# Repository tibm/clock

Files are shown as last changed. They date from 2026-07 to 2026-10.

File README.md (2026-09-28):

# Wooden Smart Clock — Hardware Specification

> Living spec for a high-quality, low-power desk alarm clock: a **walnut cube (~120 mm)** with an **aluminum front plate**, a centered **Ø~90 mm MCU-driven analog dial behind glass** (aluminum hands on walnut, 12 black hour dots, no numerals), a row of **5 RGBW status LEDs** under the dial, and one **aluminum knob (rotate + press)** centered on the top face.

> 🔩 **Manufacturing constraint — HAND-SOLDERABLE PARTS ONLY.** The bare PCB is fab'd externally; **every part is hand-soldered with an iron.** No **QFN / DFN / WSON / BGA / WLP / LGA** silicon sits bare on the board — every active IC is a **leaded/gullwing** package (SOIC / SOP / SSOP / TSSOP / **HTSSOP** / **MSOP** / SOT-23) or a **castellated/edge module**. The two power parts (amp `TAS5760M`, charger `LT3652`) are HTSSOP/MSOP **PowerPAD** — leads iron-solderable, belly pad on a thermal-via array (back-side hot-air optional). Functions that *only* exist leadless → **pre-made breakout modules** (env/MEMS sensors — **BME688, TSL2591, BNO085** as I²C Qwiic/STEMMA boards; or a custom SMT daughterboard — **built: [`kicad-sensor/`](kicad-sensor/), `SENSE v0.2`**, §8) or **dropped** (fuel gauge → ESP32 ADC). **Passives ≥ 0603** (0402 min); connectors hand-solderable (through-hole / wide-pad SMD: USB-C, FPC/ZIF, JST, SD cage). **This grows the PCB — accepted.**

**Status:** v0.19 draft · **Owner:** you (FW/HW) · **Last updated:** 2026-07-19 · **What is left to build: [`TODO.md`](TODO.md)** · clock ⇄ app protocol: [`app/PROTOCOL.md`](app/PROTOCOL.md)

**Changelog**
- v0.19 — **Product redesign: walnut cube + aluminum face — display dropped, NeoPixel status/face LEDs + top-knob UX added (2026-07-19).** New form (§3): perfect **walnut cube ~120 mm** (size flexible, larger eases manufacturing), all faces wood except an **aluminum front plate** (cube − 10 mm in W/H, flush-centered → **5 mm wood reveal**) with a **centered Ø~90 mm dial opening** behind glass — **aluminum hands over a walnut dial**, no numerals, **12 black hour dots**; below the opening, **5 status-LED holes + icons** (Lucide-style `bell`, `alarm-clock`, `clock`, `volume-1`, `battery`); an **aluminum knob (rotary + push)** perfectly centered on the top face; wake light, speaker openings and USB port on the **back**. Consequences: **(1) Sharp LS032B7DD02 + FH34 FPC connector dropped** (§4; their datasheets stay in [`/datasheet`](datasheet/) for possible future reuse) — SPI2 is now **microSD-only**, software-VCOM notes moot, `LCD_DISP`/`LCD_CS` freed. **(2) Panel-LED string dropped** (Cree CLM3C ×≤12 + its AO3400A + one LEDC channel recovered) → **7× SK6812 RGBW NeoPixels on the PCB** ([Adafruit 2758](https://www.digikey.com/en/products/detail/adafruit-industries-llc/2758/6134706), 10-pack $5.95): **5 status + 2 dial-illumination**, chained on the **5 V rail** (works on battery) behind **one data GPIO (IO7 → RMT)** through an **SN74AHCT1G125 3.3→5 V buffer** ([DigiKey 376028](https://www.digikey.com/en/products/detail/texas-instruments/SN74AHCT1G125DBVR/376028), $0.14). **(3) UI = single knob**: Bourns **EM14A0D-C24-L064S** **optical** encoder (**no detent, 64 CPR**, integral push switch, **5 V** opto-ASIC, [DigiKey 954403](https://www.digikey.com/en/products/detail/bourns-inc/EM14A0D-C24-L064S/954403), $34.00) under a Kilo **OEJNI-90-1-5** machined aluminum knob (Ø23.5 mm, 1/4″ bore + set screw = the encoder's 1/4″ flatted shaft, [DigiKey 5970396](https://www.digikey.com/en/products/detail/kilo-international/OEJNI-90-1-5/5970396), $13.43), off-board on J10 (JST **ZH** 1×06 B6B-ZR incl. **+5 V** — same family + pre-crimped A06ZR cable as the sensor board) → **A/B are 5 V outputs → 100k/200k dividers → IO47/48 (PCNT)**, **ENC_SW moved MCP23017 → host IO17** (freed by the display) for a tight-debounce interrupt; **rear tactiles BTN1–3 dropped**, one **radio-disable toggle** remains on the expander (GPA3) via **J11** (JST ZH 1×02). **(4) USB-C receptacle → vertical GCT USB4160-03-0230-C** (24-pin USB 3.2 Gen2 vertical, of which only the **USB 2.0 subset** — VBUS/GND/**CC/D±** — is wired, SS pads unconnected → native USB-JTAG + 15 V PD intact; [DigiKey](https://www.digikey.com/en/products/result?keywords=USB4160-03-0230-C), **$1.22, 5,753 in stock**, active) standing on the PCB, port exits the back wall directly — **USB4105 + Adafruit 6069 panel extension dropped**; footprint adapted into `kicad/clock.pretty` from the user-supplied vendor CAD file. *(Vetting trail: **USB4140** rejected = 6-pin power-only, no D±; **UJ20-C-V-C-1** rejected = legs/layout specified for a 0.8 mm PCB; **UJ20-C-V-C-2** (TH, $0.95) was briefly primary but is backorder-only; **USB4145-03-0170-C** ($1.05) remains a same-land-family 16-pin alt.)* **(5) Orientation-awareness (R14) retired** (the cube is fixed upright; LIS3DH stays for tap-to-snooze). Unchanged: wake COB (12 V, plugged-only), audio chain, charger + battery safety, sensors, homing, steppers. Schematic (`kicad/`) regenerated; docs synced.
- v0.18 — **Protector re-picked (AP9101C went NRND/obsolete) → HYCON HY2111-GB** (SOT-23-6, OV 4.28 V / OD 2.90 V, pin-arrangement-identical → same nets; support values per its datasheet: R VDD 330 Ω→**100 Ω**, R CS 2.7 k→**2 kΩ**; AOSD32334C dual-FET unchanged). Quality single-qty alternatives (ABLIC S-8261ABMMD, Nisshinbo R5478N) are reel-only/no-stock at DigiKey → HY2111-GB sourced **LCSC C82747** (off-DigiKey like the CH224K). **X40.879 mounts directly on the PCB**: custom KiCad footprint + symbol drawn from the factory STEP + pinout figure (8 solder pins, Ø10 shaft clearance hole, both shafts pass through the board); **J4 stepper connector dropped**. **USB-C port moved to the enclosure wall** via the Adafruit **6069** panel-mount **extension** ([DigiKey 25897275](https://www.digikey.com/en/products/detail/adafruit-industries-llc/6069/25897275), ~$4.50) — the on-board **USB4105** receptacle + CH224K stay unchanged (a passive C-plug→panel-C-jack passthrough keeps CC/PD intact; the resistor-equipped Adafruit 6153 pigtail was rejected — its built-in 5.1 kΩ CC pull-downs would break the 15 V PD contract). Datasheets: `battery_protector_ap9101c.pdf` → `battery_protector_hy2111.pdf`. Schematic (`kicad/`) regenerated; docs synced.
- v0.17 — **Homing sensor re-picked: Everlight ITR8307 (went unavailable) → onsemi QRE1113.** Same reflective **phototransistor with analog output → 1 ADC pin**, so it drops into the **same 150 Ω ballast / 10 kΩ load network** unchanged (§5, [`power_values.md`](power_values.md)); no firmware or pin-map change. Trade-off: the QRE1113 is **larger (≈3.6×2.9×1.7 mm** vs the ITR8307's 3.4×1.5×1.1 mm) → a marginally bigger dial hole — still far smaller than the dropped **TCND5000** (6×4.3×3.75 mm). Through-hole gull-wing `QRE1113` (SMD `QRE1113GR` alt), trivially hand-solderable, **DigiKey 2175990 (~$0.76)**. Synced §5/§8/§16b + block diagram + [`datasheet/README.md`](datasheet/README.md) (`sensor_homing_optical_itr8307.pdf` → `sensor_homing_QRE1113-D.PDF`).
- v0.16 — **LED 12 V source resolved · MCP23017 IO expander added · pin-level map (`esp32.md`) + schematic values (`power_values.md`) · backup mode / TCO / VCOM decided.** LED: **no barrel jack** — the wake COB runs off the shared **TPS55340 12 V boost, plugged-only**; on battery the amp PVDD auto-drops to the **5 V rail via an LTC4412 mux** (quieter alarm) and the 5 V panel LEDs stay on (§9/§10, [`led.md`](led.md)). **Added the Microchip MCP23017** I²C IO expander (SOIC/SSOP-28) on the shared bus to offload slow/static lines (SPK_SD, 12 V-boost EN, stepper STBY, buttons, encoder-switch, PD PG, charger CHRG/FAULT) → **net −7 host GPIO** (§6/§16b; datasheet §19). Full **pin map now in [`esp32.md`](esp32.md)** (native USB-JTAG on IO19/20, **software VCOM** with EXTMODE=L, shared display+SD on SPI2 → **32/33 module pads**), and **per-converter passive/FB/comp values in [`power_values.md`](power_values.md)**. Decisions (2026-07-12): **backup mode = adaptive** (Wi-Fi modem-sleep → deep-sleep at low SoC); **one-shot ~77 °C TCO added** to the cell path (§10); **software VCOM** locked. Corrected the 32.768 kHz load-cap value (**~18 pF**, was mis-stated). Synced [`datasheet/README.md`](datasheet/README.md), [`power.md`](power.md), [`CLAUDE.md`](CLAUDE.md).
- v0.15 — **Sensor set consolidated to 3 parts + hand-assembly path chosen (§8).** Dropped the redundant **TMP117** (any temp sensor already gives the reading); folded **SHT45 + SGP41 → one Bosch BME688** (T + RH + pressure + VOC/gas via BSEC — one chip, one board on the bus); accel **BMA400 → LIS3DH** (no leaded accel exists; low-res tap+gravity is all we need). **Locked set = BME688 + TSL2591 + LIS3DH on both build paths → firmware identical either way.** **Build = option 2a: a STEMMA QT / Qwiic daisy-chain** of three ready Adafruit boards on one 4-wire I²C chain — **BME688 (Adafruit 5046, ~$19) + TSL2591 (1980, $6.95) + LIS3DH (2809, $4.95)** — no leadless silicon touched by the iron. **Future option 2b:** the **same** three bare chips on one small custom daughterboard, JLCPCB SMT-assembled, hand-solder only its header → smallest footprint, same part numbers → same firmware. Filed `sensor_env_bme688.pdf` + `sensor_accel_lis3dh.pdf`; removed the now-unused TMP117/SHT4x/BMA400 datasheets. Synced §8/§16a/§16b + [`datasheet/README.md`](datasheet/README.md).
- v0.14 — **Homing reworked: 2× DRV5032 Hall + hand magnets → 1× reflective optical (Everlight ITR8307).** One sensor behind a **punched dial hole**, sequential per-shaft homing, **no hand magnets** (§5). Evaluated the longer-range **Vishay TCND5000** for a >3 mm hand stand-off and **dropped it** — at **6×4.3×3.75 mm** it's ~5× the ITR8307 footprint (**3.4×1.5×1.1 mm**) → a bigger dial hole; **ITR8307 locked for the smallest hole**, hands kept **<3 mm** off the dial. Synced §3/§5/§8/§16b/§17 + [`datasheet/README.md`](datasheet/README.md) (dropped the stale Hall rows; only `sensor_homing_optical_itr8307.pdf` filed).
- v0.13 — **RTC IC dropped → ESP32-S3 RTC + 32.768 kHz crystal (no battery).** A battery-less RTC chip loses time on total power loss exactly like the S3, so it adds parts without fixing anything; the S3's internal RC oscillator alone drifts %-level over temperature (bad for a clock). Fix = a ~30¢ **32.768 kHz watch crystal** on XTAL32K (GPIO15/16) → ±~20 ppm ≈ 1.7 s/day, disciplined by **SNTP**. On loss of USB **and** the 18650, time is lost → re-sync on boot with a clock animation (accepted). Removed the RV-3028-C7/DS3231SN row + datasheet; §8, §16, §17, §6c synced.
- v0.12 — **Sensors, display connector & RTC finalized to precise parts + datasheets** ([`/datasheet`](datasheet/) rows 11–16): display FPC → **Hirose FH34SRJ-10S-0.5SH** (10-pin 0.5 mm ZIF, the panel spec's own recommended mate, on-board); T/RH → **SHT45** (±0.1 °C / ±1 %RH, replaces SHT40) + optional dedicated **TMP117** (±0.1 °C); light → **TSL2591** (188 µlx–88 klx, weak-light, replaces VEML7700); accel+orient → **BMA400** (now datasheeted); RTC **kept = RV-3028-C7** (ULP 45 nA) / **DS3231SN** (SOIC-16, on-board) — the S3's internal RTC dies on full power loss, so a backed-up RTC gives instant-correct hands at cold boot + holdover. Production BOM (§16b), §8 sensor table, and [`datasheet/README.md`](datasheet/README.md) synced; leadless sensors ride on I²C breakouts, the FPC connector is on-board.
- v0.11 — **Hand-solderable parts only (hard mfg constraint):** every bare-PCB IC is now a leaded package — no QFN/DFN/BGA/LGA. Swaps: amp **TAS5825M (VQFN) → TAS5760M** (HTSSOP-32, I²S+I²C; HPF/limiter DSP moves to firmware); driver **2× DRV8835 (WSON) → 2× TB6612FNG** (SSOP-24); PD **STUSB4500 (QFN) → CH224K** (ESSOP-10, resistor-set, off-DigiKey); charger **BQ25628E (WQFN) → LT3652** (MSOP-12E buck, BAT-node power-path, resistor-set 4.05 V + NTC + timer — no I²C, single-window temp); **fuel gauge MAX17048 (µDFN) dropped → ESP32 ADC**; protector **LC05111 (DFN) → S-8261 (SOT-23-6) + AO4800 dual-FET (SO-8)**. Leadless-only env sensors → **I²C breakout modules**. New top-of-file mfg note; datasheets swapped in [`/datasheet`](datasheet/); board grows — accepted.
- v0.10 — **Power/safety simplified (Option A)**: buck-boost **BQ25792 → BQ25628E** (1-cell buck charger, integrated FETs — buck is enough since input always > 1S cell); independent **cell protector = onsemi LC05111** (integrated FET) + **reverse-polarity P-FET** + NTC/JEITA + TVS = **double-redundant, industry-standard for 1S**. Dropped BQ29700+FETs, **secondary OVP, one-shot TCO, PPTC** (over-engineering for a single cell). Datasheets added (STUSB4500, BQ25628E, MAX17048, LC05111); `power.md` now has a **How-to-use / bring-up** section. Power subtotal ~$23 → ~$15.
- v0.9 — **Power tree locked** ([`power.md`](power.md)): **USB-PD sink (STUSB4500, 15 V)** → **BQ25792** buck-boost charger/path (+ MAX17048), 1S. Rails 3.3 / 5 / 12 V-audio-boost / 15 V-VBUS-LED. Battery = **user-supplied 18650 in a holder, Li-ion ONLY (labeled)**; **48 h backup**; health-cap ~80 %. **Mandatory board safety for any 18650**: reverse-polarity (LM74700-Q1), primary PCM (BQ29700+FETs), redundant secondary OVP, PPTC + thermal cutoff, NTC/JEITA, TVS, FR barrier — triple-redundant overcharge, layered over-discharge. Charger BQ25185 → **BQ25792**; §10/§16/§17 updated.
- v0.8 — **Amp locked = TI TAS5825M** (I²S + I²C closed-loop Class-D w/ DSP), PBTL mono into the 4 Ω DMA58-4: PVDD 5 V for ~3 W, optional ~12 V boost for ~8–12 W; DSP loads a ~150–180 Hz high-pass + limiter to protect the 2 mm-Xmax driver. MAX98357A demoted to simple/no-DSP alt. **Driver confirmed = 2× TI DRV8835** (dual H-bridge each; VM 5 V for full torque, VCC 3.3 V; PHASE/ENABLE with PWM microstep → 8 GPIO). Full datasheets added to [`/datasheet`](datasheet/); [`datasheet/README.md`](datasheet/README.md) now carries a **System IO & power domains** table (rails + per-part GPIO/voltage).
- v0.7 — **Speaker PC68-4 → Dayton DMA58-4** (2″ dual-magnet full-range — the driver we actually have a datasheet for) → smaller driver relaxes body depth to **≥45–60 mm / ~100–250 cc** chamber (optional **DMA58-PR** passive radiator for bass). **Movement locked = Juken X40.879**: its datasheet is a short **pinout addendum** that defers to the **X27 base spec** for torque/current/dimensions — both now in [`/datasheet`](datasheet/). Added the **full Sharp LS032B7DD02 device spec** (replaced the marketing brief); corrected display **active area → 42.67 × 68.07 mm** and **power → 30 µW hold / 250 µW update @ 5 V (VDD 4.8–5.5 V)**; **X40.879 price → ~$14** (was ~$25, DigiKey). Datasheets summarized in [`datasheet/README.md`](datasheet/README.md).
- v0.6 — **Split-face locked as THE design**: circular MCU-driven analog clock (~75 mm) + reflective monochrome info panel (**Sharp LS032B7DD02**). **Single MCU** (ESP32-S3). New **orientation awareness** (R14): flat (clock left / display right) ↔ standing (clock top / display bottom), accel-sensed; MCU rotates the display and re-references the analog "12". Movement re-picked for 75 mm → **Juken X40.879** (DigiKey) + external Hall homing. Motor driver **DRV8833 → DRV8835** (DRV8833 is NRND). Backlight subsystem removed (reflective display). Shopping list moved **Mouser → DigiKey**. Sections renumbered consecutively; wide color bar-TFT demoted to *superseded*.
- v0.5 — locked **Dayton PC68-4** speaker; added **Juken X10.506** + more movements; new requirement **R12** (MCU sets/adjusts analog time → sweep-quartz demoted).
- v0.4 — added **speaker comparison** and the **analog-movement comparison** for the split-face option.
- v0.3 — added **ESP32-S3** single-chip path + firmware libraries, **audio sizing**, internal packaging notes, and a distributor-linked shopping list.
- v0.2 — display moved E-Paper → fast **bar TFT** (NHD-3.9); MCU → STM32U5 + ST67W611M1, with ESP32-S3 as single-chip alt.
- v0.1 — initial spec (EPD + nRF5340).

---

## 1. Requirements (source of truth)

| # | Requirement | Primary approach (see §) |
|---|---|---|
| R1 | Accurate time (TZ, seconds, day, date), periodic server sync | ESP32-S3 RTC off a 32.768 kHz crystal + SNTP over Wi-Fi (no RTC IC/battery) (§6, §8) |
| R2 | ALS-driven lighting, **true 0 emission at night** | Wake light + status/dial NeoPixels, hard-off + ALS gating (§8, §9) |
| R3 | Alarm, tap-to-snooze, loud multi-asset audio, sunrise glow | Accel tap-detect + Class-D audio + tunable-white sunrise wake light (§7, §9) |
| R4 | Air quality (VOC/AQI), temperature, humidity | **BME688** (T/RH/press/VOC in one chip); optional CO₂/PM (§8) |
| R5 | USB-C powered, battery backup + charge, run untethered | USB-C PD sink + charger + Li-ion + ADC gauge (§10) |
| R6 | Glanceable state without a screen: alarm armed, set modes, volume, low battery — **0 light when idle** | **5 RGBW status LEDs** behind icon holes in the aluminum face; hands double as the readout in set modes (§3, §9, §12) |
| R7 | Wi-Fi + BLE, **single MCU** driving everything | ESP32-S3 single chip: motors + audio + sensors + LEDs (§6) |
| R8 | Single-knob on-device UX, minimal other controls | Top-center knob: **press = cycle modes, rotate = adjust** (§12); rear radio-off toggle; config via app |
| R9 | Companion iOS/web app: BLE pair → Wi-Fi provision, alarms, tone upload, widgets | BLE provisioning + SD asset store (§13) |
| R10 | Extensible: more sensors, multiple sizes | I²C sensor bus + JST connectors + modular FW (§14) |
| R11 | High-quality speaker + high-quality assets | Full-range driver + DSP amp + WAV/FLAC on SD (§7) |
| R12 | MCU fully sets/adjusts the analog time (TZ/DST jumps, NTP-synced, drift-corrected, both directions) | Bidirectional, absolutely-addressable dual-shaft stepper + homing (§5) |
| R13 | **Cube form:** walnut cube, aluminum face, centered Ø~90 mm analog dial (hour + minute) behind glass | Dual-shaft movement behind the face plate (§3, §5) |
| ~~R14~~ | ~~Orientation-aware (flat/standing)~~ — **retired v0.19**: the cube sits fixed upright. *Its narrow half came back 2026-08-18:* the dial re-references its **12** to gravity in 30° steps, so the time reads right whichever face the cube is on (`FIRMWARE.md` §6.1d) | Accel = tap-to-snooze **+ a gravity vector polled at 0.5–2 Hz** (§8) |

---

## 2. Key design decisions & open tensions

The v0.19 redesign collapses the earlier two-part split-face into **one face**: a walnut cube whose only readout is the **analog dial** plus **5 status LEDs**. No screen at all.

- **Circular analog dial (the product):** hour + minute hands, **fully MCU-driven** (dual-shaft stepper + homing). Real hands, silent, dark at night. In set modes the **hands themselves are the display** (they show the alarm time / follow the knob).
- **Status row:** 5 **RGBW NeoPixels** behind small holes + icons in the aluminum face (`bell`, `alarm-clock`, `clock`, `volume-1`, `battery`) — glanceable state with **zero emission when idle**.

**Baked-in:**
- **Single MCU** (ESP32-S3) drives hands + audio + sensors + LED lighting — no coprocessor.
- **Numeral-free dial** (12 black dots) + absolute stepper addressing → the MCU can jump the hands anywhere (time set, alarm preview, TZ/DST).
- Light emitters: the **wake light** (tunable-white sunrise, 12 V), the **2 dial-illumination NeoPixels**, and the **5 status NeoPixels** — all hard-off = 0 emission at night.
- Split power domains (always-on low-power + bursty Wi-Fi).

**Superseded:** the split-face reflective **Sharp memory-LCD** info panel (v0.6–v0.18) and, before it, the wide color **bar-TFT** (rationale kept in the Decision log & §17).

---

## 3. Form factor — walnut cube, aluminum face (R13)

**A perfect cube, ~120 mm per side** (dimension flexible; slightly larger eases manufacturing). All six faces **walnut** except the front:

- **Front = aluminum plate**, square, **cube − 10 mm in width and height** (~110 mm), flush with the front plane and centered → a **5 mm walnut reveal** around it.
- **Centered circular opening Ø~90 mm** (flexible) with a **glass disc** between the aluminum face and the hands.
- Behind the glass: **walnut dial background** (same wood as the walls), **aluminum hour + minute hands**, **no numerals — 12 black hour markers**. A small punched hole at the index radius serves the QRE1113 homing sensor (§5).
  - ⚠️ **Doc ↔ CAD discrepancy (2026-08-10):** this line and `CLAUDE.md` both said "12 **dots**", but [`cad/clock_plate.svg`](cad/clock_plate.svg) draws 12 **rectangular batons**, 1.70 × 5.71 mm, spanning **r 35.14 → 40.85 mm**. The CAD is what will be cut, so it wins; `ux/` renders batons. Two further gaps to close in the CAD: the **Ø90 mm opening and the five status-LED holes are not in the SVG** (it has the plate outline, the corner screws, the hub and the homing window only), and the **40 mm minute hand reaches into the baton band** — intended, or should the batons move out?
- **Below the opening:** a horizontal row of **5 evenly spaced LED holes with icons** (Lucide-style `bell`, `alarm-clock`, `clock`, `volume-1`, `battery`; engraved icons vs. text still open) — the **status LEDs** (§9, §12). The 5 SK6812 sit on the main PCB, light pipes / drillings through the plate.
- **Top face:** one **aluminum knob** (premium HiFi feel), **perfectly centered**, on a smooth no-detent encoder with a **press function** (§12).
- **Back face:** wake-light aperture, speaker openings, **USB-C port** (vertical receptacle on the PCB, exits straight out the back), and the **radio-disable toggle**.

Reference sketch: `~/Downloads/Clock_V4.png`. The dial is behind the front plate, the movement solders to the main PCB (shafts through-board, §5); a ~100–250 cc sealed speaker chamber and the cell compartment fill the body (§7a, §10).

---

## 4. Display — *removed in v0.19*

The reflective **Sharp LS032B7DD02** info panel (and its FH34SRJ FPC connector) was **dropped with the cube redesign** — the product now has no screen; state is shown by the hands + 5 status LEDs (§3, §12). The panel/connector datasheets remain in [`/datasheet`](datasheet/) in case a screen returns in a future variant, and the old selection rationale lives in the Decision log. Freed by the removal: the shared-SPI display device (SPI2 is now **microSD-only**), host pin **IO17** (`LCD_CS` → `ENC_SW`), expander line GPB3 (`LCD_DISP`), and the 5 V panel load.

---

## 5. Analog clock module — circular, MCU-driven (R12, R13)

**Design:** a circular **Ø~90 mm** dial (v0.19; was 75 mm) with **hour + minute** hands on a **dual-shaft concentric** stepper, so the MCU sets any absolute time. Silent, real hands, dark at night. **No seconds hand** (and no info panel since v0.19) — seconds aren't displayed. The hands double as the UI readout in the knob's set modes (§12).

**R12 recap:** the MCU must **set/adjust the displayed time on demand** — jump for TZ/DST, correct NTP drift, both directions — which needs a **bidirectional, absolutely-addressable** movement with a **home reference** (rules out forward-only sweep-quartz).

**Motor comparison** — must do **360° on *both* hands**, be **extremely quiet**, use **light hands**, and let the **MCU set any absolute time** (R12):

| Motor | Type · 360° both? | MCU sets abs. time (bidir + homing) | Torque → hand size | Noise | Size | Power | ~Cost | Where |
|---|---|---|---|---|---|---|---|---|
| **Juken X40.879** ⭐ **(75 mm pick)** | Dual coaxial shaft (hour+minute) · ✅ | ✅ bidirectional; **add external optical home** (no built-in zero-detect) | higher → OK for ~35 mm hands / 75 mm dial | very quiet (Swiss, microstep) | vertical, compact | ~15–20 mA | ~$14 | **DigiKey** (Juken) |
| Juken X10.506 (small ≤50 mm) | Dual-shaft concentric **clock** motor · ✅ | ✅✅ **zero-detection variant = built-in homing** | low, indicator-class (~1–2 mN·m) → light short hands | very quiet | ~Ø28 mm | ~15–20 mA | ~$11 | Minitools / DigiKey (Juken) |
| VID28-05 / BKA30D-R5 (budget) | Dual-shaft concentric · ✅ (**buy 360° variant**) | ✅ bidirectional; **add external optical home** | ~4 mN·m → ≤~10 g hands | microstep ~20–30 dBA | 29×59 mm | ~15–20 mA/coil | ~$4–6 | AliExpress/Amazon/eBay (**not DigiKey**) |
| Sonceboz 6407 | Dual-shaft, automotive-grade · ✅ | ✅ (+ homing) | higher, smooth | very quiet | ~30 mm | low | $$ | mfr direct (MOQ) |
| Juken/Switec X27.168 / X25.168 | **Single**-shaft gauge · ⚠️ 315° (remove stop) | ✅ bidirectional, but single shaft → **need 2 + coax mechanics** | ~0.6–1 mN·m (weakest) | microstep quiet | Ø26 mm | ~20 mA | ~$4–8 | **DigiKey** (X27.168) |
| Continuous-sweep quartz | Geared clock · ✅ | ❌ **forward-only + coupled → can't jump for TZ/DST** | strong (real hands) | **silent <20 dBA** | 56×56×15 mm | µA–mA | $3–10 | clock-parts shops |
| 28BYJ-48 geared stepper | Single-shaft geared · ✅ | ✅ electrically | strong (~34 mN·m) | **buzzy 45–55 dBA ✗** | 28 mm+box | 100–200 mA | ~$2 | everywhere |

**Picks (with R12 + the ~90 mm dial):**
- **Primary: Juken X40.879** ⭐ — dual coaxial hour+minute, **DigiKey-stocked (~$14)**, holding torque 3.5–4 mN·m — sized for ~35 mm hands on the old 75 mm dial, and still fine for the **~42 mm minute hand of the Ø90 mm dial *if the aluminum hands are kept thin/light and counterbalanced*** (aluminum is ~⅓ the density of brass; verify hand mass ≲1 g on the bench). Home with **one reflective optical sensor** (no magnets — see homing note below) since the X40 has no built-in zero-detect; Swiss-quiet with microstepping. Its datasheet is a short **pinout addendum** (two *independent* dual-shaft bipolar coils, 8 pins, X27-compatible mechanics) that **defers to the X27 base spec** for torque/current/dimensions — so both `stepper_motor_x40-879.pdf` **and** `stepper_motor_x27_base-spec.pdf` are kept in [`/datasheet`](datasheet/).
- **Small alt: Juken X10.506** — if you drop to ~50 mm; its **zero-detection variant gives built-in homing** (cleanest R12), but too little torque for 75–90 mm hands.
- **Budget alt: VID28-05 / BKA30D-R5** — same concept for ~$5, but off-DigiKey; add optical homing.
- **Rejected:** sweep-quartz **fails R12** (forward-only, coupled); 28BYJ-48 (noise).

**Design notes:**
- **Homing (optical, single sensor, no magnets):** one **reflective optical sensor** (onsemi **QRE1113**, ≈3.6×2.9×1.7 mm) sits behind a small **hole punched in the dial** at a chosen index radius that *both* hands sweep over. Because the MCU drives the two shafts independently, home them **sequentially** so the minute-over-hour overlap never matters:
  1. park the **minute** hand ~180° off-index; slowly sweep the **hour** hand until the sensor edge triggers → hour homed;
  2. park the **hour** hand off-index; sweep the **minute** hand until it triggers → minute homed;
  3. drive both to the true time. Add a tiny high-contrast index mark (white dot / reflective foil / notch) on each hand's underside at the sensing radius for a crisp, finish-independent edge. After homing, position is held by **step counting**; the firmware homes **on boot, unasked** (`FIRMWARE.md` §6.1a), and again after each NTP sync and after long runs.
  - *The index is not north, and the difference is per unit.* The sensor answers "the mark is over the window"; how far that is from twelve o'clock depends on how the mark was printed, how the hand was pressed on and how square the sensor sits — so each hand carries a **calibration trim** (`motion zero <h|m> <±µsteps>`, 48 = 1°), set by eye once per clock and kept in NVS. Homing adopts it; `FIRMWARE.md` §6.1b.
  - *And the hands keep themselves honest.* They cross that same index every hour in normal running, and each crossing measures what homing measures — so a hand that arrives early or late is trimmed on the spot (**auto-home**, `FIRMWARE.md` §6.1c). Only clockwise, only slowly enough to be a real measurement, only when the other hand is well clear of the window, and only within ±1.5°; three crossings further out than that mean the movement has slipped, and it re-homes.
  - *One sensor is enough* — sequential homing removes any "which hand is which" ambiguity. (If you ever want *simultaneous* homing, drive the two hands at **distinct step rates** so the sensor's pulse timing identifies each — but sequential is simpler and foolproof.)
  - *Why not ToF (VL53L1x):* wide FoV (~15–27°), coarse angular resolution, and limited sample rate make it poor for a crisp home index; a reflective edge is far more repeatable.
  - *Sensor locked = onsemi QRE1113GR* (SMD gull-wing, **DigiKey 965451**, ~$0.36; lead form locked 2026-07-17): the earlier **Everlight ITR8307 went unavailable**, so homing moved to this widely second-sourced reflective part — **same phototransistor analog-out interface → same ADC network** (§16b, `power_values.md`), a true electrical drop-in. Its short range is fine because the hands sweep **<3 mm** off the dial (QRE1113 peaks ≈1 mm; index mark on the underside). At **≈3.6×2.9×1.7 mm** it's a bit larger than the ITR8307 → a marginally bigger dial hole, but still far smaller than the **Vishay TCND5000** (6×4.3×3.75 mm, peak 6 mm, range 2–25 mm), which was considered for a >3 mm stand-off and **dropped**; keep the hands close instead.
- **Re-time / set modes:** TZ/DST changes and the knob's *set clock* / *set alarm* / alarm-preview moves = step to the new absolute position (fast, both directions), no re-home needed. *(Orientation re-referencing retired with R14 — the cube is fixed upright.)*
- Buy/reuse the **360°/no-stop** movement; **microstep @ >20 kHz PWM** for silence; **light, counterbalanced hands** — the aluminum hands (§3) must stay thin (mass ≲1 g each) on the ~90 mm dial.
- **Driver:** **2× TB6612FNG** (SSOP-24, hand-solderable, no exposed pad) — one per shaft; VM 5 V, VCC 3.3 V; **PWM the IN pins with PWMA/PWMB tied high → sign-magnitude microstep in 8 GPIO** (parity with the old DRV8835). *DRV8835/DRV8833 are WSON/HTSSOP — replaced for hand-assembly.* **Homing:** **1× reflective optical sensor** (onsemi QRE1113) behind a hole in the dial — single-sensor sequential homing, **no hand magnets** (replaces the earlier 2× DRV5032 Hall + magnets; see homing note above). **Libs:** SwitecX25 / GewoonGijs-VID28 / AccelStepper.

---

## 6. MCU + wireless (R7)

A **single MCU** must drive two stepper shafts, I²S audio, the NeoPixel chain + wake-LED PWM, the I²C sensor bus, microSD, and Wi-Fi + BLE — the **ESP32-S3 single-chip** wins on simplicity + library support (SPI3+DMA for the SK6812s, MCPWM for the steppers, PCNT for the knob).

The N8R8 module exposes ~33 usable GPIO (octal PSRAM claims 3), and the pin budget is tight, so a **Microchip MCP23017** I²C IO expander (SOIC/SSOP-28, on the shared bus + one INT line) offloads the slow/static lines — amp mute, 12 V-boost enable, stepper STBY, the radio-disable toggle, and PD/charger status. The **knob lives on the host** (A/B → PCNT on IO47/48, press → IO17 with a hard interrupt + tight debounce — *not* the expander). The full pin-level allocation (host + expander) lives in [`esp32.md`](esp32.md) (native USB-JTAG on IO19/20); see also [`datasheet/README.md`](datasheet/README.md) §19.

| Option | Wi-Fi + BLE | Runs motors + audio + LEDs | Low power | Notes | Verdict |
|---|---|---|---|---|---|
| **ESP32-S3** ⭐ single-chip | Wi-Fi 4 (2.4G) + BLE 5 | ✅ MCPWM steppers + I²S + DMA NeoPixels (SPI3) | good deep-sleep, higher idle | cheapest, fastest bring-up, huge lib support (§6c) | **Primary** |
| STM32U5 + ST67W611M1 | Wi-Fi 6 + BLE 5.4 (SPI) | ✅ | **excellent** | ST ULP | ULP alt |
| nRF5340 + nRF7002 | Wi-Fi 6 + BLE 5.x | ✅ | **best radio power** | Nordic tooling | Nordic ULP alt |
| NXP RW612 single-chip | Wi-Fi 6 dual-band + BLE 5.4 + Thread | ✅ | good | viable single-chip | single-chip alt |
| ESP32-P4 + C6 | Wi-Fi 6 + BLE (C6) | ✅ overkill | med | 2 chips; only if a display returns | future |

### 6c. ESP32-S3 quick-start libraries
> ⚠ **Selection-era notes — superseded by [`FIRMWARE.md`](FIRMWARE.md) where they disagree.** That
> document is the software source of truth and the code lives in [`firmware/`](firmware/). The
> choice below was settled on 2026-07-26: **ESP-IDF v5.5.5 pinned, C++23, no Arduino, no ESPHome.**

Base: **ESP-IDF v5.5.5** (pinned in `firmware/toolchain.lock`; C++23, no exceptions/RTTI).

| Requirement | Library / component |
|---|---|
| Analog steppers (§5) | **TB6612FNG** via GPIO/PWM; **AccelStepper** / **SwitecX25** / VID28 lib; microstep for silence |
| Status + dial NeoPixels (§9) | Espressif **`led_strip`** component, **SPI3 backend** (`FIRMWARE.md` D4 — RMT also works but needs its DMA flag and is jitter-prone next to Wi-Fi) — one data GPIO for all 7; gamma + soft ramps in firmware |
| Knob (§12) | **PCNT** hardware quadrature (A/B, glitch filter) + GPIO ISR on ENC_SW with ~5 ms debounce |
| Tap-to-snooze (R3) | **BNO085** through CEVA's reference **`sh2`** driver — SHTP packets, *not* a register map; enable **only** `SH2_TAP_DETECTOR`. `SENSOR_INT` means "a packet is waiting", not "a tap happened". See `FIRMWARE.md` §6.5.1 + **R-BOARD-3** (no host reset line → degrade gracefully) *(supersedes the LIS3DH, 2026-07-29)* |
| Wi-Fi | `esp_wifi` |
| BLE-pair → Wi-Fi provision (R9) | `wifi_provisioning` (BLE transport) + Espressif **"ESP BLE Provisioning"** phone app |
| BLE stack | **NimBLE** |
| NTP + TZ/DST (R1) | `esp_netif_sntp` + POSIX `TZ` string (`setenv`/`tzset`); run the S3 RTC off the **32.768 kHz XTAL32K** (GPIO15/16) so it holds ±~20 ppm between syncs — **no RTC chip, no battery** |
| Env sensors (R4) | Bosch **BSEC 2.x / BME68x** (chosen — T/RH/press/VOC/IAQ); Sensirion `embedded-i2c-scd4x / sps30` (CO₂/PM opt) |
| Light | **TSL2591** (Adafruit_TSL2591 / esp-idf-lib) or VEML7700 |
| Hand homing (§5) | **1× reflective optical** (QRE1113) → ADC/comparator edge; single-sensor sequential homing in firmware, no magnets |
| Audio out (I²S) | `esp_driver_i2s`; **no decoder — WAV only** (16-bit PCM 44.1/48 kHz, `FIRMWARE.md` D8; FLAC/ESP-ADF deferred behind the `AudioSource` concept); **~150 Hz high-pass + limiter/EQ biquads run here** (TAS5760M has no on-chip DSP) |
| Wake LEDs | `ledc` (PWM dimming, 2 ch tunable-white); 12 V COB via AO3400A — see [`led.md`](led.md) |
| SD + assets | `esp_vfs_fat` + `sdmmc`; `LittleFS` for internal flash |

**Fastest bring-up (considered, not taken):** **ESPHome** would get sensors / SNTP / NeoPixels / PWM LED / I²S audio running in an afternoon, but the steppers, the knob HSM and the amp-protection DSP all need custom code anyway — so the project went straight to ESP-IDF. Bring-up is instead served by the **CLI + host simulator** (`FIRMWARE.md` §9, §11.2).
**Caveat:** the **LT3652** charger is autonomous (no driver needed) — read charge state via **CHRG/FAULT GPIO + cell-voltage ADC** (no I²C charger/gauge); the health-cap 4.05 V is fixed in hardware by the float divider. See [`power.md`](power.md).

**RTOS/lang:** **C++23 + FreeRTOS (ESP-IDF v5.5.5)**, with a hand-rolled ~500-LOC active-object layer — 9 AOs, one queue each, no shared mutable state (`FIRMWARE.md` D1/D2/D3).

---

## 7. Audio subsystem (R3, R11)

- **Amp: TAS5760M** ⭐ (I²S in + I²C control, closed-loop Class-D, **HTSSOP-32 → hand-solderable**; digital clipper + DC-detect/OC/OT protection; up to 55 W stereo / 114 W mono PBTL). Run **PBTL mono** into the 4 Ω DMA58-4; **PVDD ~12 V boost → ~8–12 W** (or 5 V → ~3 W). Needs an **LC output filter**. **No on-chip biquad DSP** (unlike the superseded QFN TAS5825M) → the **~150 Hz high-pass + limiter/EQ that protects the 2 mm-Xmax driver runs in ESP32-S3 firmware**. *Analog alt (all hand-solderable):* **PCM5102A** DAC (TSSOP-20) → **TPA3116D2** Class-D (HTSSOP-32).
- **Chain:** ESP32-S3 → **I²S** (4 pins: **MCLK**, BCLK, LRCLK, DOUT — the TAS5760M *requires* an MCLK, `esp32.md`) → amp → speaker.
- ⚠ **Supplies — three pins, two rails, and rev0.3 gets one wrong.** `PVDD` (21, 28) and **`AVDD` (1)** are both **4.5–26.4 V** and tie together; only `DVDD` (10) is 3.3 V. The datasheet's own §10 says "the device requires two power supplies" and never names `AVDD`, which is exactly the trap: rev0.3 wires `AVDD` to **+3V3**, 1.2 V under its minimum, and the amp's analog domain never comes up — I²C answers perfectly and reg 0x08 sits at `CLKE` (found 2026-09-14, `FIRMWARE.md` §12.0.16). **Fix = v0.4 `V13`** in [`kicad/REVIEW.md`](kicad/REVIEW.md); bodgeable on build #1 with one trace cut.
- **Source:** WAV (trivial) / FLAC (decoder + CPU) on microSD; system sounds in flash.
- **Tap-to-snooze:** accel hardware tap IRQ (§8) so the MCU sleeps until tapped.

### 7a. Sizing (what "close to a BT speaker" costs in space)
The cube helps audio — a ~120 mm cube has ample internal volume for the sealed chamber behind the dial/movement. Quality comes from **a sealed air chamber**, and the speaker fires through openings in the back face.

| Item | Spec | Footprint / volume |
|---|---|---|
| Driver | **2″ (Dayton DMA58-4), 4 Ω, 15 W, 86.2 dB** | 56 × 56 mm × ~32 mm deep |
| Bass helper | **DMA58-PR** passive radiator (optional, big low-end gain) | ~2″, ~20 mm deep |
| **Sealed chamber** | **~100–250 cc** sealed, or less w/ DMA58-PR passive radiator | dominant space cost → sets min body depth ~45 mm |
| Amp | **TAS5760M** HTSSOP-32 ~11×11 mm + LC filter | on main PCB |

**Loudness:** TAS5760M + DMA58-4 ≈ 90+ dB @ 0.5 m (12 V PVDD headroom) — plenty for an alarm, pleasant at desk distance. **Rule:** plan a body **≥45–60 mm deep** with a dedicated ~100–250 cc sealed chamber. Vent nothing from the chamber toward the AQ sensors.

### 7b. Speaker options — comparison

| Option | Type | Size (mm) | Power / Ω | Application | ~Cost | Pros | Cons |
|---|---|---|---|---|---|---|---|
| **Adafruit 3351** v1 | Mono, enclosed | 30×70×17 | 3 W / 4 Ω | alarm, voice, casual music | $4 | plug-and-play, tiny, JST, sealed | thin, ~no bass, modest SPL |
| Adafruit 1669 | Stereo enclosed set | 2× ~30×70 | 3 W / 4 Ω | casual stereo, chimes | $8 | stereo, enclosed | small, limited bass |
| **Dayton DMA58-4** ⭐ **chosen** | 2″ dual-magnet alu-cone full-range | 56 × 56 × 32 | 15 W / 4 Ω, 86.2 dB | quality desk audio | $19 | rigid alu cone, low distortion, matching DMA58-PR radiator | 2″ → limited bass w/o PR; needs small sealed box |
| Dayton PC68-4 (bigger-box alt) | 2.5″ full-range driver | Ø66 × ~30 | ~15 W / 4 Ω, 83 dB, Fs 117 Hz | more low-end, cheaper | $9 | more bass, great value | 2.5″ → deeper body (~250 cc) |
| Tang Band W2-series | 2″ full-range (premium) | Ø~57 | ~15 W / 4–8 Ω | premium music | $25–40 | best small-driver fidelity | pricey, needs box |
| Driver + passive radiator | 2.5″ FR + PR | Ø66 + PR | — | best "BT-speaker" feel | $15–25 | real bass in a small box | 2 parts + box tuning |
| 3″ full-range (Visaton FRS8) | 3″ driver | Ø80 | 20–30 W | if depth allows | $12–20 | fullest, loudest | biggest footprint |

**Chosen: Dayton DMA58-4** in a sealed **~100–250 cc** chamber (Fs 165.5 Hz → sealed roll-off ~200–260 Hz; add the matching **DMA58-PR** passive radiator for more low-end), driven by **TAS5760M** (I²S; ~150 Hz HPF + limiter in firmware). Body depth ≥45–60 mm follows from this. **Dayton PC68-4** (2.5″, lower Fs, more bass) is the bigger-box alt; **Adafruit 3351** the compact/budget fallback. *(Speaker is from Parts Express, not DigiKey.)*

---

## 8. Sensors (R3, R4)

| Function | Part | Notes | ~Cost |
|---|---|---|---|
| Temp + humidity + VOC ⭐ | **Bosch BME688** | **one chip = T + RH + pressure + VOC/gas index** (BSEC lib) → the whole climate + air-quality job in a single sensor; ±0.5 °C / ±3 %RH (fine for a room readout) | $5 bare / ~$19 board |
| CO₂ *(opt)* | **Sensirion SCD41** | true NDIR CO₂ | $18–30 |
| PM2.5 *(opt)* | **Sensirion SPS30** | has fan; power/size | $30–45 |
| Ambient light ⭐ | **ams-OSRAM TSL2591** (`TSL25911FN`) | **188 µlx–88 klx**, 600M:1 range → resolves near-dark; VEML7700 = lux-direct simpler alt | $3 bare / ~$7 board |
| **Motion / tap** ⭐ | **CEVA BNO085** *(replaced the LIS3DH 2026-07-29)* | 9-axis with the **SH-2 sensor-hub firmware on-chip** — we use exactly two features: `SH2_TAP_DETECTOR` for tap-to-snooze (R3) and `SH2_GRAVITY` for the dial's 12 (§12, `FIRMWARE.md` §6.1d). Not a register map: SHTP packets over I²C, clock-stretches, boots asynchronously, and **cannot be reset by firmware** (`FIRMWARE.md` R-BOARD-3). mA-class, not µA — it sits on the always-on +3V3 rail. *(Orientation as a product feature stays retired with R14 — nothing rotates a layout or changes a mode; gravity re-references the dial's 12 in 30° steps and does nothing else.)* | $13.57 bare / ~$25 board |
| Hand homing ⭐ | **onsemi QRE1113GR** (reflective optical, SMD) | 1 sensor, sequential homing, **no hand magnets** (§5); analog out → 1 ADC; ≈3.6×2.9×1.7 mm (replaces the unavailable ITR8307) | ~$0.36 |
| Timekeeping | **ESP32-S3 RTC + 32.768 kHz crystal** (no RTC IC) | **No coin cell.** Crystal (~±20 ppm ≈ 1.7 s/day) holds between **SNTP** syncs; total power loss (USB **and** 18650 gone) → re-sync on boot, clock animation meanwhile. A battery-less RTC IC would add parts without fixing the loss case → dropped | ~$0.3 |

**Every env/MEMS sensor is leadless (LGA/DFN) — no hand-solderable silicon exists**, so none sit bare on the board. Two build paths:
- **2b — BUILT (2026-07-29 → `SENSE v0.2`, 2026-08-07): one custom sensor daughterboard.** The three bare chips (**BME688 + TSL2591 + BNO085**) on a 30 × 16 mm 4-layer PCB, SMT-assembled — [`kicad-sensor/`](kicad-sensor/). Front face carries the two sensors that must see the room (TSL2591 window, BME688 vent); the IMU and the connector are on the back. Plugs into main-board **J7** on a 6-way JST ZH harness: `GND · +3V3 · SDA · SCL · SENSOR_INT · ALS_INT`.
  ⚠ **The harness is not keyed and mirrors J7 1:1, so a backwards cable plugs in perfectly** and destroys U1; main-board **J10** (knob, +5 V on pin 2) is the same 1×06 header 13.5 mm away. See [`kicad-sensor/README.md`](kicad-sensor/README.md).
- **2a — bring-up alternative: STEMMA QT / Qwiic daisy-chain.** Three ready Adafruit boards on one 4-wire I²C chain — **BME688 (5046, ~$19) · TSL2591 (1980, $6.95) · BNO085 (4754, ~$25)** ≈ **$51**. Same part numbers → **same I²C addresses (0x77 · 0x29 · 0x4A) → the same firmware runs on either**, which is the point. Bare-chip datasheets in [`/datasheet`](datasheet/) (see its §15).

The IMU covers **tap-to-snooze** and **the dial's 12** (a gravity vector polled at 0.5–2 Hz — §12; full orientation-awareness stays retired with R14). All I²C on a shared bus (§14) — no address clashes: BNO085 0x4A · TSL2591 0x29 · BME688 0x77 · MCP23017 0x20 · TAS5760M 0x6C. The TSL2591's `ALS_INT` reaches the MCU through **expander GPB3**, not `SENSOR_INT`. **Vent the BME688 to outside air, away from amp/LEDs/battery** — their heat skews T/RH/VOC.

---

## 9. Lighting (R2, R3, R6)

Two subsystems on **two rails** (v0.19): the analog **wake light** (2 PWM channels, AO3400A low-side) and a **digital SK6812 RGBW NeoPixel chain** (1 data GPIO). Full spec in [`led.md`](led.md).

- **Wake light (2 LEDC ch):** **12 V** tunable-white COB (**3000K + 4000K**, Inspired LED) in a 100–120 mm sunrise diffuser behind the back/bottom aperture; warm→neutral ramp over ~30 min before audio; also serves as the night-light. **Plugged-only** (12 V boost is plugged-only; firmware gates the wake PWM off on battery). Warm = IO45, cool = IO46, each via an AO3400A.
- **NeoPixel chain (1 data pin, IO7 → SPI3 + DMA):** **7× SK6812 RGBW** (Adafruit 2758) on the **5 V rail (works on battery)**, one daisy-chained data line through an **SN74AHCT1G125** 3.3→5 V buffer. **Chain order (2026-07-21, when the status row moved off-board): pixels 1–2 = dial illumination** (D40/D41, *on* the main PCB, flanking the movement — warm-white W channel lights the walnut dial through the glass; ALS-gated, hard-off by default → 0 emission at night), **pixels 3–7 = the status LEDs** behind the face holes (`bell` `alarm-clock` `clock` `volume-1` `battery` — red/white semantics per §12), **off-board via J12** so they can be hand-placed to match the face-plate hole pitch. One wire is ample for 7 pixels (a full 7×32-bit refresh @ 800 kHz ≈ 0.3 ms) — brightness + soft ramps are trivial in firmware; no CC driver, no per-LED resistors, just 100 nF per pixel + a bulk cap and a ~330 Ω series R into the first DIN.
- *(Dropped in v0.19: the 5 V discrete panel-LED string + its AO3400A/LEDC channel — the display it front-lit is gone; dial lighting moved to NeoPixels 6–7.)*

---

## 10. Power (R5)

> Full power tree, budget, and battery-safety detail in [`power.md`](power.md). Summary below (kept in sync).

- **Input:** USB-C with **USB-PD sink** (**CH224K**, ESSOP-10, resistor-set request 15 V; graceful fallback 5 V).
- **Charge / path:** **LT3652** (MSOP-12E 1-cell **buck** charger, VIN ≤32 V, resistor-set **4.05 V** float + charge current, **NTC** temp-qualified charging, safety timer). The **BAT node is the always-on system supply** → runs plugged with **no cell** (LT3652 sources up to 2 A). *No I²C — autonomous; state via CHRG/FAULT + ADC.*
- **Fuel gauge:** **ESP32-S3 ADC** on a cell divider (no hand-solderable gauge IC exists) → voltage-based SoC, low-batt shutdown ~3.2 V.
- **Battery:** **user-supplied 18650 in a holder, Li-ion ONLY** (labeled "Li-ion 18650 only · 2.5–4.2 V"). Recommend a protected 3000–3500 mAh cell. **48 h backup** target.
- **Health:** charge-cap **~80 % (4.05 V)** — fixed in hardware by the LT3652 float divider; optional GPIO-switched divider for a 4.2 V "full" mode.
- **Rails:** **3.3 V** (MCU, from 5 V) · **5 V** (stepper VM + **7× SK6812 NeoPixels** + amp-PVDD mux aux) · **12 V boost** (audio PVDD **+ wake LEDs**, **plugged-only**) · **15 V VBUS** (LT3652 charger VIN, plugged). Audio PVDD auto-muxes 12 V (plugged) / 5 V (battery) via an **LTC4412** → quieter alarm on battery. All rail converters in **leaded** packages (see §16 / `power.md`).
- **Safety (mandatory, wood/bedroom, any 18650) — simple + double-redundant:** independent **cell protector** (**HY2111-HB** SOT-23-6 + **AO4838** dual-N SO-8 FET, v0.4 **V9+V10**: OV/OD/OC/SC) redundant to the charger, **reverse-polarity P-FET**, **NTC** temp-qualified charge, **one-shot ~77 °C TCO** (thermal fuse in the cell − path), TVS, insert-qualify, FR barrier + venting. Double-redundant overcharge (charger 4.05 V + protector **4.28 V**), layered over-discharge. *(⚠ vs the superseded BQ25628E: no I²C telemetry + single-window NTC, not multi-zone JEITA — still meets "no charge <0/>45 °C". Secondary OVP/PPTC still dropped.)* Full wiring/config in [`power.md`](power.md).

---

## 11. Storage (R9, R11)

- **microSD** (SPI mode, 4-wire — saves GPIO vs SDMMC; sole device on SPI2 since v0.19) — user alarm tones / audio assets.
- **Flash** (module 8 MB + optional external OSPI NOR) — system sounds, OTA, config.

---

## 12. Inputs — single knob UX (R8)

**One aluminum knob, top-center** (HiFi feel): Kilo **OEJNI-90-1-5** machined aluminum knob (Ø23.5 × 15.9 mm, clear gloss, 1/4″ bore + 6-32 set screw) on a Bourns **EM14A0D-C24-L064S** **optical** encoder — **no detent** (perfectly smooth, no mechanical contacts to wear or bounce), **64 CPR** quadrature ×4 on PCNT = **256 counts/rev** (plenty sensitive; two channels are fully sufficient, incl. direction — sensitivity is just a firmware counts-per-step mapping), integral momentary **push switch**, 1/4″ flatted shaft matching the knob bore. The encoder's opto-ASIC runs on **5 V** (~30 mA), so its A/B outputs are 5 V logic → **100k/200k dividers (~3.2 V) → IO47/48 (PCNT, glitch-filtered)**; the push switch is a dry contact to GND → **IO17** (host GPIO interrupt, 10 k pull-up + 100 nF + ~5 ms firmware debounce — deliberately *not* on the I²C expander). Off-board on **J10** (JST **ZH** 1×06 B6B-ZR: GND · +5V · A · B · SW · GND — same family and pre-crimped A06ZR cable as the sensor board J7; the rear toggle J11 is a ZH 1×02).

**Mode cycle — press steps through the 5 status LEDs (§9), rotate edits the lit mode.** Each mode is *named after its icon*, because the icon is the only label the user ever sees. The LED's **pattern** carries as much as which LED is lit; the full definition (and the animation engine behind it) is `FIRMWARE.md` §6.6.

| # | LED / icon | Rotate → | LED says | Hands show |
|---|---|---|---|---|
| 1 | `bell` — **alarm on/off** | **clockwise = ON, anticlockwise = OFF** (direction, not distance) | ON → **slow red breath** · OFF → **slow white breath** | ON → the **alarm time** · OFF → **both hands on the 6** (a reading no clock can show) |
| 2 | `alarm-clock` — **set the alarm** | move the alarm time — **one detent, one minute**, and a spin is worth the minutes you spun it, paid out at the speed the hands can draw | *the same as `bell`*: it answers the same question | the alarm time being set, live |
| 3 | `clock` — **set the time** | move the wall clock, same feel | **steady white** | the time being set, live — opening on the clock's own time, or 12:00 if it has never been set |
| 4 | `volume-1` — **volume** | up/down, a gentle chime repeating at that level (440 Hz, 140 ms — a real note since 2026-09-13) | **steady white** | **a gauge:** 12:00 = 0 %, 10:00 = 100 % (300° of dial, both hands together, **swept** — the 10-to-12 sector is off the scale and the hands never enter it) |
| 5 | `battery` — **status only, not selectable** (skipped in the cycle) | — | **slow amber breath** below 20 % on battery | — |

- Press after *volume* (a 5th press) → all LEDs **fade** out, settings committed, hands return to the time.
- **Timeout:** 5 s without input → exit to normal, keeping whatever was set. **One timeout, every mode, pairing included** — a control with no labels can afford exactly one rule about how long it waits for you.
- **Long press** (~0.8 s) → commit and leave from any mode. Three ways out, all of them keeping what you set: the press round the cycle, the hold, and the 5 s timeout above.
- **Hold 10 s → BLE pairing:** all five LEDs breathe **blue in sync**. It commits at the ten-second mark, while the knob is still down, so the gesture shows itself rather than hiding until you let go. A press leaves; a finger on the knob counts as input, so it stays for as long as it is held and then obeys the same 5 s as everything else.
- ⚠ **Bring-up only:** the gauge still spans 0–100 %, but the amp is capped at **25 %** until the AO4838 and a 15 V brick are fitted — with PVDD on the 5 V rail, full scale sits on the cell protector's trip (`FIRMWARE.md` §6.2's ceiling, R-AUDIO-1). Above 25 % the hands keep climbing and the chime stops getting louder.
- **Mode 3 is refused when the network owns the time** — radios on *and* Wi-Fi provisioned *and* SNTP synced at least once. **Three quick red flashes**, then straight on to *volume*: the next sync would overwrite anything the knob did. The rear radio toggle gives the time back to the knob.
- **Radio-disable toggle** (rear, on **J11**, expander GPA3): hardware switch to shut down Wi-Fi/BLE (bedroom EMI preference); firmware obeys it as a hard override. Part locked 2026-08-06 = **E-Switch `100SP1T2B1M1QEH`** (miniature SPDT On-On bat toggle, 1/4-40 bushing, solder lugs) — wired as an SPST to GND; see §16b/§16d for the wiring, the panel counterbore it needs, and the dry-circuit caveat.
- **Turning is a direction, and the hands obey it.** Winding a time forward moves both hands forward, however far you wind: past the half hour the minute hand's next place is more than half a turn away, and "go the shorter way" would take it backwards under a steady clockwise turn (`FIRMWARE.md` §6.6e).
- **And the dial can always keep up.** The movement draws about twenty minutes of dial a second, so that is as fast as a knob may move the *setting* — and what the hands cannot draw is **dropped**, not queued, so they stop when your finger does. A number that outruns its own readout is not a setting, it is a guess; and a dial that carries on winding for a second after you let go is a time nobody chose. The price is honest and deliberate: a spin faster than that is worth less than you spun it, because a clock can only be set as fast as it can be read (`FIRMWARE.md` §6.6d, §16c, §16d).
- **Tap-to-snooze** via accel (top-tap) — no other buttons anywhere. **A tap lights the dial**: the two illumination pixels wash up over a second, hold for five and take four to leave, with the `bell` icon breathing twice alongside them. The colour is the answer to the only question worth asking a clock in the dark — **red if the alarm is armed, white if it is not** — which is the same rule mode 1 uses, so the two read as one instrument (`FIRMWARE.md` §6.6b).
- **The 12 is wherever up is.** The BNO085's gravity vector is polled (**500 ms plugged, 2 s on battery**) and the hands step round in **30° ticks** so that whichever of the twelve dots is at the top becomes the 12 — stand the cube on a different face and the time still reads upright. It snaps to a dot and never between them, needs two agreeing polls to move, and when the dial faces the ceiling (no *up* to find) the printed 12 is the 12. Nothing else about the clock changes: no rotated layout, no second mode, and homing and the per-unit trim are untouched (`FIRMWARE.md` §6.1d).
- **0 light when idle** stays a hard requirement (R2/R6): the only emitter allowed while the clock is doing nothing is the low-cell warning, and it breathes rather than stares.

---

## 13. Companion app (R9)

BLE pair → GATT provisioning → push Wi-Fi creds → join AP. Configure alarms, sunrise, LED brightness/color, TZ. Upload tones (→ SD) over BLE or Wi-Fi. iOS app and/or web (Web Bluetooth). ESP path: reuse Espressif's provisioning app for v1. QR code for quick setup? *(Note the rear radio toggle, §12 — with radios off, on-device knob config still works.)*

---

## 14. Extensibility (R10)

Shared **I²C** (Qwiic/STEMMA-QT) for drop-in sensors; the NeoPixel chain extends by just soldering more pixels (same one data line); speaker, LED strips, knob and toggle on JST connectors; reusable compute+radio+power core block. *(A display could return in a future variant — SPI2 has a free CS and the Sharp-panel datasheets are retained.)*

---

## 15. PCB considerations

4-layer min (6 if dense); solid ground plane, RF keep-out (or use a module w/ onboard antenna to inherit certs). **Two stepper shafts** via 2× TB6612FNG — keep coil traces + PWM away from RF/audio; mount **one reflective optical home sensor (QRE1113)** behind the dial, aligned to a punched index hole (shared by both hands via sequential homing). **NeoPixel placement is mechanical:** the 5 status SK6812s sit in a row whose pitch must match the face-plate holes exactly (fix plate + PCB geometry together), the 2 dial-illumination pixels flank the movement; 100 nF at each pixel, bulk 100 µF at the chain head, ~330 Ω into DIN, level shifter close to the first pixel. **Vertical USB-C (USB4160)** stands at the board's back edge, mating axis out the back wall — the 4 shell stakes solder into plated slots for retention; keep the pegs clear of the pour. Class-D + speaker return away from RF/analog. Copper for charger/amp heat. JST for battery/speaker/LED strips/knob/toggle, SD cage, USB-C w/ ESD+CC. **Hand-solder rules:** leaded ICs only (no QFN/DFN/BGA/LGA); **≥0603 passives**; the PowerPAD amp + charger get a **thermal-via array** under the belly pad; leadless-only sensors ride on I²C **breakout modules**; use generous footprints/spacing — board area is traded for hand-assembly.

---

## 16. Shopping list (DigiKey)

> DigiKey MPN / part links — click to verify live stock/price. Prices approximate, single-unit. Wood/enclosure excluded. Parts marked ✅ verified active on DigiKey; others use a DigiKey keyword search — confirm the exact orderable variant. Core-part datasheets + a summary table live in [`/datasheet`](datasheet/).

### 16a. Prototyping kit (fast start — dev boards + breakouts)

| Item | MPN | ~Price | Source |
|---|-----|---|---|
| SoC dev board (8 MB / 8 MB PSRAM) | ESP32-S3-DevKitC-1-N8R8 | ~$15 | [DigiKey search](https://www.digikey.com/en/products/result?keywords=ESP32-S3-DevKitC-1-N8R8) |
| Analog movement (dual shaft, **no stop**) | Juken **X40.879.NS** (= X40.879B) — ⚠ *not* the plain X40.879 (DigiKey 28528329), which has the X27's 315° internal stop (2026-09-27) | ~€25 | [MiniTools](https://store.minitools.com/en/sei-x40-879-ns-juken-x40-879-ns-stepper-motor.html) · not on DigiKey |
| NeoPixels RGBW (status ×5 + dial ×2) | Adafruit 2758 (SK6812 RGBW 5050, 10-pack) | $5.95 | [DigiKey 6134706 ✅](https://www.digikey.com/en/products/detail/adafruit-industries-llc/2758/6134706) |
| Knob encoder (smooth optical, push) | Bourns EM14A0D-C24-L064S (no detent, 64 CPR, 5 V) | $34.00 | [DigiKey 954403 ✅](https://www.digikey.com/en/products/detail/bourns-inc/EM14A0D-C24-L064S/954403) |
| Aluminum knob (1/4″ bore) | Kilo OEJNI-90-1-5 (Ø23.5 mm, set screw) | $13.43 | [DigiKey 5970396 ✅](https://www.digikey.com/en/products/detail/kilo-international/OEJNI-90-1-5/5970396) |
| Motor driver carrier (×2) | SparkFun TB6612FNG (ROB-14451) | ~$5 | [DigiKey search](https://www.digikey.com/en/products/result?keywords=TB6612FNG%20carrier) |
| Hand homing (×1, optical) | onsemi QRE1113GR (reflective, analog out, SMD) | ~$0.36 | [DigiKey 965451 ✅](https://www.digikey.com/en/products/detail/onsemi/QRE1113GR/965451) |
| I²S amp (bring-up) | Adafruit 3006 (MAX98357A) → TAS5760M EVM | ~$6 / — | [DigiKey search](https://www.digikey.com/en/products/result?keywords=Adafruit%203006) |
| Speaker (2″ full-range) | Dayton DMA58-4 | ~$19 | *(Parts Express 295-582 — not DigiKey)* |
| Env breakout (T/RH/press/VOC) ⭐ | Adafruit 5046 (BME688) | ~$19 | [DigiKey 14313482](https://www.digikey.com/en/products/detail/adafruit-industries-llc/5046/14313482) |
| Light breakout (weak-light) ⭐ | Adafruit 1980 (TSL2591) | $6.95 | [DigiKey 4990786](https://www.digikey.com/en/products/detail/adafruit-industries-llc/1980/4990786) |
| IMU breakout (tap) ⭐ | Adafruit 4754 (**BNO085**) | ~$25 | [DigiKey ⚠ verify](https://www.digikey.com/en/products/result?keywords=adafruit%204754) |
| Wake COB (12 V, 2 ch) | Inspired LED 12V-COB-3000K-12M + 12V-COB-4000K-12M | ~$15 (cut segs) | [16714316](https://www.digikey.com/en/products/detail/inspired-led-llc/12V-COB-3000K-12M/16714316) · [16714317](https://www.digikey.com/en/products/detail/inspired-led-llc/12V-COB-4000K-12M/16714317) |

### 16b. Production BOM (ICs, custom PCB)

> **Status key:** ⭐ **selected** — datasheet on file in [`/datasheet`](datasheet/) · ⚠️ **needed, not yet locked** — exact part/verification/datasheet still to do · ➕ **improvement** — optional upgrade, not required for core function. *(Every ⭐ row has a matching datasheet. The §16c switcher discretes + inductors were filed 2026-07-24 (`fet_2n7002`, `diode_schottky_bat46w`, `diode_clamp_bat42w`, `inductor_coilcraft_xal40xx`, `esd_usb_usblc6`, `diode_schottky_b340a` — rows 35–40). The v0.19 additions were filed 2026-07-20 as `datasheet/` rows 30–34 (USB4160, SK6812 RGBW, SN74AHCT1G125, EM14, JST ZH); the **OEJNI knob is mechanical-only** (no datasheet, dims in its row). The dropped display/FPC/USB4105 datasheets **remain on file** for future reuse, marked "not in current build".)*

| Status | Block | MPN | Size / pkg | ~Unit | DigiKey ref |
|:--:|---|-----|---|---|---|
| ⭐ | SoC module | ESP32-S3-WROOM-1-N8R8 | 18×25.5 mm | ~$6.3 | [DigiKey ✅](https://www.digikey.com/en/products/detail/espressif-systems/ESP32-S3-WROOM-1-N8R8/15295891) |
| ⭐ | IO expander (I²C, 16-bit) | **Microchip MCP23017** (SPI twin MCP23S17) — offloads SPK_SD / 12 V-EN / stepper STBY / radio-toggle / PD-PG / CHRG / FAULT / FULLCHG_EN / VBAT_DIV_EN / SPK_FAULT; INT→1 GPIO (net −9) | **SSOP-28** — order code **MCP23017-E/SS** *(the board's land is SSOP-28; the SOIC-28W `-E/SO` part does **not** fit — corrected 2026-07-27)* | ~$1.7 | [DigiKey ✅](https://www.digikey.com/en/products/detail/microchip-technology/MCP23017-E-SS/894273) |
| ⭐ | Status + dial NeoPixels ×7 (5 status + 2 dial) | **SK6812 RGBW 5050** — Adafruit **2758** 10-pack; on-PCB, 5 V, one data line | PLCC-4 5.0×5.0 mm | $5.95 /10 | [DigiKey ✅](https://www.digikey.com/en/products/detail/adafruit-industries-llc/2758/6134706) |
| ⭐ | NeoPixel data level shifter | **TI SN74AHCT1G125DBVR** (3.3 V → 5 V buffer, single gate) | **SOT-23-5** | ~$0.14 | [DigiKey ✅](https://www.digikey.com/en/products/detail/texas-instruments/SN74AHCT1G125DBVR/376028) |
| ⭐ | Knob encoder (top face, off-board) | **Bourns EM14A0D-C24-L064S** — **optical**, **no detent**, 64 CPR (×4 → 256/rev), integral push switch, 1/4″ flatted shaft, **5 V ~30 mA**; A/B 5 V out → 100k/200k dividers | vertical TH, PC pins | $34.00 | [DigiKey ✅](https://www.digikey.com/en/products/detail/bourns-inc/EM14A0D-C24-L064S/954403) |
| ⭐ | Aluminum knob | **Kilo International OEJNI-90-1-5** — machined, Ø23.5 × 15.9 mm, clear gloss, **1/4″ bore + 6-32 set screw** (mates the EM14 shaft) | solid aluminum | $13.43 | [DigiKey ✅](https://www.digikey.com/en/products/detail/kilo-international/OEJNI-90-1-5/5970396) |
| ⭐ | Sensor-board connector (J7, off-board I²C + power: GND/3V3/SDA/SCL/INT + **ALS_INT**) | **JST B6B-ZR(LF)(SN)** header ×2 (one per board, TH vertical, shrouded/keyed, 1 A) + **A06ZR06ZR28H152B** pre-crimped cable ×1 (ZH, 6-pos, socket↔socket, 28 AWG, **152 mm** — was 102 mm until 2026-08-06; the enclosure needs ≥120 mm). 🔴 **The `…B` suffix is the wiring, not a variant code:** `…152A` is the *Reversed* build of the same cable and it destroys the BNO085 (§16d) — ring pin 1 to pin 1 before plugging it in — same ZH family as the knob J10, whose harness is a **pigtail** (§16d). ⚠ **2.7 mm tail on a 1.6 mm board:** JST specs `B6B-ZR-3.4` for 1.6 mm, but that variant is made-to-order only (MOQ 2,000, 16 wk) — deviation accepted 2026-08-07, see `kicad/PCB_NOTES.md`. ⚠ **J7 and J10 are the same connector 13.5 mm apart** and J10 carries **+5 V on pin 2**: swapping the two harnesses destroys all three sensors. A 1×07 J7 (which would make that physically impossible) was considered and **rejected 2026-08-08** — `kicad-sensor/REVIEW.md` — so **the labels are the keying: label both harnesses** | **TH, 6-pos, 1.5 mm** | ~$0.24 ×2 + ~$1.54 | [DigiKey ✅](https://www.digikey.com/en/products/detail/jst-sales-america-inc/B6B-ZR(LF)(SN)/455-1661-ND/926568) [DigiKey ✅](https://www.digikey.com/en/products/detail/jst-sales-america-inc/A06ZR06ZR28H152B/6009439) |
| ⭐ | Analog movement | Juken **X40.879.NS** (= X40.879B; dual shaft, **no internal stop** — the plain X40.879 stops at 315°, `kicad/REVIEW.md` V18) — **solders directly to the PCB** (custom footprint `clock.pretty`, shafts through a board hole; no connector) | vertical, compact | ~$20 | [MiniTools ✅](https://store.minitools.com/en/sei-x40-879-ns-juken-x40-879-ns-stepper-motor.html) |
| ⭐ | Motor driver ×2 | TB6612FNG,C,8,EL | **SSOP-24** | ~$2.1 x 2 | [DigiKey ✅](https://www.digikey.com/en/products/detail/toshiba-semiconductor-and-storage/TB6612FNG-C-8-EL/1730070) |
| ⭐ | Hand homing ×1 (optical, reflective — **no magnets**) | onsemi QRE1113GR (single sensor, sequential homing; analog out → 1 ADC; replaces the unavailable ITR8307) | **≈3.6×2.9×1.7 mm**, 4-lead | ~$1.2 | [DigiKey ✅](https://www.digikey.com/en/products/detail/onsemi/QRE1113GR/965451) |
| ⭐ | Audio amp | TAS5760MDAPR — ⚠ **`AVDD` (pin 1) → PVDD, not +3V3** (4.5–26.4 V pin; v0.4 **V13**) | **HTSSOP-32** | ~$6.6 | [DigiKey ✅](https://www.digikey.com/en/products/result?keywords=TAS5760MDAPR) |
| ⭐ | Env: T/RH/press/VOC *(I²C module)* | Bosch BME688 (one chip = climate + air-quality); 2a board = Adafruit 5046 | LGA-8 → module | ~$5 / $19 | [PENDING](https://www.digikey.com/en/products/detail/adafruit-industries-llc/5046/14313482) |
| ⭐ | Light *(I²C module)* | ams-OSRAM TSL2591 / TSL25911FN (188 µlx–88 klx); 2a board = Adafruit 1980 | WFDFN-6 → module | ~$5 / $7 | [PENDING](https://www.digikey.com/en/products/detail/ams-osram-usa-inc/TSL25911FN/4162547) |
| ⭐ | IMU / tap *(sensor board)* | **CEVA BNO085**; 2a alt = Adafruit 4754 | **LGA-28 5.2×3.8 → sensor board (PCBA)** | **$13.57** | [DigiKey ✅ 1888-1006-1-ND](https://www.digikey.com/en/products/detail/ceva-technologies-inc/BNO085/9445940) |
| ⭐ | Timekeeping xtal (no RTC IC/battery) | **Abracon ABS07-32.768KHZ-T** (32.768 kHz, **CL 12.5 pF**, ±20 ppm) → S3 XTAL32K (GPIO15/16); match load caps to CL | 3.2×1.5 mm 2-SMD | ~$0.6 | [DigiKey ✅](https://www.digikey.com/en/products/detail/abracon-llc/ABS07-32-768KHZ-T/1236858) |
| ⭐ | PD sink | CH224K | **ESSOP-10** | ~$0.5 | [LCSC ✅](https://www.lcsc.com/product-detail/C970725.html) |
| ⭐ | Charger (1-cell buck, BAT-node path) | LT3652EMSE#PBF | **MSOP-12E** | ~$9.9 | [DigiKey ✅](https://www.digikey.com/en/products/detail/analog-devices-inc/LT3652EMSE-PBF/2225686) |
| ⭐ | Cell protector (independent) | **HYCON HY2111-HB** (OV 4.28 V / OD 2.90 V, **discharge-OC V_DIP 200 mV**) + **AO4838** dual-N FET *(v0.4 **V9+V10**; AOSD32334C as built — its 52–66 mΩ tripped both the discharge-OC and charge-OC thresholds, `power.md`)* — **-HB not -GB**: the -GB's 150 mV trips at ~1.9 A worst case, which a loud plugged alarm exceeds (§16, `kicad/REVIEW.md` #6). Every other threshold is identical; check the marking on arrival | **SOT-23-6 + SO-8** | ~$0.1 + ~$0.8 | [LCSC ✅](https://www.lcsc.com/product-detail/Battery-Management-ICs_HYCON-Tech-HY2111-GB_C82747.html) [DigiKey ✅](https://www.digikey.com/en/products/detail/alpha-omega-semiconductor-inc/AOSD32334C/11567511) |
| ⭐ | Reverse-polarity | **AO3401A** P-FET (−30 V, −4 A, R<sub>DS</sub>~50 mΩ) on BAT+ | **SOT-23-3** | ~$0.24 | [DigiKey ✅](https://www.digikey.com/en/products/detail/alpha-omega-semiconductor-inc/AO3401A/1855773) |
| ⭐ | Cell temp sense | **Murata NCP18XH103F03RB** 10 k NTC (B25/50 = 3380 K, ±1 %) → LT3652 NTC pin | **0603** | ~$0.20 | [DigiKey ✅](https://www.digikey.com/en/products/detail/murata-electronics/NCP18XH103F03RB/1644665) |
| ⭐ | Transient | **Littelfuse SMAJ22CA** (VBUS) + **SMAJ5.0CA** (BAT) — 400 W **bidirectional** *(switched from the uni A-suffix 2026-07-21: the schematic's D_TVS symbol is bidirectional, so the CA parts remove the assembly-orientation risk; $0.48 ea, in stock)* | **DO-214AC (SMA)** | ~$0.5 x 2 | [DigiKey ✅](https://www.digikey.com/en/products/detail/littelfuse-inc/SMAJ22CA/762287) [DigiKey ✅](https://www.digikey.com/en/products/detail/littelfuse-inc/SMAJ5-0CA/762251) |
| ⭐ | USB D± ESD array *(added 2026-07-21)* | **ST USBLC6-2SC6** flow-through on D+/D− at J1 (VBUS pin **NC** — 15 V PD contract exceeds its 5.25 V rating; internal zener still clamps) | **SOT-23-6** | ~$0.36 | [DigiKey ✅](https://www.digikey.com/en/products/detail/stmicroelectronics/USBLC6-2SC6/1121688) |
| ⭐ | VBAT_SENSE clamp *(added 2026-07-21)* | **Vishay BAT42W-E3-08** Schottky, cathode on the ADC divider node — bounds a reversed-cell negative excursion to ~−0.2 V at the ESP32 pad | **SOD-123** | ~$0.47 | [DigiKey ✅](https://www.digikey.com/en/products/detail/vishay-general-semiconductor-diodes-division/BAT42W-E3-08/3104176) |
| ⭐ | Cell one-shot TCO (77 °C) | **Cantherm SDF-DF077S** non-resettable organic-element thermal cut-off in the cell − path (T<sub>f</sub> 77 °C / hold 55 °C, 10 A/250 VAC); solder ≥3 mm from body + heatsink lead | axial radial-lead (Ø4.0, AWG18) | ~$0.9 | [DigiKey ✅](https://www.digikey.com/en/products/detail/cantherm/SDF-DF077S/1014754) |
| ⭐ | Audio + wake-LED boost BAT→12 V (plugged-only) | **TI TPS55340PWPR** (5 A/40 V boost) | **HTSSOP-14 (PWP, PowerPAD)** | ~$3.1 | [DigiKey ✅](https://www.digikey.com/en/products/detail/texas-instruments/TPS55340PWPR/3727185) |
| ⭐ | 5 V rail (boost) | **TI TPS61023DRLR** (3.7 A, 0.5–5.5 V in) — DigiKey-stocked vs off-DK MT3608 | **SOT-563** | ~$1.3 | [DigiKey ✅](https://www.digikey.com/en/products/detail/texas-instruments/TPS61023DRLR/11310667) |
| ⭐ | 3.3 V rail (from 5 V) | **TI TLV62569DBVR** buck (2 A, 2.5–5.5 V in) | **SOT-23-5** *(DBV = SOT23-5 per datasheet §5; DDC is the 6-pin — corrected 2026-07-27)* | ~$0.3 | [DigiKey ✅](https://www.digikey.com/en/products/detail/texas-instruments/TLV62569DBVR/7688370) |
| ⭐ | LED low-side switches ×2 | **AO3400A** N-FET (+ 100 Ω gate, 10 kΩ pulldown) — 2× wake COB *(3rd/panel FET recovered in v0.19)* | **SOT-23** | ~$0.5 x 2 | [DigiKey ✅](https://www.digikey.com/en/products/detail/alpha-omega-semiconductor-inc/AO3400A/1855772) |
| ⭐ | 18650 holder | **Keystone 1043** (TH PC-pin, UL94V-0, leaf springs; **$2.99, 21.9 k in stock** — chosen over the pricier SMT 1042, whose stale footprint the schematic carried until 2026-07-20; custom 1043 footprint now in `kicad/clock.pretty`) — ventilated placement per `power.md` | TH leaf-spring | $2.99 | [DigiKey ✅](https://www.digikey.com/en/products/detail/keystone-electronics/1043/2745669) |
| ⭐ | Wake LEDs (12 V COB, plugged-only) | Inspired LED **12V-COB-3000K-12M** (warm) + **12V-COB-4000K-12M** (neutral) — self-ballasted, $0.64/0.98″ seg | strip | ~$2.6 x 2 | [DigiKey ✅](https://www.digikey.com/en/products/detail/inspired-led-llc/12V-COB-3000K-12M/16714316) · [DigiKey ✅](https://www.digikey.com/en/products/detail/inspired-led-llc/12V-COB-4000K-12M/16714317) |
| ⭐ | Amp PVDD rail-mux (12 V↔5 V) | **LTC4412** low-loss PowerPath + P-FET — 12 V (plugged) / 5 V (battery) | **SOT-23-6** | ~$5.2 | [DigiKey ✅](https://www.digikey.com/en/products/detail/analog-devices-inc/LTC4412ES6-TRPBF/960173) |
| ⭐ | microSD socket | **Hirose DM3AT-SF-PEJM5** (push-push, 8-pos) | push-push, SMT R/A | ~$2.9 | [DigiKey ✅](https://www.digikey.com/en/products/detail/hirose-electric-co-ltd/DM3AT-SF-PEJM5/2533565) |
| ⭐ | USB-C recept (**vertical**, power+CC+D±) | **GCT USB4160-03-0230-C** (USB 3.2 Gen2 Type-C, 24-pin, **vertical SMT + 4 soldered stakes**, H 7.46 mm — stands on the PCB → port exits the back wall; only the USB 2.0 subset wired, SS pads unconnected). *Replaces the horizontal USB4105 + Adafruit 6069 extension; rejected along the way: USB4140 (no D±), UJ20-C-V-C-1 (0.8 mm-PCB legs), UJ20-C-V-C-2 (backorder); USB4145-03-0170-C = 16-pin same-land alt.* | SMT vertical, 0.5 mm pitch + stake slots | ~$1.22 (5.7 k stock) | [DigiKey ✅](https://www.digikey.com/en/products/result?keywords=USB4160-03-0230-C) |
| ⭐ | Knob connector (J10) | **JST B6B-ZR(LF)(SN)** (ZH 1×06: GND·+5V·A·B·SW·GND — the EM14 needs 5 V) + a **ZHR-6 + 6× ASZHSZH28K152** pigtail (152 mm; §16d) — the EM14 end solders, so J10 is not a ZH↔ZH cable like J7 | ZH 1.5 mm, TH vertical | ~$0.24 | [DigiKey ✅](https://www.digikey.com/en/products/detail/jst-sales-america-inc/B6B-ZR-LF-SN/926568) |
| ⭐ | Radio-disable toggle switch (rear panel, off-board on J11) | **E-Switch `100SP1T2B1M1QEH`** — 100-series miniature bat toggle. Decodes as **SP1** SPDT *On-None-On* · **T2** short 5.08 mm bat · **B1** 1/4-40UNS threaded bushing, **8.89 mm long** · **M1** solder lug · **Q** silver contacts · **E** epoxy-sealed · **H** mounting hardware included. Wired **SPST**: lug 2 (common) → J11.1 `RADIO_OFF`, lug 1 *or* 3 → J11.2 GND, third lug open. ⚠️ **8.89 mm bushing vs a ~10–12 mm walnut wall → counterbore the inside of the rear panel to ≤6 mm** at the hole (§16d) | Ø6.35 mm panel hole; body 12.70 × 6.86 × 8.89 mm | $4.27 (883 stk) | [DigiKey ✅](https://www.digikey.com/en/products/detail/e-switch/100SP1T2B1M1QEH/378828) |
| ⭐ | Radio-toggle connector (J11) | **JST B2B-ZR(LF)(SN)** (ZH 1×02: SIG·GND) → the toggle above; **ZHR-2 + 2× ASZHSZH28K152** pigtail (152 mm; §16d) | ZH 1.5 mm, TH vertical | ~$0.2 | [DigiKey ✅](https://www.digikey.com/en/products/result?keywords=B2B-ZR%28LF%29%28SN%29) |
| ⭐ | Speaker driver | Dayton DMA58-4 (2″ FR) — **4 Ω, not the 8 Ω DMA58-8** (the −4.1 dBFS limiter ceiling, `A_GAIN` 19.2 dBV and the L5/L6 10 µH/Isat-3.0 A sizing all assume 4 Ω; 8 Ω also wants 22 µH at L5/L6). **Buys +3 dB on battery only** — plugged, both impedances land on ~8 W because L5/L6 saturation, not the rail, is the ceiling (§16 note). **Ships with bare solder tabs — no wire, no connector**; J3 harness in §16d | 56×56×32 mm | ~$19 | [PartsExpress ✅](https://www.parts-express.com/Dayton-Audio-DMA58-4-2-Dual-Magnet-Aluminum-Cone-Full-Range-Driver-4-Ohm-295-582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) |
| ➕ | CO₂ *(improvement)* | Sensirion SCD41-D-R2 | — | ~$24 | [search](https://www.digikey.com/en/products/result?keywords=SCD41-D-R2) |
| ➕ | PM2.5 *(improvement)* | Sensirion SPS30 | — | ~$38 | [search](https://www.digikey.com/en/products/result?keywords=SPS30) |
| ➕ | Passive radiator *(improvement)* | Dayton DMA58-PR (2″) | — | ~$8 | *(Parts Express)* |

### 16c. Discrete semiconductors + magnetics (switchers, protection, filter)

> Values in [`power_values.md`](power_values.md); enumerated here so the production BOM is complete (these were on the schematic/PCB but not previously listed). Inductor MPNs verified 2026-07-24 against the [Coilcraft XAL40xx datasheet](datasheet/inductor_coilcraft_xal40xx.pdf) (Isat = 30 % L-drop). ⚠️ = action needed before fab.

| Status | Block (refs) | MPN | Size / pkg | ~Unit | Source |
|:--:|---|-----|---|---|---|
| ⭐ | LT3652 buck inductor (L1) | **Coilcraft XAL4040-103MEC** — 10 µH, Isat 3.0 A, Irms 2.2 A, DCR 84 mΩ (I_CHG 1 A, big margin) | 4.0×4.0×4.0 mm | ~$1.0 | [DigiKey](https://www.digikey.com/en/products/result?keywords=XAL4040-103MEC) |
| ⭐ | 5 V-boost inductor (L2) | **Coilcraft XAL4020-102MEC** — 1 µH, Isat 8.7 A, Irms 6.7 A | 4.0×4.0×2.1 mm | ~$0.9 | [DigiKey](https://www.digikey.com/en/products/result?keywords=XAL4020-102MEC) |
| ⭐ | 3.3 V-buck inductor (L3) | **Coilcraft XAL4020-222MEC** — 2.2 µH, Isat 5.6 A, Irms 4.0 A | 4.0×4.0×2.1 mm | ~$0.9 | [DigiKey](https://www.digikey.com/en/products/result?keywords=XAL4020-222MEC) |
| ⭐ | 12 V-boost inductor (L4) | **Coilcraft XGL5050-472MEC** — 4.7 µH, **Isat 9.7 A**, DCR 16 mΩ, in stock; datasheet [`inductor_coilcraft_xgl5050.pdf`](datasheet/inductor_coilcraft_xgl5050.pdf). **Implemented 2026-07-24** on the 5×5 mm `L_Coilcraft_XAL5050-XXX` land (replaces the 4×4 mm `XAL4030-472`, whose 4.6 A Isat was below the ~6 A the 1S→12 V boost peaks at). **Land verified 2026-07-27:** the KiCad `XAL5050-XXX` pads (1.18 × 4.7 mm on a 3.31 mm pitch) are *identical* to the XGL5050 recommended land pattern (doc 1577-1), and the XGL body max 5.48 × 5.68 mm equals the XAL50xx envelope the footprint is drawn for → true drop-in, no edit needed | 5.3×5.5×5.0 mm | ~$1.3 | [DigiKey](https://www.digikey.com/en/products/result?keywords=XGL5050-472MEC) |
| ⭐ | Speaker LC-filter inductor ×2 (L5, L6) | **Coilcraft XAL4040-103MEC** — 10 µH, **Isat 3.0 A**, Irms 2.2 A (20 °C rise) / 3.1 A (40 °C rise), DCR 84 mΩ. They carry the full speaker current and the amp's OCP (7 A/BTL → **~14 A in PBTL**) is 4–5× past their Isat, so **firmware is the only guard**: the DSP limiter is capped at **8 W into 4 Ω** (peak 2.0 A + 0.38 A ripple = 79 % of Isat) — see [`FIRMWARE.md`](FIRMWARE.md) §6.2. ⚠️ still bench-confirm with a current probe on L5 at max volume | 4.0×4.0×4.0 mm | ~$1.0 ×2 | [DigiKey](https://www.digikey.com/en/products/result?keywords=XAL4040-103MEC) |
| ⭐ | Level-shift / rail-disconnect N-FET ×3 (Q1 `FULLCHG_EN`, Q3 `VBAT_DIV_EN`, Q8 `CELL_TEST`) | **2N7002** (60 V, 0.3 A N-MOSFET) — datasheet [`fet_2n7002.pdf`](datasheet/fet_2n7002.pdf) | SOT-23 | ~$0.10 | [DigiKey](https://www.digikey.com/en/products/result?keywords=2N7002) |
| ⭐ | LT3652 BOOST refresh diode (D10) | **BAT46W-E3-08** (Schottky, 100 V) — schematic value `BAT46`; the SOD-123 part is **BAT46W**. Datasheet [`diode_schottky_bat46w.pdf`](datasheet/diode_schottky_bat46w.pdf) | SOD-123 | ~$0.30 | [DigiKey](https://www.digikey.com/en/products/result?keywords=BAT46W-E3-08) |
| ⭐ | Charger catch + 12 V-boost rectifier (D11, D20) | **B340A-13-F** (Schottky, 40 V / 3 A) — datasheet [`diode_schottky_b340a.pdf`](datasheet/diode_schottky_b340a.pdf) | SMA / DO-214AC | ~$0.30 | [DigiKey](https://www.digikey.com/en/products/result?keywords=B340A-13-F) |
| ⭐ | Amp-mux 12 V blocking diode (D30) | **B340A-13-F** (SMA). **Implemented 2026-07-24** — was `SS34` (an SMC part) on an SMA land; now B340A to match the land + consolidate with D11/D20 (one Schottky P/N + [datasheet](datasheet/diode_schottky_b340a.pdf)). The mux leg only needs ≥1.5 A / 40 V, so 3 A is ample. | SMA / DO-214AC | ~$0.30 | [DigiKey](https://www.digikey.com/en/products/result?keywords=B340A-13-F) |

*(XAL4020/4030/4040 share one 4×4 mm land, so the KiCad `L_Coilcraft_XAL4030-XXX` / `XAL4020-XXX` footprints already fit L1/L2/L3/L5/L6 — only L4 moves to the 5×5 mm `L_Coilcraft_XAL5050-XXX` land. TVS D1/D12 → [`tvs_smaj.pdf`](datasheet/tvs_smaj.pdf); VBAT-sense clamp D13 BAT42W → [`diode_clamp_bat42w.pdf`](datasheet/diode_clamp_bat42w.pdf); USB ESD U16 → [`esd_usb_usblc6.pdf`](datasheet/esd_usb_usblc6.pdf).)*

**Core electronics subtotal (excl. speaker/cell/PCB): ~$140–165** — the v0.19 redesign removes ~$47 of display lines (LS032B7DD02 ~$38 + FPC + panel extension + Cree string) and adds ~$55 of UI parts (EM14 optical encoder **$34** + Kilo knob **$13.43** + NeoPixel 10-pack $5.95 + buffer + SH connectors) → roughly a wash vs v0.18; power electronics ≈ +$20–22 (LT3652 is the priciest line); the sensor set is the **2b daughterboard that was actually built** (`kicad-sensor/`) — BME688 + TSL2591 + **BNO085** ≈ **$22** of silicon + a small PCBA; the 2a breakout chain would be ≈ **$51**. *(The BNO085 is ~$8.6 dearer than the LIS3DH it replaced, so the range above moves up by about that.)* With speaker + user-supplied 18650 + holder + 4-layer PCB + passives ≈ **~$210–250**. +CO₂/PM ≈ +$62. *(Cell is user-supplied; safety HW is non-negotiable — see [`power.md`](power.md).)*

**Cost/space levers:** budget movement (VID28-05, −$10, off-DigiKey) + optical homing; a mechanical encoder (PEC11R-4015F, −$31) if the optical EM14 feels extravagant; skip CO₂/PM; the EM14 + movement are now the big electronics line items — the enclosure (walnut + machined aluminum plate + knob + glass) dominates overall cost instead. *(Amp DSP is free — it runs in firmware.)*

### 16d. Off-board harnesses — JST cables + housings (verified 2026-08-06)

> The PCB-side headers are listed in §16b; **this table is the mating half** — what actually
> gets ordered to wire the off-board parts. All runs are **152.4 mm (6″)** — the shortest
> stocked length above the ~120 mm the enclosure needs.
>
> JST **pre-crimped leads are socket-to-socket**: one 152 mm wire with a crimp contact on
> *both* ends. Insert one contact into the housing, snip + strip the far end and solder it to
> the off-board part → you keep the full 152 mm. Only **J7** is a true board-to-board run, so
> it is the only ready-made double-ended cable.

| Ref | PCB header (§16b) | Mating half to order | DigiKey PN | Qty | ~Unit |
|---|---|---|---|--:|--:|
| **J7** sensor board | B6B-ZR(LF)(SN) ×2 | **A06ZR06ZR28H152B** — ZH 6-pos cable, socket↔socket, 28 AWG, 152 mm *(supersedes the 102 mm `…H102B` quoted in §16b)*. 🔴 **The trailing letter is the wiring and it is destructive to get wrong** — see below | [455-3039-ND](https://www.digikey.com/en/products/detail/jst-sales-america-inc/A06ZR06ZR28H152B/6009439) | 1 | $1.89 |
| **J10** knob (EM14) | B6B-ZR(LF)(SN) | **ZHR-6** housing + 6× **ASZHSZH28K152** lead | [527361](https://www.digikey.com/en/products/detail/jst-sales-america-inc/ZHR-6/527361) · [455-3079-ND](https://www.digikey.com/en/products/detail/jst-sales-america-inc/ASZHSZH28K152/6009453) | 1 + 6 | $0.11 · $0.42 |
| **J11** radio toggle | B2B-ZR(LF)(SN) | **ZHR-2** housing + 2× **ASZHSZH28K152** lead | [566476](https://www.digikey.com/en/products/detail/jst-sales-america-inc/ZHR-2/566476) · 455-3079-ND | 1 + 2 | $0.10 · $0.42 |
| **J9** wake COB strips | B3B-PH-K-S(LF)(SN) | **PHR-3** housing + 3× **ASPHSPH24K152** lead | [527357](https://www.digikey.com/en/products/detail/jst-sales-america-inc/PHR-3/527357) · [455-3082-ND](https://www.digikey.com/en/products/detail/jst-sales-america-inc/ASPHSPH24K152/6009458) | 1 + 3 | $0.10 · $0.38 |
| **J12** status NeoPixels | B3B-PH-K-S(LF)(SN) | **PHR-3** housing + 3× **ASPHSPH24K152** lead | 527357 · 455-3082-ND | 1 + 3 | $0.10 · $0.38 |
| **J3** speaker | B2B-PH-K-S(LF)(SN) | **PHR-2** housing + 2× **ASPHSPH24K152** lead — **the DMA58-4 ships with bare solder tabs, no wire and no connector** | [608607](https://www.digikey.com/en/products/detail/jst-sales-america-inc/PHR-2/608607) · 455-3082-ND | 1 + 2 | $0.10 · $0.38 |

**Consolidated cart (with 2 spare leads per family) ≈ $10.40:**
`A06ZR06ZR28H152B` ×1 · `ZHR-6` ×1 · `ZHR-2` ×1 · `ASZHSZH28K152` ×10 · `PHR-3` ×2 · `PHR-2` ×1 · `ASPHSPH24K152` ×10.

> 🔴 **The J7 cable's trailing letter is its wiring, and the wrong one destroys the BNO085.**
> JST ships this cable in both orientations under numbers that differ by one character:
>
> | Order this | Not this |
> |---|---|
> | **`A06ZR06ZR28H152B`** — [455-3039-ND](https://www.digikey.com/en/products/detail/jst-sales-america-inc/A06ZR06ZR28H152B/6009439), DigiKey calls it *"Socket to Socket"* | ~~`A06ZR06ZR28H152A`~~ — [455-3027-ND](https://www.digikey.com/en/products/detail/jst-sales-america-inc/A06ZR06ZR28H152A/6009403), DigiKey calls it *"Socket to Socket, **Reversed**"* |
> | pin 1 ↔ pin 1 (straight through) — what both boards need | pin 1 ↔ pin 6 — plugs in perfectly and puts **+3V3 onto the BNO085's `H_INTN`** while its VDDIO is ~0 V |
>
> The `…A` is ~3 V over the BNO08X abs-max of `VDDIO + 0.3 V` (Figure 6-1) into the ESD clamp,
> limited only by `R97`'s 10 k. Assume the part is dead — it is the most expensive one on either
> board. Full trace in [`kicad-sensor/REVIEW.md`](kicad-sensor/REVIEW.md) §4.
>
> **Both suffixes look identical in the bag, so do not trust the label — ring it out.** DMM on
> continuity, cable out of both boards: **pin 1 of one end must beep to pin 1 of the other**. If
> it beeps to pin 6, it is an `…A` and it must be re-pinned or replaced. *(This is not
> hypothetical: the cable that arrived for build #1 on 2026-09-08 was reversed, and the DMM check
> is the only reason the BNO085 survived.)*

**Why these mate / carry the current:**
- **ZH (1.5 mm):** `ZHR-n` housings mate the `B*B-ZR` headers; `ASZHSZH…` carries **SZH** contacts at **28 AWG** — inside the SZH 28–26 AWG window.
- **PH (2.0 mm):** `PHR-n` housings mate the `B*B-PH-K-S` headers; `ASPHSPH…` carries **SPH** contacts at **24 AWG** — top of the SPH 28–24 AWG window; PH is rated 2 A/contact.
- Current per harness: **J9 ≈ 0.6 A** (2× ~1 ft of 3.6 W/ft COB @ 12 V), **J12 ≈ 0.4 A** (5 px all-white), **J3 ≈ 1.4 A rms / 2.0 A pk** at the 8 W firmware cap ([`FIRMWARE.md`](FIRMWARE.md) §6.2) — 24 AWG over 152 mm adds ~25 mΩ round-trip (0.6 % of a 4 Ω load). J7/J10/J11 are signal-level.
- Side benefit for the **J7/J10 mis-mate hazard** (both ZH 1×06, 13.5 mm apart — [`kicad/REVIEW.md`](kicad/REVIEW.md) §10): J7's harness has *two* connectors, J10's has *one*, so they are physically unmistakable on the bench.

**J11 rear toggle — `100SP1T2B1M1QEH` build notes (part bought 2026-08-06).** Datasheet:
[E-Switch 100 series](https://configured-product-images.s3.amazonaws.com/Datasheets/100.pdf).

- **Wiring — it is an SPDT used as an SPST.** `SP1` = *On-None-On*, so there is **no off position**;
  per the function table, POS.1 closes **2-3** and POS.3 closes **2-1**, i.e. **lug 2 is the common**.
  Land **lug 2 → J11.1 (`RADIO_OFF`, expander GPA3)** and **lug 1 *or* 3 → J11.2 (GND)**, leaving the
  opposite lug unconnected. One bat position then shorts GPA3 to GND, the other floats it up to the
  MCP23017's internal pull-up. **Polarity to lock in firmware: closed/low = radios OFF** — a broken
  harness therefore reads high = radios enabled, which stays diagnosable over Wi-Fi/BLE instead of
  silently killing NTP and OTA. Nothing else is needed on the harness (no RC — `IOC` + the AO's
  entry-action re-check in [`FIRMWARE.md`](FIRMWARE.md) §6.7 already handle a slow, static input).
- ⚠️ **Mechanical — the bushing is shorter than the wall.** `B1` is **8.89 mm** of 1/4-40UNS, and the
  supplied nut + lockwasher consume ~2.4 mm of it, so the **maximum panel thickness is ~6 mm**. A
  ~120 mm walnut cube wall is typically 10–12 mm → **counterbore the inside face of the rear panel to
  leave ≤6 mm of wood at the Ø6.35 mm switch hole**, or the nut will never bite. Fix this with the
  enclosure drawing, not at assembly. With a 5 mm residual wall the bat tip lands ~9 mm proud of the
  wood — flippable, but the `T2` actuator is the **short 5.08 mm** bat by design (`T1` is 10.41 mm if
  the built prototype turns out to be fiddly).
- ⚠️ **Contact material is `Q` = silver, and J11 is a dry circuit.** E-Switch rates silver at
  5 A @ 120 VAC/28 VDC but publishes a **low-level rating only for the `R` gold option** (0.4 VA max
  @ 20 V). J11 switches nothing but the MCP23017's ~100 kΩ internal pull-up: **~33 µA at 3.3 V**, far
  under any wetting current, and a preference toggle gets flipped rarely so the contacts never wipe.
  The `E` epoxy seal plus a benign indoor environment is the mitigation actually in play — and the
  gold `100SP1T2B1M1REH` is **non-stocked at DigiKey (12-week lead)**, so the silver part stands.
  **If the read ever proves intermittent:** stuff an external 4.7–10 kΩ pull-up on the harness
  (0.3–0.7 mA, ~10–20× the wetting current, still nowhere near any rating) before replacing the switch.

**Speaker impedance — buy the 4 Ω `DMA58-4` (Parts Express 295-582), not the 8 Ω DMA58-8.**
The whole audio chain is dimensioned for 4 Ω: TAS5760M PBTL off the 12 V boost, the firmware
limiter ceiling (−4.1 dBFS = 8 W into 4 Ω), the `A_GAIN` 19.2 dBV setting, and the L5/L6
XAL4040 Isat-3.0 A sizing all derive from it. 8 Ω additionally wants **22 µH** at L5/L6 per TI's
filter table, so it is two more BOM lines, not just a driver swap.

*(Corrected 2026-08-08 — this note used to claim "8 Ω would halve output to ~4 W". **It would
not, when plugged.** At 4 Ω the plugged ceiling is not the rail, it is **L5/L6 saturation**: the
rail would allow 16.5 W but the limiter caps it at 8 W to keep peak inductor current at 79 % of
Isat. At 8 Ω you are rail-limited at 11.5 V → 8.26 W, at only 61 % of Isat. **Plugged, the two
impedances give the same ~8 W and the same SPL.** The difference is real only on **battery**,
where PVDD muxes to ~5 V and the rail clips: **4 Ω = 3.1 W, 8 Ω = 1.6 W — a genuine +3 dB for
the 4 Ω.** So the case for 4 Ω is battery loudness and matching the constants already chosen,
not plugged output.)*

---

## 17. Alternatives quick-reference

- **MCU:** ESP32-S3 ⭐ single-chip / STM32U5 + ST67W611M1 (ULP) / nRF5340 + nRF7002 (Nordic ULP) / RW612 (single-chip) / ESP32-P4 + C6 (future MIPI).
- **Info display:** **none (v0.19)** ⭐ — hands + 5 status NeoPixels. *Superseded: Sharp LS032B7DD02 reflective MIP (v0.6–v0.18, datasheets retained) / mono OLED / IPS TFT / EPD / wide color bar-TFT (NHD-3.9).*
- **Status/dial LEDs:** **SK6812 RGBW 5050 ×7** ⭐ (one SPI3 data line, 5 V) / discrete LEDs + PWM (more pins, no color semantics — the v0.18 panel-string approach, dropped).
- **Knob encoder:** Bourns **EM14A0D-C24-L064S** ⭐ (optical, no detent, 64 CPR, push, 5 V — chosen for the smoothest contactless feel) / Bourns PEC11R-4015F (mechanical no-detent, 24 PPR, $2.68 budget alt) / Alps EC11 (detented) / magnetic (AS5600, overkill). Knob: Kilo **OEJNI-90-1-5** ⭐ (Ø23.5 mm alu, 1/4″ bore).
- **Analog movement:** Juken **X40.879** (DigiKey, now Ø~90 mm dial) ⭐ / Juken X10.506 (small, built-in homing) / VID28-05·BKA30D-R5 (budget, off-DigiKey) / X27.168 ×2 (single-shaft).
- **Motor driver:** **2× TB6612FNG** ⭐ (SSOP-24, hand-solderable). *(DRV8835/DRV8833 = WSON/HTSSOP, replaced.)*
- **Amp:** **TAS5760M** ⭐ (I²S+I²C, HTSSOP, PBTL mono; firmware DSP) / PCM5102A + TPA3116 (analog).
- **Power:** **CH224K** (PD sink) + **LT3652** (1-cell buck charger, BAT-node path) + **ESP32 ADC** gauge + **HY2111-HB + AOSD32334C** protector + reverse P-FET; 1S Li-ion 18650 holder. *(All leaded/hand-solderable; CH224K + HY2111 off-DigiKey.)*
- **Timekeeping (no RTC IC / no battery):** ESP32-S3 internal RTC off a **32.768 kHz crystal** (~±20 ppm, GPIO15/16) + periodic **SNTP** — drift ≈ 1–2 s/day between syncs, corrected each sync. On total power loss (USB **and** 18650 gone) time is lost → re-sync on next boot, clock animation meanwhile. *A battery-less RTC IC adds parts without fixing the loss case, so it's dropped; the crystal is the real accuracy fix.*
- **Sensors:** env **BME688** ⭐ (T/RH/press/VOC in one chip) / light **TSL2591** ⭐ (weak-light) or VEML7700 (lux-direct) / tap **CEVA BNO085** ⭐ *(replaced the LIS3DH 2026-07-29)*. All leadless → **same 3-part set, same I²C addresses, on either path** (firmware identical): **2b = the custom daughterboard, built** (`kicad-sensor/`, `SENSE v0.2`); **2a** = Adafruit STEMMA QT chain (5046 + 1980 + 4754, ≈$51) for bring-up. *(Dropped TMP117/SHT45/SGP41/BMA400/LIS3DH.)*
- **Hand homing:** **1× reflective optical** (onsemi **QRE1113** ⭐, **≈3.6×2.9×1.7 mm**, analog out → 1 ADC) behind a punched dial hole — single-sensor sequential, **no magnets**; replaces the unavailable **ITR8307** (same interface + support network); Vishay **TCND5000** (6×4.3×3.75 mm) evaluated for a long stand-off and dropped; ToF (VL53L1x) rejected (coarse angle). *(Replaces 2× DRV5032 Hall.)*
- **Display connector:** *(dropped with the display, v0.19; FH34SRJ datasheet retained.)*
- **USB-C receptacle:** **GCT USB4160-03-0230-C** ⭐ (vertical 24-pin USB 3.2, USB 2.0 subset wired, $1.22, in stock) / GCT USB4145-03-0170-C (16-pin same-land alt) / Same Sky UJ20-C-V-C-2 (TH pins, backorder) / USB4140 & UJ20-C-V-C-1 (rejected: power-only resp. 0.8 mm-PCB legs) / USB4105-GF-A + Adafruit 6069 extension (the superseded horizontal + panel-remote combo).
- **Speaker:** Dayton DMA58-4 ⭐ (2″) / Dayton PC68-4 (2.5″, more bass) / Adafruit 3351 (budget).

---
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

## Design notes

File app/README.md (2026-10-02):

# Clock — iOS / macOS debug app

A SwiftUI app that talks to the wooden clock over Bluetooth LE. For now it is a **bring-up and
debug tool**: connect, pair, watch the live status snapshot, and drive the clock's CLI from a
command table or a shell with autocomplete. It is the phone side of the contract in
[`PROTOCOL.md`](PROTOCOL.md) + [`protocol.json`](protocol.json).

| | |
|---|---|
| Platforms | iOS 27, macOS 27 (same target; a Mac build is handy at the bench) |
| Language | Swift, SwiftUI, CoreBluetooth, Observation, async/await (no Combine) |
| Tests | Swift Testing (`clockTests`), hosted in the app |
| Protocol | v1 / snapshot schema 1 — read from the bundled `protocol.json` at runtime |

## Build & run

1. Open `clock.xcodeproj` in Xcode 27.
2. Pick **a real iPhone or My Mac**. The Simulator has no Bluetooth: the app runs there, but the
   Clock tab shows "Bluetooth LE not available". The UI previews use a fake link.
3. Run. Allow Bluetooth when asked.
4. **Pair (first time only):** hold the knob on the clock for 10 s until the five LEDs breathe
   blue. The clock then shows **ready to pair** in the Clock tab. Tap it, then accept the iOS
   pairing prompt.
5. Tests: ⌘U (or `xcodebuild test -scheme clock -destination 'platform=macOS'`).

## Screens

| Tab | What it does |
|---|---|
| **Clock** | Scans for clocks, with a "ready to pair" badge from the advertising data. Connects and disconnects, and reconnects to the last clock. Explains pairing failures (window shut → hold the knob; clock forgot the phone → *Forget This Device*). Shows `info` (fw, sha, board, proto) with a protocol-version check, and has the "send phone time on connect" toggle. |
| **Status** | The live `status` snapshot: sequence number, samples missed, age, clock time vs phone time, every flag as a chip, the 7 LEDs as colour swatches, and grouped values (power, room, light, IMU, hands, UI, radio). Invalid values show "—". Fields the layout doesn't list appear under **Other fields**. There is also a raw hex view and a notify-period menu. |
| **Sounds** | The clock's microSD `/sd/tones` (`storage tones`): size, length, playability state, which one is the alarm; swipe to delete, context menu to play / stop / use it for the alarm. Below it, the WAVs **bundled with the app** (`clock/Tones/`), each checked against `sound_files.format`, with an upload button and a progress bar (`storage put` + `blob` writes, busy retry, resume after a dropped link). Hidden when the clock has no card or no `blob` characteristic. |
| **Commands** | Every known command, grouped, with its help, arg ranges and badges (`unsafe`, `planned`, `device` = only the firmware's `help` knows it). Tap one to fill its arguments (pickers for `on\|off` choices, range warnings) and send it. Quick actions: sync time, `sys ver`, tone, stop, `unsafe on`, close pairing. |
| **Clock → Wi-Fi** | The clock's own scan of networks in range, join (SSID + password sent `hex:`-encoded over the bonded link, never echoed to the shell), forget; state, last failure reason and signal from the snapshot. |
| **History** | The clock's history log, **mirrored on the phone** (`Application Support/History/<clock id>/<yyyymmdd>.bin`, byte for byte; never deleted because the clock deleted it). Syncs on every connect and from *Sync now*: `log days` → diff → `log fetch <day> <from>` → `bulk` packets → CRC-32 → atomic append. Other commands wait while it runs (the toolbar says "syncing history…"). Charts (Swift Charts) per quantity: temperature, humidity, pressure, gas (log), light (mean + peak), battery, charge, Wi-Fi; 24 h · 7 d · 30 d · 1 y · All, bucketed to ≤ ~1000 points with a min…max band, lines broken at gaps > 2 periods, events as rules plus a list. Settings sheet: `log status`, period / keep / cap / record. Export: the raw day files, or a CSV. |
| **Logs** | The clock's debug journal (every log line, one file per boot on its card), **mirrored on the phone** (`Application Support/Journal/<clock id>/<name>`, never deleted because the clock deleted it). Syncs on opening the tab, on *Refresh*, and every 5 s with **Follow** on (one small tail fetch of the current file): `sys journal files` → diff by name → `sys journal fetch <name> <from>` → `bulk` → CRC-32 → atomic append; shares the one download slot with History. Header from `sys journal` (boot, card, lines lost). Boot list, newest first, parts grouped: reset reason (red for panic / watchdog / brown-out), "ended: …" from the next boot, *current* and *rescued lines* badges, size. Viewer: parts concatenated, colour by level, level chips, tag menu, search, `+h:mm:ss.mmm` since boot, the rescued "before the reset" section tinted with **Jump to before the reset**, last 5000 lines with *Load all*; menu for `sys debug <tag> debug` / `sys debug all info`; Share the raw files. |
| **Shell** | A terminal over BLE, the same commands as the USB console. Completion chips for the next word or argument. Tab / ↑ / ↓ on a hardware keyboard, or the chevrons. History is persisted. Output is coloured by record kind (`>` sent, `$` status, `=` pairs, `#` app notes), with an optional raw-frame view. |

On connect the app automatically:
1. subscribes to `rsp` (this is what triggers iOS pairing), then to `status`, and reads `info`
2. sends the zone as a POSIX rule (`chrono tz <posix> <iana>`) and then `chrono time epoch <now_ms> <utc_offset_min>` (PROTOCOL.md "Keeping time"), and sends both again whenever the phone's timezone changes
3. runs `help`, then `help <group>` for each group, and merges the result into the command list
4. syncs the history log (only what is new: normally today's tail)

On iOS it disconnects when backgrounded and reconnects when it comes back (PROTOCOL.md §7).

## Alarm schedule (Clock tab → Alarm)

The clock now keeps a **weekly schedule** (a time per weekday, each on/off — set from the app with
`chrono alarm week`) and at most **one one-off** of the next alarm, set with the clock's knob (or
`chrono alarm next`). The one-off replaces that one day's alarm and never changes the schedule;
the snapshot shows it live (`alarm_next = override`), even while the app is connected. The Alarm
screen: master switch, next alarm + a *Cancel* banner for a one-off, seven day rows (any edit sends
the whole week, debounced), "Just once". A 132-byte snapshot (older firmware) shows the single
daily alarm instead. Status tab: "Alarm" group.
Behaviour: PROTOCOL.md "Alarm schedule".

## Alarm sounds

Drop `.wav` files into **`app/clock/Tones/`** and rebuild — the folder is part of the synchronized
`clock` group, so every file in it is copied into the app bundle, no project edit needed. They
appear under **Sounds → In the app** and can be uploaded to the clock. The clock plays only
**WAV PCM, 48 kHz, mono, 16-bit**, max 16 MB; other files are listed with the reason and can't be
uploaded. Convert with `ffmpeg -i in -ac 1 -ar 48000 -c:a pcm_s16le -bitexact out.wav`. The file
name is the name on the card (ending `.wav`, 5–63 bytes, no leading `.`, none of `/ \ : * ? " < > |`).

An upload runs at roughly 5–10 KB/s. Keep the app in the foreground (iOS disconnects in the
background); after a dropped link, tap upload again and it resumes where the clock left off.

## Designed to follow the protocol

All protocol numbers come from `protocol.json`, which is bundled **by reference**: the file in
this folder, not a copy. Editing the contract and rebuilding is enough.

| From `protocol.json` | Used for |
|---|---|
| `gatt.*` UUIDs | service / characteristic discovery |
| `advertising.manufacturer_data` | the "ready to pair" bit |
| `command_channel` | id range, max request bytes, timeout, statuses |
| `commands[]` | the command table + autocomplete (with `args` ranges / hints) |
| `snapshot.fields` | the decoder: offset, type, scale, unit, `valid_if`, `enum`, `sentinel` |
| `snapshot.flags` / `enums` | flag chips, enum labels (`unknown(n)` for newer values) |
| `snapshot.golden` | the decoder's unit test |
| `sound_files` | the WAV format check, upload size limit, `blob` ATT error names |
| `history` | the day-file decoder: header checks, record fields (offset, type, scale, `valid_if`, `sentinel`), kinds, `encodings` (parsed `10^(v / k) − c`), flag and event names, golden vectors |
| `journal` | log file names + part order (`name_regex`), line split (`line_regex`), boot header and reset reasons, the rescued marker |

Compatible protocol changes (PROTOCOL.md "Change process") need **no Swift change**:
- **New command:** appears in the table and in autocomplete.
- **New snapshot field at the end:** shows up in *Other fields*.
- **New flag bit:** gets a chip.
- **New history sample field:** gets a chart under *Other*, and a CSV column.
- **New enum value:** shows as its label.
- **Longer snapshot:** the extra bytes are ignored until the JSON describes them.

The Swift code holds only the *rules* of `PROTOCOL.md`: framing, one request at a time, busy
retry, pairing hints, and the local-time formula.

Commands the firmware lists in `help` but the JSON doesn't document are parsed on a
best-effort basis. That output is human text, so rows that don't parse are dropped, and the
JSON entries always stay.

## Layout

```
app/
├── PROTOCOL.md, protocol.json   the contract (shared with firmware/)
├── clock.xcodeproj
├── clock/                       app target (synchronized folder)
│   ├── clockApp.swift           loads the spec, creates the link
│   ├── ContentView.swift        tabs, background disconnect
│   ├── Protocol/                pure, UI-free, unit-tested
│   │   ├── ProtocolSpec.swift     Decodable model of protocol.json
│   │   ├── SnapshotDecoder.swift  data-driven little-endian decoder
│   │   ├── Snapshot.swift         decoded record, validity, local time, pixels
│   │   ├── ResponseFramer.swift   rsp frames `| + = $`, per-id reassembly
│   │   ├── DeviceInfo.swift       `info` key=value + proto check
│   │   ├── CommandCatalog.swift   JSON + `help` commands, completion
│   │   ├── SoundFiles.swift       `storage tones` list, WAV header check, CRC-32, blob values
│   │   ├── HistoryRecord.swift    day-file decoder: header, CRC-8, samples, events
│   │   ├── HistorySync.swift      `log days` → fetch plan, `FileSync` diff, `bulk` packets + reassembly
│   │   ├── HistorySeries.swift    chart points: buckets (min/mean/max), gap segments
│   │   ├── JournalSync.swift      `sys journal files` → fetch plan, file names, boots
│   │   ├── JournalLine.swift      journal lines: level / ms / tag, header, rescued section, filter
│   │   └── JSONValue.swift
│   ├── BLE/
│   │   ├── ClockLink.swift        CoreBluetooth central, request queue, blob writes, bulk fetches, state
│   │   ├── ToneStore.swift        sound files: list / delete / upload driver, bundled WAVs
│   │   ├── HistoryStore.swift     history: sync driver, settings, chart loading, export
│   │   ├── HistoryArchive.swift   the phone's copy of the day files, CSV
│   │   ├── JournalStore.swift     logs: sync driver, Follow, boot list, parsing cache
│   │   ├── JournalArchive.swift   the phone's copy of the journal files
│   │   └── LinkTypes.swift        phases, problems/hints, results, transcript lines
│   ├── Tones/                   drop alarm WAVs here (bundled as resources)
│   └── Views/                   Connect, Status, History, Logs, Sounds, Commands, Shell, Common
└── clockTests/                  Swift Testing: golden vector, framing, catalog, history, journal, sound files
```

## Troubleshooting

| Symptom | Fix |
|---|---|
| "Pairing refused" right after the iOS prompt | The pairing window was shut. Hold the knob 10 s, then connect again. |
| "Clock forgot this device" / pairing fails at once | Settings → Bluetooth → clock → **Forget This Device**, then pair again with the window open. |
| No clock in the scan | Check the rear radio toggle. Another phone may be connected (one link at a time). |
| `denied` on `motion home` / `sys reboot` | Send `unsafe on` first. The command sheet offers to do it for you. |
| `busy` | The USB console is streaming. The app retries once after 1 s. |
| History / Logs: "no `bulk` characteristic", Sounds tab hidden, while `info` shows a current `sha` | The phone cached the clock's old GATT table (paired before a firmware update). Firmware since 2026-10-01 announces GATT changes (*Service Changed*) so this heals on the next connect; for older firmware, or if it persists: **Forget This Device** (macOS: System Settings → Bluetooth → ⓘ → Forget), `net ble unbond` on the clock, hold the knob 10 s, pair again. If `sha` is old, reflash. |

Reference client to compare against: `firmware/tools/clockctl.py` (`shell`, `status --watch`).

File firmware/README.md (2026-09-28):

# firmware/

ESP32-S3 firmware for the wooden smart clock. **Design doc: [`../FIRMWARE.md`](../FIRMWARE.md)** —
it is the source of truth; this file is only how to build.

Status: **early**. Logging, the CLI registry, both build systems, the fake HAL and the first
three active objects (`motion`, `chrono`, `ui`) are real and tested. The ESP-side HAL is real
apart from `hal::wake`, and that includes the amp since 2026-09-13 — I²S, the TAS5760M's
registers and an `audio tone` (`FIRMWARE.md` §12.0.15), though nothing has been through a
speaker yet. The `audio`, `storage`, `board`, `net` and `supervisor` **active objects** are
still directories with READMEs.

## First time

```sh
tools/idf-setup.sh          # clones + installs the ESP-IDF pinned in toolchain.lock
```

Installs into `~/esp/esp-idf-<tag>` (one directory per tag, so versions coexist and a
rollback is a `toolchain.lock` edit, not a re-download). On macOS it also installs
`python@3.13`, because IDF 5.5's `detect_python.sh` takes the first `python3` on PATH and is
not tested above 3.13.

## Formatting

`clang-format`, Google style with four deviations (4-space indent, 100 cols, left-bound
pointers, include blocks preserved) — all of it in [`.clang-format`](.clang-format).

```sh
tools/format.sh                 # rewrite every C++ file under firmware/
tools/format.sh --check         # exit 1 + list what is unformatted
tools/format.sh a.cpp b.hpp     # just these
```

Needs `brew install llvm` (keg-only, so the script looks it up rather than trusting PATH;
`$CLANG_FORMAT` overrides). The major is pinned in `toolchain.lock` because clang-format's
output drifts between releases — a mismatch warns, it does not fail.

Two things run it for you:

- **VS Code** — format-on-save for `.c/.cpp/.h/.hpp` via `.vscode/settings.json`. Needs the
  `ms-vscode.cpptools` extension (it is in `.vscode/extensions.json`, so VS Code offers it).
- **pre-commit hook** — formats and re-stages the staged C++. It ships in `.githooks/`, which
  git does not read on its own; **once per clone**:

  ```sh
  git config core.hooksPath .githooks
  ```

  A *partially* staged file is reported and left alone — reformatting the working tree and
  re-adding it would drag the unstaged hunks into the commit. `--no-verify` skips the hook.

## Target build

```sh
tools/build.sh                             # dev / devkit / build
tools/build.sh dev devkit flash monitor
tools/build.sh release rev0_3 build
tools/build.sh dev devkit-uart flash monitor   # UART console, for chasing a boot crash
```

`PROFILE` ∈ `dev|release`, `BOARD` ∈ `devkit|devkit-uart|rev0_3`. They compose
`sdkconfig.defaults` + fragments; `sdkconfig` itself is git-ignored so a hand-edited
menuconfig can never be committed. Build dirs are `build/<profile>-<board>/`.

### Name the port on macOS — auto-detect picks the wrong one

Every Mac has a built-in `/dev/cu.debug-console`, and `idf.py`'s port scan takes it in
preference to the board. It then fails the way a dead board would:

```
Serial port /dev/cu.debug-console
Failed to get PID of a device on /dev/cu.debug-console, using standard reset sequence.
/dev/cu.debug-console failed to connect: ... No serial data received.
```

Nothing is wrong with the board. Pass the port — anything after `PROFILE BOARD` goes
straight through to `idf.py`, and `-p` covers `flash` and `monitor` in one invocation:

```sh
tools/build.sh dev rev0_3 -p /dev/cu.usbmodem101 flash monitor
```

`export ESPPORT=/dev/cu.usbmodem101` does the same for a whole session. Don't put it in a
shell profile — the number changes with the USB port and with re-enumeration. Find the
current one with `ls /dev/cu.usbmodem*`.

**The board needs its own power while you do this.** USB VBUS reaches the LT3652 and nothing
else, and the charger idles below 11.2 V, so a Mac's 5 V port powers no rail: `J1` is data
only. Put a cell in the holder and leave it in — the `J12` 5 V injection this used to recommend
is retired (`../FIRMWARE.md` §12.2, and §12.0.13 for what to do if re-inserting the cell trips
the protector: momentarily short `U4` pin 1 to pin 3, which is now the documented procedure —
`../FIRMWARE.md` §12.0.17).

## Talking to the clock over BLE — `tools/clockctl.py`

The reference client for the app link (FIRMWARE.md §8), and the bench tool until an app exists.
`pip install bleak`, then hold the knob 10 s (or `net ble pair` on the console) and:

```sh
tools/clockctl.py scan                         # clocks in range; PAIRING = window open
tools/clockctl.py shell                        # the CLI over the air -- `help` works
tools/clockctl.py run "sys snap"               # one command; exit status = its Status
tools/clockctl.py status --watch --csv log.csv # every status notification, one CSV row each
```

After the first build with BLE, **`rm build/*/sdkconfig` once** — an sdkconfig generated before
`CONFIG_BT_*` was in `sdkconfig.defaults` keeps BT off.

## Host build — tests and `clocksim`

Needs only cmake + ninja. No IDF, no hardware.

```sh
cmake --preset host-dev
cmake --build --preset host-dev
ctest  --preset host-dev
./build/host-dev/apps/clocksim/clocksim            # console + the ux/ bridge on 4747
./build/host-dev/apps/clocksim/clocksim --no-ui    # console only
```

`host-asan` is the same with ASan + UBSan, `host-tsan` with ThreadSanitizer — worth running
whenever you touch `core/ao`, `core/port` or the fake HAL's locking, since the active objects
are the only real concurrency in the host build.

## Seeing it

```sh
python3 ../ux/uxapp.py        # opens http://127.0.0.1:8787 and attaches to clocksim
```

The plate, both hands, the seven pixels, the wake light and the speaker, plus controls for
the knob, the rear radio toggle, tap and power. It is a display and an input device — it
holds no clock logic, and everything it sends is a line of CLI text you could have typed.
See [`../ux/README.md`](../ux/README.md) and
[`apps/clocksim/README.md`](apps/clocksim/README.md) for the protocol.

## What works right now

```
$ ./build/host-dev/apps/clocksim/clocksim
clock-sim 0.1.0  (hal=fake, board=host, profile=dev)  type `help`
> sys debug drv.* debug          # per-module log levels, globs, prefixes
10 modules -> debug
> unsafe on
> ui led bell red                # chain pos 3 = index 2; dial is 0-1
pixel 2  r=255 g=0 b=0 w=0
> sim hand h 137                 # reach in and move the hands: the firmware is not told
> sim hand m 41
> motion home                    # the real homing FSM, against the real fake mechanism
motion: home: sweeping the minute hand for the index
motion: home: minute zero confirmed, coarse was off by -12 usteps
motion: home: minute parked, sweeping the hour hand
motion: home: hour zero confirmed, coarse was off by -8 usteps
motion: homed in 8694 ms of sim time
> chrono time set 07:38          # and now the hands follow the clock
> sensor homing stream 100 5 --csv > opto.csv
> sim unplug
> ui wake 40 10
denied: wake light is plugged-only (12 V boost gated on PD_PG)
```

The same commands run over USB-CDC on the target — `dispatch()` and the `CmdSpec` table are
shared, only the console front-end and the HAL implementation differ. `sim` is host-only.

**On target the HAL is stubbed**: `clk_hal/esp` returns `NotPresent` for every peripheral, which
is also the correct answer on a devkit until you wire something up. Filling it in is the day-one
bring-up task; `FIRMWARE.md` §12.0.2 lists the order.

## Layout

See [`../FIRMWARE.md` §2](../FIRMWARE.md). Short version: `components/{core,command,board_cfg,
clk_hal,cli}` are implemented; `components/{domain,drivers,services,transport}` are placeholders
with a README each explaining what lands there and what it may depend on.

`clk_hal`, not `hal` — ESP-IDF ships its own `hal` component and IDF component names are a
single flat namespace, so a directory called `hal/` here silently shadows `hal/gpio_types.h`
and every SDK header that includes it.

Dependency violations fail the build — the IDF `REQUIRES` graph is the enforcement mechanism,
not a convention.

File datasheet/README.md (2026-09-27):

# Datasheet Summary

Quick-reference for the datasheets in this folder. Prices are single-unit USD and approximate — click through to verify live stock/price. All parts are **currently active/orderable** (verified 2026-07-04; homing sensor 2026-07-05; sensor set 2026-07-05; **power-path & interconnect set 2026-07-05**; **IO expander 2026-07-07**; **LED / backup-mode / TCO / VCOM 2026-07-12**; **homing sensor re-picked → onsemi QRE1113 2026-07-12**; **amp-PVDD mux LTC4412 2026-07-12**; **cell protector re-picked → AP9101C 2026-07-12, re-picked again → HYCON HY2111-HB 2026-08-08, was -GB from 2026-07-17 (AP9101C family went NRND/obsolete)**; **v0.19 cube-redesign parts 2026-07-19/20**; **IMU re-picked → CEVA BNO085 2026-07-29 (supersedes the LIS3DH, row 14)**) and **match the root [`README.md`](../README.md)** (v0.19).

> ⚠ **Sensor board built as its own PCB (2026-07-29).** The "option 2b" custom sensor daughterboard of §15 now exists as a real KiCad project — [`../kicad-sensor/`](../kicad-sensor/) (schematic + **PCB `SENSE v0.2`, fully routed 2026-08-07**: 30 × 16 mm, **4 layers**, 1.6 mm — sensors that must see the room on the front face, IMU + connector on the back; see [`../kicad-sensor/PCB_NOTES.md`](../kicad-sensor/PCB_NOTES.md)). It carries **BME688 + TSL2591 + BNO085** and plugs into main-board **J7** on the same 6-way JST ZH harness. The **accelerometer changed from the LIS3DH to the BNO085** (9-axis with on-chip SH-2 fusion) — the LIS3DH row/section below is **kept, marked superseded**, per the never-delete-a-datasheet rule.

> ⚠ **v0.19 cube redesign (2026-07-19/20).** The product lost its info display and gained NeoPixel status/dial LEDs, a top-face knob and a vertical USB-C (root README changelog). **No datasheet was removed**: the display set (rows 1, 11) and the horizontal USB-C (row 25) are **retained for a possible future variant** and marked *"not in current build"*. New v0.19 parts are rows **30–34**; the Kilo OEJNI-90-1-5 aluminum knob is purely mechanical (no datasheet filed — dimensions in the root README §16b row).

> 🔩 **HAND-SOLDERABLE PARTS ONLY (hard requirement).** The bare PCB is fab'd externally; **every part is soldered by hand** with an iron. So **no QFN / DFN / WSON / BGA / WLP / LGA** parts sit bare on the board — every active IC here is a **leaded/gullwing** package (SOIC / SOP / SSOP / TSSOP / **HTSSOP** / **MSOP** / SOT-23) or a **castellated/edge module**. Two power parts (amp, charger) are HTSSOP/MSOP **PowerPAD**: the leads are iron-solderable and the belly pad is grounded through a thermal-via array (back-side hot-air optional). This trades **board area** for hand-assembly — accepted. Parts that *only* exist leadless (env/MEMS sensors — **BME688, TSL2591, BNO085** (was LIS3DH); fuel gauge) are pushed onto **pre-made breakout modules** (2a) or a **custom SMT-assembled daughterboard** (2b), or **dropped**; see §15 + the root README manufacturing section. **The rule scopes the main PCB only** — the 2b sensor board ([`../kicad-sensor/`](../kicad-sensor/)) is ordered fab-assembled by definition.

> 🔩 **The stepper ships as two files.** `stepper_motor_x40-879.pdf` is a 2-page **pinout addendum** for the dual-shaft **X40.879** (the motor we're buying); it explicitly defers to the **X27 base spec** (`stepper_motor_x27_base-spec.pdf`) for torque, current, and dimensions. Keep both.

| # | File | Part | Mfr | Package (hand-solder) | Active | ~Price | Interface |
|---|---|---|-----|---|---|---|---|
| 1 | `display_ls032b7dd02.pdf` | LS032B7DD02 (full device spec) — ⚠ **not in current build** (display dropped v0.19; kept for a future variant) | Sharp | module + FPC | ✅ | ~$38 | 3-wire SPI |
| 2 | `mcu_esp32-s3-wroom-1-n8r8.pdf` | ESP32-S3-WROOM-1-N8R8 | Espressif | **module (castellated)** | ✅ | ~$6.3 | Wi-Fi/BLE + UART/SPI/I²C/I²S |
| 3 | `speaker_dma58-4.pdf` | DMA58-4 | Dayton Audio | wired (passive) | ✅ | ~$19 | Analog |
| 4 | `stepper_motor_x40-879.pdf` | **X40.879** (dual-shaft) — buy the **.NS** (no stop) | Juken / Switec | wired | ✅ | ~$14 | 2-phase bipolar × 2 |
| 4b | `stepper_motor_x27_base-spec.pdf` | X27 base spec *(companion to #4)* | Juken / Switec | wired | ✅ | — | — |
| 5 | `amp_tas5760m.pdf` | **TAS5760M** (`TAS5760MDAPR`) — ⚠ **`AVDD` (pin 1) is a 4.5–26.4 V pin and must tie to PVDD**; rev0.3 wires it to +3V3 (v0.4 **V13**) | Texas Instruments | **HTSSOP-32 (DAP, PowerPAD)** | ✅ | ~$4–6 | I²S in + I²C control |
| 6 | `motor_driver_tb6612fng.pdf` | **TB6612FNG** (× 2) | Toshiba | **SSOP-24 (no exposed pad)** | ✅ | ~$2.4 | GPIO/PWM (IN/IN) |
| 7 | `pd_sink_ch224k.pdf` | **CH224K** | WCH (Qinheng) | **ESSOP-10** | ✅ | ~$0.4 | USB-PD (resistor-set) |
| 8 | `charger_lt3652.pdf` | **LT3652** (`LT3652EMSE#PBF`) | Analog Devices | **MSOP-12E (PowerPAD)** | ✅ | ~$9.9 | autonomous (resistor-set) |
| 9 | `battery_protector_hy2111.pdf` | **HY2111-HB** (OV 4.28 V / OD 2.90 V, OC 200 mV) | HYCON | **SOT-23-6** | ✅ *(LCSC)* | ~$0.09 | none (autonomous) |
| 10 | `protection_mosfet_aosd32334c.pdf` | **AOSD32334C** (dual N-FET, protector) | Alpha & Omega | **SO-8** | ✅ | ~$0.28 | none (protector FET) |
| 11 | `connector_display_fpc_fh34.pdf` | **FH34SRJ-10S-0.5SH** — ⚠ **not in current build** (went with the display, v0.19; kept) | Hirose | **FPC/ZIF 0.5 mm (SMT)** | ✅ | ~$0.7 | 10-pin display FPC tail |
| 12 | `sensor_env_bme688.pdf` | **BME688** | Bosch Sensortec | LGA-8 → **module** | ✅ | ~$5 | I²C/SPI — **chosen env part:** T+RH+press+**VOC/gas** (one chip = climate + air-quality) |
| 13 | `sensor_light_tsl2591.pdf` | **TSL2591** (`TSL25911FN`) | ams-OSRAM | WFDFN-6 → **module** | ✅ | ~$3 | I²C (188 µlx–88 klx) |
| 14 | `sensor_accel_lis3dh.pdf` | **LIS3DH** — ⚠ **superseded 2026-07-29** by the BNO085 (row 42); kept for a low-cost/low-power variant | STMicroelectronics | LGA-16 → **module** | ✅ | ~$2 | I²C/SPI (tap + orient) |
| 15 | `sensor_homing_QRE1113-D.PDF` | **QRE1113** | onsemi | **4-lead reflective (TH gull-wing, ≈3.6×2.9×1.7 mm) — on-board** (SMD `QRE1113GR` alt) | ✅ | ~$0.76 | reflective opto (analog → ADC/comparator) |
| 16 | `xtal_32k_abs07.pdf` | **ABS07-32.768KHZ-T** (32.768 kHz, CL 12.5 pF, ±20 ppm) | Abracon | **3.2×1.5 mm 2-SMD** | ✅ | ~$0.3 | RTC clock (S3 XTAL32K) |
| 17 | `reverse_pfet_ao3401a.pdf` | **AO3401A** (−30 V, −4 A P-ch) | Alpha & Omega | **SOT-23-3** | ✅ | ~$0.24 | reverse-polarity FET |
| 18 | `ntc_10k_ncp18xh103.pdf` | **NCP18XH103F03RB** 10 k NTC (B25/50 = 3380 K, ±1 %) | Murata | **0603** | ✅ | ~$0.10 | analog → LT3652 NTC |
| 19 | `tvs_smaj.pdf` | **SMAJ22CA** (VBUS) + **SMAJ5.0CA** (BAT), 400 W **bidir** (CA suffix since 2026-07-21; same series datasheet) | Littelfuse | **DO-214AC (SMA)** | ✅ | ~$0.5 ea | TVS clamp |
| 20 | `boost_12v_audio_tps55340.pdf` | **TPS55340PWPR** (5 A/40 V boost) | Texas Instruments | **HTSSOP-14 (PWP, PowerPAD)** | ✅ | ~$2.5 | amp 12 V rail (gated) |
| 21 | `boost_5v_tps61023.pdf` | **TPS61023DRLR** (3.7 A boost, 0.5–5.5 V in) | Texas Instruments | **SOT-563** | ✅ | ~$1.2 | 5 V rail |
| 22 | `buck_3v3_tlv62569.pdf` | **TLV62569DBVR** (2 A buck, 2.5–5.5 V in) | Texas Instruments | **SOT-23-6** | ✅ | ~$0.25 | 3.3 V rail |
| 23 | `holder_18650_keystone_1043.pdf` | **1043** 18650 holder (UL94V-0) | Keystone | **TH PC-pin** | ✅ | ~$2.9 | cell holder |
| 24 | `connector_microsd_dm3at.pdf` | **DM3AT-SF-PEJM5** microSD (push-push) | Hirose | **push-push SMT R/A** | ✅ | ~$2.85 | SD (SPI) |
| 25 | `connector_usb_c_usb4105.pdf` | **USB4105-GF-A** USB-C (USB 2.0, 5 A) — ⚠ **not in current build** (horizontal; superseded v0.19 by the vertical USB4160, row 30; kept) | GCT | **SMT + TH tabs** | ✅ | ~$0.8 | USB-C power+CC |
| 26 | `expander_mcp23017.pdf` | **MCP23017** (I²C; SPI twin `MCP23S17`) | Microchip | **SOIC-28 W / SSOP-28** | ✅ | ~$1.3 | I²C 16-bit GPIO expander (+INT) |
| 27 | `pvdd_mux_ltc4412.pdf` | **LTC4412** (`LTC4412ES6#TRPBF`) | Analog Devices | **TSOT-23-6** | ✅ | ~$5.2 | amp-PVDD PowerPath mux (12 V↔5 V), autonomous |
| 28 | `led_fet_ao3400a.pdf` | **AO3400A** (30 V, 5.7 A, N-ch) | Alpha & Omega | **SOT-23** | ✅ | ~$0.15 | LED low-side PWM switch ×3 (panel + 2× wake); logic-level, R<sub>DS(on)</sub> <48 mΩ @ V<sub>GS</sub> 2.5 V → driven direct from 3.3 V LEDC (100 Ω gate + 10 k pulldown). Complement of the AO3401A P-FET (row 17) |
| 29 | `tco_sdf_df077s.pdf` | **SDF-DF077S** (77 °C one-shot TCO) | Cantherm | **axial radial-lead** (Ø4.0 body, AWG18) | ✅ | ~$0.9 | non-resettable organic-element thermal cut-off in the cell **−** path; T<sub>f</sub> 77 °C / hold 55 °C, 10 A / 250 VAC. **Solder ≥3 mm from body, heatsink the lead** (keep body < T<sub>f</sub>−24 °C); belt-and-suspenders to the LT3652 NTC |
| 30 | `connector_usb_c_usb4160.pdf` | **USB4160-03-0230-C** USB-C (USB 3.2 Gen2, **vertical**, 24-pin, 2.30 mm stakes) — *only the USB 2.0 subset is wired; SS pads unconnected* | GCT | **SMT + 4 soldered stake slots** | ✅ [DK 5,753 pcs](https://www.digikey.com/en/products/result?keywords=USB4160-03-0230-C) | ~$1.22 | USB-C power + CC + D± (port out the back wall) |
| 31 | `led_neopixel_sk6812rgbw.pdf` | **SK6812 RGBW 5050** ×7 (Adafruit **2758** 10-pack) — 5 status + 2 dial pixels | OPSCO / Adafruit | **PLCC-4 5.0×5.0 mm** (stock KiCad footprint) | ✅ [DK 6134706](https://www.digikey.com/en/products/detail/adafruit-industries-llc/2758/6134706) | $5.95/10 | 1-wire 800 kHz daisy-chain (IO7 → RMT) |
| 32 | `buffer_sn74ahct1g125.pdf` | **SN74AHCT1G125DBVR** — NeoPixel data buffer 3V3→5 V (TTL V_IH 2 V @ VCC 5 V) | Texas Instruments | **SOT-23-5** | ✅ [DK 376028](https://www.digikey.com/en/products/detail/texas-instruments/SN74AHCT1G125DBVR/376028) | ~$0.14 | single 3-state buffer (OE̅ tied low) |
| 33 | `encoder_em14.pdf` | **EM14A0D-C24-L064S** — knob encoder: **optical**, no detent, 64 CPR, push switch, 1/4″ flatted shaft, **5 V ~30 mA**; A/B 5 V out → 100k/200k dividers | Bourns | **vertical TH, PC pins** | ✅ [DK 954403](https://www.digikey.com/en/products/detail/bourns-inc/EM14A0D-C24-L064S/954403) | $34.00 | 2-ch quadrature (PCNT) + switch (IO17 IRQ) |
| 34 | `connector_jst_zh.pdf` | **JST ZH series** (1.5 mm, 1 A): **B6B-ZR** ×2 (J7 sensor, J10 knob) + **B2B-ZR** (J11 toggle), TH top-entry; mates the pre-crimped **A06ZR06ZR28H152B** ZH↔ZH cable. 🔴 **Suffix = wiring:** `…152B` is straight through (pin 1↔pin 1, correct); `…152A` is *Reversed* (pin 1↔pin 6) and destroys the BNO085 — ring it out before use (root `README.md` §16d) | JST | **TH vertical, 1.5 mm** | ✅ [DK search](https://www.digikey.com/en/products/result?keywords=B6B-ZR) | ~$0.2–0.3 ea | off-board harnesses (sensor/knob/toggle) |
| 35 | `inductor_coilcraft_xal40xx.pdf` | **Coilcraft XAL40xx** molded power inductors — L1 `XAL4040-103` (10 µH), L2 `XAL4020-102` (1 µH), L3 `XAL4020-222` (2.2 µH), L5/L6 `XAL4040-103` (10 µH); **L4 → `XAL5030-472` (5×5 mm, Isat 6.7 A)** per root README §16c *(filed 2026-07-24)* | Coilcraft | **4×4 mm SMT** | ✅ | ~$0.9–1.2 | switcher SW-node + speaker LC magnetics |
| 36 | `fet_2n7002.pdf` | **2N7002** (60 V, 0.3 A N-ch) ×3 — Q1 `FULLCHG_EN` / Q3 `VBAT_DIV_EN` / Q8 `CELL_TEST` *(filed 2026-07-24)* | Nexperia | **SOT-23** | ✅ | ~$0.10 | logic-level switch / level-shift |
| 37 | `diode_schottky_bat46w.pdf` | **BAT46W-E3-08** (100 V Schottky, D10) — LT3652 BOOST refresh (schematic value `BAT46`; SOD-123 part is BAT46W) *(filed 2026-07-24)* | Vishay | **SOD-123** | ✅ | ~$0.30 | charger boost-diode |
| 38 | `diode_clamp_bat42w.pdf` | **BAT42W-E3-08** (30 V Schottky, D13) — VBAT-sense reversed-cell clamp *(filed 2026-07-24)* | Vishay | **SOD-123** | ✅ | ~$0.30 | ADC-node clamp |
| 39 | `esd_usb_usblc6.pdf` | **USBLC6-2SC6** (U16) — very-low-C USB D± ESD array (VBUS pin NC); DS4260 *(filed 2026-07-24)* | STMicroelectronics | **SOT-23-6L** | ✅ | ~$0.36 | USB 2.0 D± ESD |
| 40 | `protection_mosfet_ao4838.pdf` | **AO4838** (30 V dual N-FET, **replaces AOSD32334C at `U4`** — v0.4 **V9**) — **R_DS(on) ≤13 mΩ @ VGS 4.5 V** (vs 26 mΩ), 11 A, and a **pin-identical SOIC-8** (1 S2 · 2 G2 · 3 S1 · 4 G1 · 5,6 D1 · 7,8 D2), so it is a literal drop-in on the existing footprint. Halving R_DS is what keeps `I_CHG` under the HY2111's `V_CIP` and the boost's startup surge under `V_DIP` — see `power.md` and `FIRMWARE.md` §12.0.13 *(filed 2026-09-13)* | Alpha & Omega | **SO-8** | ✅ [DK 3152401](https://www.digikey.com/en/products/detail/alpha-omega-semiconductor-inc/AO4838/3152401) | ~$1.15 | protector FET pair |
| 40 | `diode_schottky_b340a.pdf` | **B340A-13-F** (40 V / 3 A Schottky, D11/D20/D30) — charger catch + 12 V-boost rectifier + amp-mux 12 V leg; DS30891 *(filed 2026-07-24)* | Diodes Inc | **SMA / DO-214AC** | ✅ | ~$0.30 | power-path Schottky ×3 |
| 41 | `inductor_coilcraft_xgl5050.pdf` | **XGL5050-472MEC** (L4, 4.7 µH, Isat 9.7 A, DCR 16 mΩ) — 12 V-boost inductor; replaced the 4×4 mm XAL4030 (Isat too low for 1S→12 V); Doc 1577-1 *(filed 2026-07-24)* | Coilcraft | **5×5 mm SMT** | ✅ | ~$1.3 | 12 V-boost SW node |
| 42 | `sensor_imu_bno085.pdf` | **BNO085** (`BNO08X` datasheet 1000-3927 v1.17) — 9-axis IMU with the **SH-2 sensor-hub firmware on-chip** (rotation vector, gravity, linear accel, tap/step/shake); **replaces the LIS3DH** (row 14) on the sensor board *(filed 2026-07-29)* | CEVA (Hillcrest Labs) | **LGA-28 5.2×3.8×1.1 mm → sensor board (PCBA)** | ✅ [DK 1888-1006-1-ND](https://www.digikey.com/en/products/detail/ceva-technologies-inc/BNO085/9445940) (329 pcs, 16 wk lead) | ~$13.6 | I²C 0x4A/0x4B (SPI/UART alt) + H_INTN |
| 43 | `switch_toggle_eswitch_100.pdf` | **`100SP1T2B1M1QEH`** — rear radio-disable toggle on **J11** (**bought 2026-08-06**). Decode: `SP1` SPDT *On-None-On* (**lug 2 = common**; no centre-off) · `T2` 5.08 mm bat · `B1` 1/4-40UNS bushing **8.89 mm** · `M1` solder lug · **`Q` silver** · `E` epoxy-sealed · `H` hardware. Used as an **SPST** to GND. ⚠️ two carried flags — **(a)** 8.89 mm bushing ⇒ **≈6 mm max panel** vs a 10–12 mm walnut wall → **counterbore the rear panel**; **(b)** silver contacts on a **~33 µA dry circuit** (MCP internal PU only) — E-Switch publishes a low-level rating (0.4 VA @ 20 V) **only for the `R` gold option**, which is non-stocked/12-wk. Root README §16d | E-Switch | **panel mount, Ø6.35 mm hole; 12.70 × 6.86 × 8.89 mm** | ✅ [DK EG2359-ND](https://www.digikey.com/en/products/detail/e-switch/100SP1T2B1M1QEH/378828) (883 pcs) | $4.27 | expander GPA3 `RADIO_OFF` (int. PU + IOC) |
| 44 | `sensor_env_bme68x_hsmi.pdf` | **BME68x Handling, Soldering and Mounting Instructions** (`BST-BME680-HS000-06` rev 1.6) — the document `sensor_env_bme688.pdf` §7.7 defers to for *every* assembly rule. **Bosch publishes no BME688-specific HSMI** (verified 2026-08-07), so the BME680 one is filed as nearest-applicable: identical LGA-8 3×3 package, Ø0.35 mm lid vent, MOX hotplate. MSL 1 · 260 °C peak, 20–40 s · ≤3 reflows · **≥50 µm solder height** · vent covered for any wash · **no siloxanes** *(filed 2026-08-07)* | Bosch Sensortec | — (document) | ✅ | — | goes in the **fab package** with the sensor board |
| 45 | `sensor_env_bme68x_packaging.pdf` | **BME68x Shipment & Packaging Details** (`BST-BME68x-SP000`) — tape/reel, dry-pack and moisture-barrier handling for the BME68x family (explicitly covers the BME688) *(filed 2026-08-07)* | Bosch Sensortec | — (document) | ✅ | — | incoming-goods + storage |

**Every env/MEMS sensor is leadless (LGA/DFN) — no hand-solderable silicon exists**, so none sit bare on the **main** board. Both build paths carry the same set — **BME688 + TSL2591 + BNO085** *(the BNO085 replaced the LIS3DH 2026-07-29)* — so the firmware is the same either way (see §15):
- **2a — bring-up: STEMMA QT / Qwiic daisy-chain** of ready Adafruit boards on one 4-wire I²C chain — **BME688 (Adafruit 5046, ~$19) · TSL2591 (1980, $6.95) · BNO085 (4754, ~$25)**. Zero leadless soldering, fastest bring-up.
- **2b — drawn 2026-07-29: one custom sensor daughterboard** carrying the three bare chips — schematic in [`../kicad-sensor/`](../kicad-sensor/), fab-assembled (PCBA), plugging into main-board **J7** on the 6-way JST ZH harness. Same part numbers → same I²C addresses → 2a firmware runs unchanged. **This board is exempt from the hand-solder rule** (that rule scopes the main PCB, which is iron-assembled); it is ordered assembled.

The **display connector (row 11) is the exception** among leadless-class parts: a 0.5 mm FPC/ZIF is explicitly hand-solderable, so it sits **on the main PCB**. **No RTC IC** — timekeeping is the **ESP32-S3 internal RTC off a 32.768 kHz crystal** (XTAL32K, GPIO15/16) + SNTP; no coin cell (see root README §6/§8/§10).

**Fuel gauge dropped** (no hand-solderable equivalent — every 1-cell gauge is TDFN/WLP): SoC is now **voltage-based via the ESP32-S3 ADC** on a divider off the cell. See root README §10 / `../power.md`.

**Removed datasheets (leadless, replaced above):** `amp_tas5825m.pdf` (VQFN-32), `motor_driver_drv8835.pdf` (WSON-12), `pd_sink_stusb4500.pdf` (QFN-24), `charger_bq25628e.pdf` (WQFN-18), `fuel_gauge_max17048.pdf` (µDFN/WLP), `battery_protector_lc05111cmt.pdf` (WDFN-6). **v0.15 sensor consolidation:** `sensor_temp_tmp117.pdf` (TMP117 — dropped, redundant), `sensor_humidity_temp_sht4x.pdf` (SHT45 — folded into BME688), `sensor_accel_bma400.pdf` (BMA400 — replaced by LIS3DH). **2026-07-12 protector re-pick (availability, not leadless):** `battery_protector_s-8261.pdf` (S-8261 → reel-only, 3000 MOQ) + `protection_mosfet_ao4800.pdf` (AO4800 → reel-only) → replaced by AP9101C + AOSD32334C (both DigiKey cut-tape/singles). **2026-07-17 protector re-pick #2 (lifecycle):** `battery_protector_ap9101c.pdf` (AP9101C/AP9101CA family → NRND/obsolete at Diodes) → replaced by `battery_protector_hy2111.pdf` (HY2111-GB, LCSC).

**2026-07-24 additions (rows 35–40):** switcher/protection discretes + inductors that were on the board but undocumented — filed with the 12 V-boost inductor now specced as **XGL5050-472MEC** (`XAL5030-472` was out of stock; see root README §16c). All ⭐ parts now have a datasheet on file.

---

## System IO & power domains

The pin/rail picture is getting busy, so track it here. The **ESP32-S3 (3.3 V logic)** is the host; everything else hangs off it. Rails (see [`../power.md`](../power.md) for the full tree + battery safety): **3.3 V** (logic, from the 5 V rail) · **5 V** (stepper VM + **7× SK6812 NeoPixels** + **EM14 knob encoder** + amp-PVDD mux aux) · **12 V boost** (amp PVDD **+ wake LED strips**, **plugged-only**) · **15 V VBUS** (LT3652 charger VIN, plugged). Source: **USB-PD 15 V** (CH224K) → LT3652 buck charger, 1S Li-ion 18650; the charger **BAT node is the always-on system supply**.

| Part | Power rail(s) (abs-max) | Logic level | ESP32-S3 signals (GPIO count) |
|---|---|---|---|
| **ESP32-S3-WROOM-1** (host) | 3.0–3.6 V (max 3.6) | 3.3 V | — drives everything below; **~33 usable GPIO** on **N8R8** (octal PSRAM claims GPIO35/36/37) |
| ~~**LS032B7DD02** display~~ *(not in current build — dropped v0.19)* | Panel VDD/VDDA **5 V** (4.8–5.5; abs 5.8) | **3 V** inputs | *(was: SPI ×3 + DISP on expander; SPI2 is now microSD-only, IO17 freed → `ENC_SW`)* |
| **SK6812 RGBW ×7** status + dial NeoPixels (row 31) | **5 V** (3.7–5.5) | data V_IH 0.7·VDD = 3.5 V → **SN74AHCT1G125** buffer (row 32) | **1** data GPIO (IO7 → RMT), whole chain |
| **EM14A0D-C24-L064S** knob encoder (row 33) | **5 V** ~30 mA | 5 V outputs → **100k/200k dividers** | A/B → **2** (IO47/48 PCNT) + SW → **1** (IO17 IRQ) |
| **TAS5760M** amp | **THREE supply pins, two rails.** PVDD (21, 28) **12 V plugged / 5 V on battery** via the LTC4412 mux · **AVDD (1) ties to PVDD — range 4.5–26.4 V, NOT a 3.3 V pin** · DVDD (10) **3.3 V** (2.8–3.63) | 3.3 V (DVDD-ref) | I²S MCLK · BCLK · LRCLK · SDIN + SPK_SD (mute/PDN) + SPK_FAULT + I²C(shared) → **5 host GPIO + 2 expander + shared I²C** |
| **DMA58-4** speaker | — (passive, from amp OUT) | — | none (analog off TAS5760M PBTL output) |
| **TB6612FNG × 2** driver | VM **5 V** (0–13.5, abs 15) + VCC **3.3 V** (2.7–5.5) | 3.3 V | AIN1·AIN2·BIN1·BIN2 (PWM'd) + STBY → **4 / chip = 8** + shared STBY |
| **X40.879** stepper | coils fed from TB6612FNG VM **5 V** | — | none direct (via TB6612FNG); 2 shafts × 2 coils |
| **CH224K** PD sink | VBUS **4–22 V**; VDD off VBUS | 3.3 V (PG open-drain) | CFG (resistors, no GPIO) + PG **(OD → MCP23017, not host)** → **0 MCU** |
| **LT3652** charger | VIN (VBUS) **≤32 V**; BAT (system node) | 3.3 V (open-drain status) | CHRG + FAULT status **(OD → MCP23017, not host)** → **0 MCU**; NTC/timer/float = passives |
| **Cell voltage sense** | off cell via divider | ADC | 1 ADC pin → **1** |
| **HY2111 + AOSD32334C** protector | across cell (≤10 V) | — | none (autonomous OV/OD/OC/SC) |
| **QRE1113** hand homing | IR LED + phototransistor off **3.3 V** (R-limited) | 3.3 V (ADC) | reflective opto behind a punched dial hole → **1 ADC/comparator**; no magnets |
| **MCP23017** IO expander | 1.8–5.5 V (**3.3 V**) | 3.3 V (I²C + INT) | on the **shared I²C** (no new bus pins) + **INT → 1 GPIO**; fans out 16 slow I/O → offloads SPK_SD, 12 V EN, stepper STBY, **radio-off toggle**, **PD PG, charger CHRG/FAULT**, FULLCHG_EN, VBAT_DIV_EN, SPK_FAULT (**net −9 MCU GPIO**) |

**Shared bus:** the **I²C bus** (SDA/SCL, 2 GPIO) is shared by the amp + all sensors (**BME688** T/RH/press/VOC, **TSL2591** light, **BNO085** IMU/tap (row 42; supersedes the LIS3DH, rows 12–15b)) **and the MCP23017 IO expander (row 26)** — **kept small** otherwise (no charger, no fuel gauge, **no RTC** on I²C). Timekeeping = S3 RTC + a **32.768 kHz crystal** on XTAL32K (GPIO15/16, dedicated — not on I²C). Homing uses **1× QRE1113** reflective optical (§16; 4-lead, 3.3 V, analog out → **1 ADC GPIO**, no magnets).

**GPIO tally (v0.19, post-expander):** I²S 4 (incl. MCLK) + shared-I²C 2 + SD SPI 4 + steppers 8 + optical home 1 + Vbat ADC 1 + NeoPixel data 1 + wake PWM 2 + knob A/B 2 + knob SW 1 + sensor INT 1 + expander INT 1 + USB D± 2 = **30 signals** + the 2 dedicated XTAL32K pins = **32/33 pads** (IO0/boot is the only spare — see [`../esp32.md`](../esp32.md)). **PD PG and charger CHRG/FAULT ride the MCP23017** (interrupt-on-change → the single expander INT), not the host — they are slow open-drain status only, and the *hardware* OV/OC/SC safety is autonomous (LT3652 + HY2111), so nothing time-critical depends on those pins.

> ⚠️ **N8R8 budget is tighter than the old "≤36".** The **octal PSRAM claims GPIO35/36/37** (verified in the S3-WROOM-1 datasheet pin table — "not available for other use"), so the module frees only **~33 usable pads**. The v0.19 design sits at **32/33**; the remaining levers are pushing `ENC_SW` onto the expander (costs press latency) or a **quad-PSRAM module (…R2)**, which keeps GPIO35–37 free (trade 8 MB→2 MB PSRAM).

**Peripheral/PWM count is fine (verified vs. the S3 datasheet):** the 8 stepper AIN/BIN go on **MCPWM** (2 units × 3 operators = **12 PWM outputs**; 8 used) — *not* LEDC — leaving **8 LEDC** channels for LED dimming (**2 used** — wake warm/cool). The SK6812 chain rides **RMT** (1 of 4 TX). Knob A/B → **PCNT** (4 units, hardware quadrature, zero CPU). Audio → **I²S0** (of 2). microSD → **SPI2** (sole device since v0.19). Both analog inputs (Vbat, homing) **must land on ADC1 = GPIO1–10** — **ADC2 is unusable while Wi-Fi is active**. **The steppers stay 8 pins** — TB6612FNG driven PWM-on-the-inputs (PWMA/PWMB tied high); the conventional PWM-pin scheme would cost 12.

---

## 1. Sharp LS032B7DD02 — Reflective Memory LCD *(⚠ not in current build — display dropped v0.19, spec retained)*

- **Product:** 3.16″ transflective monochrome Memory-in-Pixel (MIP) LCD module, 336 × 536.
- **Refs:** Part # `LS032B7DD02` · Mfr **Sharp** · DigiKey # 23349498 · spec `LD-2023X13` (full device spec, dated **01-Nov-2023**).
- **Price / link:** ~**$38.14** — [DigiKey 23349498](https://www.digikey.com/en/products/detail/sharp-microelectronics/LS032B7DD02/23349498) (active, in stock).
- **Dimensions (W × L × D):** **47.02 × 76.00 × 0.705 mm** (outline). Active area 42.672 × 68.072 mm; top polarizer 46.02 × 73.2 mm; dot pitch 0.127 mm; mass 5.5 g max.
- **Power / IO:**
  - **Voltage:** VDD/VDDA recommended **4.8 / 5.0 / 5.5 V** (min/typ/max); absolute max −0.3…+5.8 V. Logic inputs (SCLK/SI/SCS/DISP/EXTCOMIN) high = **2.7 / 3.0 / VDD V** → **3.3 V-MCU compatible**.
  - **Power consumption:** HOLD (no update) **30 µW typ** (330 µW max); data update @ 1 Hz **250 µW typ** (750 µW max) — i.e. ≈6 µA hold / ≈50 µA update at 5 V. (Peak COM current is higher; size the rail with margin.)
  - **IO:** 3-wire SPI (SCLK, SI, SCS) + DISP (on/off) + EXTCOMIN (VCOM toggle) + EXTMODE (VCOM-source select). **Our design uses software VCOM: EXTMODE tied LOW, VCOM inverted via the SPI frame-inversion bit → EXTCOMIN unused** (tie EXTMODE=VDD only for hardware EXTCOMIN). Host GPIO = SCLK/SI/SCS (3), DISP on the MCP23017. See `../esp32.md`.
- **Hand-assembly:** module with an **FPC tail** → mate with a **hand-solderable fine-pitch FPC/ZIF connector** (or an FPC-to-header breakout). No bare leadless silicon.
- **Interface:** **3-wire SPI** + DISP/EXTCOMIN/EXTMODE control.
- **Released:** device spec © 2023 (rev `LD-2023X13`, 01-Nov-2023).

## 2. Espressif ESP32-S3-WROOM-1-N8R8 — Wi-Fi + BLE MCU module *(host)*

- **Product:** ESP32-S3 SoC module, dual-core Xtensa LX7 @ up to 240 MHz, **8 MB flash / 8 MB PSRAM** (`N8R8`), on-board PCB antenna.
- **Refs:** Part # `ESP32-S3-WROOM-1-N8R8` · Mfr **Espressif** · DigiKey # 15295891.
- **Price / link:** ~**$6.32** — [DigiKey 15295891](https://www.digikey.com/en/products/detail/espressif-systems/ESP32-S3-WROOM-1-N8R8/15295891) (active, 1,709 in stock 2026-08-06).
- **Variant note:** the WROOM-1 pad map (Table 3-1) is **identical across every N*/R* SKU** — same 41 pads, same 18.0×25.5×3.1 mm body, same `RF_Module:ESP32-S3-WROOM-1` land. `R8` = 8 MB **Octal** PSRAM, so IO35/36/37 stay reserved exactly as on the ex-N16R8 (datasheet note *b*: "connected to the Octal SPI PSRAM and are not available for other use"), and the R8 ambient range is **−40 ~ 65 °C** (85 °C with PSRAM ECC on, −1/16 usable PSRAM). Only the flash die changes: **16 MB → 8 MB (Quad SPI)**.
- **Dimensions (W × L × D):** **18.0 × 25.5 × 3.1 mm** (±0.2 / ±0.2 / ±0.15).
- **Power / IO:**
  - **Voltage:** 3.0–3.6 V (typ 3.3 V). Absolute max 3.6 V, min −0.3 V. External supply ≥ 0.5 A.
  - **Current:** Wi-Fi TX peak up to **355 mA**; BLE TX peak up to **344 mA**; RX ~95 mA. Modem-sleep ~13–108 mA. Light-sleep **240 µA**; deep-sleep 7–170 µA; power-off **1 µA**.
  - **IO:** up to **36 GPIO**, muxable to UART/SPI/I²C/I²S/SDIO/PWM/ADC. GPIO source 40 mA / sink 28 mA.
- **Hand-assembly:** **module with castellated edge pads** → drag-solder with an iron. The bottom center GND/thermal pad benefits from a via array (heat from the back / hot-air optional) but the castellations carry all signal + power. This is a *module*, not a bare QFN — acceptable.
- **Interface:** **Wireless** Wi-Fi + BLE 5; **wired** UART/SPI/I²C/I²S/SDIO via GPIO mux.
- **Released:** module ~2021 (SoC launched Dec 2020); datasheet v1.8.

## 3. Dayton Audio DMA58-4 — 2″ Full-Range Driver *(chosen speaker)*

- **Product:** 2″ dual-neodymium-magnet, aluminum-cone full-range driver, 4 Ω, open 8-spoke frame.
- **Refs:** Part # `DMA58-4` · Mfr **Dayton Audio** · Parts Express # 295-582 · Amazon ASIN B07L9JKSGV. **Not on DigiKey.**
- **Price / link:** ~**$18.99** — [Parts Express 295-582](https://www.parts-express.com/Dayton-Audio-DMA58-4-2-Dual-Magnet-Aluminum-Cone-Full-Range-Driver-4-Ohm-295-582) · also [Amazon](https://www.amazon.com/dp/B07L9JKSGV).
- **Dimensions (W × L × D):** **55.9 × 55.9 × 31.75 mm** (2.20″ square × 1.25″ deep). Cutout Ø 49.8 mm (1.96″); bolt circle Ø 64.3 mm (2.53″).
- **Power / IO:** Passive driver — **no supply, no logic.** 4 Ω nominal (Re 3.6 Ω), **15 W RMS** → ≈7.7 V RMS / ≈1.94 A RMS at full power. Fs 165.5 Hz, SPL 86.2 dB @ 2.83 V/1 m, Xmax 2.0 mm, VC Ø 25 mm, Vas 0.149 L, range 160–20,000 Hz. **Connects to the TAS5760M PBTL output** via **wire + JST**, not the MCU.
- **Description:** High-performance 2″ full-range driver for a small sealed box; matching **DMA58-PR** passive radiator available. Needs baffle + ~100–250 cc sealed enclosure.
- **Interface:** None (analog audio).
- **Released:** ~2019 (reviewed *Voice Coil*, Dec 2019).

## 4. Juken / Switec X40.879 — Dual-Shaft Clock Stepper *(chosen movement)*

> Two datasheets: `stepper_motor_x40-879.pdf` (**X40 pinout note**, `SP-X40-e-A-Pinout`) covers *only* pinout + drive sequence; torque, current, coil resistance, dimensions, temperature all come from `stepper_motor_x27_base-spec.pdf` (**X27 series spec**, `SP-X27-e-C`) — the X40's two shafts use **X27-compatible mechanics**.

- **Product:** X40.879 — a **dual coaxial-shaft** stepper (independent hour + minute shafts) built from two X27-class movements; drives directly from an MCU (here, via 2× TB6612FNG).
- **Refs:** **Buy `X40.879.NS`** (a.k.a. `X40.879B`, **no internal stop**) — ⚠ `X40.879` itself (DigiKey # 28528329) has the X27's **315° stop**; build #1 was fitted with it and stalls at the stop (2026-09-27, `kicad/REVIEW.md` V18). Mfr **Juken Swiss Technology / Switec**. Base spec = `X27` series (e.g. X27.168, DigiKey # 26832207).
- **Price / link:** `.NS` ~€25 — [MiniTools](https://store.minitools.com/en/sei-x40-879-ns-juken-x40-879-ns-stepper-motor.html), [inovauto](https://inovauto.com/mot-320.html); **not on DigiKey**, no `.NS` datasheet on file (same X40 package per sellers — verify pinout/pitch against the footprint). Plain X40.879 ~$14 — [DigiKey 28528329](https://www.digikey.com/en/products/detail/juken-swiss-technology/X40-879/28528329) (has the stop — **do not buy for this clock**).
- **Dimensions:** per-movement **Ø 30 × 9 mm** (X27 base). X40 overall isn't in the pinout note — it stacks two coaxial shafts → taller vertical profile.
- **Power / IO** (from X27 base spec):
  - **Voltage:** operating **5–9 V DC**; absolute-max driving voltage 10 V. Driven at **5 V** via TB6612FNG VM for full torque.
  - **Current:** coil R 230/260/290 Ω → **≈19 mA/coil at 5 V**; **two coils per shaft**, bipolar. **8 coil terminals** total (external-shaft 1–4, internal-shaft 5–8) → four H-bridges = two TB6612FNG.
  - Holding torque 3.5–4.0 mN·m; dynamic 1.0–1.45 mN·m @ 200°/s; noise ~40 dB(A); temp −40…+105 °C.
- **Description:** 1/3° per partial step (60°/step rotor), up to 600°/s, 1/180 gear → 2° per electrical period → **11 520 µsteps/rev** at ×64/period (firmware `kUstepsPerRev`). Base X27 has a 315° internal stop — for a clock, buy/reuse the **360°/no-stop** variant + external **optical** homing (QRE1113, §16).
- **Interface:** Not a data bus — **two 2-phase bipolar coil sets** driven from the ESP32 via **2× TB6612FNG** (below), PWM microstep. Connects via **wire + JST**.
- **Released:** X40 pinout rev A (`FO-220-01-B`); X27 base is a long-standing automotive gauge motor.

## 5. Texas Instruments TAS5760M — I²S Digital-Input Class-D Amp *(chosen amp)*

- **Product:** Digital-input **closed-loop Class-D** amp with I²S input and I²C control. Stereo, or **PBTL mono** for the single 4 Ω DMA58-4. Integrated **digital clipper**, selectable gain, DC-detect / over-current / over-temperature (thermal foldback) protection. **ACTIVE — recommended for new designs.**
- **Refs:** Part # `TAS5760M` (orderable **`TAS5760MDAPR`**, HTSSOP-32) · Mfr **Texas Instruments** · datasheet `SLOS736`. [TI product page](https://www.ti.com/product/TAS5760M).
- **Price / link:** ~**$4–6** — DigiKey keyword `TAS5760MDAPR` (verify active/stock).
- **Package:** **HTSSOP-32 (DAP, PowerPAD)** — 32 gullwing leads (iron-solderable) + a thermal belly pad → copper pour + thermal-via array. *(A 48-pin HTSSOP `DCA` also exists; the 32-pin DAP is the compact hand-solderable choice.)*
- **Power / IO:**
  - **Voltage:** **PVDD 4.5–26.4 V** power stage (run at **~12 V** boost for ~8–12 W to the alarm, or 5 V for ~3 W) + **DVDD 3.3 V** logic/IO.
  - **Current:** low quiescent; scales with output.
  - **IO (DVDD/3.3 V-referenced):** **I²S** = SDIN, SCLK(BCLK), LRCLK (no MCLK needed); **I²C** = SDA, SCL (+ address strap) — shared bus; **SPK_SD** (mute / shutdown). → **~4 dedicated GPIO + shared I²C**.
- **Output power / quality:** up to **55 W stereo / 114 W mono PBTL** (rail-dependent) — for our 12 V PVBTL into 4 Ω that's ~8–12 W with plenty of headroom. Needs an **LC output filter** to the speaker (recommended for EMC).
- **Why it's chosen (vs the QFN TAS5825M it replaces):** it keeps the **I²S digital path + I²C control + output protection** in a **leaded, hand-solderable HTSSOP**. It does **not** carry the TAS5825M's full biquad DSP (EQ/DRC), so the **~150 Hz high-pass + limiter/EQ that protects the 2 mm-Xmax driver runs in ESP32-S3 firmware** (a few biquads at 44.1/48 kHz before I²S) — cheap on the S3.
- **Interface:** **I²S** (audio in) + **I²C** (control).
- **Alt (fully analog, hand-solderable):** **PCM5102A** I²S DAC (TSSOP-20) → **TPA3116D2** analog Class-D (HTSSOP-32); all DSP in firmware.

## 6. Toshiba TB6612FNG — Dual H-Bridge Motor Driver *(× 2, chosen stepper driver)*

- **Product:** Dual H-bridge with **low-Rds MOSFET outputs**. **One TB6612FNG per shaft** (2 H-bridges = the shaft's 2 coils); **two chips** for the X40.879.
- **Refs:** Part # `TB6612FNG` (orderable **`TB6612FNG,C,8,EL`**) · Mfr **Toshiba** · datasheet (rev 20141001). DigiKey # 1730070.
- **Price / link:** ~**$2.40/1** — [DigiKey 1730070](https://www.digikey.com/en/products/detail/toshiba-semiconductor-and-storage/TB6612FNG-C-8-EL/1730070) (active, ships today).
- **Package:** **SSOP-24 (5.3 × 8.2 mm, 0.65 mm pitch, NO exposed pad)** — pure gullwing, the **easiest** part on the board to hand-solder (iron only, no belly pad). This is *why* it wins over the WSON DRV8835 and HTSSOP DRV8833.
- **Power / IO:**
  - **Voltage:** **VM 0–13.5 V** motor supply (run at **5 V** for full stepper torque) + **VCC 2.7–5.5 V** logic (**3.3 V** from the MCU). Internal thermal shutdown + flyback diodes.
  - **Current:** **1.2 A/ch continuous (3.2 A peak)** — vs the ~19 mA the coils need → huge margin, runs cold.
  - **IO (per chip, 3.3 V logic):** channel A = `AIN1`,`AIN2`,`PWMA`; channel B = `BIN1`,`BIN2`,`PWMB`; plus `STBY`. **Pin-efficient microstep scheme:** tie `PWMA`/`PWMB` **high** and **PWM the four IN pins** for sign-magnitude microstep → **4 GPIO/chip = 8 total** + one shared `STBY` (parity with the DRV8835 it replaces). *(The textbook scheme — PWM on `PWMx`, direction on the IN pins — is 6/chip = 12 GPIO; avoid it here to protect the pin budget.)* Outputs AO1/AO2, BO1/BO2 to the coils. Decouple VM & VCC (0.1 µF min + bulk).
- **Description:** Integrated flyback (protects the MCU), low-drop MOSFET outputs → full 5 V coil drive, thermal shutdown. No internal current chopper → microstepping is PWM/voltage-based (ideal for these high-impedance gauge coils). **Do not** use A4988/DRV8825/DRV8434/TMC-class choppers — they can't regulate ~19 mA into 260 Ω.
- **Interface:** GPIO + PWM (IN/IN sign-magnitude). Homing via **1× QRE1113 reflective optical** (§16, separate — no hand magnets).
- **Released:** long-standing, active (Toshiba Bi-CD).

## 7. WCH CH224K — USB-PD Sink Controller *(resistor-configured)*

- **Product:** autonomous USB Type-C / PD **sink** controller — negotiates a PD contract **with no MCU**; the requested voltage is set by a **single resistor** (CFG), no NVM programming.
- **Refs:** `CH224K` · **WCH / Nanjing Qinheng** · **ESSOP-10** (SOP-10, leaded, exposed-pad-free enough to iron). LCSC # C970725. *(Not on DigiKey — sourced from LCSC/Mouser; the exception to the DigiKey-first rule, since every DigiKey PD sink is QFN.)*
- **Price:** ~$0.40 (active; drop-in successor `CH224A` if EOL).
- **Power / IO:** **VBUS 4–22 V**; VDD off VBUS. Standalone: a resistor on **CFG1** selects the requested PDO (**5 / 9 / 12 / 15 / 20 V**); built-in **OVP + OTP**; **PG** (power-good, open-drain) → 1 GPIO. Supports PD3.0/2.0 + BC1.2.
- **Use:** set **CFG for 15 V** (headroom for LT3652 VIN + the audio/rail boosts); auto-requests 15 V, **falls back to 5 V** if the source can't supply it (system still runs on the cell). VBUS → LT3652 VIN only (LEDs run off the 12 V boost, not VBUS). Read PG to know a high-voltage contract is live.
- **Interface:** USB-PD (CC) + resistor config + PG.

## 8. Analog Devices LT3652 — 1-Cell Buck Battery Charger *(chosen charger)*

- **Product:** monolithic **step-down (buck) battery charger**, 4.95–32 V input, **up to 2 A** charge, constant-current/constant-voltage. Fully **autonomous** (resistor/capacitor-programmed — no I²C).
- **Refs:** `LT3652` (orderable **`LT3652EMSE#PBF`**) · **Analog Devices** · **MSOP-12E** (12-lead MSOP, PowerPAD) *(3×3 DFN-12 also exists — use the MSOP)*. DigiKey # 2225686. Datasheet `3652fe`.
- **Price:** ~$9.9 (active).
- **Power / IO:**
  - **VIN:** **4.95–32 V** operating (abs-max 40 V) → the **15 V VBUS** from CH224K is well inside range.
  - **Float voltage:** set by an **external divider to the 3.3 V feedback reference** → programmed to **4.05 V** (health cap). Optional **4.2 V "full" mode** by switching a parallel FB resistor with a small FET/GPIO.
  - **Charge current:** set by a sense resistor (V_SENSE(chg) 100 mV / R_SENSE), here ~1–1.75 A.
  - **Temperature:** **NTC pin** — connects the holder's 10 k NTC; **charging pauses hot/cold** (temperature-qualified, meets "no charge <0/>45 °C"). *(Single hot/cold window, not multi-zone JEITA — documented downgrade from the BQ25628E it replaces.)*
  - **Safety timer:** programmable via the **CTIMER** cap; C/10 termination; auto-recharge; **CHRG + FAULT** open-drain status → 2 GPIO.
- **System role (power-path):** the **BAT node is the always-on system supply** for the rail converters. When plugged, the LT3652 regulates BAT to 4.05 V and sources load **up to 2 A → runs with no cell**; when unplugged, the cell supplies the rails through the protector FETs. No separate NVDC power-path IC needed.
- **Health cap & telemetry:** the 4.05 V cap is enforced **in hardware by the float divider** (no firmware needed — simpler and safer); SoC/faults read via **ADC + CHRG/FAULT** instead of I²C.
- **Interface:** none (autonomous); status pins + NTC.

## 9. HYCON HY2111-HB + 10. Alpha & Omega AOSD32334C — 1-Cell Protector *(independent safety)*

- **Product:** discrete 1-cell Li-ion **protection IC (HY2111)** + **external dual N-channel MOSFET (AOSD32334C)** — the independent OV/OD/OCD/OCC/SCP cutoff, redundant to the LT3652. Two **leaded, hand-solderable** parts (the ubiquitous "protector-IC + 8205-style dual-FET" topology). Replaces the **AP9101CK6-BX** (whole AP9101/AP9101CA family went **NRND/obsolete** at Diodes — re-picked 2026-07-17); before that the S-8261 + AO4800 (reel-only).
- **Refs:**
  - Protector: **`HY2111-HB`** (**-HB suffix → overcharge 4.28 V, release 4.08 V / over-discharge 2.90 V, release 3.00 V / discharge-OC **200 mV**, factory-fixed; 0 V-charge allowed; power-down function**) · **HYCON Technology** (Taiwan) · **SOT-23-6** · [LCSC C82747](https://www.lcsc.com/product-detail/Battery-Management-ICs_HYCON-Tech-HY2111-GB_C82747.html) (~4 k stock, MOQ 5) — **off-DigiKey like the CH224K**: the exact-threshold quality twins (**ABLIC S-8261ABMMD** = 4.280/2.800 V, **Nisshinbo R5478N**) are **reel-only/3000-MOQ, zero DigiKey stock**, and the DigiKey-Marketplace **EVVO DW01** clone was rejected for the safety layer. **Pin arrangement identical to the AP9101C** (1 OD · 2 CS · 3 OC · 4 NC · 5 VDD · 6 VSS) → schematic nets unchanged.
  - FET **(v0.4 V9 → `AO4838`)**: **`AO4838`** — dual N-channel, **30 V, ±20 V VGS, 11 A, SO-8, R_DS(on) ≤13 mΩ @ VGS 4.5 V**, pin-identical to the part below so the footprint and netlist are unchanged · [DigiKey 3152401](https://www.digikey.com/en/products/detail/alpha-omega-semiconductor-inc/AO4838/3152401) ~$1.15. **Halving R_DS is what keeps `I_CHG` under `V_CIP` and the boost's 3.7 A startup under `V_DIP`** — the AOSD32334C failed both on the bench 2026-09-13 (`power.md`, `FIRMWARE.md` §12.0.13). ⚠ **Requires the `-HB` suffix above; with a `-GB` the startup margin is 3 mV.**
  - FET *(as built, superseded)*: **`AOSD32334C`** — **dual N-channel, 30 V, ±20 V VGS, 7 A, SO-8**, Rds(on) <20 mΩ@10 V / <26 mΩ@4.5 V · **Alpha & Omega Semiconductor** · [DigiKey 11567511](https://www.digikey.com/en/products/detail/alpha-omega-semiconductor-inc/AOSD32334C/11567511) (cut-tape from 1 pc). Pin-function-identical to the AO4800 it replaces.
- **Price:** ~$0.09 (HY2111-HB, LCSC qty 5 — LCSC C82747 is the **-GB**; order the -HB suffix explicitly and check the marking) + ~$0.28 (AOSD32334C).
- **⚠ Suffix matters (2026-08-08).** Datasheet p.190–201 lists the family by suffix: **-GB and -HB are identical on every threshold** (OV 4.28 / release 4.08 / OD 2.90 / release 3.00) **except discharge-OC `V_DIP`: 150 ±25 mV (-GB) vs 200 ±25 mV (-HB)**. Across the AOSD32334C pair (50–66 mΩ) that is a worst-case trip of **1.89 A** vs **2.65 A** — and a loud alarm while plugged pulls ~2.3 A out of the cell, because the LT3652 can only contribute ~1 A (`R18`). **-GB trips, -HB does not.** See `kicad/REVIEW.md` #6.
- **Power / IO:** the protector monitors cell voltage/current and drives the two series FETs (charge + discharge) via its **OC/OD** pins in the cell **−** path. **HY2111 (-HB):** overcharge **4.28 V**, over-discharge **2.90 V**, discharge-overcurrent **200 mV** + load-short (0.85 V) + charge-overcurrent (−100 mV) detection, all delays internal — **autonomous, no config**. VDD abs-max 10 V, CS/OC to VDD−20 V (cell node never sees VBUS — fine). **AOSD32334C:** VDS 30 V, VGS ±20 V, low Rds(on), continuous current (7 A) far above our <2 A.
- **Use:** wire the AOSD32334C dual FET in the cell **−** path between the 18650 and PACK−, gates from the HY2111 **OC/OD**; support network per datasheet §10 = **R1 100 Ω** (cell+→VDD) + **C1 0.1 µF** (VDD–VSS) + **R2 2 kΩ** (CS→PACK−). Belt-and-suspenders cutoff if the LT3652 fails. Overcharge is thus **double-redundant** (LT3652 CV 4.05 V + HY2111 4.28 V).
- **Interface:** none (autonomous).

---

## 11. Hirose FH34SRJ-10S-0.5SH — Display FPC/ZIF Connector *(mates the LS032B7DD02 tail; ⚠ not in current build — v0.19)*

- **Product:** 10-position, **0.5 mm-pitch** FPC/FFC **ZIF** connector, **dual (upper + lower) contact**, SMT right-angle, back-flip actuator, 1.0 mm profile, accepts 0.3 mm FPC, 0.5 A/contact.
- **Refs:** `FH34SRJ-10S-0.5SH(50)` · **Hirose** · **DigiKey # 3880272**. The LS032B7DD02 device spec **Table 8-2-1 lists it as a recommended mating connector** (alternatives it names: HRS **FH28-10S-0.5SH** bottom-contact, **Molex 503480-1000**, **Panasonic AYF531035**).
- **Why this one:** the panel tail is a **10-pin, 0.5 mm-pitch FPC** — pinout (datasheet Table 4-1 / 8-1-1): `1 SCLK · 2 SI · 3 SCS · 4 EXTCOMIN · 5 DISP · 6 VDDA · 7 VDD · 8 EXTMODE · 9 VSS · 10 VSSA`. Dual-contact + reinforced actuator = best retention for a moving/rotating body.
- **Hand-assembly:** a **0.5 mm ZIF FPC connector is explicitly allowed** by the mfg rule (fine-pitch FPC/ZIF) → mounts **on the main PCB** (not a breakout). Slide the FPC in, flip the latch.
- **Power / IO:** passive; carries the display's 3-wire SPI + DISP/EXTCOMIN/EXTMODE. Panel VDD/VDDA **5 V**, logic **3 V** (§1).
- **Price:** ~$0.7.

## 12. Bosch BME688 — Environmental Combo *(chosen env part — one chip = T + RH + pressure + VOC/gas)*

- **Product:** 4-in-1 environmental sensor — **temperature + humidity + barometric pressure + VOC/gas resistance** with the **BSEC** library computing an IAQ/air-quality index. One chip does the whole climate + air-quality job → **one sensor on the bus, one board on the chain**.
- **Refs:** `BME688` · **Bosch Sensortec** · **LGA-8 (3×3 mm)** · datasheet `BST-BME688-DS000` (`sensor_env_bme688.pdf`) · handling `BST-BME680-HS000-06` (`sensor_env_bme68x_hsmi.pdf`) · packaging `BST-BME68x-SP000` (`sensor_env_bme68x_packaging.pdf`) — rows 44/45.
- **⚠ Handling is a fab-package item, not a layout one.** §7.7 of the datasheet defers *all* soldering/mounting rules to a separate **HSMI** document, and Bosch publishes **no BME688-specific HSMI** (checked 2026-08-07: the BME680 and BME690 HSMIs are on the public path, `bst-bme688-hs000.pdf` 404s, and the BME688 product page lists flyer/datasheet/app-note/packaging only). The **BME680 HSMI is filed as the nearest applicable document** — same LGA-8 3×3 package, same metal lid with a Ø0.35 mm vent, same MOX hotplate. What it mandates, and what the assembly house must be told: **MSL 1** (no bake), **peak reflow 260 °C for 20–40 s**, **≤ 3 reflow cycles**, **≥ 50 µm of solder height after reflow** (a stencil decision — it is what mechanically decouples the die from the board), **cover the vent with a silicone-free protective layer for any cleaning / board wash**, **no siloxane-emitting coatings, adhesives or gloves anywhere near it**, no ultrasonic welding, nothing sharp in the vent, no underfill or rear-side handling. A hotplate that has been washed, fluxed over or exposed to silicone does not fail — it reads a wrong VOC baseline for ever.
- **Power / IO:** 1.71–3.6 V; I²C (addr 0x76/0x77) **or** SPI; ~3.7 µA @ 1 Hz T/RH/P, gas heater is the power draw (duty-cycle it).
- **Accuracy:** T **±0.5 °C**, RH **±3 %RH**, P ±0.6 hPa — plenty for a room-comfort readout; the win is folding T/RH/VOC/AQI onto **one** part.
- **Hand-assembly:** LGA leadless → **module. 2a board = Adafruit 5046 (BME688, STEMMA QT), ~$19** ([DK # 14313482](https://www.digikey.com/en/products/detail/adafruit-industries-llc/5046/14313482)); on **2b** the bare BME688 is machine-placed on the daughterboard (same chip → firmware unchanged).
- **Firmware:** Bosch **BSEC 2.x** (BME68x) for IAQ; raw T/RH/P/gas without it. Root README §6c/§8.
- **Interface:** I²C (shared) + optional INT.
- **Price:** ~$5 bare / ~$19 board.

## 13. ams-OSRAM TSL2591 — High-Dynamic-Range Ambient Light Sensor *(weak-light sensitive)*

- **Product:** I²C ALS with **full-spectrum + IR photodiodes**, **600,000,000:1 dynamic range → 188 µlux to 88,000 lux** (gain 1×–9876×, integration 100–600 ms). Far more sensitive in near-dark than the VEML7700 (~0.0036 lux floor) → resolves a **very dim bedroom**.
- **Refs:** `TSL25911FN` · **ams-OSRAM** · **WFDFN-6 (2×2 mm)** · **DigiKey # 4162547** · datasheet `TSL2591 (Apr-2013)` (`sensor_light_tsl2591.pdf`).
- **Power / IO:** 2.7–3.6 V, ~90 µA active / ~3 µA sleep; I²C + INT (open-drain, programmable thresholds).
- **Hand-assembly:** WFDFN leadless → **module. 2a board = Adafruit 1980 (TSL2591, STEMMA QT), $6.95** ([DK # 4990786](https://www.digikey.com/en/products/detail/adafruit-industries-llc/1980/4990786)); on **2b** the bare TSL2591 is machine-placed on the daughterboard.
- **Use:** ALS auto-dim (panel-light + wake-light brightness) + the "true 0 emission at night" logic — the sub-millilux floor detects a fully dark room. Lux from CH0(full)/CH1(IR).
- **Alt:** **Vishay VEML7700** — outputs lux directly, simpler/cheaper, floor ~0.0036 lux (adequate but less sensitive); Adafruit 4162, ~$5.
- **Price:** ~$3 bare / **$6.95 board**.

## 14b. CEVA BNO085 — 9-Axis Fusion IMU *(supersedes §14 for tap-to-snooze + orientation, 2026-07-29)*

- **Product:** accel + gyro + magnetometer **plus a Cortex-M0+ running CEVA's SH-2 firmware** in one 28-pin LGA. The fusion runs **on-chip**: rotation vector, game rotation vector, gravity, linear acceleration, and the classifier outputs (**tap / double-tap, shake, stability, step**) arrive as ready-made reports — the ESP32 does no sensor maths.
- **Refs:** `BNO085` · **CEVA Technologies (Hillcrest Labs)** · **LGA-28, 5.2 × 3.8 × 1.1 mm, 0.5 mm pitch** · **DigiKey 1888-1006-1-ND** ([$13.57, 329 pcs, Active, 16 wk lead](https://www.digikey.com/en/products/detail/ceva-technologies-inc/BNO085/9445940)) · datasheet `BNO08X 1000-3927 v1.17` (`sensor_imu_bno085.pdf`).
- **Power / IO:** **VDD 2.4–3.6 V** (sensors) + **VDDIO 1.65–3.6 V** (core/IO) — both on 3V3; §6.3 requires VDD up **before or with** VDDIO, which one shared rail satisfies by construction. I²C ≤400 kHz at **0x4A** (SA0 low) or **0x4B**; `H_INTN` push-pull, active low.
- **Design rules taken from the datasheet** (Fig. 1-11 + notes 1-8, all implemented in `../kicad-sensor/`): PS1 = PS0 = 0 selects I²C · BOOTN 10 k pull-up (low at reset = DFU) · 100 nF on **CAP** (pin 9) · 32.768 kHz crystal on 26/27 with 22 pF loads (the performance table Fig. 6-14 is **only specified with an external clock or crystal**) · CLKSEL0 low = crystal · the **secondary "ENV" I²C master bus (pins 15/16) must be pulled up even when unused**, because SH-2 probes it at every reset.
- **⚠ Clock stretching:** poll a BNO085 with no data ready and it **stretches SCL until it has some** (§1.2.2.1) — on a shared bus that stalls every other device. Read it **only when `H_INTN` is asserted**; that is why J7 pin 5 is wired to this part's interrupt and nothing else.
- **Hand-assembly:** LGA leadless → **2a board = Adafruit 4754 (BNO085, STEMMA QT), $24.95** ([DK 13426653](https://www.digikey.com/en/products/detail/adafruit-industries-llc/4754/13426653)); on **2b** the bare BNO085 is machine-placed on the sensor board. **Land pattern:** KiCad's stock `Package_LGA:LGA-28_5.2x3.8mm_P0.5mm` is a *generic IPC* pattern (right numbering, ~0.10–0.13 mm extra toe per side), so the board uses a **vendor land verified against Fig. 7-2** instead — `../kicad-sensor/sensor.pretty/CEVA_BNO085_LGA-28_5.2x3.8mm_P0.5mm`, measured 5.2000 × 3.8000 mm exactly (2026-07-29).
- **Why over the LIS3DH:** same jobs (tap-to-snooze R3, flat-vs-standing R14) with no fusion code on the host, plus a real heading/orientation vector for free. Costs ~7× the LIS3DH and much more power — revert to §14 if the power budget bites.
- **Price:** ~$13.6 bare / $24.95 board.

## 14. ST LIS3DH — Triple-Axis Accelerometer *(⚠ superseded by §14b 2026-07-29; kept for a low-cost/low-power variant)*

- **Product:** 3-axis ±2/4/8/16 g accelerometer, 10-bit, on-chip **tap / double-tap** and low-power modes with two programmable interrupts. I²C/SPI. Low-res is fine here — flat-vs-standing is a static gravity read and tap is an IRQ.
- **Refs:** `LIS3DH` · **STMicroelectronics** · **LGA-16 (3×3 mm)** · datasheet `LIS3DH` (`sensor_accel_lis3dh.pdf`).
- **Power / IO:** 1.71–3.6 V; ~2 µA low-power to ~11 µA normal; two INT pins. **Gravity-vector read → static flat-vs-standing (R14)**; **hardware tap IRQ** wakes the MCU for **tap-to-snooze (R3)** so it can sleep between events.
- **Hand-assembly:** LGA leadless → **module. 2a board = Adafruit 2809 (LIS3DH, STEMMA QT), $4.95** ([DK # 5774319](https://www.digikey.com/en/products/detail/adafruit-industries-llc/2809/5774319)); on **2b** the bare LIS3DH is machine-placed on the daughterboard. Mount rigidly to the body so gravity reads true.
- **Firmware:** Adafruit_LIS3DH / esp-idf-lib. Well-supported; same driver whether 2a board or 2b bare.
- **Interface:** I²C (shared) + INT.
- **Price:** ~$2 bare / ~$5 board.

## 15. Sensor build — option 2a (bring-up) vs 2b (drawn 2026-07-29) — *identical sensor set*

**Both paths carry the same three sensors — BME688 + TSL2591 + BNO085 — so the firmware is identical either way.** Every one is leadless, so the cluster is never bare on the **main** PCB:

- **2a — bring-up: STEMMA QT / Qwiic daisy-chain.** Three ready Adafruit boards, one 4-wire I²C chain, zero leadless soldering:

  | Sensor | Board | ~Price | Ref |
  |--------|-------|--------|-----|
  | Env (T/RH/press/VOC) | **Adafruit 5046** (BME688) | ~$19 | [DK 14313482](https://www.digikey.com/en/products/detail/adafruit-industries-llc/5046/14313482) |
  | Light (weak-light) | **Adafruit 1980** (TSL2591) | $6.95 | [DK 4990786](https://www.digikey.com/en/products/detail/adafruit-industries-llc/1980/4990786) |
  | IMU (tap+orient) | **Adafruit 4754** (BNO085) | $24.95 | [DK 13426653](https://www.digikey.com/en/products/detail/adafruit-industries-llc/4754/13426653) |
  | *(was)* Accel | ~~Adafruit 2809 (LIS3DH), $4.95~~ — superseded 2026-07-29 | — | [DK 5774319](https://www.digikey.com/en/products/detail/adafruit-industries-llc/2809/5774319) |

  Chain to the main board over one JST-SH STEMMA QT cable → SDA/SCL/3V3/GND. ≈ **$51** for the three.

- **2b — schematic drawn 2026-07-29: one custom sensor daughterboard.** The **same three bare chips** (BME688 + TSL2591 + BNO085 — §12/13/14b) on a small PCB, **fab-assembled (PCBA)**; the only through-hole part is its **JST ZH B6B-ZR**, and it plugs into main-board **J7** on the same 6-way harness as the knob (J10). Never an iron on a leadless pad → the main board's hand-solder rule stays intact; smallest footprint; one physical board to install. **Same part numbers → same I²C addresses → the 2a firmware runs unchanged.**
  KiCad project: [`../kicad-sensor/`](../kicad-sensor/) — single A3 sheet, ERC clean, **PCB placed (30 × 16 mm, 2 layers, unrouted)**.

## 16. onsemi QRE1113GR — Reflective Optical Sensor *(hand homing, root README §5)*

- **Product:** miniature reflective object sensor — **940 nm IR-LED + phototransistor** mounted **side-by-side** in a small rectangular case; senses a high-contrast index mark on each hand's underside as it sweeps a **hole punched in the dial**. Phototransistor (analog) output; short-range (optimum ≈1 mm).
- **Refs:** Part # `QRE1113GR` · Mfr **onsemi** (Fairchild heritage) · **DigiKey # 965451** · datasheet `QRE1113/D` rev 9 (Dec 2024). Pins: **1 Anode · 2 Cathode · 3 Collector · 4 Emitter**.
- **Price / link:** ~**$0.36** — [DigiKey 965451](https://www.digikey.com/en/products/detail/onsemi/QRE1113GR/965451) (active, verified 2026-07-17). **Replaces the earlier Everlight ITR8307, which went unavailable** — the QRE1113 family is a widely second-sourced jellybean reflective sensor with the **same analog-out interface**, so it drops into the same ADC support network unchanged.
- **Dimensions (L × W × H):** **≈3.6 × 2.9 × 1.7 mm** (4-lead). Two lead forms: through-hole gull-wing `QRE1113` (Case 100AQ, [DigiKey 2175990](https://www.digikey.com/en/products/detail/onsemi/QRE1113/2175990), ~$0.76) or **SMD gull-wing `QRE1113GR`** (Case 100CY, tape & reel) — **SMD form locked 2026-07-17** (cheaper, no dial-side lead holes); custom land pattern per datasheet p.8 in `../kicad/clock.pretty/OnSemi_QRE1113GR.kicad_mod`. Hand-solderable; mounts **on the main PCB** (not a breakout).
- **Power / IO:** IR-LED **V_F 1.2 V typ (1.6 V max) @ 20 mA**, λ 940 nm → ~14 mA at 3V3 through a **150 Ω** ballast (**unchanged from the ITR8307 network**); phototransistor collector to **3.3 V** through a ≈**10 kΩ** load → an **analog level read by 1 ESP32 ADC pin (or a comparator)**. I_C(ON) 0.1–0.9 mA @ I_F 20 mA, V_CE 5 V, d = 1 mm; V_CEO 30 V; I_C ≤ 20 mA. No magnets, no I²C. See `../power_values.md` §6.
- **Use (§5):** one sensor behind the dial; **sequential per-shaft homing** removes hand-ID ambiguity (park one hand off-index, sweep the other to the edge; repeat). Re-home on boot / after NTP / after long runs; step-count between.
- **Range / why it fits:** collector current **peaks near d ≈ 1 mm** and falls off past a few mm (datasheet Fig. 2), which suits hands swept **<3 mm** off the dial (index mark on the underside). It is **larger than the ITR8307** (3.4×1.5×1.1 mm) → a marginally bigger dial hole, but still far smaller than the **Vishay TCND5000** (6×4.3×3.75 mm, peak 6 mm) that was evaluated for a long stand-off and **dropped**. *(Homing replaces the earlier 2× DRV5032 Hall + hand magnets.)*
- **Interface:** analog reflective (ADC/comparator edge).

## 17. Timekeeping — no RTC IC *(ESP32-S3 RTC + 32.768 kHz crystal)*

**Decision: no dedicated RTC chip, no coin cell.** A battery-less RTC IC would lose time on total power loss exactly as the S3 does, so it adds parts without buying anything. The S3's *own* RTC is fine **as long as it runs off a good reference** — its internal RC oscillator drifts %-level over temperature (amp/LED heat nearby), so:

- **Add a 32.768 kHz crystal** on the S3's **XTAL32K** pins (GPIO15/16) → the RTC slow clock runs at **~±20 ppm ≈ 1.7 s/day**, disciplined by **SNTP** whenever online (even a daily sync keeps error to a couple seconds). Part now **locked = Abracon ABS07-32.768KHZ-T** (3.2×1.5 mm 2-SMD, **CL 12.5 pF** → two load caps ≈ **18 pF each** = 2·(C_L − C_stray) ≈ 2·(12.5 − 3); see `../power_values.md` §6), ~$0.3, hand-solderable — **datasheet filed (row 16, `xtal_32k_abs07.pdf`)**.
- **The S3 is essentially always powered** (USB or the 18650 on the always-on BAT node), so the RTC domain rarely dies. If **both** USB and the 18650 are gone, time is lost → **re-sync via SNTP on next boot**, running a clock animation meanwhile (accepted, keeps HW simple).
- *If you ever wanted true powered-off holdover* it would take an RTC IC **plus** a coin cell/supercap (e.g. RV-3028-C7 45 nA, or DS3231SN SOIC-16 TCXO) — explicitly **out of scope** here (no second battery).

See root README §1/§6c/§8/§10.

---

## 18. Power-path & interconnect parts *(rows 16–25 — locked 2026-07-05)*

Production-BOM rows, now locked to hand-solderable parts + filed datasheets. All DigiKey-active/orderable unless noted.

- **16 — Abracon `ABS07-32.768KHZ-T`** (32.768 kHz xtal) · DK [1236858](https://www.digikey.com/en/products/detail/abracon-llc/ABS07-32-768KHZ-T/1236858) · 3.2×1.5 mm 2-SMD · **CL 12.5 pF**, ±20 ppm, ESR ≤70 kΩ · S3 XTAL32K (GPIO15/16); load caps ≈ 2·(CL − Cstray). ~$0.3.
- **17 — Alpha & Omega `AO3401A`** (reverse-polarity P-FET) · DK [1855773](https://www.digikey.com/en/products/detail/alpha-omega-semiconductor-inc/AO3401A/1855773) · **SOT-23-3** · −30 V, −4 A, R<sub>DS(on)</sub> ≤50 mΩ @ −10 V. Series P-FET on BAT+ (bare cell can't be keyed). ~$0.24.
- **18 — Murata `NCP18XH103F03RB`** (10 k NTC) · DK [1644665](https://www.digikey.com/en/products/detail/murata-electronics/NCP18XH103F03RB/1644665) · **0603** (⚠️ BOM §16b said "0402" — corrected; NCP18 = 0603, meets the ≥0603 rule) · 10 kΩ ±1 %, **B25/50 = 3380 K**. Wires to the LT3652 NTC pin for hot/cold charge-qualify. ~$0.10.
- **19 — Littelfuse `SMAJ22A` + `SMAJ5.0A`** (TVS) · DK [762286](https://www.digikey.com/en/products/detail/littelfuse-inc/SMAJ22A/762286) / [762250](https://www.digikey.com/en/products/detail/littelfuse-inc/SMAJ5-0A/762250) · **DO-214AC (SMA)** · 400 W uni; SMAJ22A (Vwm 22 V) on VBUS (15 V PD + headroom), SMAJ5.0A (Vwm 5 V) on the BAT node. ~$0.4 ea. *(Filed datasheet is the Bourns-published SMAJ series — identical JEDEC part numbers/specs; Littelfuse's own PDF is Akamai/bot-blocked from direct download.)*
- **20 — TI `TPS55340PWPR`** (12 V audio boost, gated) · DK [3727185](https://www.digikey.com/en/products/detail/texas-instruments/TPS55340PWPR/3727185) · **HTSSOP-14 (PWP, PowerPAD)** · 2.9–32 V in → 3–38 V out, **5 A/40 V** integrated FET, 1.2 MHz. **Replaces the BOM's LM2587S-ADJ** — that part is obsolete-leaded and its active `/NOPB` is **$12.59 & 0 stock**; TPS55340 is leaded/hand-solderable, in-stock, ~5× cheaper, ample for the TAS5760M PVDD. ~$2.5.
- **21 — TI `TPS61023DRLR`** (5 V rail boost) · DK [11310667](https://www.digikey.com/en/products/detail/texas-instruments/TPS61023DRLR/11310667) · **SOT-563** (small but gullwing → hand-solderable) · 0.5–5.5 V in, **3.7 A** valley limit, 94 % @ 3.6→5 V. Chosen over MT3608 (off-DigiKey). ~$1.2.
- **22 — TI `TLV62569DBVR`** (3.3 V rail buck) · DK [7688370](https://www.digikey.com/en/products/detail/texas-instruments/TLV62569DBVR/7688370) · **SOT-23-6** · 2.5–5.5 V in, **2 A** sync buck, 1.5 MHz. Bucks the 5 V rail → 3.3 V logic (over the AMS1117 LDO alt — far better efficiency). ~$0.25.
- **23 — Keystone `1043`** (18650 holder) · DK [2745669](https://www.digikey.com/en/products/detail/keystone-electronics/1043/2745669) · TH leaf-spring PC-pin, UL94V-0 nylon · single-cell, user-replaceable. Mount in the ventilated FR/metal-barriered compartment per `../power.md`. ~$2.9.
- **24 — Hirose `DM3AT-SF-PEJM5`** (microSD) · DK [2533565](https://www.digikey.com/en/products/detail/hirose-electric-co-ltd/DM3AT-SF-PEJM5/2533565) · **push-push SMT R/A**, 8-pos, gold, 10 k cycles · SD over the S3 SPI bus (4 pins). ~$2.85.
- **25 — GCT `USB4105-GF-A`** (USB-C receptacle) · DK [11198441](https://www.digikey.com/en/products/detail/gct/USB4105-GF-A/11198441) · USB 2.0 Type-C, **5 A**, SMT body + **TH hold-down tabs** (rugged), 20 k cycles · VBUS/CC to the CH224K PD sink. ~$0.8. *(⚠ not in current build — superseded 2026-07-19 by the **vertical USB4160-03-0230-C**, row 30; datasheet kept.)*
- **27 — Analog Devices `LTC4412ES6#TRPBF`** (amp-PVDD rail-mux) · DK [960173](https://www.digikey.com/en/products/detail/analog-devices-inc/LTC4412ES6-TRPBF/960173) · **TSOT-23-6** · low-loss **PowerPath OR-controller** driving an external P-FET; auto-selects **12 V (plugged)** vs **5 V (battery)** for the TAS5760M PVDD → quieter alarm on the cell (V range 3–28 V, well above the 12 V rail). Autonomous, no MCU. ~$5.2. *(Bench: finalize the external mux P-FET network — `../power_values.md` §8.)*

**LED subsystem — reworked v0.19 (2026-07-19; 12 V source locked 2026-07-12):** **2 wake PWM channels + 1 NeoPixel data line**, two rails. **Wake-up** = **12 V** self-ballasted COB, **warm 3000K** (`12V-COB-3000K-12M`, DK 16714316) + **neutral 4000K** (`12V-COB-4000K-12M`, DK 16714317), Inspired LED; low-side **AO3400A** ×2 (100 Ω gate + 10 kΩ pulldown, ~1 kHz), PWM ← IO45 (warm) / IO46 (cool). **Status + dial** = **7× SK6812 RGBW** on-PCB (row 31; 5 status behind the aluminum face + 2 dial wash), **5 V rail**, one RMT data line (IO7) through the **SN74AHCT1G125** buffer (row 32). *(The v0.12–v0.18 **panel string** — Cree `CLM3C-MKW-CWAXB233` ×≤12 + 3rd AO3400A + LEDC ch — was **dropped 2026-07-19** with the display; its DK link stays here for reference.)* **12 V source RESOLVED: no barrel jack** — the wake strips run off the shared **TPS55340 boost, plugged-only**; on battery the amp PVDD auto-drops to the 5 V rail via an **LTC4412 mux** (quieter alarm) and the NeoPixels (5 V) stay on. See [`../led.md`](../led.md) + [`../power.md`](../power.md) §LED + [`../power_values.md`](../power_values.md) §8. **Bench:** finalize the mux FET network; confirm wake-COB wattage keeps LED + audio ≤ ~12 W.

---

## 19. Microchip MCP23017 — I²C 16-Bit IO Expander *(offloads slow control lines)*

- **Refs:** `MCP23017` (I²C; pin-compatible SPI twin `MCP23S17`) · **Microchip** · **SOIC-28 wide / SSOP-28** (both hand-solderable gullwing; **avoid the 28-QFN**). Datasheet **DS20001952** (`expander_mcp23017.pdf`).
- **Price:** ~$1.3 (active, widely stocked).
- **Power / IO:** 1.8–5.5 V (run at **3.3 V** off the logic rail); **16 bidirectional I/O** in two 8-bit ports; **3 hardware address pins** → up to 8 devices per bus; **INTA/INTB interrupt-on-change** (configurable active-hi/lo/open-drain, mirrorable). I²C to **1.7 MHz** (MCP23S17 SPI to 10 MHz).
- **Use:** hangs on the **existing shared I²C bus** (sensors + amp) → **zero new bus GPIO**; costs **1 MCU pin for INT**. Offloads *slow / static* lines off the pin-starved S3: **SPK_SD** (amp mute), **12 V-boost EN**, stepper **STBY**, the **rear radio-disable toggle** (GPA3, J11), **PD PG**, **charger CHRG/FAULT**, FULLCHG_EN, VBAT_DIV_EN, SPK_FAULT (open-drain status — the expander's weak pull-ups + interrupt-on-change catch every transition). **Net −9 GPIO** on the host. *(v0.19: BTN1–3 gone; **ENC_SW moved to host IO17** for a low-latency press interrupt.)*
- **Do NOT offload (hard limits):** the 8 stepper **AIN/BIN are PWM** (>20 kHz carrier for silent microstep) — an expander can't bit-bang them, and a **PCA9685 PWM expander tops out ~1.5 kHz**, ~15× too slow; keep them on **MCPWM**. **Knob A/B quadrature** stays on native GPIO via the S3 **PCNT** counter (an I²C-polled expander drops steps on a fast spin), and the **press switch needs a crisp host IRQ** (I²C polling adds latency). I²S, SPI, the wake PWM (LEDC), the NeoPixel RMT line and the ADC inputs likewise stay on the MCU.
- **Interface:** I²C (2 shared) + 1 INT GPIO. Prefer I²C over the SD-SPI bus — I²C adds **no** MCU pin, SPI would cost a CS.

---

## Reconciliation with root README (v0.19)

All parts match the root [`README.md`](../README.md):

| Item | Status |
|---|---|
| **Hand-solderable-only** | ✅ every bare-PCB IC is leaded (SOIC/SOP/SSOP/TSSOP/HTSSOP/MSOP/SOT-23) or a castellated module; no QFN/DFN/BGA/LGA on the board. v0.19 additions comply: SK6812 = PLCC-4 (big corner pads), SN74AHCT1G125 = SOT-23-5, EM14 + ZH connectors = TH, USB4160 = 0.5 mm SMT + soldered stakes (fine-pitch drag-solder like the previously accepted FH34). |
| **Display** | ⚠ **not in current build** — dropped v0.19 (cube redesign, no screen). Rows 1 + 11 (LS032B7DD02 + FH34) **retained** for a future variant; `../esp32.md` carries the current pin map. |
| **Status/dial LEDs (v0.19)** | ✅ **7× SK6812 RGBW** (row 31, Adafruit 2758) + **SN74AHCT1G125** buffer (row 32) on 5 V, one RMT data GPIO (IO7). Replaces the panel string (Cree CLM3C, dropped). |
| **Knob (v0.19)** | ✅ **Bourns EM14A0D-C24-L064S** (row 33): optical, no detent, 64 CPR, push, 5 V; A/B → 100k/200k dividers → PCNT IO47/48, SW → IO17 IRQ. Kilo OEJNI-90-1-5 aluminum knob (mechanical, no datasheet). J10 = ZH 1×06 (row 34). |
| **Speaker** | ✅ DMA58-4 chosen; PC68-4 kept as documented "bigger-box alt". |
| **Stepper** | ✅ X40.879**.NS** (no stop; + X40/X27 datasheets); root §5 explains the dependency. Dial now Ø~90 mm → keep the aluminum hands light (≲1 g). |
| **Audio amp** | ✅ **TAS5760M** (HTSSOP) locked, replacing the QFN TAS5825M; firmware does the HPF/limiter DSP. PCM5102A+TPA3116 = analog alt. |
| **Motor driver** | ✅ **2× TB6612FNG** (SSOP-24) locked, replacing the WSON DRV8835. |
| **Power / safety** | ✅ **CH224K** (PD) + **LT3652** (1S buck charger, BAT-node power-path) + **HY2111 + AOSD32334C** protector + reverse P-FET + NTC + TVS. Fuel gauge → **ESP32 ADC**. See [`../power.md`](../power.md). Unchanged by v0.19. |
| **Charger telemetry** | ⚠️ **downgrade:** LT3652 has **no I²C** and a **single-window NTC** (not multi-zone JEITA). Health-cap 4.05 V is enforced in hardware; SoC/faults via ADC + status pins. Double-redundant overcharge preserved. |
| **Sensors (v0.15 consolidated)** | ✅ env **BME688** (T/RH/press/**VOC**) · light **TSL2591** (weak-light) · accel **LIS3DH** (**tap-to-snooze only since v0.19** — orientation/R14 retired). All leadless → **I²C modules**, same set on both paths: **2a** = Adafruit STEMMA QT chain (5046 + 1980 + 2809); **2b** = future custom daughterboard. J7 = ZH 1×06 (row 34). |
| **Hand homing** | ✅ **1× onsemi QRE1113GR** reflective optical (§16, on-board, custom land pattern in `../kicad/clock.pretty`) — single sensor + punched dial hole, sequential, **no hand magnets**. |
| **Timekeeping** | ✅ **No RTC IC / no battery** — S3 internal RTC off a **32.768 kHz crystal** (XTAL32K) + SNTP (~±20 ppm ≈ 1.7 s/day). Total power loss → re-sync on boot (clock animation). Xtal locked = **ABS07-32.768KHZ-T** (row 16). |
| **IO expander** | ✅ **MCP23017** (SOIC/SSOP-28) on the shared I²C + INT — offloads SPK_SD / 12 V EN / stepper STBY / **radio-off toggle** / **PD PG** / **charger CHRG/FAULT** / FULLCHG_EN / VBAT_DIV_EN / SPK_FAULT (**net −9 GPIO**). Steppers stay on **MCPWM**, knob A/B on **PCNT**, knob press on **IO17** — *not* the expander. See §19. |
| **Power-path & interconnect** | ✅ rows 16–24 locked + datasheeted (2026-07-05); **USB-C = vertical USB4160-03-0230-C (row 30)** since 2026-07-20 — the horizontal USB4105 (row 25) + Adafruit 6069 extension are **not in the current build** (kept). Off-board harness connectors = **JST ZH** (row 34) for sensor/knob/toggle (pre-crimped AxxZR cables), **JST PH** for speaker/wake-strips (power); mating halves + 152 mm cable PNs in root README **§16d**. Rear radio toggle itself = **E-Switch `100SP1T2B1M1QEH`** (row 43). |

**No open discrepancies vs the root README (v0.19).** Historical corrections retained from earlier passes: NTC size 0402 → 0603; audio boost LM2587S-ADJ → TPS55340PWPR; 32.768 kHz load caps → ~18 pF. Intentional non-"matches": **PC68-4** (speaker *alternative*), **CH224K + HY2111 off-DigiKey** (LCSC), the filed **TVS datasheet is the Bourns-published SMAJ** series (identical JEDEC part), and the three **"not in current build"** rows (1, 11, 25) kept per the v0.19 retention policy. **Bench-only opens:** LTC4412 mux FET network confirmation · LT3652 NTC bias · TPS55340 comp network · QRE1113 threshold · EM14 divider levels · wake-COB wattage vs the ~12 W ceiling. **Schematic-side opens:** USB4160 footprint cross-check vs the GCT drawing before fab; Keystone 1043 footprint pin-span cross-check (±35.8 drawn, MR !2043 says ±36.11 — slack drill covers both) — *the 1042↔1043 mismatch itself was resolved 2026-07-20 in favor of the in-stock 1043*; knob (OEJNI) mechanical drawing not filed; status-LED row pitch waits on the enclosure CAD; **rear panel must be counterbored to ≤6 mm at the Ø6.35 mm J11 toggle hole** (row 43 — the `100SP1T2B1M1QEH` bushing is only 8.89 mm).

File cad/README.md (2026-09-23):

# CAD

## X40.879 shafts — hand bores

Measured from the factory STEP (`kicad/3d/X40_879.step`), matches Juken's X40 drawing. Tolerance +0 / −0.02 mm. Heights from the motor body top face.

| Hand | Shaft | Seat Ø | Seat length | Height | Hand length from center |
|---|---|---|---|---|---|
| **Minute** (front) | inner pin | **1.00 mm** | 4.0 mm exposed above tube (0.2 mm tip chamfer) | 6.9 → 10.9 mm | 25 mm |
| **Hour** (behind) | outer tube | **2.90 mm** | 4.0 mm (0.2 mm top chamfer) | 2.9 → 6.9 mm | 40 mm |
| — | tube shoulder (through PCB) | 3.00 mm | 2.9 mm | 0 → 2.9 mm | - |

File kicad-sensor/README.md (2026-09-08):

# Wooden Smart Clock — sensor board (KiCad)

Small SMT daughterboard carrying the three off-board sensors, plugged into
**main-board J7** on a 6-way JST ZH harness. Open `sensor.kicad_pro`.

**The schematic is generated** by the Python in `gen/` (see *Regenerating*) —
edit the block files, not the `.kicad_sch`. **The PCB is not**: it has been
hand-placed and hand-routed since 2026-08-02, so `gen/pcb_build.py` refuses to
run and board changes are made in pcbnew + *Update PCB from Schematic* (F8).

**PCB: 30 × 16 mm, 4 layers, 1.6 mm — fully routed, `SENSE v0.2`
(2026-08-07).** Front face = the two sensors that must see the outside world
(TSL2591 window + BME688 vent); back face = the harness connector and the IMU.
Full rationale, floor plan, verification and the list of accepted deviations
in [`PCB_NOTES.md`](PCB_NOTES.md); the design review that drove v0.2 is in
[`REVIEW.md`](REVIEW.md).

This is "option **2b**" of [`../datasheet/README.md`](../datasheet/README.md) §15:
the same sensor set as the STEMMA-QT bring-up chain, on one board, at the same
I²C addresses, so firmware written against the breakouts runs unchanged.

| Ref | Part | Package | I²C | Datasheet |
|---|---|---|---|---|
| U1 | **BNO085** (CEVA/Hillcrest 9-axis fusion IMU, SH-2 on-chip) | LGA-28 5.2×3.8 *(land in `sensor.pretty`)* | **0x4A** (R3) / 0x4B (R4) | `../datasheet/sensor_imu_bno085.pdf` |
| U2 | **BME688** (gas/VOC + RH + pressure + temp) | LGA-8 3×3 | **0x77** (R10) / 0x76 (R11) | `../datasheet/sensor_env_bme688.pdf` + `…_bme68x_hsmi.pdf` |
| U3 | **TSL2591** (`TSL25911FN`, 188 µlx–88 klx ALS) | DFN-6 2×2 *(land in `sensor.pretty`)* | **0x29** (fixed) | `../datasheet/sensor_light_tsl2591.pdf` |
| Y1 | ABS07-32.768KHZ-T (BNO085 clock) | 3.2×1.5 SMD | — | `../datasheet/xtal_32k_abs07.pdf` |
| J1 | JST ZH **B6B-ZR** 1×06 | TH vertical | — | `../datasheet/connector_jst_zh.pdf` |

**Address straps are 10 kΩ, not 0 Ω** (v0.2). Exactly one of each pair is
fitted; the alternate carries a real `DNP` flag. Fitting both halves is the
assembly slip this layout invites, and through 0 Ω it would short the **main
board's** +3V3 rail to GND — on a daughterboard with no LED and no silk hint,
which is hours of debugging. Through 10 k the same slip costs 330 µA, the
clock still boots, and the part answers at a wrong-but-visible address.

No clash with the main board's own I²C devices (MCP23017 **0x20**, TAS5760M
**0x6C** — `SLEEP/ADR` strapped to GND, `kicad/gen/b_audio.py`; 0x6D is the
ADR-high alternate).

## J1 pinout — mirrors main-board J7 **1:1**

| Pin | Net | Main board (J7) | Sensor board |
|---|---|---|---|
| 1 | `GND` | GND | GND |
| 2 | `+3V3` | +3V3 | rails in — no regulator on this board |
| 3 | `I2C_SDA` | shared bus (4.7 k PU = R95) | U1.20 · U2.3 · U3.6 (+ R1 10 k) |
| 4 | `I2C_SCL` | shared bus (4.7 k PU = R96) | U1.19 · U2.4 · U3.1 (+ R2 10 k) |
| 5 | `SENSOR_INT` | MCU **IO42** IRQ, 10 k PU = R97 | **U1.14 `H_INTN` only** (push-pull, active low) |
| 6 | `ALS_INT` | **MCP23017 GPB3** (U13.4) | **U3.2 `INT`** (open drain, R12 10 k PU here — the only one on the net) |

Pin 6 was a spare wire when this board was designed; `kicad/REVIEW.md` #11
landed it on expander **GPB3**, so the ALS interrupt is live. Because the
pull-up lives only here, firmware must also set **`GPPU.3 = 1`** so GPB3 does
not float when this board is unplugged — `FIRMWARE.md` **R-BOARD-4**.

### ⚠ Harness polarity is a destructive fault

Both ends are ZHR-6 on the same pre-crimped cable and J1 mirrors J7 1:1, so a
cable loaded **backwards plugs in perfectly** — and J1.5 then receives J7.2
**+3V3 while this board's VDDIO is 0 V**. BNO08X abs max (Fig. 6-1) is
*"VDDIO + 0.3 V at any logic pin"*, series-limited only by the main board's
R97 10 k: **assume U1 ($13.57, the most expensive part on either board) is
destroyed.**

**This is not a hypothetical, and it is not only a mis-crimp: JST sells the
backwards cable as a catalogue part.** `A06ZR06ZR28H152`**`A`** is the
*Reversed* build (pin 1 ↔ pin 6, DigiKey 455-3027-ND) and
`A06ZR06ZR28H152`**`B`** is straight through (pin 1 ↔ pin 1, DigiKey
455-3039-ND) — one character apart, indistinguishable in the bag. The BOM has
always said `…B`; the cable that arrived for build #1 on **2026-09-08** was an
`…A`, and a continuity check is the only reason U1 survived it.

> **Standing procedure, before this harness ever goes into a powered board:**
> DMM on continuity, cable out of both boards, **pin 1 of one end to pin 1 of
> the other**. A beep on pin 1 ↔ pin 6 instead means re-pin it or bin it.

Worse, the main board's **J10** (knob) is the *same* ZH 1×06 header **13.5 mm
from J7**, with **+5 V on pin 2** — that mis-mate puts 5 V on `+3V3` and takes
out all three sensors at once (abs max: BNO085 VDDIO 3.63 V, TSL2591 3.8 V,
BME688 4.25 V).

Neither is keyed out, and **the connector is not going to change** — a 1×07
was proposed and rejected on 2026-08-08 ([`REVIEW.md`](REVIEW.md)). The guard
is marking, and it has to be followed: the main board carries **`SENSOR` and
`KNOB` on B.Silk** beside J7 and J10, so **label both harnesses to match, and
check the cable before first power-up.** The reversed-cable warning is also
printed on the schematic sheet next to J1 and on J10's BOM line, so it is in
front of whoever assembles the clock rather than only in this file.

## Design notes (all traceable to a datasheet line)

**BNO085 (`gen/b_imu.py`)** — follows the CEVA I²C reference design
(Fig. 1-11 and its notes 1-8):
- `PS1 = PS0 = 0` → I²C; `BOOTN` 10 k pull-up (R7) with test pad TP2 — pull it
  low at reset for the DFU bootloader.
- `CAP` (pin 9) → 100 nF to GND; VDD and VDDIO each get their own 100 nF
  (C3/C4) plus a 1 µF local bulk (C5) the reference omits — this board hangs
  off a long harness.
- **VDD and VDDIO share the 3V3 rail.** §6.3 demands VDD reach level *before
  or with* VDDIO; one rail satisfies that by construction.
- **32.768 kHz crystal** (Y1 + C7/C8 22 pF) with `CLKSEL0` **tied straight to
  GND — a bare wire, no strap resistor** (Fig. 1-8: *"0 or unconnected"*
  selects the crystal). The performance table (Fig. 6-14) is specified *only*
  for an external clock or crystal, so the internal RC is not used. Same ABS07
  part as the main board's RTC crystal (12.5 pF CL, ±20 ppm; CEVA asks
  50 ppm/12.5 pF).
- **`ENV_SCL`/`ENV_SDA` (pins 15/16) are pulled up although unused** — note 8:
  the SH-2 firmware probes that secondary bus at every reset. They are *not*
  tied to the host bus; on that bus the BNO085 is the master.
- **`NRST`**: J7 has no spare host line, so R6/C9 form a 10 k/100 nF power-on
  reset (TP1 to drive it by hand). It also guarantees the reset-sampled straps
  (BOOTN, PS1, PS0, CLKSEL0) are settled before release.
- **Deviation:** pin 18 `H_CSN` is unused in I²C mode and Fig. 1-11 leaves it
  open; R5 pulls it to VDDIO instead, so no CMOS input floats on a battery
  product. Harmless in every mode — `H_CSN` is not sampled at reset.

**BME688 (`gen/b_env.py`)** — §7.2 connection diagram (a):
- **`CSB` hard-tied to VDDIO.** §6.1: pull CSB low even once and the part
  latches into SPI until the next power-on reset and never answers I²C again.
- `SDO` must not float (§6.2). R10 (**10 k**) fitted → 0x77, matching the
  Adafruit 5046 breakout used for bring-up — which also uses 10 k; R11 (DNP)
  → 0x76, Bosch's own default. `SDO` is address-select only in I²C mode
  (Table 26) and is never driven, so a resistive strap is unambiguous.
- 100 nF on each supply (C10/C11).
- **Handling is the risk on this part, not wiring** — see *Assembly* below.

**TSL2591 (`gen/b_als.py`)** — "Application Information":
- **1 µF low-ESR at VDD** (C12), placed as close as possible to the pin.
- `INT` is open-drain → R12 10 k. Pin 4 is "NC — do not connect".

**Board level (`gen/b_host.py`)** — C1 10 µF + C2 100 nF at the connector
absorb the BME688 heater bursts (~18 mA peak) and the BNO085 turn-on so they
do not ride back up the single power wire. R1/R2 10 k parallel the main
board's 4.7 k to ≈3.2 k, inside the 2–4 kΩ window CEVA asks for (note 7) and
fast enough for 400 kHz over the harness; depopulate both to run on the 4.7 k
alone at 100 kHz. Two PWR_FLAGs declare the rails to ERC — nothing on this
board drives them.

## ⚠ Firmware constraint — do not poll the BNO085

Poll a BNO085 that has no data ready and it **stretches SCL until it does**
(§1.2.2.1). On this shared bus that stalls the BME688, the TSL2591 *and* the
main board's MCP23017 (knob, charger status, amp shutdown). Read it **only
after `SENSOR_INT` asserts**. `SENSOR_INT` carries nothing else, which is why
the TSL2591's interrupt went to the spare pin 6 instead.

Second, related, main-board item: CEVA says `H_INTN` "should be tied to a GPIO
**with wake capability**". `SENSOR_INT` lands on **IO42** (`../esp32.md`), which
is *not* an ESP32-S3 RTC GPIO (only IO0–IO21 are), so it can wake light sleep
but **not** `ext0`/`ext1` deep sleep. Fine if the clock never deep-sleeps with
tap-to-wake armed; otherwise move `SENSOR_INT` to an RTC-capable pin on the
next main-board revision. Not changed here — this board only presents the
signal on J1.5.
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

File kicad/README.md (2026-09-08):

# Wooden Smart Clock — KiCad schematic + PCB

KiCad 10 schematic on **one A1 page**, organised like `../block_diagram.drawio`
(⚠ the drawio still shows the pre-v0.19 display-era design):
power flows along the left, MCU in the centre, peripherals on the right.
Open **`clock.kicad_pro`**. The sheet is **generated** by the Python code in
`gen/` (see *Regenerating* below) — edit the block files, not the `.kicad_sch`.
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

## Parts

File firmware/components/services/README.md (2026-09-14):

# services/  — the nine active objects (§3.2)

motion(20) audio(18) storage(14) chrono(12) board(11) ui(10) net(6) supervisor(5) cli(3)

All pinned to core 1 except `net`. One owner per peripheral; no AO handler blocks > 2 ms.

| | |
|---|---|
| `motion` ✅ | Trapezoidal profile on a 10 ms control tick, backlash (every move finishes clockwise), absolute targets only — resolved into the hands' own unwrapped frame, the short way for a clock and the way the knob turned for a knob (§6.6e) — and the §6.1 homing FSM: clear → coarse-minute → fine-minute → park-minute → coarse-hour → fine-hour, with a budget that faults rather than sweeping forever. `clear` exists because a hand parked on the index holds the sensor lit and there is then no edge to find at all |
| `chrono` ✅ | Wall clock as an offset from the monotonic base — so `sim warp` warps the clock with it — turned into a `HandTarget` whenever the minute changes. Alarm table, TZ/DST and the SNTP re-home policy still to come |
| `ui` ✅ | README §12's press cycle (bell → alarm → clock → volume → commit), the one 5 s timeout, counts-per-minute, the direction a turn hands to `motion`, the pace that stops a setting outrunning the hands drawing it (§6.6d), and all pixel output. Zero emission when idle is enforced here |
| `audio` `storage` `board` `net` `supervisor` | still to come |

⚠ `audio` the **AO** is still to come; `hal::audio` is not. Since 2026-09-13 the port, the
TAS5760M's register set, the datasheet's start-up order and a generated sine are real
(`FIRMWARE.md` §6.2/§12.0.15), and the `audio` CLI group reads the HAL directly the way `board`
does. Two consequences for whoever writes the AO: `ui`'s volume-mode preview chime calls
`hal::audio::tone()` and is marked MOVE-IT, and the HAL owns a **writer task** of its own at
priority 18 — the AO takes the pipeline over from it, not the port.

`motion` is the one that carries the interesting bugs, so it is the one with the deepest
tests. Note what is *not* here: commutation. `hal::motor` is a velocity-controlled microstep
axis with a stop target, so the profile and the FSM are identical on the bench and in
`clocksim`.

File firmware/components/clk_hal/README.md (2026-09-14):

# hal/  — thin RAII wrappers over peripherals

`api/` **declares**; `esp/`, `host/` and `shared/` **define**. CMake picks the backend; a driver
cannot discover which it got, and there is no `#ifdef` in driver code. That is what keeps
`clocksim` honest.

`api/`    the surface — `hal.hpp` plus one header per I2C part
`esp/`    the IDF implementations — one of only two places `esp_*.h` may be included
`host/`   fakes, scriptable from the `sim` command group (§9.5)
`shared/` compiled into BOTH backends: the code that is the same either side of the line, so
          there is one copy to get right and the host tests exercise what the board runs (§11.2)

`shared/` today: the four I2C device drivers (`mcp23017`, `tsl2591`, `bme688`, `bno085`) — on
target they drive silicon, on the host the register models in `host/src/model_*.cpp` behind the
fake `hal::i2c` — and `power.cpp`, which is not a device driver at all. It is there because
`hal::power` turned out to be nothing but arithmetic over `hal::adc` and `hal::expander`: the
SoC endpoints, three open-drain inversions, and R-BOARD-3's decision about which node
`VBAT_SENSE` was looking at. Two copies of that is two chances for the host and the target to
disagree about whether the clock is charging.

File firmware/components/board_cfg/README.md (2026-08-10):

# board_cfg/  — pin map + device presence, zero IDF

One header per board (`board_rev0_3.hpp`, `board_devkit.hpp`, `board_host.hpp`), selected by
`CONFIG_CLOCK_BOARD_*`. D15: **the pin map is identical across boards** — only the set of
devices actually fitted differs, expressed as a presence bitmask. An absent device yields
`Status::NotPresent` (D16), never a faked success.

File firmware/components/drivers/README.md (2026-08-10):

# drivers/  — device logic, pure I/O + math

X40Movement Tb6612 Qre1113 Sk6812Chain Tas5760 Mcp23017 Bme688 Tsl2591 Bno085 Lt3652Status

Rule 5: drivers never post events, never log at INFO, never block on a queue.
Depends on: `hal/api`, `core`, `board_cfg`.

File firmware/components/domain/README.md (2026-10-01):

# domain/  — pure product logic, zero IDF

Everything here is a pure function of its inputs, which is why §11.1 targets it for ≥90 %
host coverage.

| | |
|---|---|
| `hand.hpp` ✅ | Microstep ↔ degrees ↔ time, positive modulo, shortest signed path, the **directed** and **chased** paths a knob needs instead (§6.6e), and the backlash `approach()` that makes every move finish clockwise (§6.1, §7.2) |
| `anim.hpp` ✅ | Every pattern a light can make — ramp, breathe, blink, flash burst — plus the one `AnimCfg` that times all of them and the one place gamma is applied (§6.6a). `render(anim, cfg, now)` is a pure function, so a 30-minute sunrise ramp is asserted in a microsecond |
| `alarm.hpp` ✅ | The alarm week (a minute per weekday, each on/off) and the knob's one-off override that replaces the next day's alarm only: `next`, `due`, `override_at`, `expire`, all in local minutes (§6.6f) |
| still to come | the sunrise *colour* curve, DSP biquad + limiter |

Header-only for now — it is all `constexpr`, so there is nothing to link. It still gets a
component so the §2 dependency rule is enforced by CMake rather than by good intentions.

Depends on: `core`, and `hal/api` for `kUstepsPerRev` alone.

**Convention, and it is load-bearing:** 0 microsteps = 12 o'clock, increasing **clockwise**;
the homing index sits at 0. Positions are unwrapped `int32` so "go the long way round" is
expressible — `normalise()` is the one place that knows about the modulo.

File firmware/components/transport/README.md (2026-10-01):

# transport/  — the app link's bytes

`frame`     CLI line in (`"<id> <line>"`), CLI output out (`"<id>|text"` … `"<id>$ok"`)
`snapshot`  the 150-byte status record: encode / decode, schema + size, append-only

Rule: no IDF, no services, no radio. The radio is `hal::ble`; the policy (pairing window,
who may run a command, when to notify) is the `net` AO. The CLI line goes to
`cli::dispatch_line_wait` — the app has exactly the console's command set (§5, §8).

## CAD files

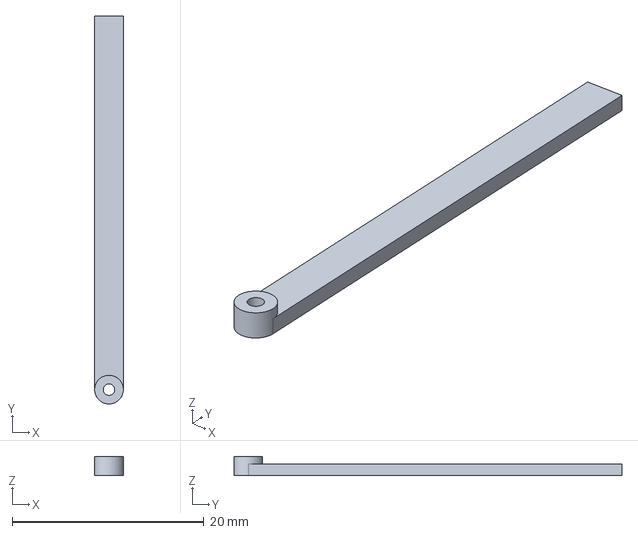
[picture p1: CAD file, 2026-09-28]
cad/minutes.FCStd
3.00 x 40.5 x 2.00 mm

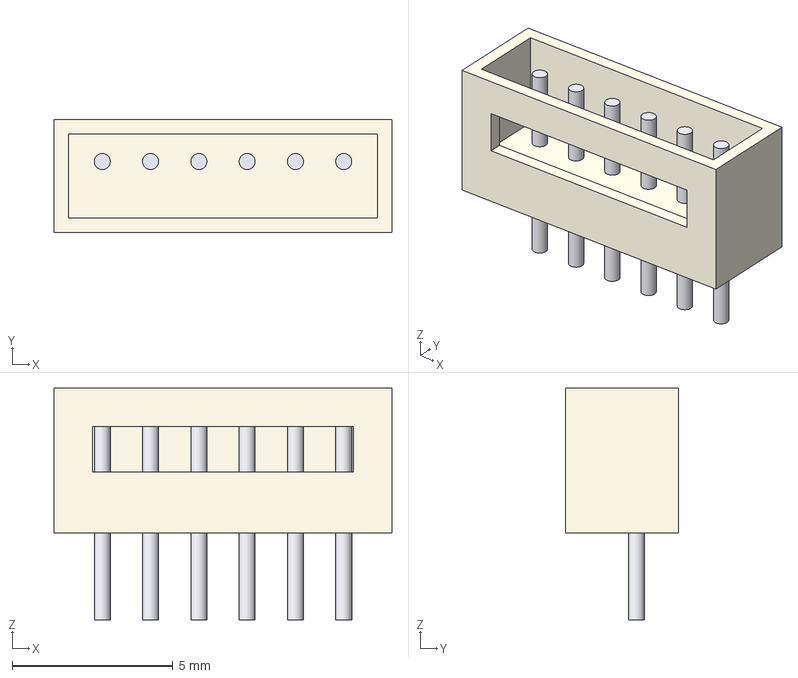
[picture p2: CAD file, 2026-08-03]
kicad-sensor/3d/JST_ZH_B6B-ZR_1x06_P1.50mm_Vertical.step
10.5 x 3.50 x 7.20 mm

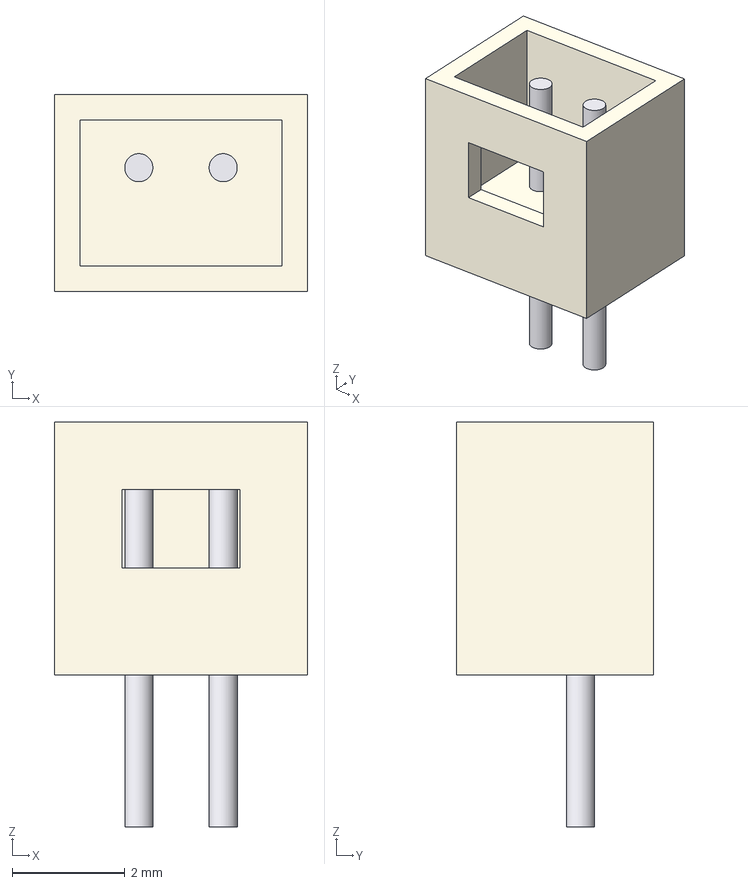
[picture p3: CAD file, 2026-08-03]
kicad/3d/JST_ZH_B2B-ZR_1x02_P1.50mm_Vertical.step
4.50 x 3.50 x 7.20 mm

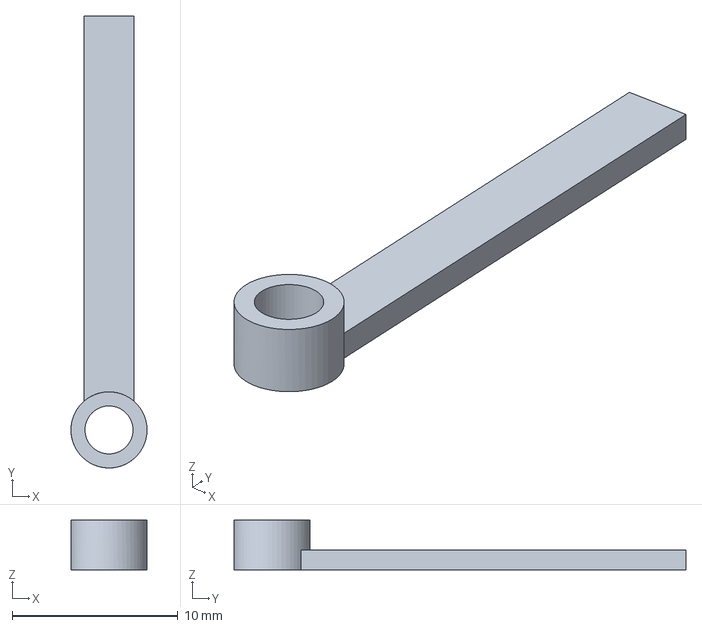
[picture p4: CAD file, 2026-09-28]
cad/hour.FCStd
4.60 x 27.3 x 3.00 mm

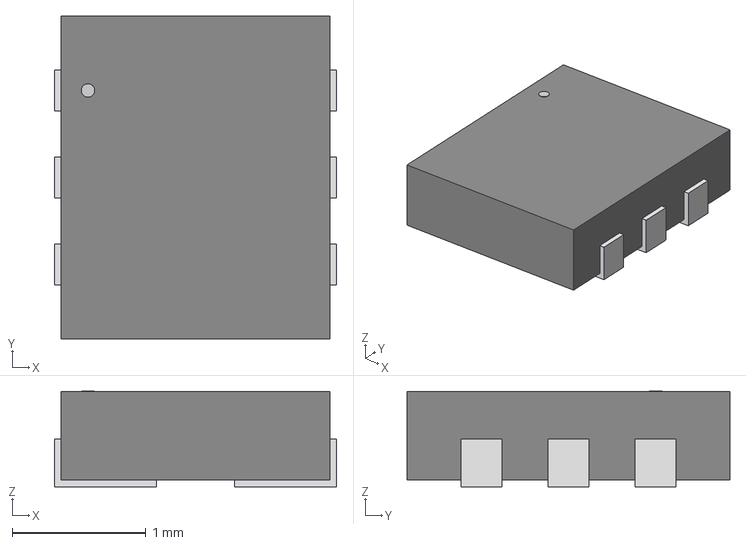
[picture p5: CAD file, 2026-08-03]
kicad-sensor/3d/AMS_TSL25911FN.step
2.11 x 2.41 x 0.714 mm

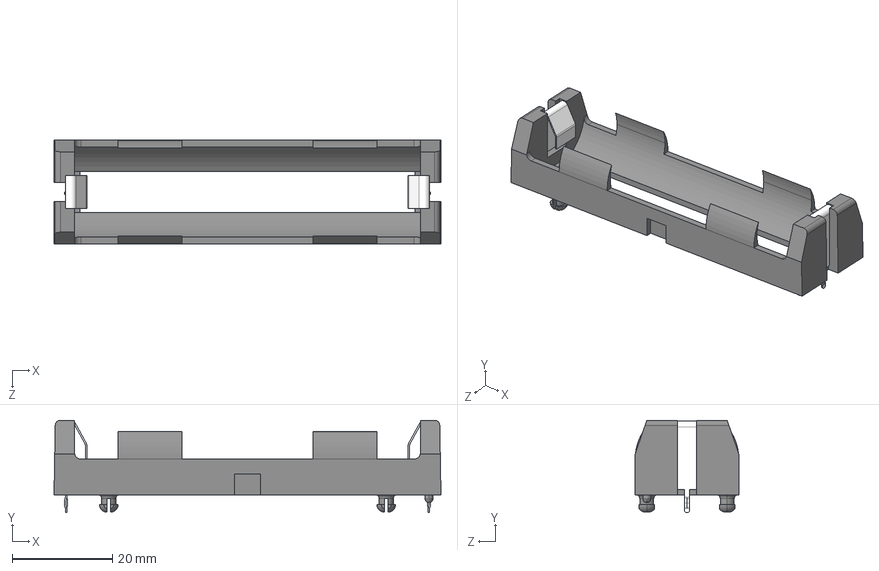
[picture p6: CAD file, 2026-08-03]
kicad/3d/Keystone_1043.step
77.1 x 18.4 x 20.7 mm

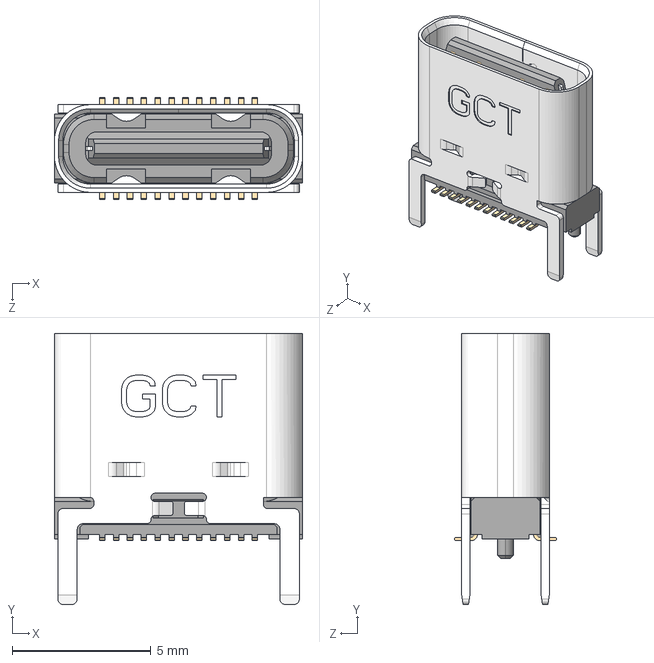
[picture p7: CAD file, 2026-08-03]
kicad/3d/GCT_USB4160-03-0230-C.step
8.95 x 9.76 x 3.69 mm
housing_24P

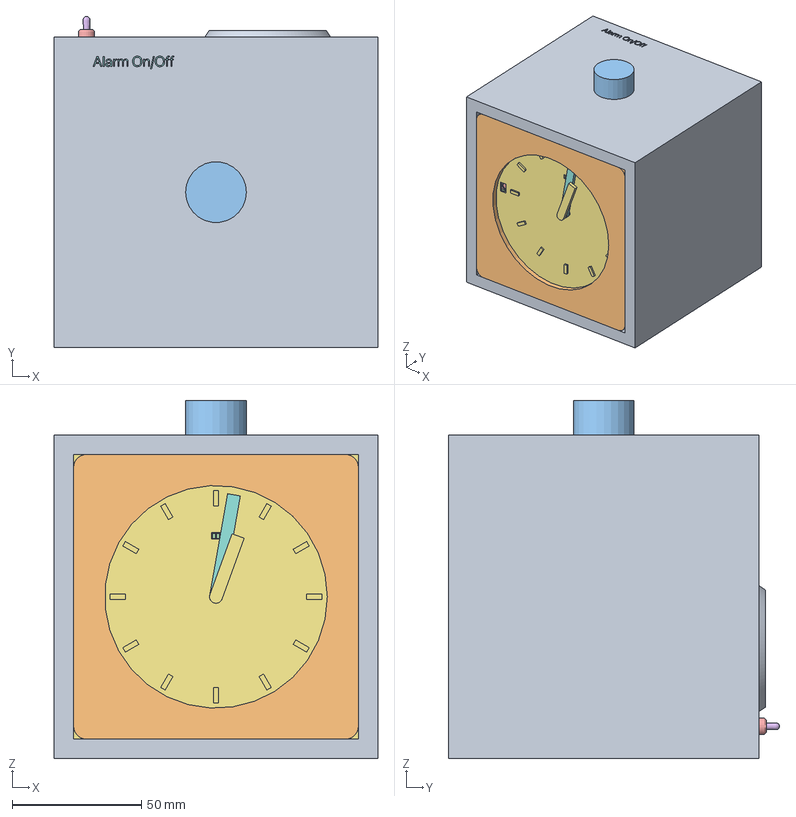
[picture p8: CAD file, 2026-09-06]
cad/clock.FCStd
125.0 x 127.9 x 138.4 mm
Alu
Dial
Encoder
P:\E-Switch Secure\3D_MODELS_STP_FORMAT\100SPxT2B1M1xE.stp
P:\E-Switch Secure\3D_MODELS_STP_FORMAT\100SPxT2B1M1xE.stp001
HourHand
MinuteHand
C_0603_1608Metric
LED_SK6812_PLCC4_50x50mm_P32mm
C_0603_1608Metric002
QRE1113GR
LED_SK6812_PLCC4_50x50mm_P32mm001
JST_B2B_PH_K
L_Coilcraft_XAL4030-XXX
C_0603_1608Metric004
R_0603_1608Metric
R_0603_1608Metric002
C_0805_2012Metric
SOT-23-6
C_0603_1608Metric006
C_0603_1608Metric008
R_0603_1608Metric004
L_Coilcraft_XAL5050-XXX
D_SOD-123
C_0603_1608Metric010
C_0603_1608Metric012
R_0603_1608Metric006
D_SMA
R_0603_1608Metric008
R_0603_1608Metric010
SW_SPST_CK_RS282G05A3
R_0603_1608Metric012
ESP32-S3-WROOM-1
ESP32-S3-WROOM-001
ESP32-S3-WROOM-002
ESP32-S3-WROOM-003
ESP32-S3-WROOM-004
ESP32-S3-WROOM-005
ESP32-S3-WROOM-006
ESP32-S3-WROOM-007
ESP32-S3-WROOM-008
ESP32-S3-WROOM-009
ESP32-S3-WROOM-010
ESP32-S3-WROOM-011
ESP32-S3-WROOM-012
ESP32-S3-WROOM-013
ESP32-S3-WROOM-014
ESP32-S3-WROOM-015
ESP32-S3-WROOM-016
ESP32-S3-WROOM-017
ESP32-S3-WROOM-018
ESP32-S3-WROOM-019
ESP32-S3-WROOM-020
ESP32-S3-WROOM-021
ESP32-S3-WROOM-022
ESP32-S3-WROOM-023
ESP32-S3-WROOM-024
ESP32-S3-WROOM-025
ESP32-S3-WROOM-026
ESP32-S3-WROOM-027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

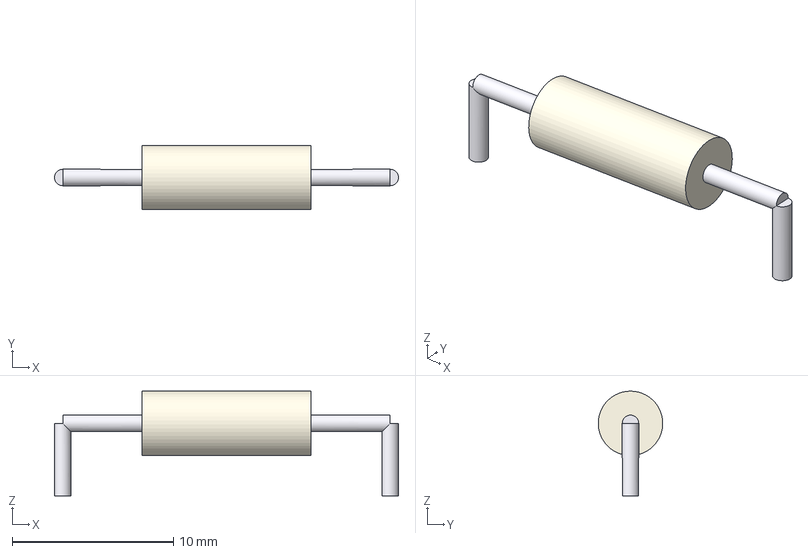
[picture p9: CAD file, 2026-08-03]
kicad/3d/Cantherm_SDF_TCO.step
21.3 x 4.00 x 6.50 mm

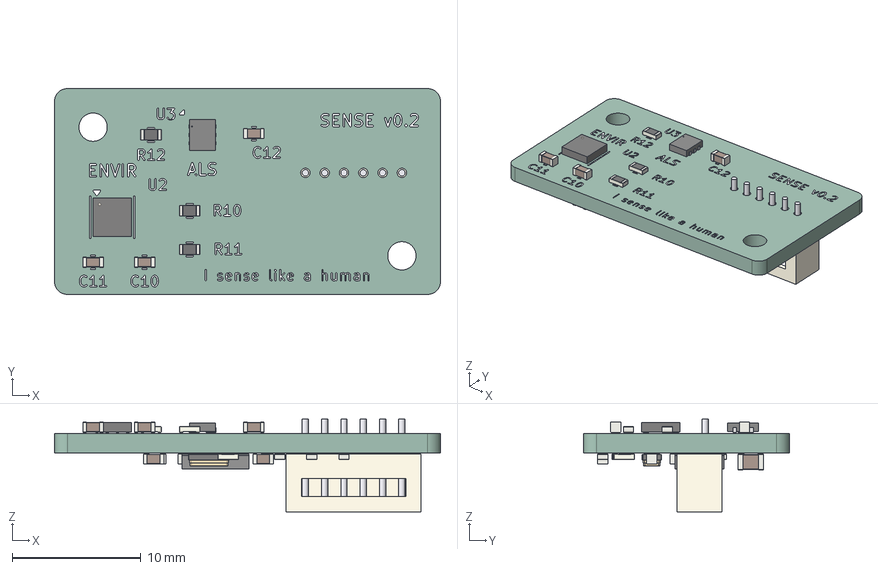
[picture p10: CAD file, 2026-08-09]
cad/pcb_sensor.step
30.0 x 16.0 x 7.20 mm
C_0603_1608Metric x 11
R_0603_1608Metric x 12
Bosch_LGA_8_3x3mm_P08mm_ClockwisePinNumbering
C_0805_2012Metric
BNO085
Crystal_SMD_3215-2Pin_3.2x1.5mm
sensor-unsaved-export-ax41gq_silkscreen x 2
sensor-unsaved-export-ax41gq_PCB

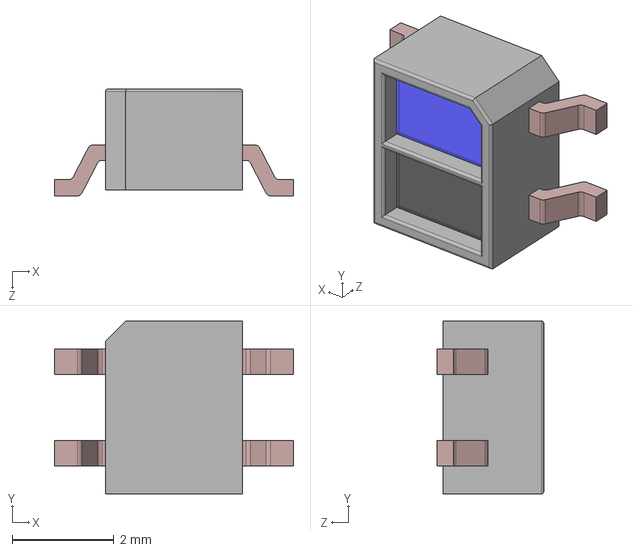
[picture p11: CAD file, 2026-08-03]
kicad/3d/QRE1113GR.step
4.70 x 3.40 x 2.10 mm

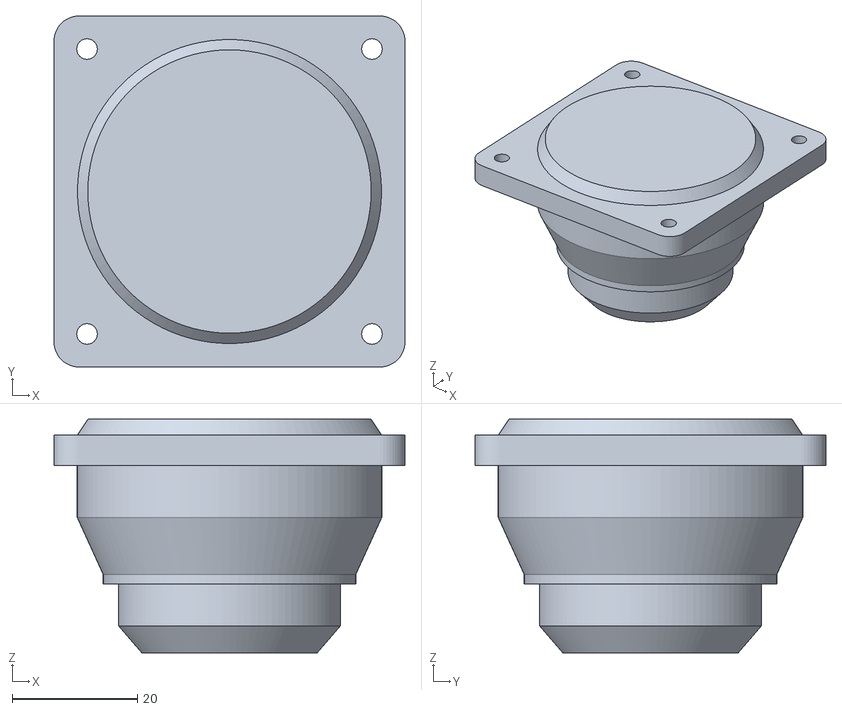
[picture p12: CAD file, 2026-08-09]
cad/speaker_dma58-4.stl
56.0 x 56.0 x 37.3

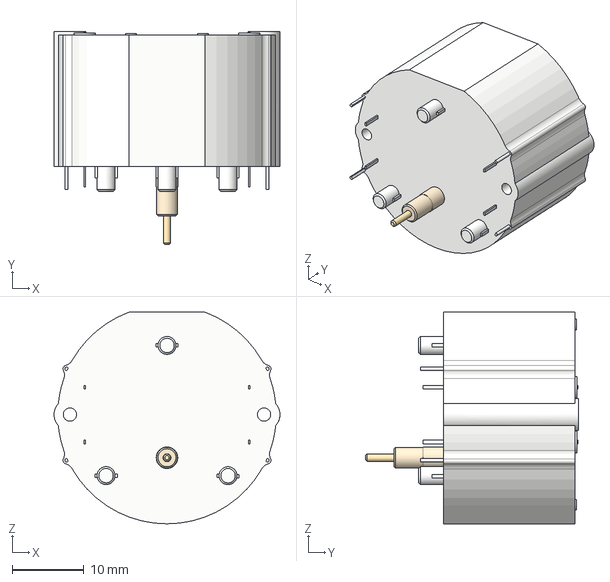
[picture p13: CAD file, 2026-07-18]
kicad/3d/X40_879.step
31.4 x 29.7 x 29.4 mm

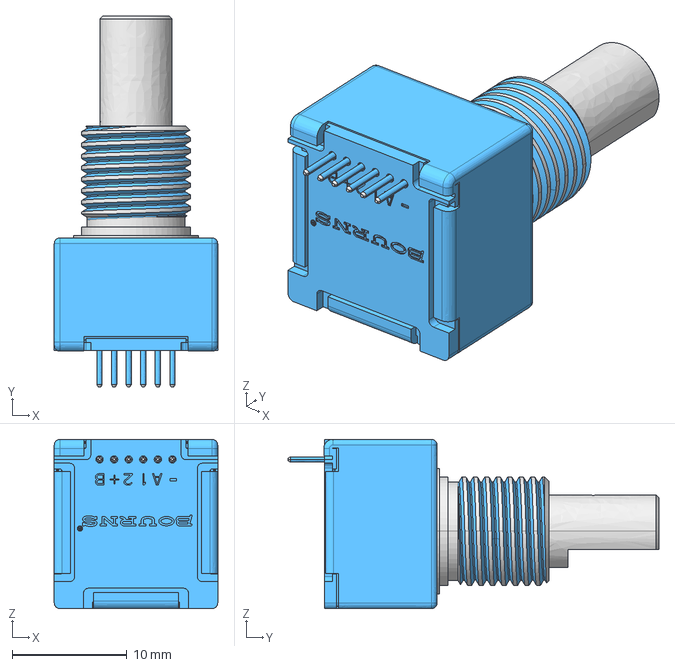
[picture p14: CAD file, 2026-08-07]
cad/encoder.stp
14.2 x 32.3 x 14.8 mm

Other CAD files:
cad/minutes-Body.3mf
kicad/3d/JST_ZH_B6B-ZR_1x06_P1.50mm_Vertical.step
cad/hour-Body.3mf
cad/switch.stp
kicad/3d/FH34SRJ-10S-0.5SH.stp

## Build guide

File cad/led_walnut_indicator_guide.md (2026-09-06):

# Walnut LED Indicator Manufacturing Blueprint

Step-by-step process for casting 6 diffused LED indicators into walnut hardwood.
Shopping list is **Home Depot in-store**; alternatives listed for anything that may not be on the shelf.

**Stock assumption: 6 mm walnut.** See §"Working at 6 mm" before drilling — the thin stock
changes the drill order and gives you a build choice.

---

## 🛒 Shopping List (Home Depot)

| # | Item | Home Depot pick | Aisle | Alternatives |
|---|---|---|---|---|
| 1 | Clear casting epoxy | [TotalBoat Table Top, 1 qt kit](https://www.homedepot.com/p/TOTALBOAT-Table-Top-1-qt-Kit-Clear-High-gloss-Epoxy-Interior-Exterior-Resin-For-Bar-Counter-and-Table-Top-Application-409334/332248285) — 1:1, ~20 min working time, cures hard and sands like acrylic | Paint / epoxy | [SuperClear Table Top](https://www.homedepot.com/p/SuperClear-2-Gal-Table-Top-Epoxy-Resin-and-Activator-141014/321860696) or [WiseBond Deep Pour](https://www.homedepot.com/p/WiseBond-1-5-gal-Clear-Deep-Pour-2-in-Thick-Single-Pour-2-1-Ratio-River-Table-Epoxy-Kit-DW025109/318986737). **Cheap route:** a J-B Weld ClearWeld / Loctite clear 2-part syringe (~$8) — you only need ~0.3 mL total. Trade-off below. |
| 2 | Grain sealer | [Zinsser SealCoat](https://www.homedepot.com/p/Zinsser-1-qt-SealCoat-Universal-Sanding-Sealer-Case-of-6-854/205140204) (dewaxed shellac), 1 qt can | Wood finishes | **Thin CA glue** (Loctite/Gorilla super glue, adhesives aisle) wicked into the bore — arguably better, hardens the end grain too. Or seal with a first wash of *un-tinted* epoxy (§Step 2). |
| 3 | White diffusion pigment | Not reliably stocked — check the epoxy endcap for a white pigment/dry-color pack | Paint / epoxy | **A drop of white latex from a paint sample pot** (~$6, paint desk), or a pinch of **cornstarch / baking soda** from the pantry (free, works fine). |
| 4 | Mold-face tape | **Tuck tape / red sheathing tape** — flat, rigid, epoxy peels off it cleanly | Building materials | Clear packing tape (stretches slightly → a marginally domed face). |
| 5 | Drill bits | [Milescraft 7-pc metric brad point set](https://www.homedepot.com/p/Milescraft-Metric-Brad-Point-Bit-Set-7-Piece-2318/206520373) — has both the 5 mm and the 10 mm | Power tool accessories | A 10 mm **Forstner** for the counterbore if you'd rather not pre-drill (flatter pocket floor). |
| 6 | Sandpaper | 150 / 220 / 400 grit sheets + a **flat rubber sanding block** | Paint | — |

**Do NOT buy a water-repellent deck sealer** (Olympic Waterguard and similar). They are wax/silicone
penetrating repellents that never fully harden — epoxy fisheyes and delaminates on them. Dewaxed
shellac or CA only.

### Epoxy trade-off (item 1)
* **Table-top epoxy** — thin, self-levelling, long open time so bubbles rise out, cures glass-hard,
  sands and polishes cleanly. Being thin, it *will* find any gap in your tape. Best result.
* **5-minute syringe epoxy** — slightly amber, traps bubbles you can't outwait, and sands gummy.
  Acceptable for 6 dots you're going to frost anyway; not if you want optical clarity.

---

## 📏 Working at 6 mm

6 mm is thin, but it's workable — and for an RGBW emitter it's arguably the *right* thickness.
Pick a route before you drill:

### Option A — counterbored, 2 mm plug (bright, fragile)
10 mm relief pocket from the back, 4.0 mm deep, leaving a **2.0 mm** front web. LED nests in the
pocket right behind the plug.
* ✅ Brightest, least epoxy, fastest cure.
* ⚠️ A 2 mm web over a 10 mm pocket is a drum skin. Don't clamp it hard, don't lean on it while
  sanding, and don't run an orbital sander over it.
* ⚠️ **RGBW warning:** with only 2 mm of diffuser you will see the individual red/green/blue/white
  dies as separate coloured spots, especially at low brightness. Mitigate by leaving a **2–3 mm air
  gap** between the emitter and the back of the plug instead of pressing it flush — the gap does more
  for colour mixing than pigment does.

### Option B — straight 6 mm plug, no counterbore (dimmer, robust) ← recommended at 6 mm
Drill 5 mm straight through, fill the full 6 mm, mount the LED behind the board.
* ✅ Board keeps its full strength; nothing to blow through.
* ✅ The 6 mm plug acts as a light pipe — much better colour mixing, no die separation.
* ✅ One drilling operation, no depth stop, no relief pocket.
* ⚠️ ~30–40 % dimmer, and a deeper pour so watch for bubbles. Use less pigment than you think.

> **Note on the emitters:** the clock's status LEDs are SK6812 RGBW **5050 SMD** parts (flat 5×5 mm
> packages), not 5 mm through-hole LEDs. A 5050 has no dome and butts flat against the back of the
> plug — which is why the air gap in Option A matters. Also note a 5 mm THT LED's flange is ~5.4–5.9 mm
> and will *not* push into a 5 mm hole; it has to sit in the pocket (Option A) or behind the board (Option B).

---

## 🛠️ Step-by-Step

### Step 1: Drill
1. Mark the 6 centres. Test the whole sequence on an offcut of the same 6 mm stock first.
2. Clamp a **sacrificial backer board** tight behind the walnut — non-negotiable on thin stock or the
   back face blows out.
3. Drill the **5 mm hole through, from the front face**, with the brad-point bit. ~1500–2000 rpm,
   steady feed. Drilling front-to-back means the crisp visible rim is *cut*, not torn.
4. **Option A only:** flip the board and counterbore 10 mm from the back. The brad point self-centres
   in the 5 mm hole you just made — that's why you drill the small hole first; a 10 mm brad point spur
   driven into solid 6 mm stock will punch straight out the front face. Depth stop at **4.0 mm**.
   Verify on the offcut.

### Step 2: Seal the grain (crucial)
Walnut is open-pored. Unsealed, liquid epoxy wicks sideways into the grain and leaves a permanent
dark "wet" halo around every indicator.
1. Blow out all dust.
2. Wick **dewaxed shellac** or **thin CA** into the bore walls until they're visibly wet. A pipe
   cleaner or a toothpick works better than a spray for a 5 mm hole.
3. Let it dry fully (shellac: ~15 min; CA: a few min, or seconds with accelerator).
4. *Zero-purchase alternative:* pour un-tinted epoxy in, let it soak in and gel (~1 hr), then pour the
   tinted batch on top. The first pass becomes the sealer.

### Step 3: Tape the face
1. Burnish **Tuck tape** hard across the front face over all 6 holes — press the adhesive down around
   every hole rim with a fingernail or a plastic scraper.
2. This tape is the mould wall and it forms the finished front face of every indicator. Any gap here
   leaks thin epoxy under the tape and stains the face.

### Step 4: Mix and tint
1. Mix the epoxy strictly by its ratio — off-ratio epoxy stays tacky forever. You need ~0.3 mL total,
   but most kits won't mix accurately below ~10 mL, so mix 10 mL and waste the rest.
2. Dip a toothpick tip in white pigment (or a pinch of cornstarch) and stir it in **incrementally**.
3. Stop while it's still milky and semi-translucent — cloudy, not opaque. Over-pigmenting kills far
   more light than people expect. Test on the offcut with an actual LED behind it before committing.

### Step 5: Pour and cure
1. Board taped-face-down, flat on the bench.
2. Syringe the tinted epoxy into each hole **from the back**. Overfill slightly — epoxy shrinks a
   little as it cures, and the excess sits on the back where nobody sees it.
3. Pop rising bubbles by **exhaling across the surface** (CO₂ collapses them) or a fast flick of a
   lighter flame. **Not a heat gun** — it will lift your tape and cause a leak.
4. Cure 24 h at room temperature. Don't move the board.

### Step 6: Finish the face
1. Peel the tape. The front face is already flat and glossy — the tape moulded it. There are **no
   raised bumps to sand flush** on this face; the overfill is all on the back.
2. If there's a slight lip or tape texture: **flat sanding block only**, 400 grit, light pressure.
   No orbital sander — cured epoxy is softer than walnut and an orbital will dish the plug concave.
3. Scuff each plug face with **220 grit** on purpose. The frosted finish it leaves measurably improves
   diffusion — this is a feature, not a defect.
4. Back side: knock the overfill down flush-ish with 150 grit so the LED can seat. Cosmetics don't
   matter here.

### Step 7: Install the LEDs
1. **Option A:** seat the emitter in the 10 mm pocket, held **2–3 mm off** the back of the plug (a
   punched foam or card spacer ring does this and doubles as a light dam between neighbouring dots).
2. **Option B:** mount the emitter flat against the back face, centred on the hole.
3. Secure with hot glue or small clips. Light-dam between adjacent indicators if they're close — walnut
   is dark but 2 mm of it is not opaque.

---

## Sources
- [TotalBoat Table Top epoxy, 1 qt — Home Depot](https://www.homedepot.com/p/TOTALBOAT-Table-Top-1-qt-Kit-Clear-High-gloss-Epoxy-Interior-Exterior-Resin-For-Bar-Counter-and-Table-Top-Application-409334/332248285)
- [Zinsser SealCoat dewaxed shellac — Home Depot](https://www.homedepot.com/p/Zinsser-1-qt-SealCoat-Universal-Sanding-Sealer-Case-of-6-854/205140204)
- [Milescraft metric brad point set (5 mm + 10 mm) — Home Depot](https://www.homedepot.com/p/Milescraft-Metric-Brad-Point-Bit-Set-7-Piece-2318/206520373)
- [Home Depot 2-part epoxy resin category](https://www.homedepot.com/b/Paint-Paint-Supplies-Epoxy-Epoxy-Resin/2-Part/N-5yc1vZ2fkpf2zZ1z1cs9t)
- [Home Depot forstner bits](https://www.homedepot.com/b/Tools-Power-Tool-Accessories-Drill-Bits-Forstner-Bits/N-5yc1vZc90r)

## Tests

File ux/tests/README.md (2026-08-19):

# `ux/tests/` — the page, driven for real

Eighty-seven cases that click the actual page in an actual browser, against an actual
`clocksim`, and assert on what the dial shows afterwards. They exist to test the *firmware*
through the surface a person uses, so the rule they are built on is:

> **Nothing here may make the page say something the firmware did not say.**

Concretely:

- **Every gesture is a real DOM event.** Buttons are clicked, the knob is scrolled, hands are
  dragged, sliders are moved, keys are pressed. There is no `evaluate()` that reaches into
  `app.js`, no synthetic call to a handler, no shortcut.
- **Every assertion reads rendered DOM** — pill text, an SVG `rotate()`, a swatch's
  background colour. All of it is written by `onState()`, which runs off a `state` frame.
- **No test opens a socket.** `harness.js` spawns the two processes and never speaks to
  either; the only channel is the browser.

So a red test means the *product* is wrong somewhere between the click and the pixel, and the
job is to work out where — the page, the bridge, or the firmware. Five of the bugs found this
way were in the firmware and one was in the fake HAL; see `FIRMWARE.md` §11.3.

## Run it

```sh
cd ux/tests
npm install                 # once -- @playwright/test only
npx playwright test         # all of it, ~5 min
npx playwright test 03      # one case file
npx playwright test --headed --workers=1     # watch it happen
npx playwright test --ui                     # or step through it
```

It needs `clocksim` built (`cmake --preset host-dev && cmake --build --preset host-dev`) and
uses the **Chrome that is already installed** rather than downloading a private Chromium —
this is a dev tool for one laptop, and `npx playwright install` is a 150 MB answer to a
question nobody asked.

Every test gets its **own** `clocksim` + `uxapp.py` on ports the harness picks, and kills them
afterwards. No test depends on another having run, and none of them touch the pair you have
open in a browser.

Two things the rig passes clocksim, both of them about isolation rather than convenience:

- **`--no-home`.** The product homes on boot (`FIRMWARE.md` §6.1a) and nine seconds of sweeping
  before each of forty cases proves nothing the one case *about* boot homing does not. That
  case asks for the real thing with `test.use({ simArgs: [] })`.
- **`--nvs <a file of its own>`.** Calibration survives a reboot on purpose, so one shared file
  would carry one case's trim into the next. The file is deleted with the rig.

These tests measure a mechanism in **real time**, so they need the machine they run on. On a
laptop busy with something else the whole suite slows down and the timing-sensitive cases start
failing for reasons that have nothing to do with the firmware — if a run goes red in a block,
check what else was running before you go looking in `motion`.

## The cases

| file | what it pins |
|---|---|
| `01-attach` | the page attaches, the pixel names come from `hello`, a fresh boot is dark and unhomed |
| `02-knob-press` | press cycles idle → bell → alarm → clock → volume, each lighting its own status pixel and only that one; long press; the 5 s timeout; a turn in idle is ignored |
| `03-homing` | `home` from a scrambled dial, from a hand parked on the index, from both hands on it; twice over; the fault when a sweep outruns the sensor; `stop` mid-run |
| `04-set-time` | every preset button, `now`, and a typed time put the hands where that time is — 12:30 included |
| `05-follow-release` | released, the clock runs on and the hands do not; the buttons report the firmware and not the last click |
| `06-knob-edit` | one detent is one minute, the hands preview what you are setting, a long press commits, the sensitivity slider changes the ratio, the arrow keys are a detent too |
| `07-power-wake` | the plug toggle, two fast clicks being two flips, the wake light refusing on battery, the low-cell pixel |
| `08-radio-tap` | the rear toggle's polarity and label; a tap lit long enough to see |
| `09-warp-steps` | warp really warps; `jumps per minute` quantises the hands without touching the clock; the tuning sliders reach `motion tune` |
| `10-reset-reboot` | `reset fakes` opens a gap the firmware does not know about; `reboot` loses everything and the page reconnects; a reload loses nothing |
| `11-dial` | dragging a hand does **not** round-trip; the opto meter; the plate turning with yaw; PCNT counts |
| `12-modes` | the UX itself: what each mode's pixel *does* (breathe / steady / a burst of three), what the hands show in each (the 6, the alarm, the time being set, the volume gauge — swept, never across the off-scale 10-to-12), where `clock` opens from, the network lock, the ten-second hold into pairing and the one five-second timeout |
| `13-wind` | winding a time: two full turns of the hour hand in each direction, sampling the minute hand every 10 ms — it must never once go backwards, and it must travel all twenty-four of its own revolutions. Then the same for a knob that is **dragged** rather than stepped, which is the case a finger produces and a stepped test never sees. And the report that ended the bank: **the hands stop when the knob stops** |
| `14-calibration` | the clock finds its own zero and remembers it: a fresh `clocksim` **homes on boot** with nobody clicking anything; the two calibration sliders move one hand each; the trim survives a `reboot` and the next home adopts it; a hand nudged half a degree **trims itself** the next time it crosses the sensor |
| `15-level` | the dial finding up (§6.1d): a cube on its side still reads the time and **nothing moves on screen** — the plate turns one way and the hands turn the other inside it; every face is a whole tick; a lean of twenty degrees is still the same shelf; flat on its back the printed 12 wins; `motion tune level 0` pins it back |

## Two things that look like cheating and are not

**The CLI box.** Some tests type `sim hand m 41` into the page's own command box to place a
hand at an exact angle. That is a control on the page, the line goes through the same
dispatcher every button uses, and the firmware cannot tell it apart from the *scramble*
button — which does the same thing with a random angle. It is used to arrange a starting
position, never to assert one.

**`sim hand` itself.** Moving a hand is reaching into the case: it changes where the hand
*is*, not what the firmware *thinks*. That gap is the input to homing, which is the whole
point. `11-dial` asserts explicitly that it does not round-trip.

## Writing another one

`harness.js` gives each test a `ux` object:

```js
await ux.home();                       // click home, wait for the movement's own answer
await ux.press(120);                   // press & hold, for this many ms
await ux.toMode('setalarm');           // press until the HSM is there
await ux.turn(5);                      // five detents on the knob
await ux.dragHand('m', 200);           // reach in and move a hand (yaw-aware)
await ux.slide('r-vmax', 12000);       // move a slider
await ux.cli('sim warp 60');           // the page's command box

await ux.hands();                      // { h, m } degrees, off the SVG
await ux.usteps();                     // what the firmware thinks it commanded
await ux.resting();                    // ... once they have actually stopped
await ux.startHandWatch();             // then wind, then:
await ux.stopHandWatch();              // which WAY they went -- min/max step, net, angles
await ux.pixel(2);                     // { r, g, b, lit } off the swatch strip
await ux.watch(2, 1500);               // what that pixel DID over 1.5 s (see below)
await ux.watchMany([2,3,4,5,6], 2400); // ... all of them at once, + `identical`
await ux.expectRowDark();              // the whole row out, once the fade has finished
await ux.clock();                      // { h, m, s, paused } off the pill
await ux.expectDialShowsTime();        // does the dial agree with the clock?
```

**Read a pattern, not a pixel.** Every status LED animates now, so `pixel(i)` is a coin
toss: a breathing pixel is genuinely dark twice a cycle and a blinking one is dark most of
the time. `watch()` samples the same swatch — rendered DOM, written only by a state frame —
every 10 ms and reports what it *did*:

| | |
|---|---|
| `peak` | the brightest sample — is it lit at all, and what colour |
| `levels` | how many distinct non-zero values: `1` = square edges, many = a curve |
| `everDark` / `everLit` | did it reach zero / did it light at all |
| `duty` | fraction of samples lit |

So `levels === 1 && everDark` is a **blink**, `levels > 4 && everDark` is a **breath**, and
`levels === 1 && !everDark` is **steady** — the distinction the spec makes, and the one a
single read cannot see. **Watch a breath for most of its cycle**: a 1.2 s window on a 3.2 s
breath can land entirely inside the dark half, and then `peak` is a number about nothing.
No mode blinks any more (§6.6b), so every window here is at least 2.2 s.

`watchMany` samples several pixels in the same window and adds
`identical`, which is the strong form of "in sync": at every sample, all of them agreed.
Sampling five synchronised breaths one after another proves nothing, because each window
lands somewhere else in the cycle.

**Assert on `#m-pos`, not on an angle, when the question is *which way*.** 350° → 10° is +20
or −340 and nothing on the dial distinguishes them; `#m-pos` is the unwrapped microstep count
the firmware commanded, so a sequence of those settles it. `startHandWatch()`/`stopHandWatch()`
sample it every 10 ms and report the most negative single step, the most positive, the net
travel, and every sample as a dial angle — which is how `13-wind` proves a hand never reversed
and how `12-modes` proves the volume gauge never entered the sector that is off its scale.
`resting()` is the other half of that: it reads the position and `motion idle` in **one**
evaluate, because two reads can straddle a state frame and a start position taken six
microsteps before the hand stopped makes every step measured from it wrong.

Two more things that are true of every mode assertion:

- **Exclusivity arrives, it is not instant.** Leaving a mode *fades* its pixel over ~250 ms,
  so for that quarter second two pixels are legitimately lit. Poll for the row to settle.
- **A press decides on release** (except the ten-second hold, which commits while the knob
  is still down) — so `press(1000)` does not change the mode until a second has passed.

Two habits worth keeping:

- **Assert with `expect(locator)` or `expect.poll`, not a bare snapshot.** Everything on this
  page arrives one state frame late at best; a plain read races it. The one place this bit
  hard was a helper that chose its next knob press from a mode pill that had not caught up
  yet — it overshot, edited the wrong thing, and looked exactly like a firmware fault.
- **Allow for the homing offset.** A homed hand sits ~1.75° short of where the firmware
  believes it is, because the rising edge of the index mark is half a mark before its centre.
  It is systematic, identical on both hands, and is what a `motion zero` trim will remove on
  the bench. `kHomeOffsetDeg` is the tolerance to use.

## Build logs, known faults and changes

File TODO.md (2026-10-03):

# TODO — the road to the complete clock (device side)

What is left between today and the product in `README.md` §1, feature by feature, **for the
physical clock only** (firmware + the hardware it waits on). The iOS app is a separate track;
its only link to this list is [`app/PROTOCOL.md`](app/PROTOCOL.md).

- The *ordered* firmware work, with bench procedures, is `FIRMWARE.md` §12.2 — IDs like **F6.1**
  point there. This file is the map; §12.2 is the route.
- Hardware fixes for the next board are `kicad/REVIEW.md` (V1–V18).
- ✅ done · 🟡 partly / built but not verified on the board · ⬜ not started. Update this file in
  the same commit that changes a line's state.

*Last updated 2026-10-02.*

## Next up — the open items, in order

1. **The alarm rings** — schedule in `chrono`, `Ringing` / `Snoozed` in `ui`, snooze (tap / press)
   and dismiss (long press). Today the alarm is stored and shown, and never fires.
2. **Audio for the alarm** — the `audio` AO, a WAV from `storage`, 30 s volume ramp, HPF +
   limiter; the 25 % ceiling stays until **F5.4**. *(Next session: audio requirements.)*
3. **Time survives a reboot** — RTC / 32 kHz retention; today only the offset and the alarm do.
4. **Bench the BLE link on the board** — **F6.1** (iOS + Android, pairing window, reconnect).
5. **Sunrise wake light** — the ramp; `hal::wake` is real (2026-10-01), bench it on the brick.
6. **Power modes + the 48 h backup measurement** — `supervisor`, milestone 8.
7. **Bench Wi-Fi + SNTP (built 2026-09-28), then OTA** — **F6.2**.

## Time

| | Feature | Notes |
|---|---|---|
| ✅ | Hands follow the clock (sweep or tick) | `chrono` → `motion`; `chrono steps` |
| 🟡 | Homing on boot, per-unit zero, auto-home trims, dial re-levelled by gravity | all in firmware; homing bench on the printed hands: **F2.4** |
| 🟡 | Movement: steps/rev, direction, silence | **F2.1** (11 520 on the `.NS` part), **F2.3**; direction ✅ F2.2 |
| ✅ | Set time from the phone: date + UTC + offset, `chrono tz` for DST | 2026-09-28, app/PROTOCOL.md "Keeping time" |
| ✅ | Set time of day with the knob (`clock` mode), refused when the network owns the time | |
| ⬜ | **Time survives a reboot / deep sleep** | RTC + 32.768 kHz crystal retention, milestone 2; today `time_valid` is lost on every reset |
| 🟡 | Wi-Fi (credentials from the app over the bonded BLE link) + SNTP (3 free servers, in order) → the clock sets itself; POSIX TZ zones on-device, default San Francisco | **F6.2** — built + host-tested 2026-09-28, **bench next** |

## Alarm — the product

| | Feature | Notes |
|---|---|---|
| ✅ | Alarm time + arm/disarm: knob, CLI, BLE; persisted in NVS | 2026-09-28 |
| ✅ | **The alarm actually rings** | 2026-09-27: `ui` fires it at the set local minute → `Ringing` / `Snoozed` (§6.6). Still owned by `ui` (§6.6f); `chrono`'s `alarms[8]` table (§6.4) not needed for one week + one override |
| ✅ | Snooze (tap on top via BNO085, or press) and dismiss (long press) | 2026-09-27. Snooze 9 min, auto-dismiss after 15 min unanswered (`Ui::Tuning`, not yet NVS/app-settable). Bench: **F5.7** |
| ✅ | **Weekly schedule** (a time per weekday, each on/off) from the app, NVS; the knob edits **the next alarm only** (one-off, replaces that day, schedule untouched) | 2026-09-30, §6.6f, `domain/alarm.hpp`. Protocol: `chrono alarm week` / `next <hh:mm\|clear>`, snapshot 132 → 150 B (`app/PROTOCOL.md` "Alarm schedule"). Host-tested; iOS week editor + one-off banner built (`app/README.md`). Several independent alarms: not planned |
| ⬜ | Sunrise wake light, 30 min warm→cool before the alarm | `hal::wake` real 2026-10-01 (LEDC 1 kHz on IO45/46, owns `BOOST12_EN`: on with the first non-zero duty, off at 0/0; `denied` without PD_PG; `ui` zeroes it on unplug) — **bench `ui wake` on the 15 V brick**; the 30 min ramp itself is not built. On battery: dim dial-pixel glow instead |
| ✅ | Alarm sound from a file (WAV), volume ramp over 30 s | 2026-09-27: `/sd/tones/*.wav`, 48 kHz mono 16-bit only; `storage` AO + 2 s PSRAM ring; tone chosen by `chrono alarm tone` (NVS); beep fallback. Host-tested; **bench: F5.7** |
| 🟡 | Manage sound files from the app: list, upload, delete, choose the alarm tone | Firmware + protocol done 2026-09-27 (`app/PROTOCOL.md` "Sound files", `blob` characteristic, `storage tones/put/rm`; `clockctl.py put` works as the reference). iOS Sounds tab built (`app/README.md`); bench the transfer rate (**F5.7**) |
| ⬜ | Audio DSP: HPF + limiter (protects the 2″ driver) | `audio dsp`, **F5.6** |
| ⬜ | Lift the 25 % volume ceiling | only after the protector sense loop is measured (**F5.4**, `FIRMWARE.md` R-AUDIO-1) |

## Lights and knob

| | Feature | Notes |
|---|---|---|
| ✅ | Knob HSM: modes, long press, 10 s hold = pairing, 5 s timeout | §6.6 |
| ✅ | Status-pixel animations (five patterns), dial wash, tap acknowledgement | |
| 🟡 | The five status pixels on the `J12` harness | **F3.1** — the on-PCB dial pixels already light |
| 🟡 | Brightness follows the room (TSL2591), dark at night | 2026-09-30, §6.6g: log map 1 lux → 20 % … 50 lux → 100 %, Schmitt + 2 s glide, `ui room` (`floor 0` = dark). Host-tested; **bench: tune the map in a real bedroom, check the row does not light the sensor**; not NVS yet (§7.5) |
| 🟡 | Fault codes on the status row | 2026-09-30, §6.6g: `supervisor` latch (hands → `clock`, charger → `batt`, amp → `vol`), slow red blink, long press in idle / `sys fault ack` acknowledges. Host-tested; **bench: LT3652 `FAULT` quiet plugged with no cell (F1.6)** |

## Power

| | Feature | Notes |
|---|---|---|
| ✅ | Charging + running off the cell (build #1 reworked) | §12.0.17; cell-insertion SOP still needed until v0.4 **V17** |
| 🟡 | Battery / charger status in firmware | `hal::power::read()`; plugged half of the bench check **F1.6** |
| ⬜ | Power modes: battery = quiet, deep-sleep cadence for the hands, low-battery shutdown | `supervisor`, §7.3–7.4, milestone 8 — **the 48 h backup claim is unmeasured** |
| ⬜ | Radio policy on battery (slower advertising / off) | BLE advertises at 1 s whenever the toggle is on |

## Connectivity (device side)

| | Feature | Notes |
|---|---|---|
| 🟡 | BLE link: pairing window, commands, status snapshot | built + host-tested 2026-09-27; **bench it: F6.1** |
| ✅ | Set time / alarm over BLE | 2026-09-28 |
| 🟡 | Wi-Fi + SNTP (app: Clock tab → Wi-Fi; zone rule sent on connect) | **F6.2** — built, not benched |
| ⬜ | Firmware update over the air (OTA) | partition table is ready; `net ota` |
| 🟡 | History log on the SD card: room / light / battery every 5 min, 2 years, ≤ 200 MB, download over `bulk` | **F6.3** — firmware built + host-tested 2026-09-28, bench next |
| ✅ | App: sync the history log and plot it (Swift Charts) | 2026-09-29, `app/README.md` "History" |
| ⬜ | Upload alarm sounds from the phone | `Bulk` characteristic → `storage`; protocol addition |

## Sensors

| | Feature | Notes |
|---|---|---|
| ✅ | BME688, TSL2591, BNO085 drivers; values in the status snapshot | |
| ⬜ | `board` AO: sole I²C owner, sensors on their own cadence, BNO085 tap by interrupt | §6.5; also removes the ~1 s command stall (**F6.4**) |
| ⬜ | Air-quality index (BSEC) | optional, licence-gated |

## Robustness

| | Feature | Notes |
|---|---|---|
| 🟡 | Task watchdog on every AO, reset-reason + coredump report at boot | `supervisor`, §6.8 — TWDT (panic → reboot) + stuck-AO + hands-stall detection built 2026-09-29; `sys coredump info` / `erase` + a boot-banner line when one is on flash, 2026-10-02. **Bench:** force a panic, check the banner + `sys coredump` + `idf.py coredump-info` agree |
| 🟡 | Debug log on the SD card, one file per boot, survives a watchdog reset; **download to the app** (`sys journal files/fetch` over `bulk`) | §9.4a — built + host-tested 2026-09-29, download 2026-10-01; bench next. App Logs tab built 2026-10-02 (`app/PLAN.md`: hardware check left) |
| 🟡 | `sys top`, `sys heap`, `sys ev dump` | 2026-10-02: `sys top [<ms>]` (CPU over a window, stack HW, core), `sys heap` (internal/PSRAM/DMA), the RTC event ring (§6.9, `sys ev dump/clear`, survives a reset). Host-tested + all four profiles build; **bench: read them on the board** (`sys top` is target-only). `sys stat` is still the placeholder (§9.7) |
| ⬜ | One `storage`-owned config (§7.5) instead of ad-hoc NVS keys | keys today: `ui.input`, `ui.week`, `ui.ovr_at`, `ui.ovr_day`, `ui.armed` (`ui.alarm` read once to migrate), `chr.tz`, motion zero/inhibit |
| ✅ | `BOARD=devkit-uart` compiles | **F5.5**, 2026-10-02 — REPL on UART under `CONFIG_ESP_CONSOLE_UART` |
| ⬜ | Flaky host tests (motion AO cases, ~20–30 % of runs) + `test_sim` opto cases broken by the 5 mV span | the opto cases fail on every run since `ed6214f` |

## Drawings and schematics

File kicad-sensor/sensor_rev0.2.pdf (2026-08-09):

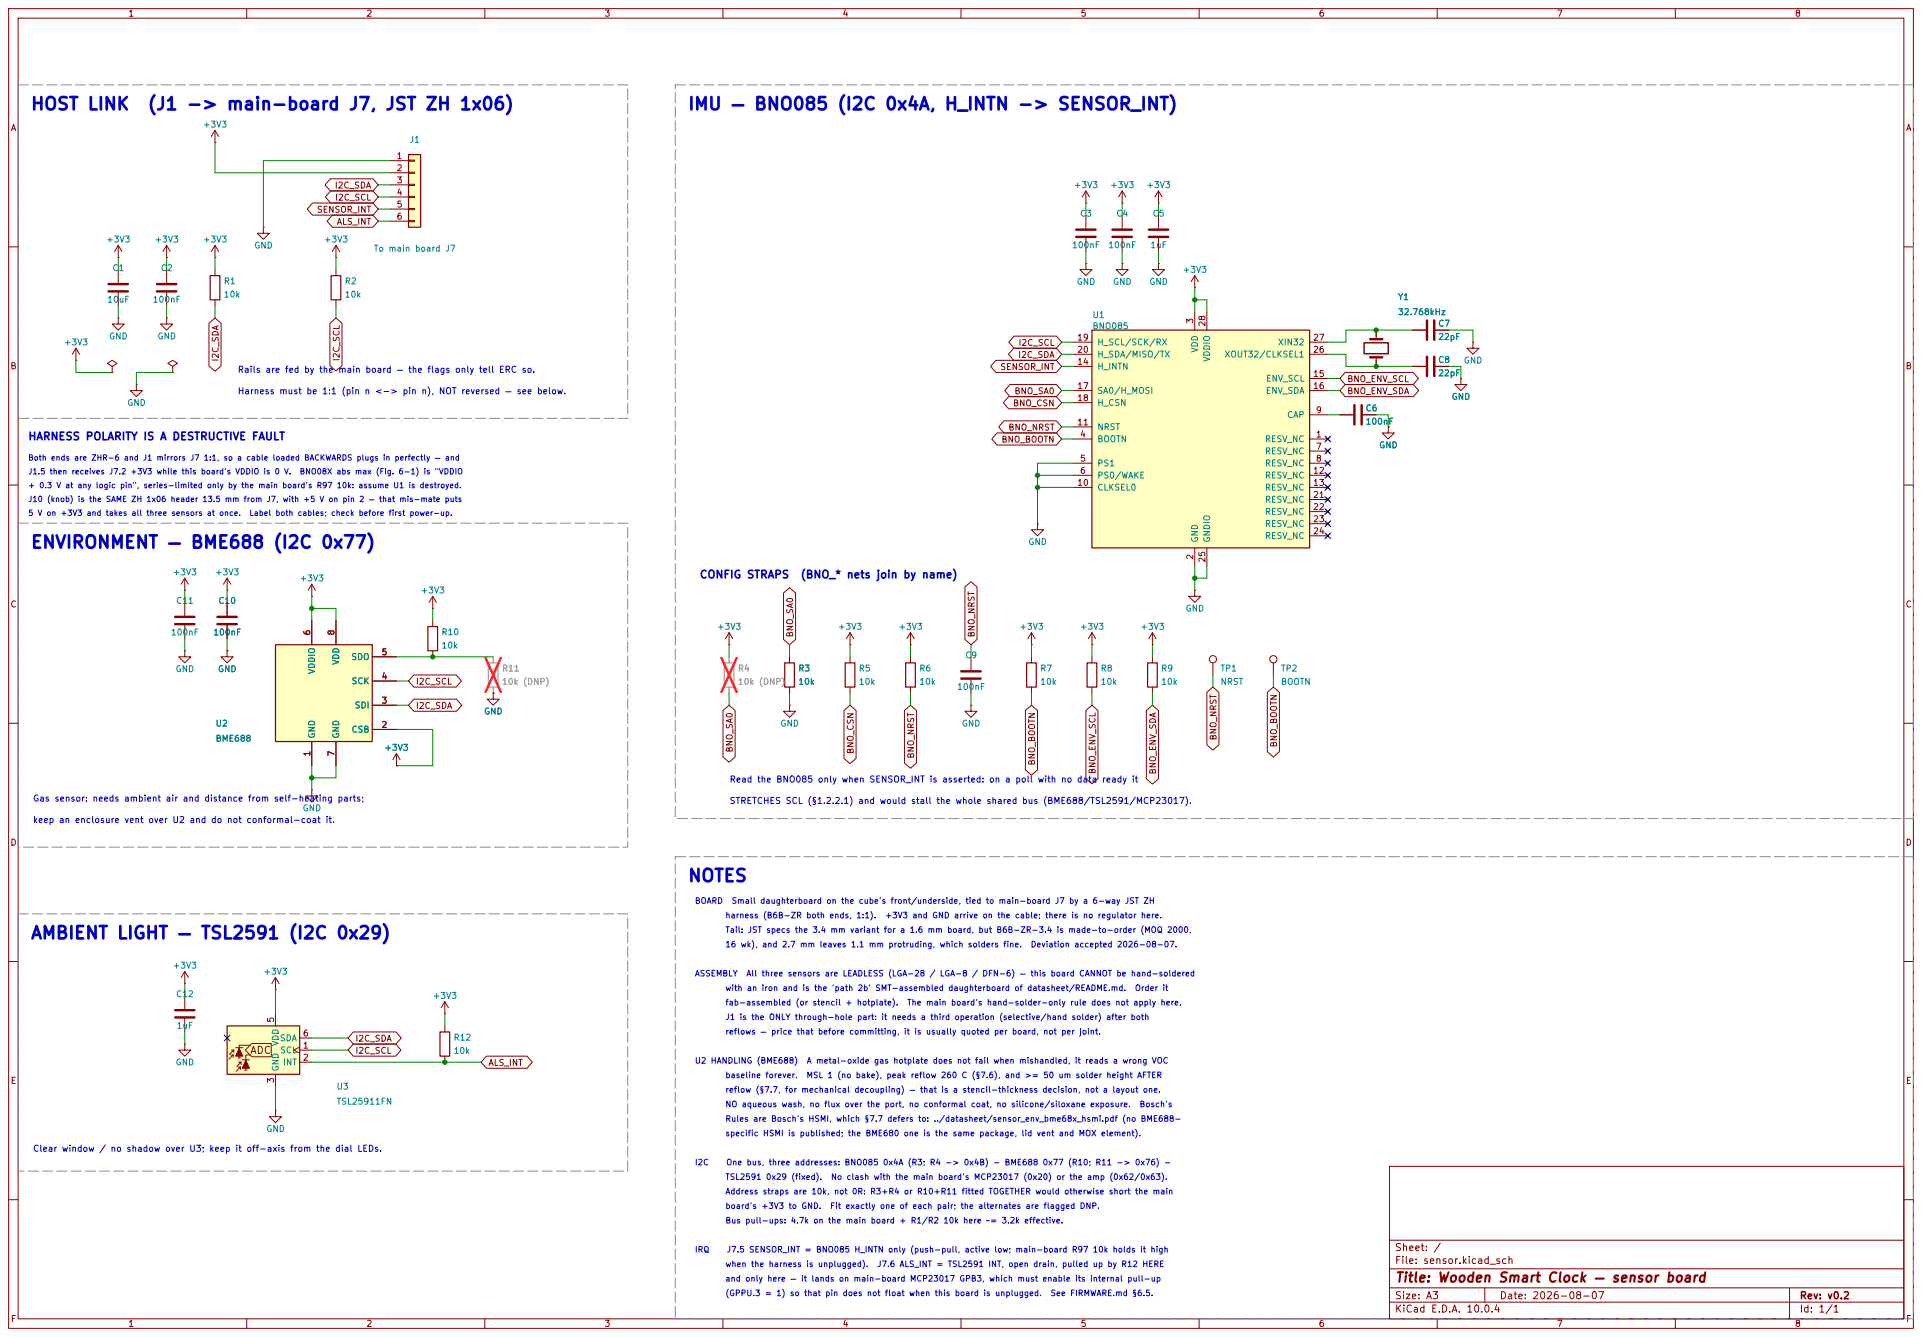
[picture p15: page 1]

3 BOOTN 4 PS1 5 PS0/WAKE 6 RESV_NC 7 RESV_NC 8 CAP 9 CLKSEL0 10 NRST 11 RESV_NC 12 RESV_NC 13 H_INTN 14

+ 0.3 V at any logic pin", series-limited only by the main board's R97 10k: assume U1 is destroyed. Both ends are ZHR-6 and J1 mirrors J7 1:1, so a cable loaded BACKWARDS plugs in perfectly — and HARNESS POLARITY IS A DESTRUCTIVE FAULT

reflows — price that before committing, it is usually quoted per board, not per joint. Clear window / no shadow over U3; keep it off-axis from the dial LEDs. AMBIENT LIGHT — TSL2591 (I2C 0x29)

J1 is the ONLY through-hole part: it needs a third operation (selective/hand solder) after both

U2 HANDLING (BME688) A metal-oxide gas hotplate does not fail when mishandled, it reads a wrong VOC

reflow (§7.7, for mechanical decoupling) — that is a stencil-thickness decision, not a layout one.

Sheet: /
File: sensor.kicad_sch
Title: Wooden Smart Clock — sensor board

Size: A3 | Rev: v0.2
KiCad E.D.A. 10.0.4 | Id: 1/1 | F Date: 2026-08-07

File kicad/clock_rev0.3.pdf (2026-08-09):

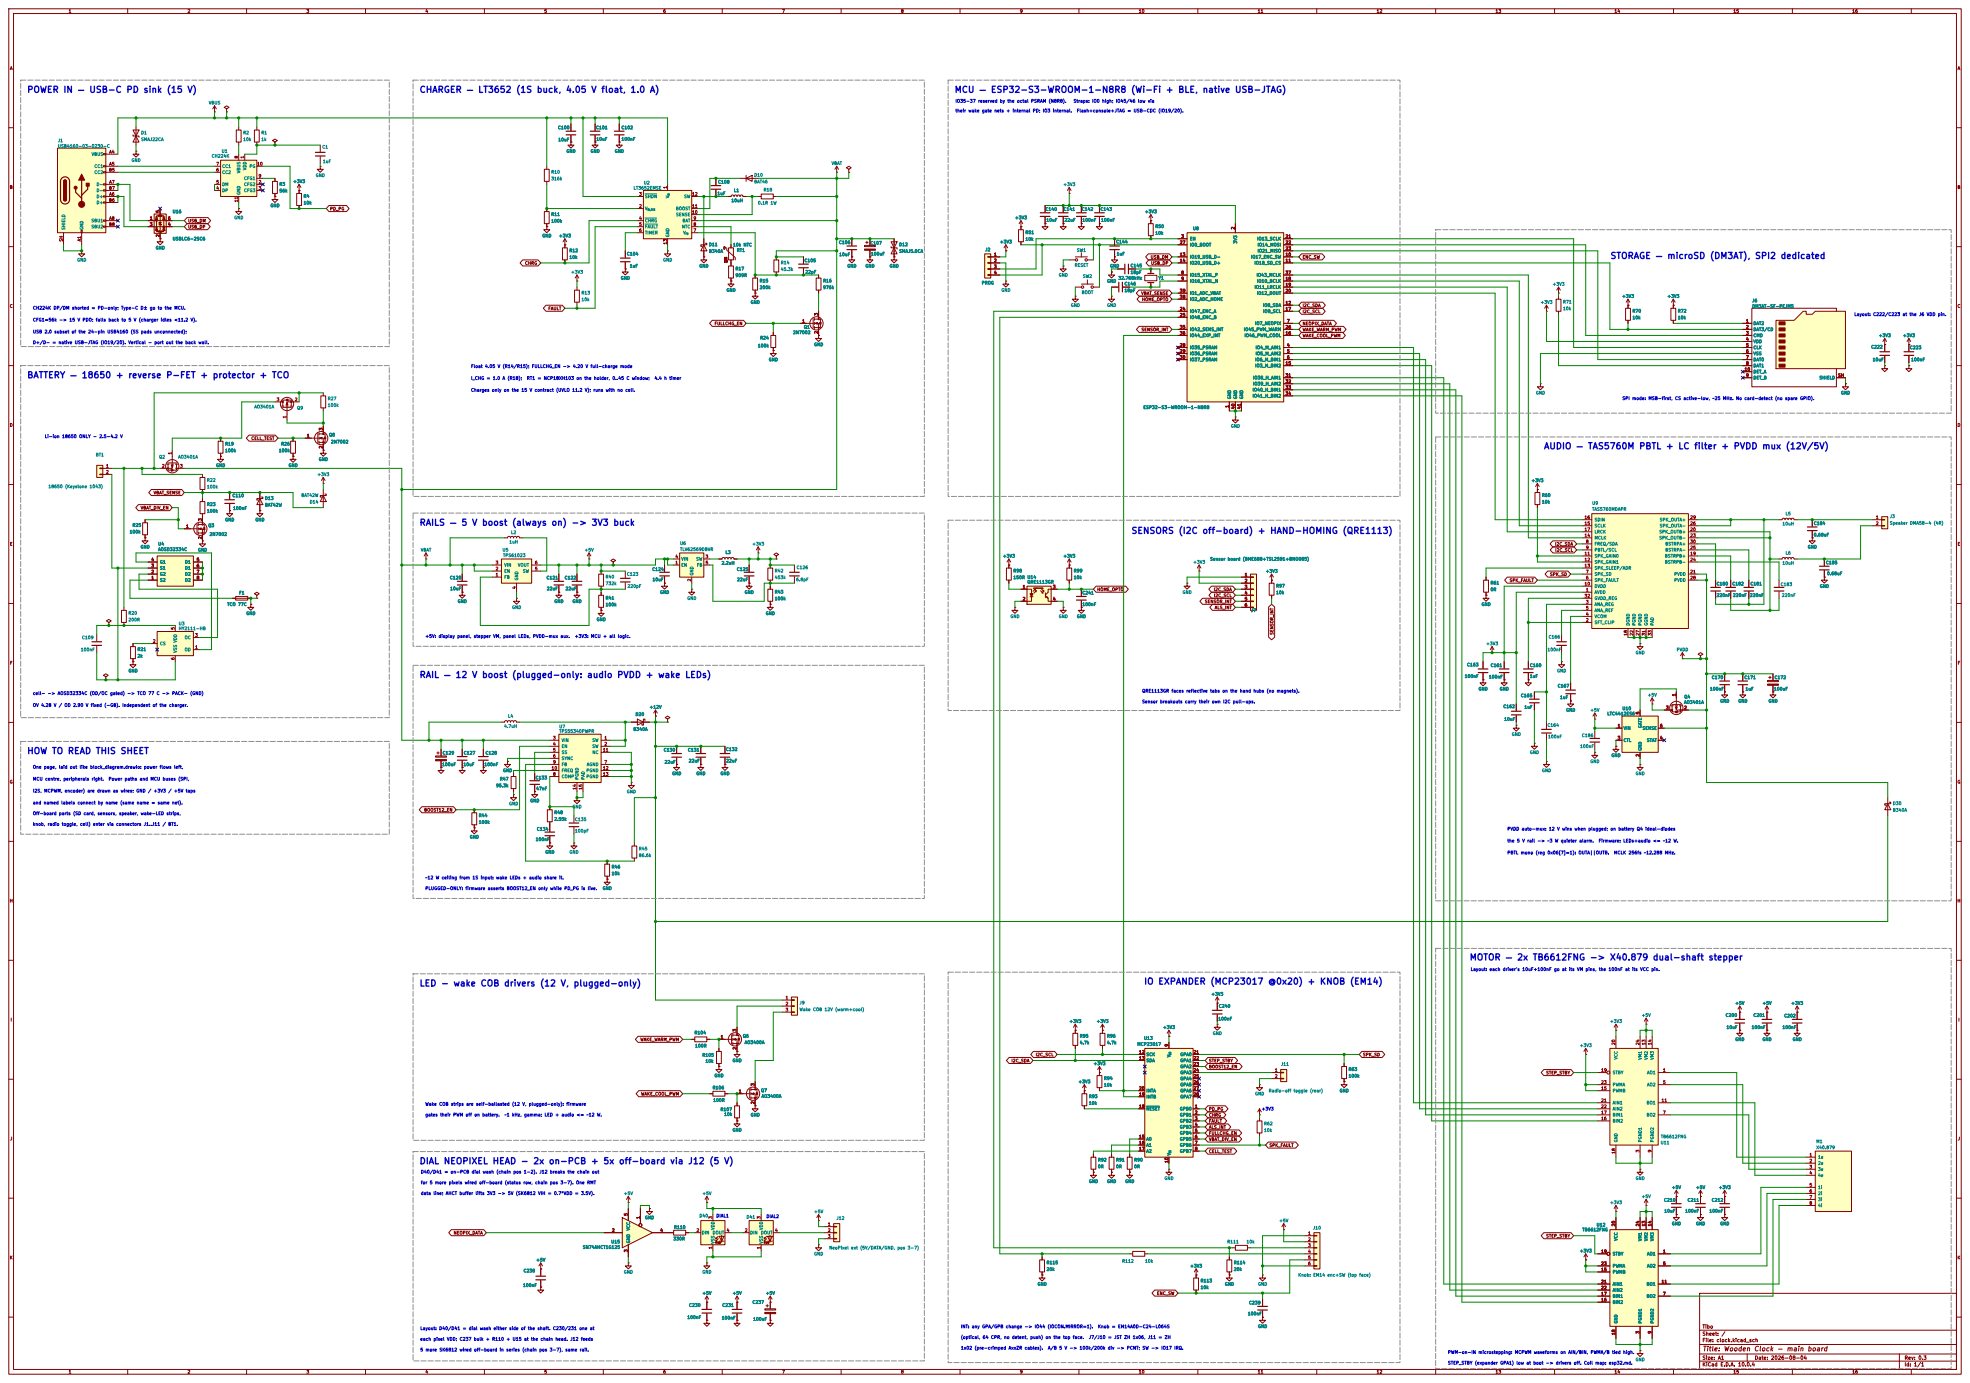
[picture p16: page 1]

POWER IN — USB-C PD sink (15 V)

MCU — ESP32-S3-WROOM-1-N8R8 (Wi-Fi + BLE, native USB-JTAG)

their wake gate nets + internal PD; IO3 internal. Flash+console+JTAG = USB-CDC (IO19/20).

10 10 ENC_SW 11 11

USB 2.0 subset of the 24-pin USB4160 (SS pads unconnected); CH224K DP/DM shorted = PD-only; Type-C D± go to the MCU. CFG1=56k -> 15 V PDO; falls back to 5 V (charger idles <11.2 V).

Layout: C222/C223 at the J6 VDD pin.

D+/D- = native USB-JTAG (IO19/20). Vertical - port out the back wall.

I_CHG = 1.0 A (R18); RT1 = NCP18XH103 on the holder, 0..45 C window; 4.4 h timer Charges only on the 15 V contract (UVLO 11.2 V); runs with no cell. Float 4.05 V (R14/R15); FULLCHG_EN -> 4.20 V full-charge mode

Li-ion 18650 ONLY - 2.5-4.2 V BATTERY — 18650 + reverse P-FET + protector + TCO

33 33
34 34

SPI mode: MSB-first, CS active-low, ~25 MHz. No card-detect (no spare GPIO).

AUDIO — TAS5760M PBTL + LC filter + PVDD mux (12V/5V)

RAILS — 5 V boost (always on) -> 3V3 buck

SENSORS (I2C off-board) + HAND-HOMING (QRE1113)

ANA_REF 5 | 100nF | 220nF Q4

+5V: display panel, stepper VM, panel LEDs, PVDD-mux aux. +3V3: MCU + all logic. PLUGGED-ONLY: firmware asserts BOOST12_EN only while PD_PG is live. DIAL NEOPIXEL HEAD - 2x on-PCB + 5x off-board via J12 (5 V)

RAIL — 12 V boost (plugged-only: audio PVDD + wake LEDs)

cell- -> AOSD32334C (OD/OC gated) -> TCO 77 C -> PACK- (GND)

Sensor breakouts carry their own I2C pull-ups. QRE1113GR faces reflective tabs on the hand hubs (no magnets).

MCU centre, peripherals right. Power paths and MCU buses (SPI, OV 4.28 V / OD 2.90 V fixed (-GB). Independent of the charger.

HOW TO READ THIS SHEET

One page, laid out like block_diagram.drawio: power flows left,

and named labels connect by name (same name = same net).

BOOST12_EN LED - wake COB drivers (12 V, plugged-only)

knob, radio toggle, cell) enter via connectors J1..J11 / BT1.

PVDD auto-mux: 12 V wins when plugged; on battery Q4 ideal-diodes

the 5 V rail -> ~3 W quieter alarm. Firmware: LEDs+audio <= ~12 W. IO EXPANDER (MCP23017 @0x20) + KNOB (EM14)

PBTL mono (reg 0x06[7]=1): OUTA||OUTB. MCLK 256fs ~12.288 MHz.

MOTOR — 2x TB6612FNG -> X40.879 dual-shaft stepper

Layout: each driver's 10uF+100nF go at its VM pins, the 100nF at its VCC pin.

gates their PWM off on battery. ~1 kHz, gamma; LED + audio <= ~12 W.

D40/D41 = on-PCB dial wash (chain pos 1-2). J12 breaks the chain out

data line; AHCT buffer lifts 3V3 -> 5V (SK6812 VIH = 0.7*VDD = 3.5V).

INT: any GPA/GPB change -> IO44 (IOCON.MIRROR=1). Knob = EM14A0D-C24-L064S

Layout: D40/D41 = dial wash either side of the shaft. C230/231 one at

Tibo
Sheet: /
File: clock.kicad_sch
Title: Wooden Clock - main board

each pixel VDD; C237 bulk + R110 + U15 at the chain head. J12 feeds

(optical, 64 CPR, no detent, push) on the top face. J7/J10 = JST ZH 1x06, J11 = ZH

5 more SK6812 wired off-board in series (chain pos 3-7), same rail.

1x02 (pre-crimped AxxZR cables). A/B 5 V -> 100k/200k div -> PCNT; SW -> IO17 IRQ.

STEP_STBY (expander GPA1) low at boot -> drivers off. Coil map: esp32.md. PWM-on-IN microstepping: MCPWM waveforms on AIN/BIN, PWMA/B tied high.

Size: A1 | Rev: 0.3
KiCad E.D.A. 10.0.4 | Id: 1/1

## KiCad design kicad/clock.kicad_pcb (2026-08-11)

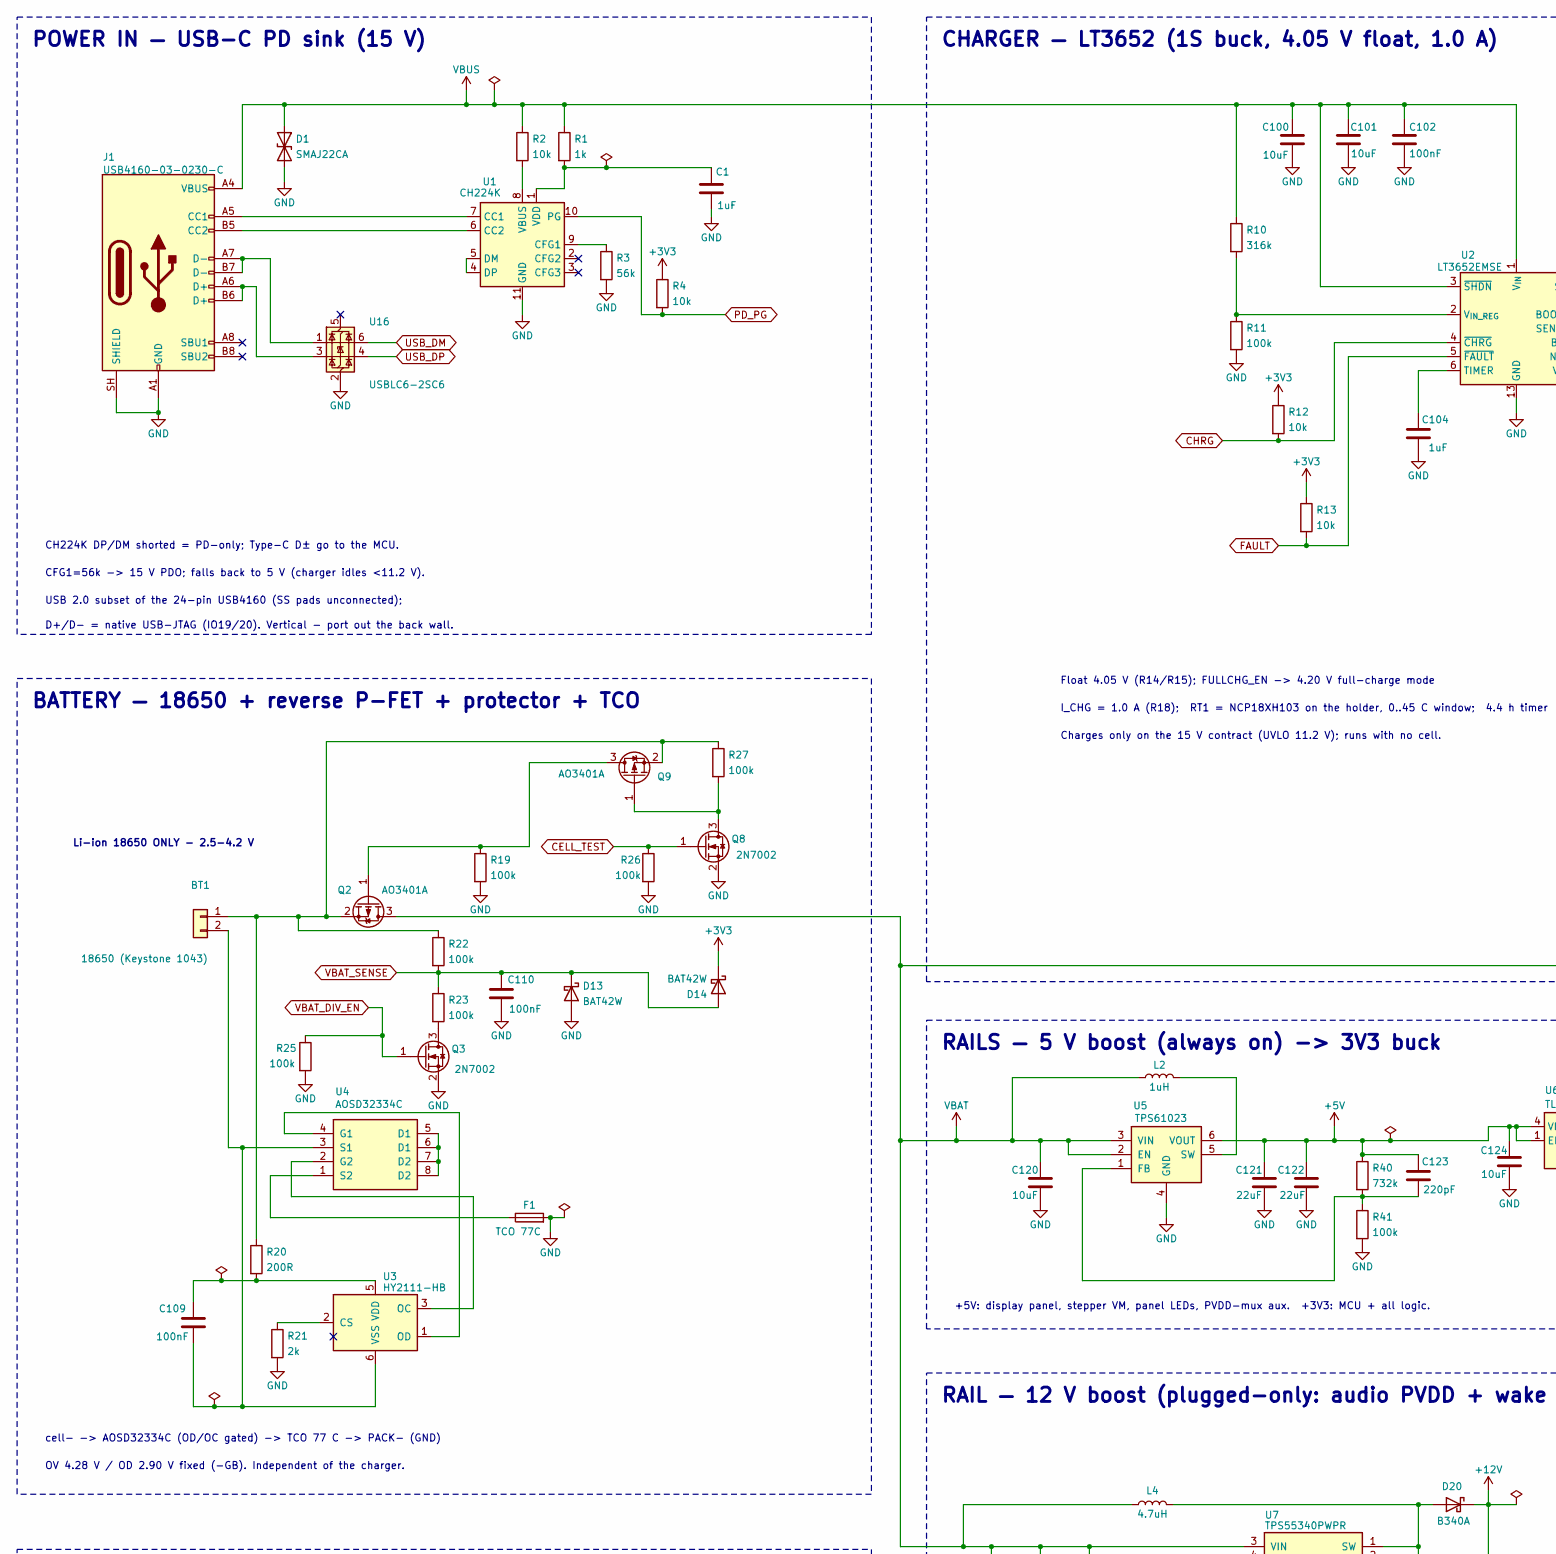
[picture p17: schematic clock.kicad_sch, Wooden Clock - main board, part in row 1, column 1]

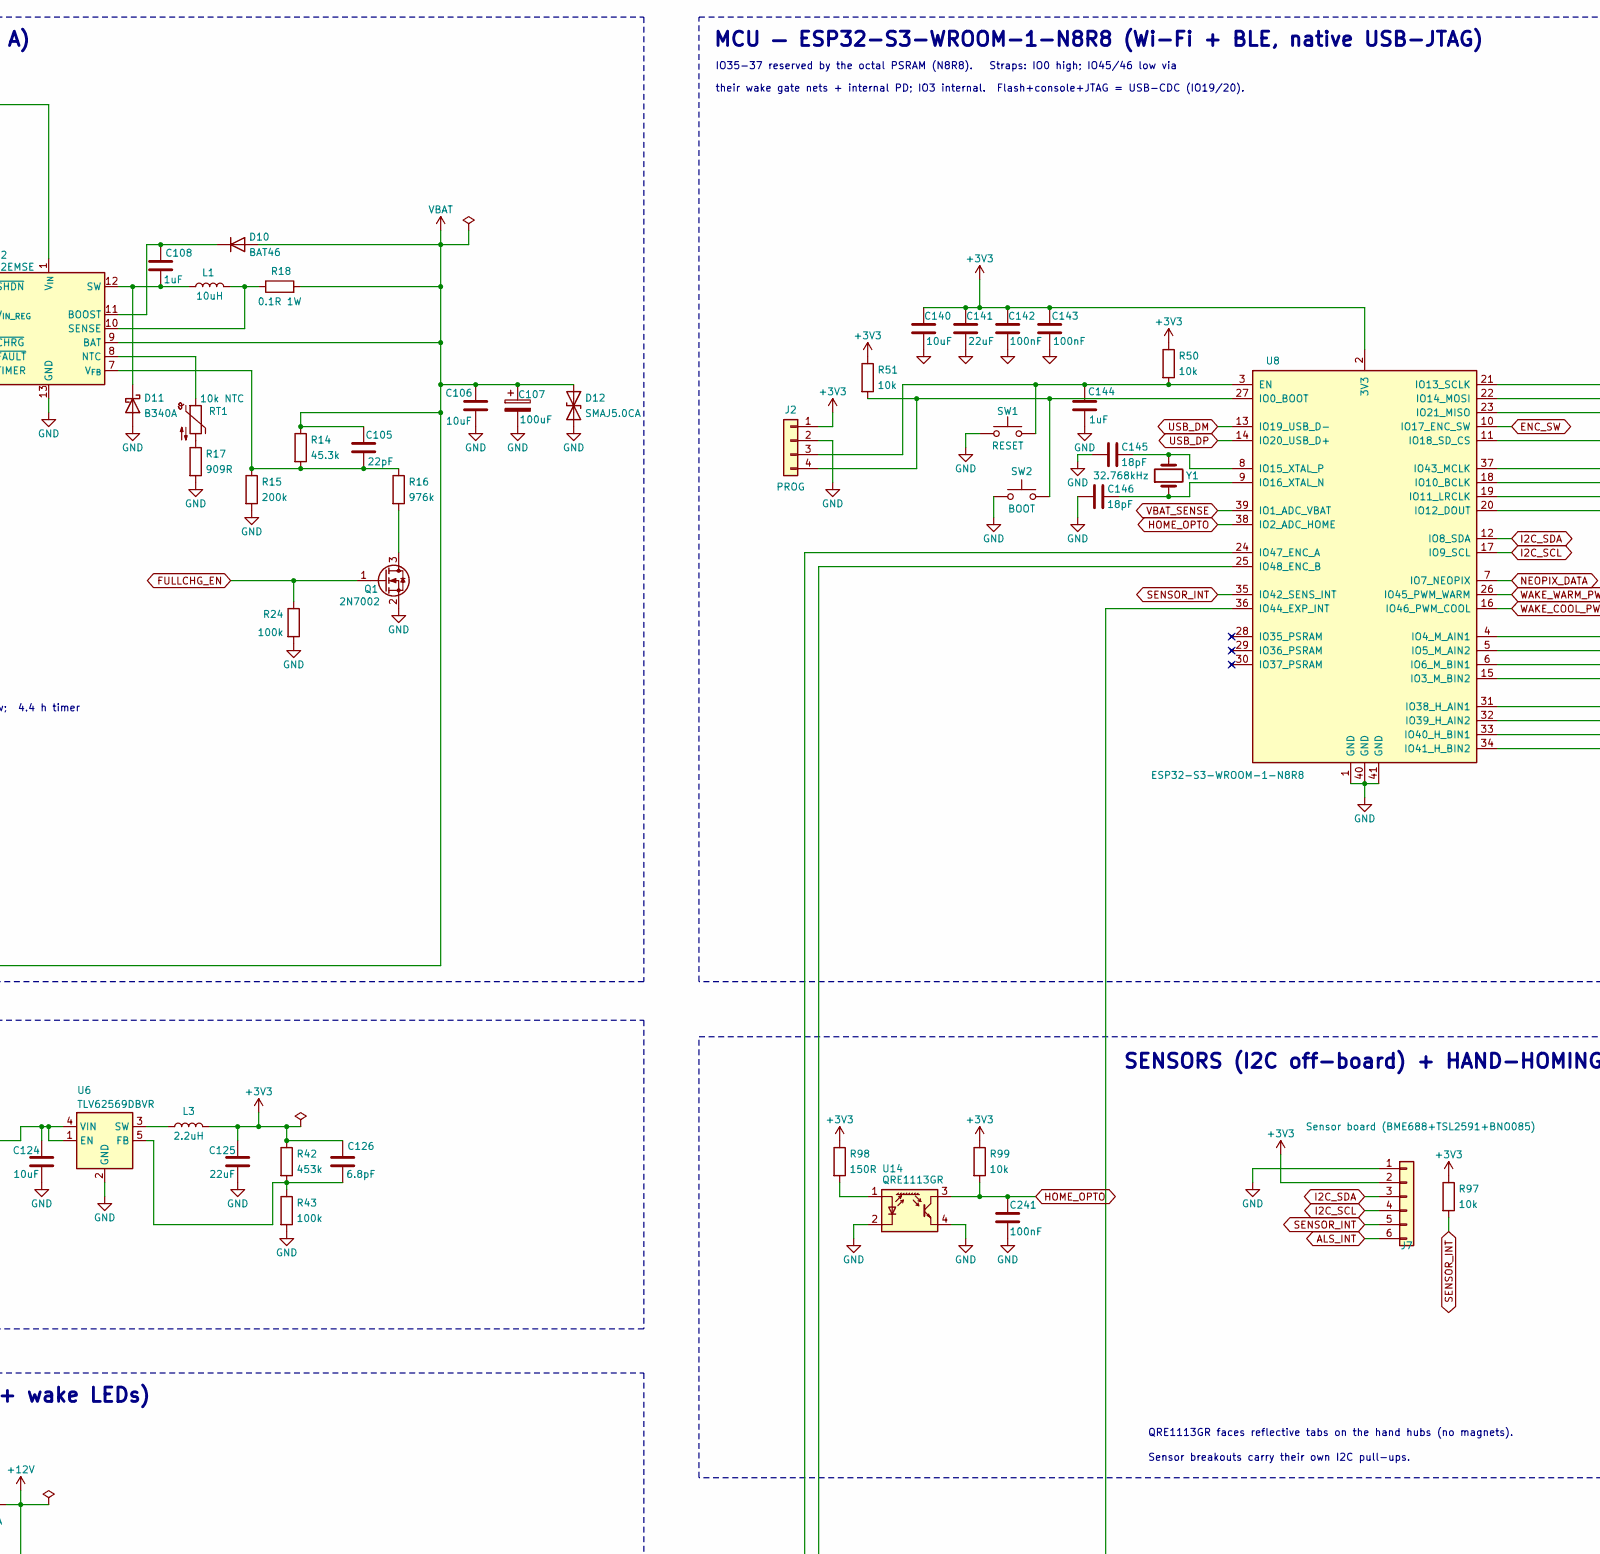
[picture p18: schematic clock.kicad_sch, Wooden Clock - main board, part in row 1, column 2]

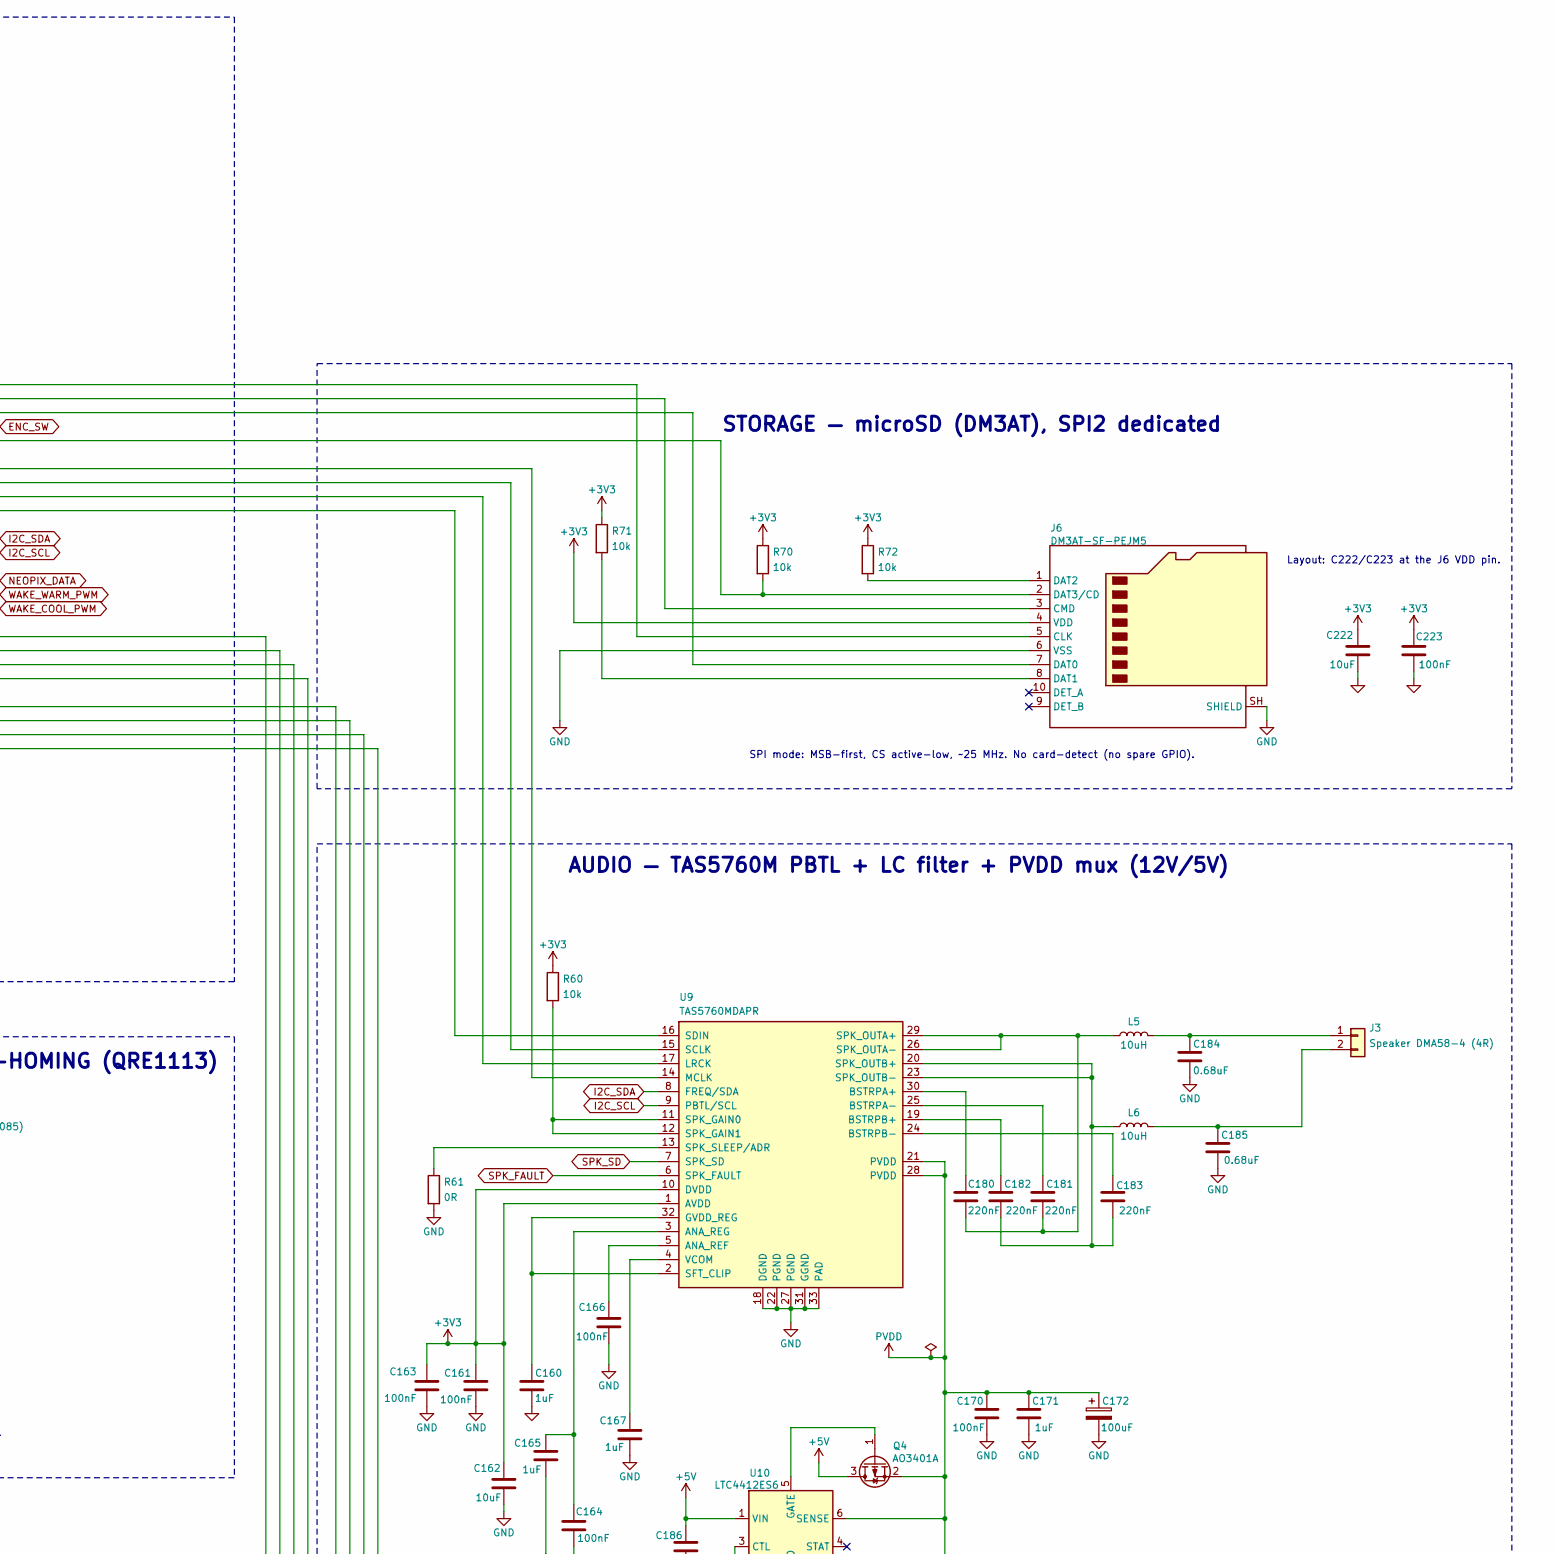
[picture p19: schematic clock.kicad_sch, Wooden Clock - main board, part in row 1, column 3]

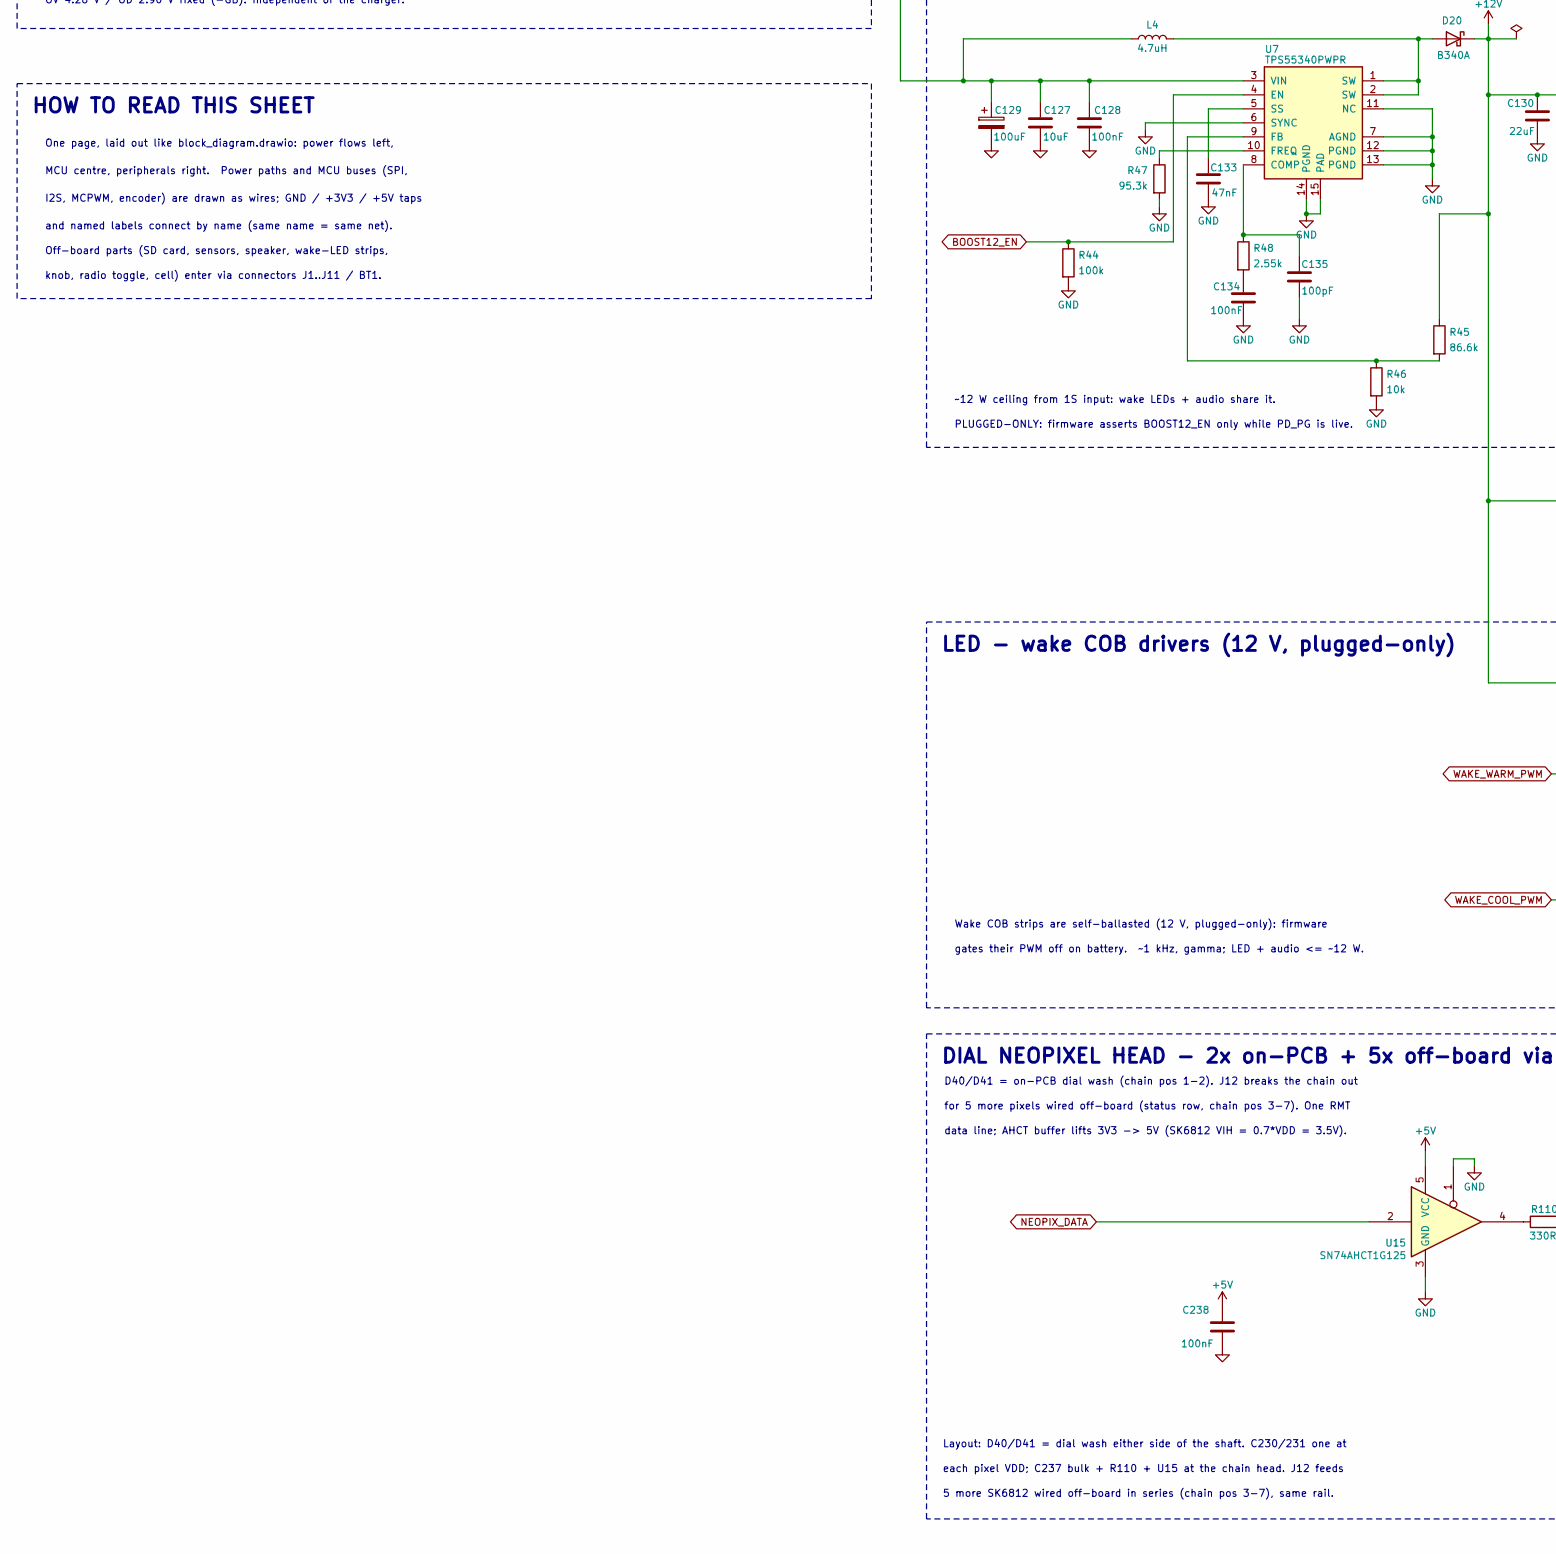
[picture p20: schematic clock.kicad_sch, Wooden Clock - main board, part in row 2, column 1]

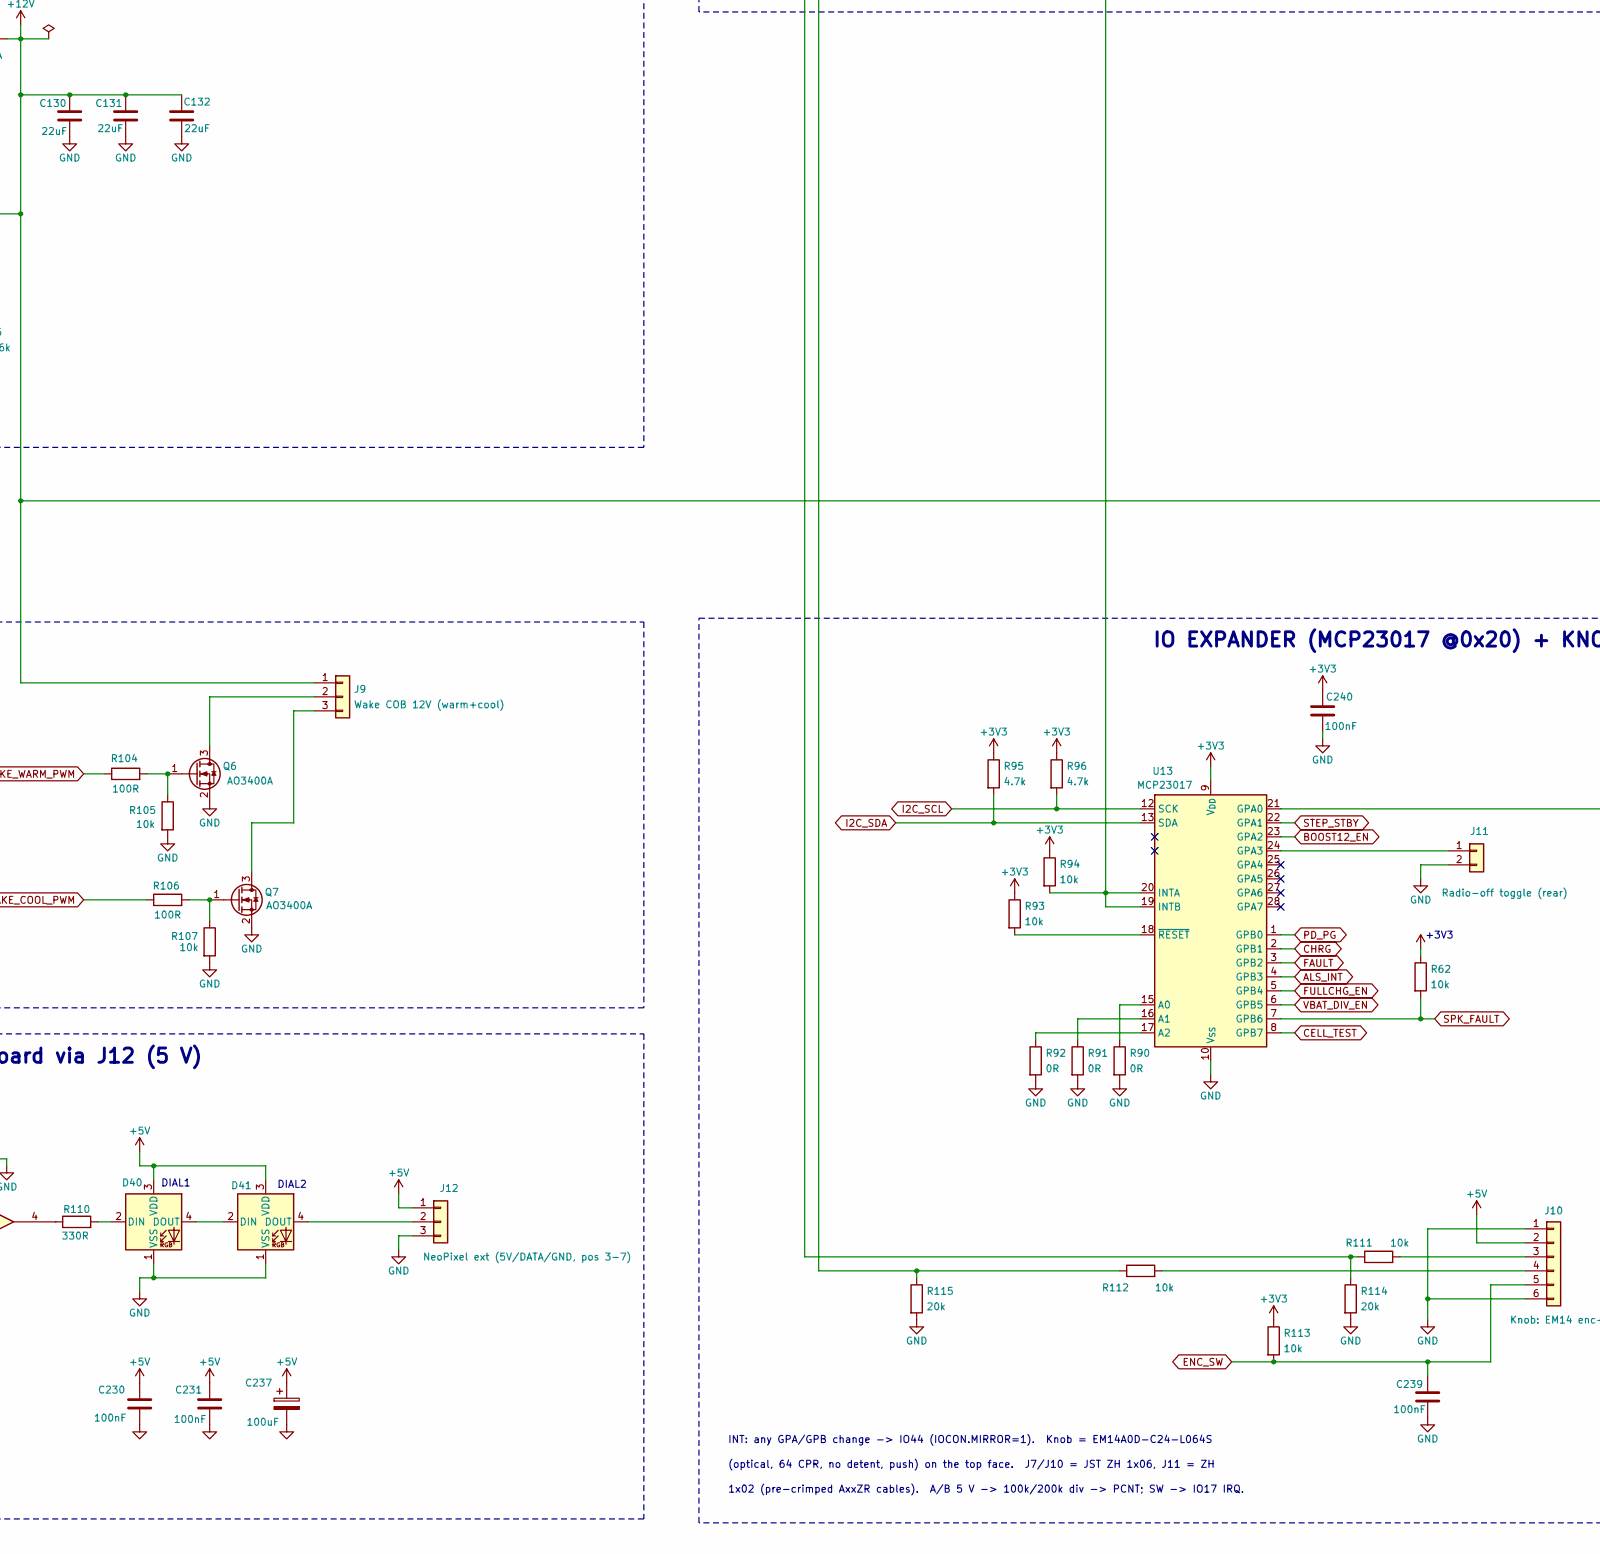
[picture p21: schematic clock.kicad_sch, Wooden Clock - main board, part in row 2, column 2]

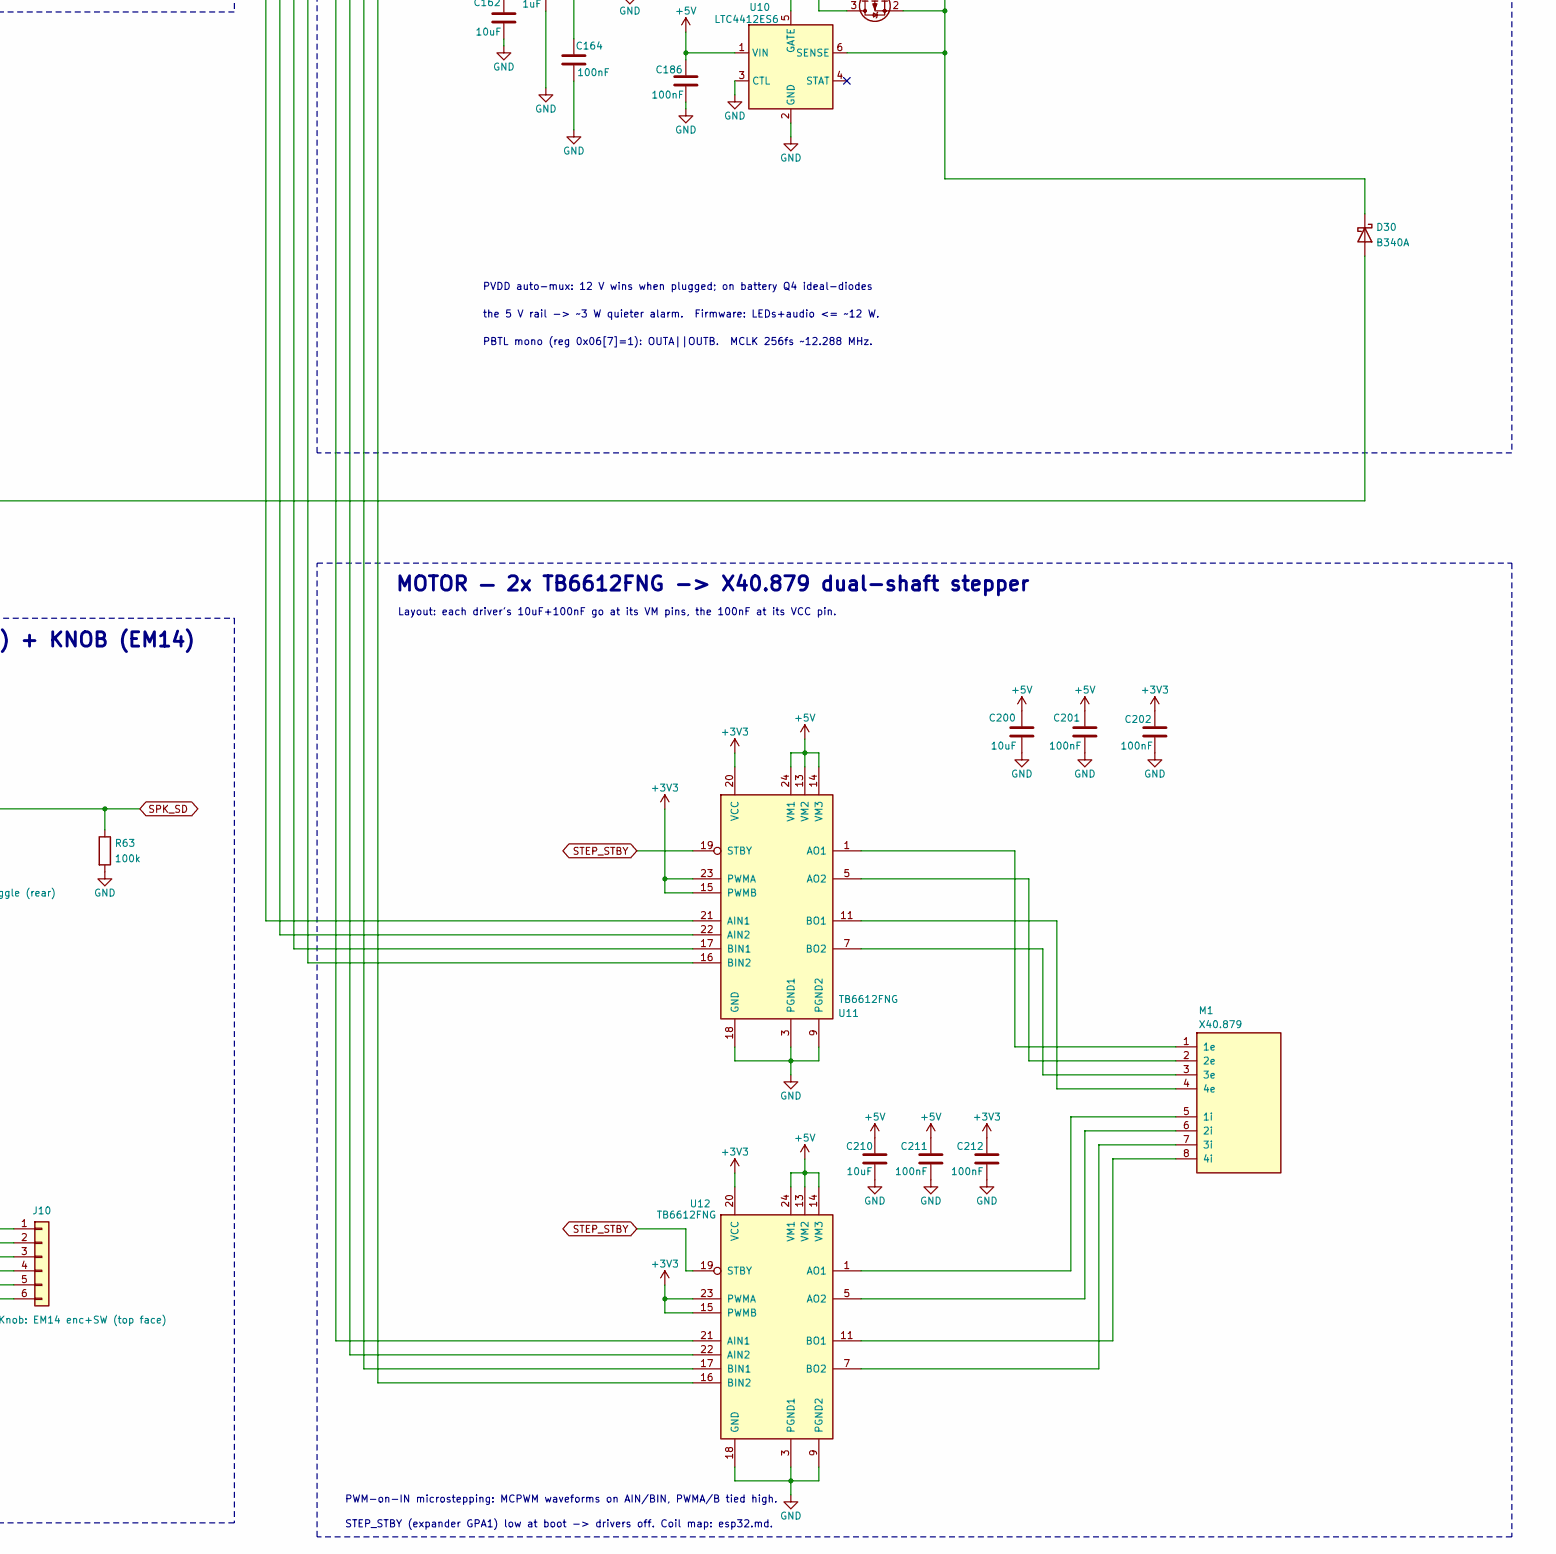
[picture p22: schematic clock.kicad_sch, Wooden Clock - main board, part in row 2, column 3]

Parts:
BT1: 18650 (Keystone 1043); BatteryHolder_Keystone_1043_1x18650; MPN 1043
C1, C104, C108, C144, C160, C165, C167, C171: 1uF; C_0603_1608Metric; MPN CL10B105KA8NNNC
C100, C101, C106, C120, C124, C127, C140, C162, C200, C210, C222: 10uF; C_0805_2012Metric; MPN CL21A106KAYNNNE
C102, C109, C110, C128, C134, C142, C143, C161, C163, C164, C166, C170, C186, C201, C202, C211, C212, C223, C230, C231, C238, C239, C240, C241: 100nF; C_0603_1608Metric; MPN CL10B104KB8NNNC
C105: 22pF; C_0603_1608Metric; MPN CL10C220JB8NNNC
C107, C129, C237: 100uF; CP_Elec_6.3x7.7; MPN EEE-FK1C101P
C121, C122, C125, C141: 22uF; C_0805_2012Metric; MPN CL21A226MOQNNNE
C123: 220pF; C_0603_1608Metric; MPN CL10C221JB8NNNC
C126: 6.8pF; C_0603_1608Metric; MPN CL10C6R8BB8NNNC
C130, C131, C132: 22uF; C_1210_3225Metric; MPN GRM32ER71E226KE15L
C133: 47nF; C_0603_1608Metric; MPN CL10B473KB8NNNC
C135: 100pF; C_0603_1608Metric; MPN CL10C101JB8NNNC
C145, C146: 18pF; C_0603_1608Metric; MPN CL10C180JB8NNNC
C172: 100uF; CP_Elec_6.3x7.7; MPN EEH-ZA1E101XP
C180, C181, C182, C183: 220nF; C_0603_1608Metric; MPN CL10B224KA8NNNC
C184, C185: 0.68uF; C_0805_2012Metric; MPN C0805C684K5RACTU
D1: SMAJ22CA; D_SMA; MPN SMAJ22CA
D10: BAT46; D_SOD-123; MPN BAT46W-E3-08
D11, D20, D30: B340A; D_SMA; MPN B340A-13-F
D12: SMAJ5.0CA; D_SMA; MPN SMAJ5.0CA
D13, D14: BAT42W; D_SOD-123; MPN BAT42W-E3-08
D40, D41: SK6812RGBW; LED_SK6812_PLCC4_5.0x5.0mm_P3.2mm; MPN SK6812RGBW
F1: TCO 77C; Fuse_TCO_Cantherm_SDF_L10.5mm_D4.0mm_P20.32mm_Horizontal; MPN SDF-DF077S
J1: USB4160-03-0230-C; GCT_USB4160-03-0230-C_USB_C_Vertical; MPN USB4160-03-0230-C
J2: PROG; PinHeader_1x04_P2.54mm_Vertical; MPN PRPC004SAAN-RC
J3: Speaker DMA58-4 (4R); JST_PH_B2B-PH-K_1x02_P2.00mm_Vertical; MPN B2B-PH-K-S(LF)(SN)
J6: DM3AT-SF-PEJM5; microSD_HC_Hirose_DM3AT-SF-PEJM5; MPN DM3AT-SF-PEJM5
J7: Sensor board (BME688+TSL2591+BNO085); JST_ZH_B6B-ZR_1x06_P1.50mm_Vertical; MPN B6B-ZR(LF)(SN)
J9: Wake COB 12V (warm+cool); JST_PH_B3B-PH-K_1x03_P2.00mm_Vertical; MPN B3B-PH-K-S(LF)(SN)
J10: Knob: EM14 enc+SW (top face); JST_ZH_B6B-ZR_1x06_P1.50mm_Vertical; MPN B6B-ZR(LF)(SN)
J11: Radio-off toggle (rear); JST_ZH_B2B-ZR_1x02_P1.50mm_Vertical; MPN B2B-ZR(LF)(SN)
J12: NeoPixel ext (5V/DATA/GND, pos 3-7); JST_PH_B3B-PH-K_1x03_P2.00mm_Vertical; MPN B3B-PH-K-S(LF)(SN)
L1, L5, L6: 10uH; L_Coilcraft_XAL4030-XXX; MPN XAL4040-103MEC
L2: 1uH; L_Coilcraft_XAL4020-XXX; MPN XAL4020-102MEC
L3: 2.2uH; L_Coilcraft_XAL4020-XXX; MPN XAL4020-222MEC
L4: 4.7uH; L_Coilcraft_XAL5050-XXX; MPN XGL5050-472MEC
M1: X40.879; Juken_X40-879_DualShaft; MPN X40.879
Q1, Q3, Q8: 2N7002; SOT-23; MPN 2N7002LT1G
Q2, Q4, Q9: AO3401A; SOT-23; MPN AO3401A
Q6, Q7: AO3400A; SOT-23; MPN AO3400A
R1: 1k; R_1206_3216Metric; MPN RC1206FR-071KL
R2, R4, R12, R13, R46, R50, R51, R60, R62, R70, R71, R72, R93, R94, R97, R99, R105, R107, R111, R112, R113: 10k; R_0603_1608Metric; MPN RC0603FR-0710KL
R3: 56k; R_0603_1608Metric; MPN RC0603FR-0756KL
R10: 316k; R_0603_1608Metric; MPN RC0603FR-07316KL
R11, R19, R22, R23, R24, R25, R26, R27, R41, R43, R44, R63: 100k; R_0603_1608Metric; MPN RC0603FR-07100KL
R14: 45.3k; R_0603_1608Metric; MPN RC0603FR-0745K3L
R15: 200k; R_0603_1608Metric; MPN RC0603FR-07200KL
R16: 976k; R_0603_1608Metric; MPN RC0603FR-07976KL
R17: 909R; R_0603_1608Metric; MPN RC0603FR-07909RL
R18: 0.1R 1W; R_2010_5025Metric; MPN WSL2010R1000FEA18
R20: 200R; R_0603_1608Metric; MPN RC0603FR-07200RL
R21: 2k; R_0603_1608Metric; MPN RC0603FR-072KL
R40: 732k; R_0603_1608Metric; MPN RC0603FR-07732KL
R42: 453k; R_0603_1608Metric; MPN RC0603FR-07453KL
R45: 86.6k; R_0603_1608Metric; MPN RC0603FR-0786K6L
R47: 95.3k; R_0603_1608Metric; MPN RC0603FR-0795K3L
R48: 2.55k; R_0603_1608Metric; MPN RC0603FR-072K55L
R61, R90, R91, R92: 0R; R_0603_1608Metric; MPN RC0603JR-070RL
R95, R96: 4.7k; R_0603_1608Metric; MPN RC0603FR-074K7L
R98: 150R; R_0603_1608Metric; MPN RC0603FR-07150RL
R104, R106: 100R; R_0603_1608Metric; MPN RC0603FR-07100RL
R110: 330R; R_0603_1608Metric; MPN RC0603FR-07330RL
R114, R115: 20k; R_0603_1608Metric; MPN RC0603FR-0720KL
RT1: 10k NTC; R_0603_1608Metric; MPN NCP18XH103F03RB
SW1: RESET; SW_SPST_CK_RS282G05A3; MPN RS-282G05A3-SM RT
SW2: BOOT; SW_SPST_CK_RS282G05A3; MPN RS-282G05A3-SM RT
U1: CH224K; SSOP-10-1EP_3.9x4.9mm_P1mm_EP2.1x3.3mm; MPN CH224K
U2: LT3652EMSE; MSOP-12-1EP_3x4.039mm_P0.65mm_EP1.651x2.845mm; MPN LT3652EMSE#PBF
U3: HY2111-HB; SOT-23-6; MPN HY2111-HB
U4: AOSD32334C; SOIC-8_3.9x4.9mm_P1.27mm; MPN AOSD32334C
U5: TPS61023; SOT-563; MPN TPS61023DRLR
U6: TLV62569DBVR; SOT-23-5; MPN TLV62569DBVR
U7: TPS55340PWPR; Texas_HTSSOP-14-1EP_4.4x5mm_P0.65mm_EP3.4x5mm_Mask3.155x3.2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; MPN TPS55340PWPR
U8: ESP32-S3-WROOM-1-N8R8; ESP32-S3-WROOM-1; MPN ESP32-S3-WROOM-1-N8R8
U9: TAS5760MDAPR; HTSSOP-32-1EP_6.1x11mm_P0.65mm_EP5.2x11mm_Mask4.11x4.36mm; MPN TAS5760MDAPR
U10: LTC4412ES6; SOT-23-6; MPN LTC4412ES6#TRPBF
U11, U12: TB6612FNG; SSOP-24_5.3x8.2mm_P0.65mm; MPN TB6612FNG,C,8,EL
U13: MCP23017; SSOP-28_5.3x10.2mm_P0.65mm; MPN MCP23017-E/SS
U14: QRE1113GR; OnSemi_QRE1113GR; MPN QRE1113GR
U15: SN74AHCT1G125; SOT-23-5; MPN SN74AHCT1G125DBVR
U16: USBLC6-2SC6; SOT-23-6; MPN USBLC6-2SC6
Y1: 32.768kHz; Crystal_SMD_3215-2Pin_3.2x1.5mm; MPN ABS07-32.768KHZ-T

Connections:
+3V3: C125.1, C126.1, C140.1, C141.1, C142.1, C143.1, C161.1, C162.1, C163.1, C202.1, C212.1, C222.1, C223.1, C240.1, D14.1 (K), J2.1, J6.4 (VDD), J7.2, L3.2, R4.1, R12.1, R13.1, R42.1, R50.1, R51.1, R60.1, R62.1, R70.1, R71.1, R72.1, R93.1, R94.1, R95.1, R96.1, R97.1, R98.1, R99.1, R113.1, U8.2 (3V3), U9.1 (AVDD), U9.10 (DVDD), U11.15 (PWMB), U11.20 (VCC), U11.23 (PWMA), U12.15 (PWMB), U12.20 (VCC), U12.23 (PWMA), U13.9 (V_{DD})
+5V: C121.1, C122.1, C123.1, C124.1, C186.1, C200.1, C201.1, C210.1, C211.1, C230.1, C231.1, C237.1, C238.1, D40.3 (VDD), D41.3 (VDD), J10.2, J12.1, Q4.3 (D), R40.1, U5.6 (VOUT), U6.1 (EN), U6.4 (VIN), U10.1 (VIN), U11.13 (VM2), U11.14 (VM3), U11.24 (VM1), U12.13 (VM2), U12.14 (VM3), U12.24 (VM1), U15.5 (VCC)
+12V: C130.1, C131.1, C132.1, D20.1 (K), D30.2 (A), J9.1, R45.1
ALS_INT: J7.6, U13.4 (GPB3)
BOOST12_EN: R44.1, U7.4 (EN), U13.23 (GPA2)
CELL_TEST: Q8.1 (G), R26.1, U13.8 (GPB7)
CHRG: R12.2, U2.4 (~CHRG), U13.2 (GPB1)
ENC_SW: C239.1, J10.5, R113.2, U8.10 (IO17_ENC_SW)
FAULT: R13.2, U2.5 (~FAULT), U13.3 (GPB2)
FULLCHG_EN: Q1.1 (G), R24.1, U13.5 (GPB4)
GND: C1.2, C100.2, C101.2, C102.2, C104.2, C106.2, C107.2, C110.2, C120.2, C121.2, C122.2, C124.2, C125.2, C127.2, C128.2, C129.2, C130.2, C131.2, C132.2, C133.2, C134.2, C135.2, C140.2, C141.2, C142.2, C143.2, C144.2, C145.1, C146.1, C160.2, C161.2, C162.2, C163.2, C164.2, C165.2, C166.2, C167.2, C170.2, C171.2, C172.2, C184.2, C185.2, C186.2, C200.2, C201.2, C202.2, C210.2, C211.2, C212.2, C222.2, C223.2, C230.2, C231.2, C237.2, C238.2, C239.2, C240.2, C241.2, D1.2 (A2), D11.2 (A), D12.2 (A2), D13.2 (A), D40.1 (VSS), D41.1 (VSS), F1.2, J1.A1 (GND), J1.A12 (GND), J1.B1 (GND), J1.B12 (GND), J1.SH (SHIELD), J2.2, J6.6 (VSS), J6.SH (SHIELD), J7.1, J10.1, J10.6, J11.2, J12.3, Q1.2 (S), Q3.2 (S), Q6.2 (S), Q7.2 (S), Q8.2 (S), R3.2, R11.2, R15.2, R17.2, R19.2, R21.2, R24.2, R25.2, R26.2, R41.2, R43.2, R44.2, R46.2, R47.2, R61.2, R63.2, R90.2, R91.2, R92.2, R105.2, R107.2, R114.2, R115.2, SW1.1, SW2.1, U1.11 (GND), U2.13 (GND), U5.4 (GND), U6.2 (GND), U7.6 (SYNC), U7.7 (AGND), U7.11 (NC), U7.12 (PGND), U7.13 (PGND), U7.14 (PGND), U7.15 (PAD), U8.1 (GND), U8.40 (GND), U8.41 (GND), U9.18 (DGND), U9.22 (PGND), U9.27 (PGND), U9.31 (GGND), U9.33 (PAD), U10.2 (GND), U10.3 (CTL), U11.3 (PGND1), U11.4 (PGND1), U11.9 (PGND2), U11.10 (PGND2), U11.18 (GND), U12.3 (PGND1), U12.4 (PGND1), U12.9 (PGND2), U12.10 (PGND2), U12.18 (GND), U13.10 (V_{SS}), U14.2 (K), U14.4, U15.1, U15.3 (GND), U16.2 (GND); also elsewhere on the board
HOME_OPTO: C241.1, R99.2, U8.38 (IO2_ADC_HOME), U14.3
I2C_SCL: J7.4, R96.2, U8.17 (IO9_SCL), U9.9 (PBTL/SCL), U13.12 (SCK)
I2C_SDA: J7.3, R95.2, U8.12 (IO8_SDA), U9.8 (FREQ/SDA), U13.13 (SDA)
NEOPIX_DATA: U8.7 (IO7_NEOPIX), U15.2
unnamed: BT1.1, Q2.2 (S), Q9.2 (S), R20.1, R22.1, R27.1
unnamed: BT1.2, C109.2, U3.6 (VSS), U4.3 (S1)
unnamed: C134.1, R48.2
unnamed: C108.1, D10.1 (K), U2.11 (BOOST)
unnamed: C108.2, D11.1 (K), L1.1, U2.12 (SW)
unnamed: D20.2 (A), L4.2, U7.1 (SW), U7.2 (SW)
unnamed: D40.2 (DIN), R110.2
unnamed: D40.4 (DOUT), D41.2 (DIN)
unnamed: D41.4 (DOUT), J12.2
unnamed: J1.A5 (CC1), U1.7 (CC1)
unnamed: J1.B5 (CC2), U1.6 (CC2)
unnamed: J1.A6 (D+), J1.B6 (D+), U16.3 (I/O2)
unnamed: J1.A7 (D-), J1.B7 (D-), U16.1 (I/O1)
unnamed: C144.1, J2.3, R50.2, SW1.2, U8.3 (EN)
unnamed: J2.4, R51.2, SW2.2, U8.27 (IO0_BOOT)
unnamed: C184.1, J3.1, L5.2
unnamed: C185.1, J3.2, L6.2
unnamed: J6.5 (CLK), U8.21 (IO13_SCLK)
unnamed: J6.3 (CMD), U8.22 (IO14_MOSI)
unnamed: J6.7 (DAT0), U8.23 (IO21_MISO)
unnamed: J6.8 (DAT1), R71.2
unnamed: J6.1 (DAT2), R72.2
unnamed: J6.2 (DAT3/CD), R70.2, U8.11 (IO18_SD_CS)
unnamed: J9.2, Q6.3 (D)
unnamed: J9.3, Q7.3 (D)
unnamed: J10.3, R111.2
unnamed: J10.4, R112.2
unnamed: J11.1, U13.24 (GPA3)
unnamed: M1.1 (1e), U11.1 (AO1), U11.2 (AO1)
unnamed: M1.5 (1i), U12.1 (AO1), U12.2 (AO1)
unnamed: M1.2 (2e), U11.5 (AO2), U11.6 (AO2)
unnamed: M1.6 (2i), U12.5 (AO2), U12.6 (AO2)
unnamed: M1.3 (3e), U11.7 (BO2), U11.8 (BO2)
unnamed: M1.7 (3i), U12.7 (BO2), U12.8 (BO2)
unnamed: M1.4 (4e), U11.11 (BO1), U11.12 (BO1)
unnamed: M1.8 (4i), U12.11 (BO1), U12.12 (BO1)
unnamed: Q1.3 (D), R16.2
unnamed: Q2.1 (G), Q9.3 (D), R19.1
unnamed: Q3.3 (D), R23.2
unnamed: Q4.1 (G), U10.5 (GATE)
unnamed: Q6.1 (G), R104.2, R105.1
unnamed: Q7.1 (G), R106.2, R107.1
unnamed: Q8.3 (D), Q9.1 (G), R27.2
unnamed: R17.1, RT1.2
unnamed: R110.1, U15.4
unnamed: R3.1, U1.9 (CFG1)
unnamed: U1.4 (DP), U1.5 (DM)
unnamed: R2.2, U1.8 (VBUS)
unnamed: C1.1, R1.2, U1.1 (VDD)
unnamed: RT1.1, U2.8 (NTC)
unnamed: L1.2, R18.1, U2.10 (SENSE)
unnamed: C104.1, U2.6 (TIMER)
unnamed: C105.2, R14.2, R15.1, R16.1, U2.7 (V_{FB})
unnamed: R10.2, R11.1, U2.2 (V_{IN_REG})
unnamed: R21.1, U3.2 (CS)
unnamed: U3.3 (OC), U4.2 (G2)
unnamed: U3.1 (OD), U4.4 (G1)
unnamed: C109.1, R20.2, U3.5 (VDD)
unnamed: U4.5 (D1), U4.6 (D1), U4.7 (D2), U4.8 (D2)
unnamed: F1.1, U4.1 (S2)
unnamed: C123.2, R40.2, R41.1, U5.1 (FB)
unnamed: L2.2, U5.5 (SW)
unnamed: C126.2, R42.2, R43.1, U6.5 (FB)
unnamed: L3.1, U6.3 (SW)
unnamed: C135.1, R48.1, U7.8 (COMP)
unnamed: R45.2, R46.1, U7.9 (FB)
unnamed: R47.1, U7.10 (FREQ)
unnamed: C133.1, U7.5 (SS)
unnamed: U8.18 (IO10_BCLK), U9.15 (SCLK)
unnamed: U8.19 (IO11_LRCLK), U9.17 (LRCK)
unnamed: U8.20 (IO12_DOUT), U9.16 (SDIN)
unnamed: C145.2, U8.8 (IO15_XTAL_P), Y1.2
unnamed: C146.2, U8.9 (IO16_XTAL_N), Y1.1
unnamed: U8.37 (IO43_MCLK), U9.14 (MCLK)
unnamed: R111.1, R114.1, U8.24 (IO47_ENC_A)
unnamed: R112.1, R115.1, U8.25 (IO48_ENC_B)
unnamed: C166.1, U9.5 (ANA_REF)
unnamed: C164.1, C165.1, U9.3 (ANA_REG)
unnamed: C180.1, U9.30 (BSTRPA+)
unnamed: C181.1, U9.25 (BSTRPA-)
unnamed: C182.1, U9.19 (BSTRPB+)
unnamed: C183.1, U9.24 (BSTRPB-)
unnamed: C160.1, U9.2 (SFT_CLIP), U9.32 (GVDD_REG)
unnamed: R60.2, U9.11 (SPK_GAIN0), U9.12 (SPK_GAIN1)
unnamed: C180.2, C181.2, L5.1, U9.26 (SPK_OUTA-), U9.29 (SPK_OUTA+)
unnamed: C182.2, C183.2, L6.1, U9.20 (SPK_OUTB+), U9.23 (SPK_OUTB-)
unnamed: R61.1, U9.13 (SPK_SLEEP/ADR)
unnamed: C167.1, U9.4 (VCOM)
unnamed: U8.4 (IO4_M_AIN1), U11.21 (AIN1)
unnamed: U8.5 (IO5_M_AIN2), U11.22 (AIN2)
unnamed: U8.6 (IO6_M_BIN1), U11.17 (BIN1)
unnamed: U8.15 (IO3_M_BIN2), U11.16 (BIN2)
unnamed: U8.31 (IO38_H_AIN1), U12.21 (AIN1)
unnamed: U8.32 (IO39_H_AIN2), U12.22 (AIN2)
unnamed: U8.33 (IO40_H_BIN1), U12.17 (BIN1)
unnamed: U8.34 (IO41_H_BIN2), U12.16 (BIN2)
unnamed: R90.1, U13.15 (A0)
unnamed: R91.1, U13.16 (A1)
unnamed: R92.1, U13.17 (A2)
unnamed: R94.2, U8.36 (IO44_EXP_INT), U13.19 (INTB), U13.20 (INTA)
unnamed: R93.2, U13.18 (~RESET)
unnamed: R98.2, U14.1 (A)
PD_PG: R4.2, U1.10 (PG), U13.1 (GPB0)
PVDD: C170.1, C171.1, C172.1, D30.1 (K), Q4.2 (S), U9.21 (PVDD), U9.28 (PVDD), U10.6 (SENSE)
SENSOR_INT: J7.5, R97.2, U8.35 (IO42_SENS_INT)
SPK_FAULT: R62.2, U9.6 (SPK_FAULT), U13.7 (GPB6)
SPK_SD: R63.1, U9.7 (SPK_SD), U13.21 (GPA0)
STEP_STBY: U11.19 (STBY), U12.19 (STBY), U13.22 (GPA1)
USB_DM: U8.13 (IO19_USB_D-), U16.6 (I/O1)
USB_DP: U8.14 (IO20_USB_D+), U16.4 (I/O2)
VBAT: C105.1, C106.1, C107.1, C120.1, C127.1, C128.1, C129.1, D10.2 (A), D12.1 (A1), L2.1, L4.1, Q2.3 (D), R14.1, R18.2, U2.9 (BAT), U5.2 (EN), U5.3 (VIN), U7.3 (VIN)
VBAT_DIV_EN: Q3.1 (G), R25.1, U13.6 (GPB5)
VBAT_SENSE: C110.1, D13.1 (K), D14.2 (A), R22.2, R23.1, U8.39 (IO1_ADC_VBAT)
VBUS: C100.1, C101.1, C102.1, D1.1 (A1), J1.A4 (VBUS), J1.A9 (VBUS), J1.B4 (VBUS), J1.B9 (VBUS), R1.1, R2.1, R10.1, U2.1 (V_{IN}), U2.3 (~SHDN)
WAKE_COOL_PWM: R106.1, U8.16 (IO46_PWM_COOL)
WAKE_WARM_PWM: R104.1, U8.26 (IO45_PWM_WARM)

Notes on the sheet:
each pixel VDD; C237 bulk + R110 + U15 at the chain head. J12 feeds
PLUGGED-ONLY: firmware asserts BOOST12_EN only while PD_PG is live.
data line; AHCT buffer lifts 3V3 -> 5V (SK6812 VIH = 0.7*VDD = 3.5V).
SPI mode: MSB-first, CS active-low, ~25 MHz. No card-detect (no spare GPIO).
I_CHG = 1.0 A (R18); RT1 = NCP18XH103 on the holder, 0..45 C window; 4.4 h timer
MOTOR — 2x TB6612FNG -> X40.879 dual-shaft stepper
QRE1113GR faces reflective tabs on the hand hubs (no magnets).
USB 2.0 subset of the 24-pin USB4160 (SS pads unconnected);
Layout: D40/D41 = dial wash either side of the shaft. C230/231 one at
cell- -> AOSD32334C (OD/OC gated) -> TCO 77 C -> PACK- (GND)
CH224K DP/DM shorted = PD-only; Type-C D± go to the MCU.
CFG1=56k -> 15 V PDO; falls back to 5 V (charger idles <11.2 V).
CHARGER — LT3652 (1S buck, 4.05 V float, 1.0 A)
Li-ion 18650 ONLY - 2.5-4.2 V
and named labels connect by name (same name = same net).
PWM-on-IN microstepping: MCPWM waveforms on AIN/BIN, PWMA/B tied high.
SENSORS (I2C off-board) + HAND-HOMING (QRE1113)
knob, radio toggle, cell) enter via connectors J1..J11 / BT1.
DIAL1
INT: any GPA/GPB change -> IO44 (IOCON.MIRROR=1). Knob = EM14A0D-C24-L064S
D40/D41 = on-PCB dial wash (chain pos 1-2). J12 breaks the chain out
DIAL2
Charges only on the 15 V contract (UVLO 11.2 V); runs with no cell.
1x02 (pre-crimped AxxZR cables). A/B 5 V -> 100k/200k div -> PCNT; SW -> IO17 IRQ.
their wake gate nets + internal PD; IO3 internal. Flash+console+JTAG = USB-CDC (IO19/20).
RAILS — 5 V boost (always on) -> 3V3 buck
(optical, 64 CPR, no detent, push) on the top face. J7/J10 = JST ZH 1x06, J11 = ZH
DIAL NEOPIXEL HEAD - 2x on-PCB + 5x off-board via J12 (5 V)
+3V3
MCU — ESP32-S3-WROOM-1-N8R8 (Wi-Fi + BLE, native USB-JTAG)
+5V: display panel, stepper VM, panel LEDs, PVDD-mux aux. +3V3: MCU + all logic.
MCU centre, peripherals right. Power paths and MCU buses (SPI,
BATTERY — 18650 + reverse P-FET + protector + TCO
STORAGE — microSD (DM3AT), SPI2 dedicated
Layout: each driver's 10uF+100nF go at its VM pins, the 100nF at its VCC pin.
OV 4.28 V / OD 2.90 V fixed (-GB). Independent of the charger.
Sensor breakouts carry their own I2C pull-ups.
HOW TO READ THIS SHEET
I2S, MCPWM, encoder) are drawn as wires; GND / +3V3 / +5V taps
Off-board parts (SD card, sensors, speaker, wake-LED strips,

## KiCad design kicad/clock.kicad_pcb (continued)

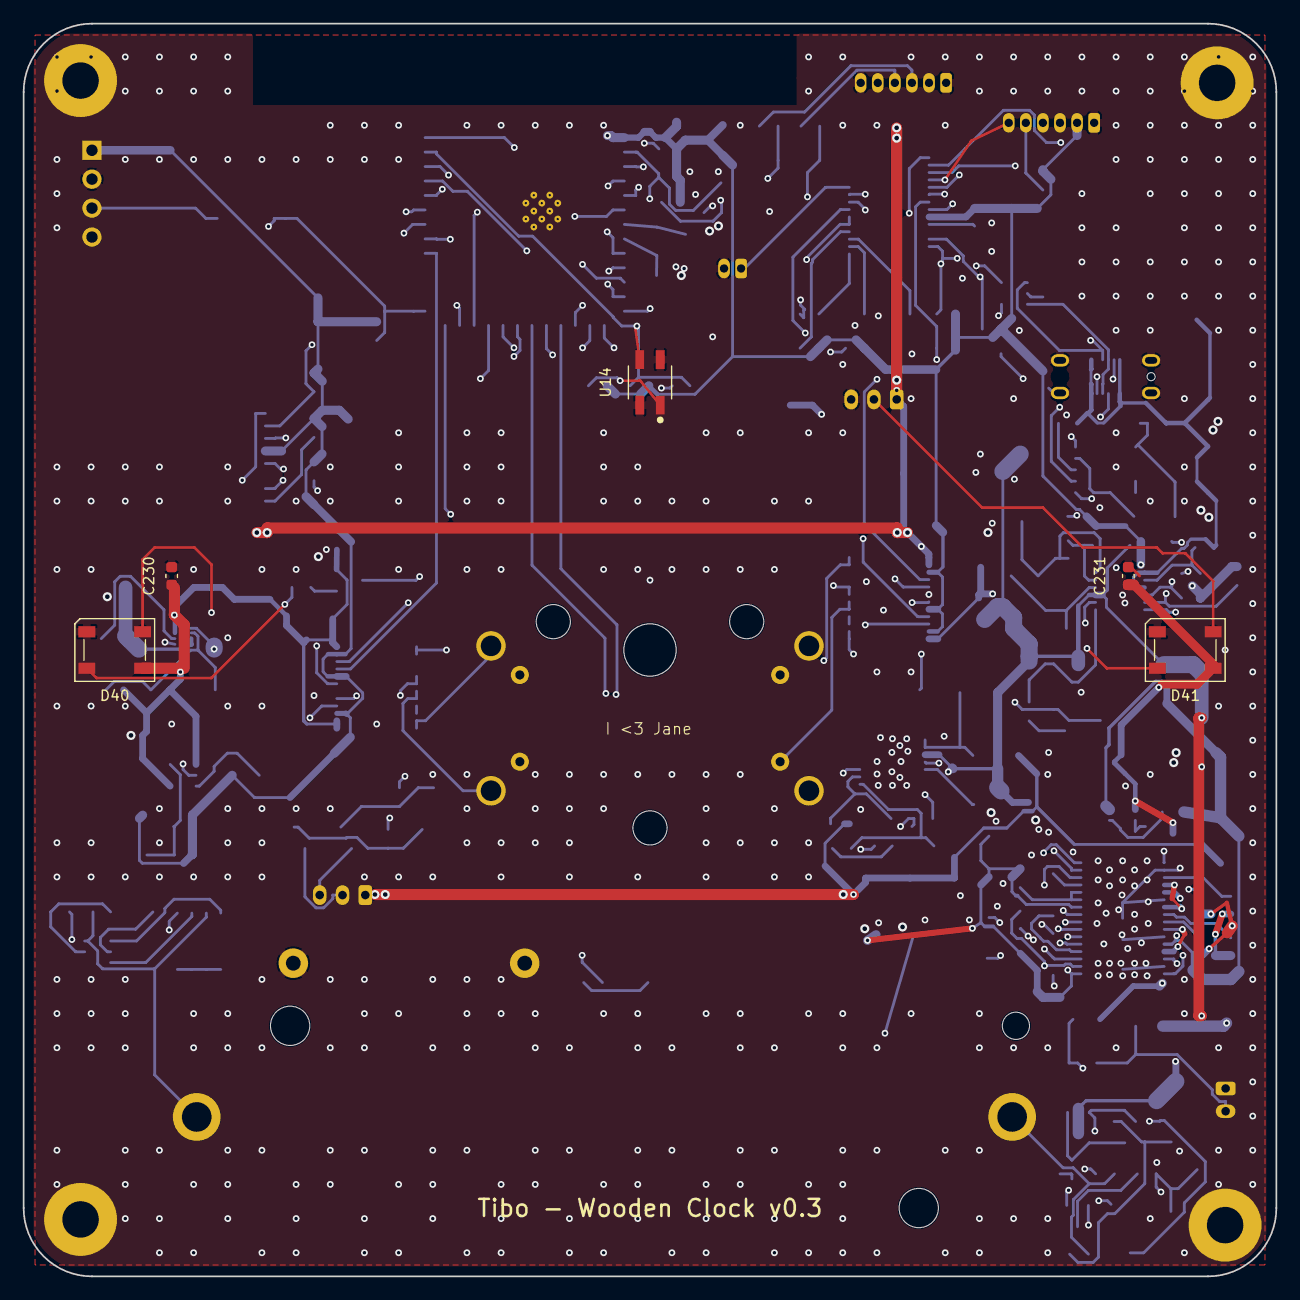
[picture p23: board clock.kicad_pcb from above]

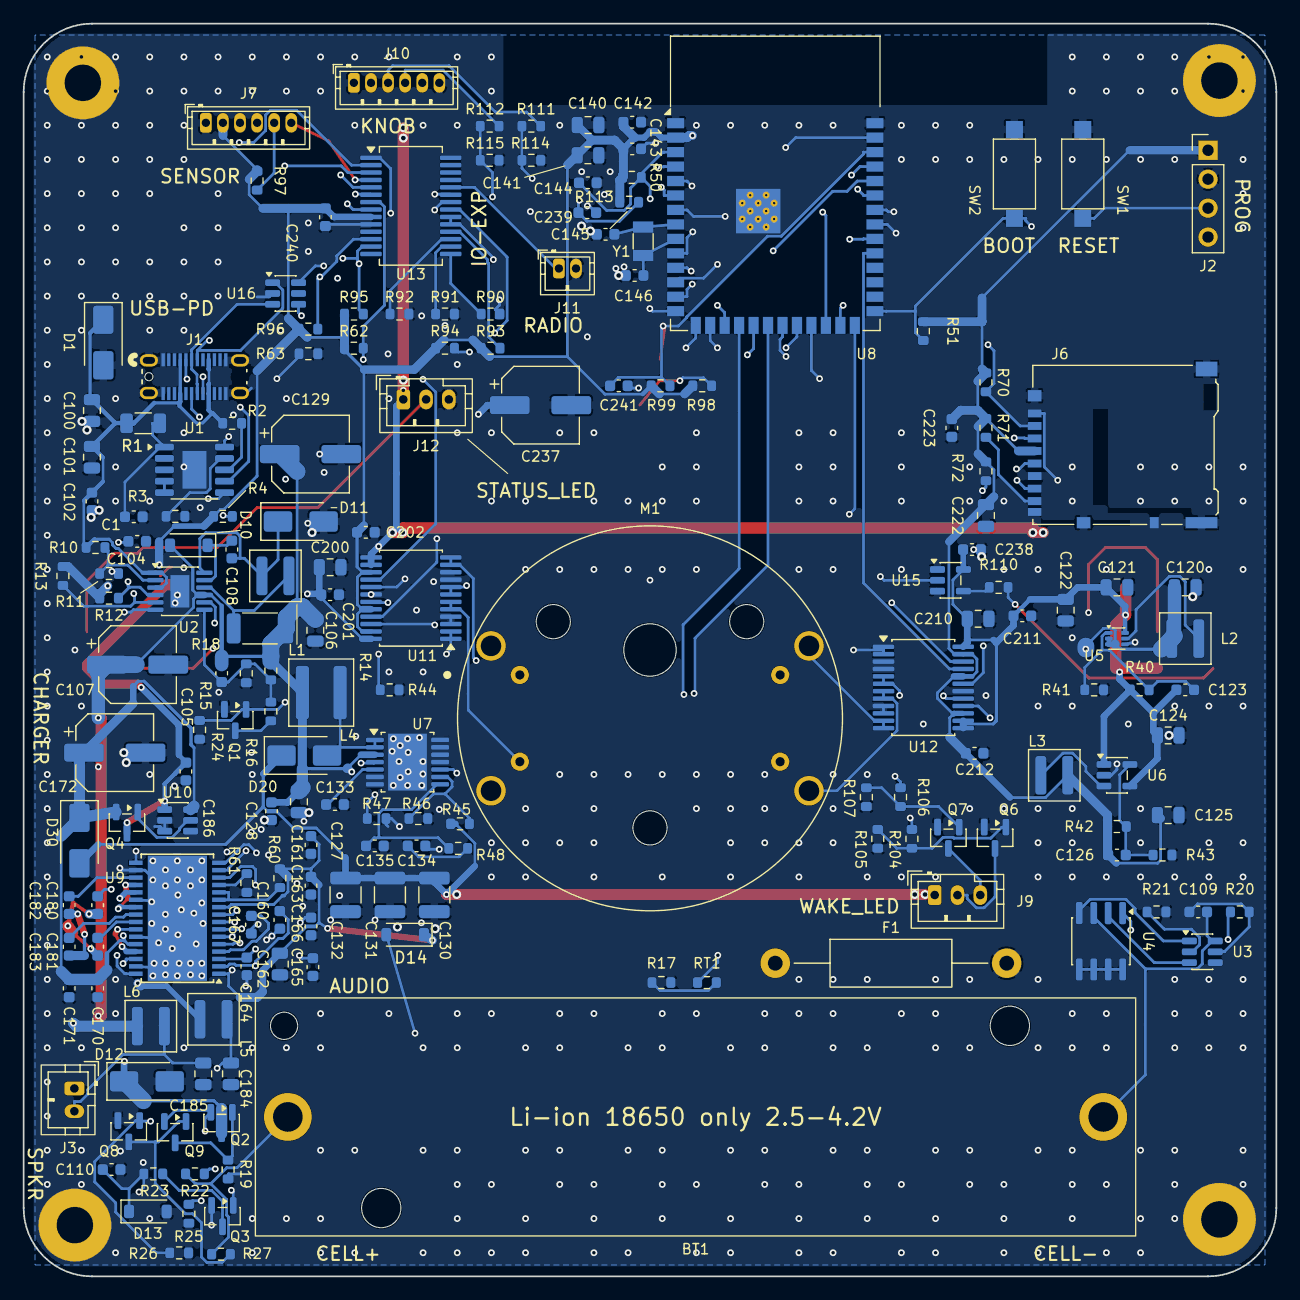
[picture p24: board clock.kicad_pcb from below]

Board: 4 copper layers, 110.0 x 110.0 mm, 187 parts (178 on the bottom side), 131 nets.

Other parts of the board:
H1, H2, H3, H4: MountingHole_3.2mm_M3_Pad

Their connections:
GND: H1.1, H2.1, H3.1, H4.1; also elsewhere on the board

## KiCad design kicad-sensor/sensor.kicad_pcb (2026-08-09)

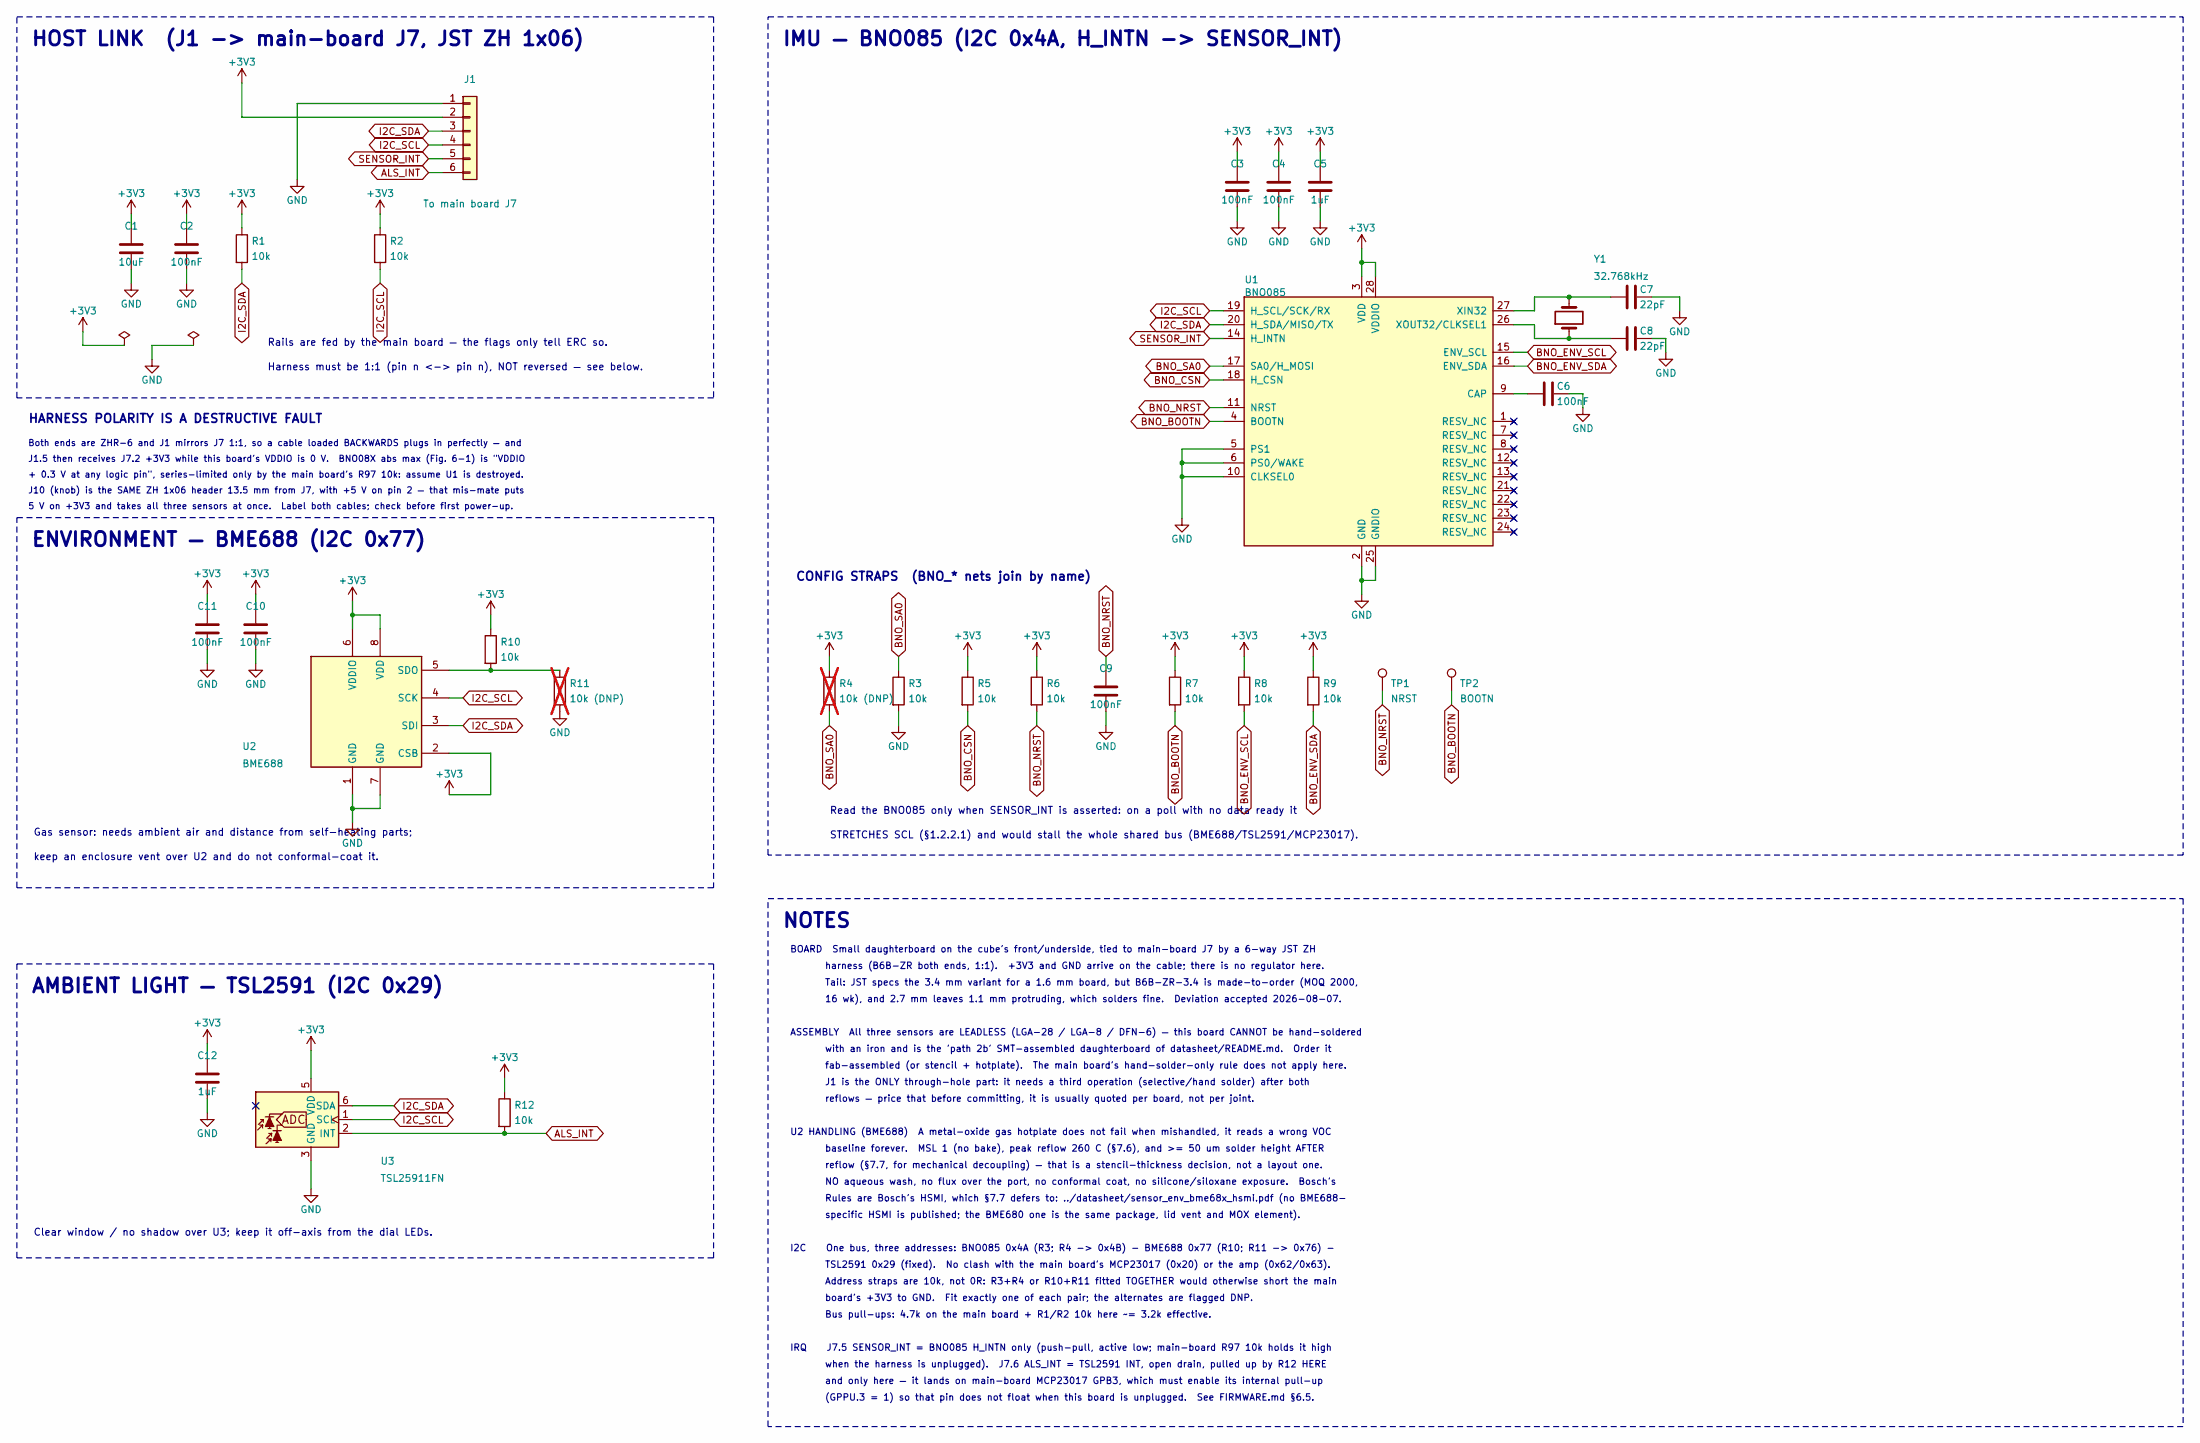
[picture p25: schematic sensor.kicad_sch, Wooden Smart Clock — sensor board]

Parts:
C1: 10uF; C_0805_2012Metric; MPN CL21A106KAYNNNE
C2, C3, C4, C6, C9, C10, C11: 100nF; C_0603_1608Metric; MPN CL10B104KB8NNNC
C5, C12: 1uF; C_0603_1608Metric; MPN CL10B105KA8NNNC
C7, C8: 22pF; C_0603_1608Metric; MPN CL10C220JB8NNNC
J1: To main board J7; JST_ZH_B6B-ZR_1x06_P1.50mm_Vertical; MPN B6B-ZR(LF)(SN)
R1, R2, R3, R5, R6, R7, R8, R9, R10, R12: 10k; R_0603_1608Metric; MPN RC0603FR-0710KL
R4, R11: 10k (DNP); R_0603_1608Metric; MPN RC0603FR-0710KL; not fitted
TP1: NRST; TestPoint_Pad_D1.0mm
TP2: BOOTN; TestPoint_Pad_D1.0mm
U1: BNO085; CEVA_BNO085_LGA-28_5.2x3.8mm_P0.5mm; MPN BNO085
U2: BME688; Bosch_LGA-8_3x3mm_P0.8mm_ClockwisePinNumbering; MPN BME688
U3: TSL25911FN; AMS_TSL25911FN_ALSWindow; MPN TSL25911FN
Y1: 32.768kHz; Crystal_SMD_3215-2Pin_3.2x1.5mm; MPN ABS07-32.768KHZ-T

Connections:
+3V3: C1.1, C2.1, C3.1, C4.1, C5.1, C10.1, C11.1, C12.1, J1.2, R1.1, R2.1, R4.1, R5.1, R6.1, R7.1, R8.1, R9.1, R10.1, R12.1, U1.3 (VDD), U1.28 (VDDIO), U2.2 (CSB), U2.6 (VDDIO), U2.8 (VDD), U3.5 (VDD)
ALS_INT: J1.6, R12.2, U3.2 (INT)
BNO_BOOTN: R7.2, TP2.1, U1.4 (BOOTN)
BNO_CSN: R5.2, U1.18 (H_CSN)
BNO_ENV_SCL: R8.2, U1.15 (ENV_SCL)
BNO_ENV_SDA: R9.2, U1.16 (ENV_SDA)
BNO_NRST: C9.1, R6.2, TP1.1, U1.11 (NRST)
BNO_SA0: R3.1, R4.2, U1.17 (SA0/H_MOSI)
GND: C1.2, C2.2, C3.2, C4.2, C5.2, C6.2, C7.2, C8.2, C9.2, C10.2, C11.2, C12.2, J1.1, R3.2, R11.2, U1.2 (GND), U1.5 (PS1), U1.6 (PS0/WAKE), U1.10 (CLKSEL0), U1.25 (GNDIO), U2.1 (GND), U2.7 (GND), U3.3 (GND)
I2C_SCL: J1.4, R2.2, U1.19 (H_SCL/SCK/RX), U2.4 (SCK), U3.1 (SCL)
I2C_SDA: J1.3, R1.2, U1.20 (H_SDA/MISO/TX), U2.3 (SDI), U3.6 (SDA)
unnamed: C6.1, U1.9 (CAP)
unnamed: C7.1, U1.27 (XIN32), Y1.2
unnamed: C8.1, U1.26 (XOUT32/CLKSEL1), Y1.1
unnamed: R10.2, R11.1, U2.5 (SDO)
SENSOR_INT: J1.5, U1.14 (H_INTN)

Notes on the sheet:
STRETCHES SCL (§1.2.2.1) and would stall the whole shared bus (BME688/TSL2591/MCP23017).
ENVIRONMENT — BME688 (I2C 0x77)
Rails are fed by the main board — the flags only tell ERC so.
J1.5 then receives J7.2 +3V3 while this board's VDDIO is 0 V. BNO08X abs max (Fig. 6-1) is "VDDIO
Rules are Bosch's HSMI, which §7.7 defers to: ../datasheet/sensor_env_bme68x_hsmi.pdf (no BME688-
ASSEMBLY All three sensors are LEADLESS (LGA-28 / LGA-8 / DFN-6) — this board CANNOT be hand-soldered
reflows — price that before committing, it is usually quoted per board, not per joint.
fab-assembled (or stencil + hotplate). The main board's hand-solder-only rule does not apply here.
5 V on +3V3 and takes all three sensors at once. Label both cables; check before first power-up.
BOARD Small daughterboard on the cube's front/underside, tied to main-board J7 by a 6-way JST ZH
HARNESS POLARITY IS A DESTRUCTIVE FAULT
baseline forever. MSL 1 (no bake), peak reflow 260 C (§7.6), and >= 50 um solder height AFTER
Read the BNO085 only when SENSOR_INT is asserted: on a poll with no data ready it
16 wk), and 2.7 mm leaves 1.1 mm protruding, which solders fine. Deviation accepted 2026-08-07.
AMBIENT LIGHT — TSL2591 (I2C 0x29)
Harness must be 1:1 (pin n <-> pin n), NOT reversed — see below.
TSL2591 0x29 (fixed). No clash with the main board's MCP23017 (0x20) or the amp (0x62/0x63).
I2C One bus, three addresses: BNO085 0x4A (R3; R4 -> 0x4B) - BME688 0x77 (R10; R11 -> 0x76) -
IMU — BNO085 (I2C 0x4A, H_INTN -> SENSOR_INT)
specific HSMI is published; the BME680 one is the same package, lid vent and MOX element).
U2 HANDLING (BME688) A metal-oxide gas hotplate does not fail when mishandled, it reads a wrong VOC
J1 is the ONLY through-hole part: it needs a third operation (selective/hand solder) after both
Address straps are 10k, not 0R: R3+R4 or R10+R11 fitted TOGETHER would otherwise short the main
harness (B6B-ZR both ends, 1:1). +3V3 and GND arrive on the cable; there is no regulator here.
Tail: JST specs the 3.4 mm variant for a 1.6 mm board, but B6B-ZR-3.4 is made-to-order (MOQ 2000,
IRQ J7.5 SENSOR_INT = BNO085 H_INTN only (push-pull, active low; main-board R97 10k holds it high
Gas sensor: needs ambient air and distance from self-heating parts;
keep an enclosure vent over U2 and do not conformal-coat it.
HOST LINK (J1 -> main-board J7, JST ZH 1x06)
with an iron and is the 'path 2b' SMT-assembled daughterboard of datasheet/README.md. Order it
NO aqueous wash, no flux over the port, no conformal coat, no silicone/siloxane exposure. Bosch's
Clear window / no shadow over U3; keep it off-axis from the dial LEDs.
Both ends are ZHR-6 and J1 mirrors J7 1:1, so a cable loaded BACKWARDS plugs in perfectly — and
CONFIG STRAPS (BNO_* nets join by name)
(GPPU.3 = 1) so that pin does not float when this board is unplugged. See FIRMWARE.md §6.5.
+ 0.3 V at any logic pin", series-limited only by the main board's R97 10k: assume U1 is destroyed.
NOTES
and only here — it lands on main-board MCP23017 GPB3, which must enable its internal pull-up
J10 (knob) is the SAME ZH 1x06 header 13.5 mm from J7, with +5 V on pin 2 — that mis-mate puts
when the harness is unplugged). J7.6 ALS_INT = TSL2591 INT, open drain, pulled up by R12 HERE

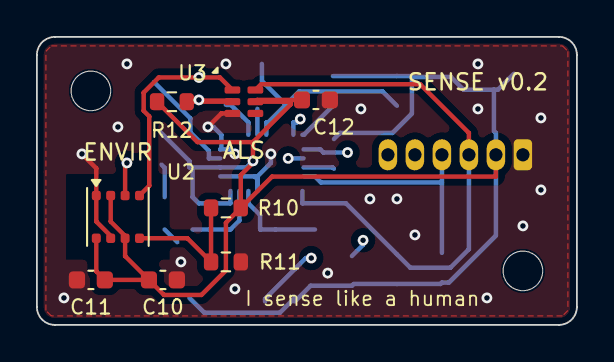
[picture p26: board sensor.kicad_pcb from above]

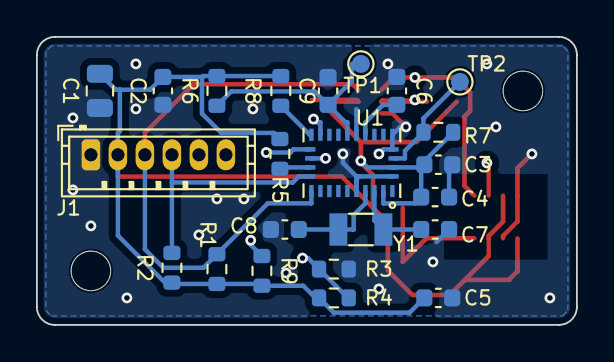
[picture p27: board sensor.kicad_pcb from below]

Board: 4 copper layers, 30.0 x 16.0 mm, 33 parts (23 on the bottom side), 16 nets.

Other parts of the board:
H1, H2: MountingHole_2.2mm_M2

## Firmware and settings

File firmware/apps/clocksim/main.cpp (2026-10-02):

// clocksim -- the product on your laptop.                  [FIRMWARE.md D14, §11.2]
//
// Two front-ends onto the same CLI: stdin, and a loopback socket that `ux/` attaches to.
// Both go through cli::dispatch_line, so anything the app can do is something you can type,
// and anything you type the app sees the result of.
#include <unistd.h>

#include <chrono>
#include <cstdio>
#include <cstdlib>
#include <cstring>
#include <string>
#include <thread>

#include "uibridge.hpp"

#include "clk/cli/console.hpp"
#include "clk/cli/net_bind.hpp"
#include "clk/hal/hal.hpp"
#include "clk/hal/host/sim.hpp"
#include "clk/log.hpp"
#include "clk/services/chrono.hpp"
#include "clk/services/motion.hpp"
#include "clk/services/net.hpp"
#include "clk/services/storage.hpp"
#include "clk/services/supervisor.hpp"
#include "clk/services/ui.hpp"

namespace {

// `sim reboot`.  execv replaces the whole process image -- every thread, every singleton,
// every service's idea of where the hands are -- which is as close to an NVIC reset as a
// laptop gets.  The bridge's sockets are FD_CLOEXEC, so the port comes back free and the
// attached browser sees a clean disconnect and reconnects itself.
char** g_argv = nullptr;

void reboot_now() {
    CLK_LOGW(sys, "reboot: re-exec %s", g_argv && g_argv[0] ? g_argv[0] : "?");
    // The caller is a CLI thread; give the bridge a moment to push that line to whoever is
    // attached, since nothing survives the exec to explain the silence.
    std::this_thread::sleep_for(std::chrono::milliseconds(120));
    // stdout and stderr BY NAME.  fflush(nullptr) walks every open FILE and locks each one,
    // and the console thread is parked inside fgets() holding stdin's lock -- so the flush
    // that was meant to tidy up deadlocked the reboot instead, with the CLI mutex held.
    std::fflush(stdout);
    std::fflush(stderr);
    if (g_argv && g_argv[0]) ::execv(g_argv[0], g_argv);
    CLK_LOGE(sys, "reboot: execv failed (%s) -- still the old image", std::strerror(errno));
}

// Where the NVS stand-in lives.  A real clock's calibration survives the power cord being
// pulled, so the sim's has to survive a restart too -- `sim reset`, `sys reboot` and closing
// the terminal all leave this file exactly where it was.
std::string store_path() {
    if (const char* env = std::getenv("CLOCKSIM_NVS")) return env;
    const char* home = std::getenv("HOME");
    return home ? std::string{home} + "/.clocksim.nvs" : std::string{".clocksim.nvs"};
}

// The microSD slot.  A directory stands in for the card -- /sd/tones/x.wav is <dir>/tones/x.wav
// -- and no directory is an empty slot, which is a state the product must handle anyway.
std::string sd_path() {
    if (const char* env = std::getenv("CLOCKSIM_SD")) return env;
    const char* home = std::getenv("HOME");
    return home ? std::string{home} + "/.clocksim.sd" : std::string{};
}

void usage() {
    std::printf(
        "clocksim -- the clock firmware against fake hardware\n"
        "  --ui-port <n>   serve the ux/ bridge on 127.0.0.1:<n>  (default %u)\n"
        "  --no-ui         console only\n"
        "  --no-home       do not home on boot (the test rig; `motion home` still works)\n"
        "  --nvs <path>    where persistent settings live  (default ~/.clocksim.nvs,\n"
        "                  or $CLOCKSIM_NVS)\n"
        "  --sd <dir>      the microSD card: a directory, tones in <dir>/tones/\n"
        "                  (default ~/.clocksim.sd, or $CLOCKSIM_SD; missing = no card)\n"
        "  -h, --help      this\n",
        clk::uibridge::kDefaultPort);
}

}  // namespace

int main(int argc, char** argv) {
    uint16_t ui_port = clk::uibridge::kDefaultPort;
    bool home_on_boot = true;
    std::string nvs = store_path();
    std::string sd = sd_path();
    g_argv = argv;

    for (int i = 1; i < argc; ++i) {
        const char* a = argv[i];
        if (std::strcmp(a, "--no-ui") == 0) {
            ui_port = 0;
        } else if (std::strcmp(a, "--no-home") == 0) {
            home_on_boot = false;
        } else if (std::strcmp(a, "--sd") == 0 && i + 1 < argc) {
            sd = argv[++i];
        } else if (std::strcmp(a, "--nvs") == 0 && i + 1 < argc) {
            nvs = argv[++i];
        } else if (std::strcmp(a, "--ui-port") == 0 && i + 1 < argc) {
            ui_port = static_cast<uint16_t>(std::strtoul(argv[++i], nullptr, 10));
        } else if (std::strcmp(a, "-h") == 0 || std::strcmp(a, "--help") == 0) {
            usage();
            return 0;
        } else {
            std::printf("unknown argument: %s\n", a);
            usage();
            return 2;
        }
    }

    clk::log::init(clk::log::Level::Info);
    clk::hal::init();
    clk::hal::host::set_reboot_hook(reboot_now);
    clk::hal::host::set_store_path(nvs.c_str());
    CLK_LOGI(sys, "nvs: %s", nvs.c_str());
    clk::hal::host::set_sd_dir(sd.c_str());
    CLK_LOGI(sys, "sd: %s", sd.c_str());

    // Same construction order as app_main: wire the AOs to each other, then start them in
    // priority order.  motion has no dependencies; chrono drives it; ui drives both.
    auto& motion = clk::svc::motion();
    auto& chrono = clk::svc::chrono();
    auto& ui = clk::svc::ui();
    auto& net = clk::svc::net();
    auto& storage = clk::svc::storage();
    auto& sup = clk::svc::supervisor();
    motion.subscribe(&chrono);
    chrono.bind(&motion);
    ui.bind(&motion, &chrono, &net, &storage, &sup);
    net.bind(&motion, &chrono, &ui, &storage);
    clk::cli::bind_net();
    // Watching, never restarting: a re-exec'd clocksim under a test rig is not a recovery.
    sup.bind(&motion, &chrono, &storage, &ui);
    for (clk::ActiveObject* ao :
         {static_cast<clk::ActiveObject*>(&motion), static_cast<clk::ActiveObject*>(&chrono),
          static_cast<clk::ActiveObject*>(&storage), static_cast<clk::ActiveObject*>(&net),
          static_cast<clk::ActiveObject*>(&ui)})
        sup.watch(ao);
    // A real clock homes the moment it powers up (§6.1).  The test rig turns that off: a
    // nine-second sweep before every case buys nothing there, and the case that is ABOUT
    // boot homing simply starts a clocksim without the flag.
    motion.set_home_on_start(home_on_boot);
    motion.start();
    chrono.start();
    storage.start();  // before ui: an alarm due at boot must find the card already mounted
    net.start();
    ui.start();
    sup.start();

    clk::uibridge::start(ui_port);
    clk::cli::console_run();
    clk::uibridge::stop();

    sup.stop();
    ui.stop();
    net.stop();
    storage.stop();
    chrono.stop();
    motion.stop();
    return 0;
}

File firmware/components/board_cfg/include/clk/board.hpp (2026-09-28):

// Pin map + device presence.                               [FIRMWARE.md D15, §12.0, §14]
//
// D15: the pin map is IDENTICAL on every board.  The devkit carries the same
// WROOM-1U-N8R8, so a remap would be gratuitous divergence -- and exactly the kind of
// difference that hides a real bug until the PCB arrives.  Only the set of devices that
// are actually *fitted* differs, and that is a runtime bitmask because on a breadboard it
// genuinely is runtime: you wire the encoder on Tuesday and the opto on Wednesday.
#pragma once

#include <cstdint>

namespace clk::board {

// ---- pin map (esp32.md, verbatim) ------------------------------------------------------
struct Pins {
    int vbat_sense = 1;  // ADC1_CH0
    int home_opto = 2;   // ADC1_CH1
    int neopix = 7;      // SPI3 MOSI via GPIO matrix (D4)
    int i2c_sda = 8;
    int i2c_scl = 9;
    int enc_sw = 17;        // GPIO IRQ, 5 ms debounce
    int sensor_int = 42;    // BNO085 H_INTN only
    int expander_int = 44;  // MCP23017 INTA/B mirrored
    int wake_warm = 45;     // LEDC
    int wake_cool = 46;     // LEDC
    int enc_a = 47;         // PCNT
    int enc_b = 48;         // PCNT
    // microSD on SPI2, its only device since v0.19 (esp32.md).  Through the GPIO matrix -- none
    // of these are SPI2's IOMUX pins -- which caps the bus near 26 MHz; the card runs at 20.
    int sd_sclk = 13;
    int sd_mosi = 14;
    int sd_miso = 21;
    int sd_cs = 18;  // active-low, external pull-up keeps the card idle through boot

    // Stepper coils, one TB6612 per shaft -- and named for the SHAFT, not for the hand.
    //
    // Which hand goes on which shaft is a decision, and it changed on 2026-09-13: the minute
    // hand moved to the inner pin so it reads in front, the way a normal clock does
    // (`cad/README.md`, FIRMWARE.md §6.1).  The WIRING did not move with it -- driver #1 still
    // drives the outer tube -- so naming these `step_minute`/`step_hour` made a relabelling
    // look like a rewiring job and put the hand assignment in two files at once.  It is one
    // line in motor_esp.cpp's build() now, and these say only what they are soldered to.
    //
    // The schematic's own nets are still `STEP_M_*` / `STEP_H_*` (esp32.md, kicad/gen) and are
    // misnomers as of that date; kicad/REVIEW.md carries the rename for the respin.
    //
    // Order is [A+, A-, B+, B-] because that is the order the commutation writes them in, and
    // it is NOT ascending GPIO: driver #1's B- landed on IO3 (esp32.md), which is a strap pin
    // and therefore the one that had to be an output nobody drives at boot.  STEP_STBY keeps
    // both drivers off until firmware asks.
    int step_tube[4] = {4, 5, 6, 3};     // MCPWM0, TB6612 #1, `STEP_M_*` -- the OUTER tube
    int step_pin[4] = {38, 39, 40, 41};  // MCPWM1, TB6612 #2, `STEP_H_*` -- the INNER pin.
                                         //   Also the JTAG pins, see esp32.md
};
inline constexpr Pins kPins{};

// ---- devices ---------------------------------------------------------------------------
enum class Dev : uint16_t {
    Opto,
    Vbat,
    Knob,
    Pixels,
    WakeLed,
    Expander,
    Amp,
    Als,
    Env,
    Imu,
    Sd,
    Xtal32k,
    Motor,  // the X40.879 + both TB6612s, as one fitted-or-not unit
    count
};
inline constexpr int kDevCount = static_cast<int>(Dev::count);

const char* name(Dev) noexcept;
bool parse_dev(const char* s, Dev& out) noexcept;

// Presence is initialised from the board's compile-time default and can then be changed --
// by probing on target (`board i2c scan` finding the expander), or by `sim present` on the
// host.  An absent device yields Status::NotPresent, never a faked success (D16).
bool present(Dev) noexcept;
void set_present(Dev, bool) noexcept;
void reset_presence() noexcept;  // back to the compile-time default

const char* board_name() noexcept;  // "rev0_3" | "devkit" | "host"

// Does this board start with the movement inhibited?  True on the physical boards while
// milestone 3 is open -- a soldered-through movement cannot be unplugged, and homing on boot
// drives both hands the instant the board powers up, which during sensor bring-up is a hazard
// and a nuisance.  False on the host, so clocksim and the test suite are untouched.
// ⚠ Flip this to false for the physical boards when milestone 3 closes.
bool motor_inhibited_default() noexcept;

}  // namespace clk::board

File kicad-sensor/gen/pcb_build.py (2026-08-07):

"""Generates sensor.kicad_pcb from sensor.kicad_sch with KiCad's own pcbnew
bindings (run under KiCad's bundled interpreter, NOT system python3):

    /Applications/KiCad/KiCad.app/Contents/Frameworks/Python.framework/Versions/3.9/bin/python3.9 pcb_build.py

╔══════════════════════════════════════════════════════════════════════════╗
║ HISTORICAL — THIS SCRIPT NO LONGER DESCRIBES sensor.kicad_pcb.           ║
║ It produced the 2026-07-30 *2-layer, unrouted* placement.  The board on  ║
║ disk has since been re-placed, taken to **4 layers** and **routed by     ║
║ hand** (b3fc33e, a020218): 194 track segments, 30 vias, 4 GND pours.     ║
║ Running this would throw all of that away, so main() refuses to (guard   ║
║ below, same as ../../kicad/gen/pcb_build.py).                            ║
║                                                                          ║
║ The PCB is now HAND-OWNED: make placement/routing changes in pcbnew, and ║
║ pull schematic edits across with Update PCB from Schematic (F8), which   ║
║ preserves routing.  The constants below (LAYERS, PLACEMENT,              ║
║ MOUNTING_HOLES, U2_THERMAL_KEEPOUT, APERTURES) are kept as the record of ║
║ what was generated, NOT as a description of the current file — see       ║
║ ../PCB_NOTES.md for the board as built and ../REVIEW.md W1.              ║
╚══════════════════════════════════════════════════════════════════════════╝

Same contract as the main board (../../kicad/gen/pcb_build.py, see
../../kicad/PCB_NOTES.md): the schematic is the single source of truth for
parts + nets, every part has an explicit hand-chosen position derived from
its connectivity, and the build refuses to run on a placement/schematic
mismatch.  Placement + outline + zones + net assignment + silkscreen; no
traces (routing is left to a human, as on the main board).

The geometry helpers and the B-side transform are IMPORTED from the main
board's generator rather than copied, so the empirically-verified flip
convention lives in exactly one place; only `resolve_fp` is monkeypatched
(this project's custom footprints live in ../sensor.pretty, nickname
`sensor`).  Transform recap, verified by verify_pins() on every build:

    side B, rot   0 -> pad(lx,ly) at world (ax-lx, ay+ly)   [X mirrored]
    side B, rot 180 ->                     (ax+lx, ay-ly)   [Y mirrored]
    side B, rot  90 ->                     (ax-ly, ay+lx)
    side B, rot 270 ->                     (ax+ly, ay-lx)
    side F, rot   0 ->                     (ax+lx, ay+ly)
    side F, rot 180 ->                     (ax-lx, ay-ly)

Two of those are worth spelling out because they cost a build iteration each:
rot 180 on the back mirrors Y, *not* X (so an IC's local top row comes out
BELOW the part), and the back-side rot 90 mapping is (ax-ly, ay+lx) -- the
main board's docstring says (ax-ly, ay-lx), which is a stale note: it only
ever places rot 90 on the FRONT (U14), so nothing there exercises it.

Requirements this layout is built to (2026-07-30):
  1. every courtyard pair >= 0.22 mm apart (MIN_GAP) -- and the copper
     clearance rule is set to the same 0.22 mm, which every footprint here
     can hold (tightest in-footprint pad gap = 0.25 mm, U1/U3);
  2. two mounting holes;
  3. light sensor U3 + environment sensor U2 on the FRONT;
  4. J1 on the BACK;
  5. sensor cross-interference minimised (see the block comments below);
  6. small board -- 30 x 16 mm.
"""
import importlib.util
import json
import os
import shutil
import subprocess
import sys
import tempfile

HERE = os.path.dirname(os.path.abspath(__file__))
SENSOR_DIR = os.path.dirname(HERE)
MAIN_GEN = os.path.abspath(os.path.join(SENSOR_DIR, "..", "kicad", "gen"))
sys.path.insert(0, MAIN_GEN)

import pcbnew  # noqa: E402

SCH = os.path.join(SENSOR_DIR, "sensor.kicad_sch")
PCB_OUT = os.path.join(SENSOR_DIR, "sensor.kicad_pcb")
SENSOR_PRETTY = os.path.join(SENSOR_DIR, "sensor.pretty")
STOCK_FP = "/Applications/KiCad/KiCad.app/Contents/SharedSupport/footprints"
KICAD_CLI = "/Applications/KiCad/KiCad.app/Contents/MacOS/kicad-cli"

MM = pcbnew.FromMM


def _main_pcb_build():
    """Load ../../kicad/gen/pcb_build.py by path -- same basename as this
    file, so a plain `import pcb_build` would find this one instead (the
    same trap gen/build.py documents for the schematic side)."""
    spec = importlib.util.spec_from_file_location(
        "clock_main_pcb_build", os.path.join(MAIN_GEN, "pcb_build.py"))
    mod = importlib.util.module_from_spec(spec)
    spec.loader.exec_module(mod)
    return mod


MAIN = _main_pcb_build()


def resolve_fp(field):
    nick, name = field.split(":", 1)
    if nick == "sensor":
        return SENSOR_PRETTY, name
    return os.path.join(STOCK_FP, f"{nick}.pretty"), name


MAIN.resolve_fp = resolve_fp          # add_footprint() reads this global
add_footprint = MAIN.add_footprint    # incl. the Flip(LEFT_RIGHT) convention
fp_bbox_mm = MAIN.fp_bbox_mm          # pads u courtyard, no silk/text
rect_gap = MAIN.rect_gap              # separation, negative = overlap
add_zone = MAIN.add_zone
load_schematic_parts = MAIN.load_schematic_parts   # reads MAIN.SCH -> repointed
load_netlist = MAIN.load_netlist
MAIN.SCH = SCH

# ==========================================================================
# Board
# ==========================================================================
BOARD_W, BOARD_H = 30.0, 16.0     # 4.8 cm^2 -- see PCB_NOTES.md for the sizing
CORNER_R = 1.0
EDGE_M = 0.35                     # courtyard must stay this far inside the edge
PAD_EDGE_M = 0.5                  # copper-to-edge (matches the DRC constraint)
MIN_GAP = 0.22                    # hard floor between courtyards (requirement 1)
TIGHT_GAP = 0.30                  # below this it is reported as "tight"
LAYERS = 2
THICKNESS = 1.6                   # stiff enough that U1 reads gravity, not flex


PROJECT = os.path.join(SENSOR_DIR, "sensor.kicad_pro")


def read_project():
    if not os.path.exists(PROJECT):
        return None
    with open(PROJECT) as f:
        return json.load(f)


def project_template():
    """The .kicad_pro the schematic side would write from scratch --
    obtained by pointing project2 at a scratch directory, since it refuses
    to overwrite a project that already exists."""
    import project2
    tmp = tempfile.mkdtemp()
    keep = project2.OUT_DIR
    try:
        project2.OUT_DIR = tmp
        with open(project2.write_project("sensor")) as f:
            return json.load(f)
    finally:
        project2.OUT_DIR = keep
        shutil.rmtree(tmp, ignore_errors=True)
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

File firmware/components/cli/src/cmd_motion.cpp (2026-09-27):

// The `motion` group.                                        [FIRMWARE.md §9.3, §6.1]
//
// A view onto the AO, never a second driver: every row here posts an event to `motion` and
// reads its snapshot.  Nothing in this file touches hal::motor -- one owner per peripheral
// (rule 1), and a CLI that could drive the coils behind the AO's back would be exactly the
// bug that rule exists to prevent.
#include <cinttypes>
#include <cstdio>
#include <cstdlib>
#include <cstring>

#include "clk/cli/registry.hpp"
#include "clk/domain/hand.hpp"
#include "clk/services/motion.hpp"

namespace clk::cli {
namespace {

using svc::Motion;

bool parse_hand(const char* s, hal::motor::Hand& out) {
    if (!s) return false;
    if (std::strcmp(s, "h") == 0 || std::strcmp(s, "hour") == 0) {
        out = hal::motor::Hand::Hour;
        return true;
    }
    if (std::strcmp(s, "m") == 0 || std::strcmp(s, "minute") == 0) {
        out = hal::motor::Hand::Minute;
        return true;
    }
    return false;
}

// "07:30" | "7:30" | "0730"
bool parse_hhmm(const char* s, int& h, int& m) {
    if (!s) return false;
    char* end = nullptr;
    const long a = std::strtol(s, &end, 10);
    if (!end) return false;
    if (*end == ':') {
        const long b = std::strtol(end + 1, nullptr, 10);
        h = static_cast<int>(a);
        m = static_cast<int>(b);
    } else if (*end == '\0' && std::strlen(s) == 4) {
        h = static_cast<int>(a / 100);
        m = static_cast<int>(a % 100);
    } else {
        return false;
    }
    return h >= 0 && h < 24 && m >= 0 && m < 60;
}

// A refusal must never print as a success -- FIRMWARE.md §12.2 ground rule 2, and F0.1 is the
// instance that cost a bench session: `motion step` posted a target, the FSM dropped it in
// `Fault`, and the command printed `m +100 usteps (2.08 deg)` as though a hand had moved.
//
// The second line is the part that matters.  On a bring-up board there are TWO gates that stop
// a move and they are indistinguishable from the outside: the NVS bench inhibit, which
// `unsafe on` does NOT lift, and a `Fault` the homing FSM never left (F0.2).  So every row that
// asks the movement for something routes its non-Ok answer through here, and the answer names
// the gate and the cure.
Status refused(Sink& out, const char* what, Status st) {
    out.printf("%s refused: %s", what, cmd::name(st));
    switch (st) {
        case Status::Denied:
            out.line("  the movement is INHIBITED -- `motion power on` releases it (saved to NVS)");
            out.line("  `unsafe on` does NOT lift this; it is a different gate (board.hpp)");
            break;
        case Status::NotReady:
            out.line("  homing failed and nothing has cleared it -- `motion stop` clears a fault");
            out.line("  `motion step` still works in a fault: it is how the index mark is placed");
            break;
        case Status::Busy:
            out.line("  a homing run has both shafts -- `motion stop` abandons it");
            break;
        case Status::NotPresent:
            out.line("  no movement fitted -- board.hpp's presence mask says so");
            break;
        default:
            out.line("  the motion mailbox was full and the event was dropped (`sys stat`)");
            break;
    }
    return st;
}

Status cmd_status(Args const&, Sink& out) {
    const auto s = svc::motion().snapshot();
    out.printf("state  %s%s%s%s", s.state_name, s.phase[0] ? " / " : "", s.phase,
               s.homed ? "  [homed]" : "  [not homed]");
    out.printf("hands  h=%" PRId32 " m=%" PRId32 "  (%.1f deg / %.1f deg)", s.hour, s.minute,
               static_cast<double>(domain::to_deg(s.hour)),
               static_cast<double>(domain::to_deg(s.minute)));
    out.printf("target h=%" PRId32 " m=%" PRId32, s.target_hour, s.target_minute);
    out.printf("coils  %s   opto %.3f   faults %" PRIu32, s.powered ? "live" : "off",
               static_cast<double>(s.opto), s.faults);
    out.printf("zero   h=%" PRId32 " m=%" PRId32 " usteps  (%+.2f / %+.2f deg, per unit)", s.zero_h,
               s.zero_m, static_cast<double>(s.zero_h) * 360.0 / domain::kRev,
               static_cast<double>(s.zero_m) * 360.0 / domain::kRev);
    out.printf("trims  %" PRIu32 "  last %+" PRId32 " usteps  (auto-home, on every crossing)",
               s.trims, s.last_trim);
    const auto t = svc::motion().tuning();
    out.printf("dial   tick %u/12 = %d deg, %+" PRId32 " usteps on every target%s", s.dial_tick,
               s.dial_tick * 30, s.dial_off, t.level ? "" : "   [levelling off]");
    if (s.home_ms) out.printf("last home took %" PRIu32 " ms of sim time", s.home_ms);
    out.printf("tune   v_max=%" PRId32 " accel=%" PRId32 " v_coarse=%" PRId32 " v_fine=%" PRId32
               " backlash=%" PRId32 " thresh=%.2f autohome=%d level=%d",
               t.v_max, t.accel, t.v_coarse, t.v_fine, t.backlash,
               static_cast<double>(t.opto_thresh), t.autohome ? 1 : 0, t.level ? 1 : 0);
    return Status::Ok;
}

Status cmd_home(Args const&, Sink& out) {
    if (const Status st = svc::motion().home(); st != Status::Ok) return refused(out, "home", st);
    out.line("homing: clear -> minute coarse+fine -> park -> hour coarse+fine");
    out.line("  watch it with `motion status` or the ux app");
    return Status::Ok;
}

Status cmd_goto(Args const& a, Sink& out) {
    int h = 0, m = 0;
    if (!parse_hhmm(a.arg(0), h, m)) {
        out.line("usage: motion goto <hh:mm>");
        return Status::BadArg;
    }
    const auto p = domain::for_time(h, m);
    if (const Status st = svc::motion().goto_usteps(p.hour, p.minute); st != Status::Ok) {
        return refused(out, "goto", st);
    }
    out.printf("goto %02d:%02d  (h=%" PRId32 " m=%" PRId32 " usteps)", h, m, p.hour, p.minute);
    return Status::Ok;
}

Status cmd_step(Args const& a, Sink& out) {
    hal::motor::Hand hand{};
    if (!parse_hand(a.arg(0), hand) || a.count() < 2) {
        out.line("usage: motion step <h|m> <+/-usteps>");
        return Status::BadArg;
    }
    const auto n = static_cast<int32_t>(std::strtol(a.arg(1), nullptr, 10));
    if (const Status st = svc::motion().nudge(hand, n); st != Status::Ok) {
        return refused(out, "step", st);
    }
    out.printf("%s %+" PRId32 " usteps (%.2f deg)", a.arg(0), n,
               static_cast<double>(n) * 360.0 / domain::kRev);
    return Status::Ok;
}
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

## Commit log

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2026-07-20 cube redesign (v0.19): rewrite spec, drop display from schematic + BOM
    - README: walnut cube + aluminum face/knob form factor, single-knob UX,
    NeoPixel status/dial LEDs, vertical USB-C, R14 retired; BOM + decision log
    - kicad: remove Sharp LS032B7DD02 + FH34 (J5), panel caps, LCD_DISP/LCD_CS;
    SPI2 now microSD-only (b_display.py -> b_sd.py); datasheet/ untouched
    [clock.FCStd, clock.kicad_sch, front_face.FCStd]
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2026-07-20 USB-C -> GCT USB4160-03-0230-C; JST ZH connectors; datasheets + doc consistency
    - J1 = USB4160-03-0230-C (24-pin USB3.2 vertical, in stock $1.22; USB 2.0
    subset wired, SS pads unconnected); footprint adapted from the supplied
    vendor CAD file (stake slots made plated SH, pegs/artifacts fixed)
    - off-board connectors standardized on JST ZH: J7 sensor + J10 knob =
    B6B-ZR 1x06, J11 toggle = B2B-ZR 1x02 -> one pre-crimped A06ZR-style
    cable family; J3/J9 stay JST PH (power); J7 grew 1x05->1x06 (pin 6 spare)
    - datasheet/: filed rows 30-34 (usb4160, sk6812rgbw, sn74ahct1g125, em14,
    jst zh); README updated to v0.19 with display/FPC/USB4105 rows retained
    and marked "not in current build" (n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
    [clock.kicad_sch]
2026-07-20 resolve 18650-holder mismatch -> Keystone 1043 (TH, in stock)
    - BT1 footprint was the SMT 1042 while the BOM said 1043; 1043 wins
    ($2.99 / 21.9k DigiKey stock vs $5.99 SMT 1042) and TH PC pins suit
    the hand-soldered build and a heavy cell
    - custom BatteryHolder_Keystone_1043_1x18650 in clock.pretty: body/pegs/
    index copied from the stock 1042 footprint (shared molding), axis pins
    at +-35.8 with 2.6mm drill / 4.2mm pad (also covers the +-36.11 reading
    from KiCad MR !2043); verify vs Keystone drawing before fab
    - docs synced (README BOM + decision log, kicad/README, datasheet/README)
    [clock.kicad_sch]
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2026-08-04 review phase 0+1: fix the three blocking schematic defects
    Adds kicad/REVEIW.md (full design review of clock.kicad_sch/.kicad_pcb at
    7ec2534) and fixes the three findings that stop the board working:
    #1 Q4 (LTC4412 PVDD mux) had drain on PVDD and source on +5V, so its body
    diode dumped the 12 V rail into +5V the moment BOOST12_EN went high --
    past abs-max for U5 (7 V), U6 (6 V), U15 (7 V), the SK6812s and the EM14.
    Now drain->+5V, source->PVDD per the LTC4412 datasheet.
    #2 TAS5760M PBTL tied OUTA+||OUTB+ and OUTA-||OUTB-, shorting two anti-phase
    half-bridges (hard PVDD->PGND every switching cycle). TI SLOS772F fig.64/65
    pair A+||A- and B+||B-; bootstraps follow their own leg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
    [clock.kicad_pcb, clock.kicad_sch]
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2026-08-04 review phase 2 prep: swap C181/C182 so the PCB fix for #2 gets cheap
    The PBTL re-tie can be satisfied two ways, and they cost very different
    amounts of PCB rework:
    X (previous): keep the caps where they are, move the bootstrap PIN
    connections -> U9.25->C182.1 and U9.19->C181.1, two ~6.3 mm routes that
    cross each other and the PVDD/BSTRPB- knot.
    Y (this commit): swap C181/C182 positions so each cap sits on its own leg's
    column. Both caps keep their ORIGINAL U9 pin, which is exactly what the
    existing PCB copper already does, so those two connections need no rework
    at all -- only the two far pads move, as 3.65 mm straight verticals.
    Net effect on the PCB: 2 long crossi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
    [clock.kicad_sch]
2026-08-04 review: #10 silkscreen, #13 R1 1206, #20 R20 200R, #21/#16 into FIRMWARE.md
    Renames REVEIW.md -> REVIEW.md and restructures it around a status overview
    (Fixed / Open / Deferred / Accepted) with a "Fixed in <commit>" column.
    #10 Connector kept as-is per decision; disambiguated with silkscreen instead.
    Added "SENSOR" and "KNOB" on B.SilkS -- labelling only J7 would still let
    the pair be swapped. First placement collided with J7's own outline (14
    silk_overlap warnings); moved to (94.5, 13.4) where DRC is clean.
    #13 R1 -> 1206 / RC1206FR-071KL (1/4 W). On the 15 V contract it dissipates
    137 mW feeding the CH224K's 3.3 V shunt: 1.4x a 0603 and 1.1x an 0805, so
    1206 is the fir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
    [clock.kicad_pcb, clock.kicad_sch]
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2026-08-05 review: #19 PVDD bulk ripple rating, #16 comment correction
    #19 C172 was a plain low-ESR electrolytic (Rubycon 25TZV100M6.3X8) rated
    300 mA @100 kHz. A class-D BTL draws i_supply = P/PVDD x (1 - cos 2wt),
    so the bulk sees (P/PVDD)/sqrt(2) rms at twice the audio frequency:
    8 W (firmware limit) / 11.5 V -> 0.49 A rms
    11 W (clip) / 11.5 V -> 0.68 A rms
    i.e. under-rated ~1.6x at the limit the firmware already enforces. Swapped
    to a hybrid polymer in the SAME D6.3 land -- Panasonic EEH-ZA1E101P,
    100 uF/25 V, ~1.3 A ripple, ~40 mOhm ESR -- so this stays a pure BOM change
    with no PCB impact. 7.7 mm also fits the CP_Elec_6.3x7.7 land better than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
    [clock.kicad_pcb, clock.kicad_sch]
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2026-08-05 gen: reproduce the hand-tuned schematic from 84f4102
    Your manual readability pass is now generated, not just committed: build.py
    output matches 84f4102 on all eight structural categories (title block, 14
    rects, 59 texts, 50 labels, 154 junctions, 18 no-connects, 587 wires, 183
    symbols incl. rotation/mirror and every Reference/Value position), the
    netlist is identical, ERC is 0, and a second build is byte-identical.
    Title block: "Wooden Clock - main board", company Tibo, rev "0.3" (numeric,
    not a letter).
    harvest.py now also captures the furniture it used to ignore, so a GUI pass
    survives a rebuild instead of being silently reverted:
    * FRAMES - the dashed module boxes, keyed by their titl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
    [clock.kicad_sch]
2026-08-05 pcb: sync the board to the schematic (headless F8) via gen/sync_pcb.py
    The PCB was one part, one footprint, seven values and eleven pad-nets behind
    the schematic. KiCad 10 exposes no netlist updater to Python and kicad-cli
    pcb has no "update from schematic", so this adds gen/sync_pcb.py as the
    stand-in and runs it.
    Applied: D14 added (76.50, 80.00 B.Cu); R1 0603 -> 1206 keeping position,
    rotation, side and nets; 7 values; 11 pad nets (Q4.2/Q4.3 swap, U9.20/23/26,
    C181.2/C182.2/C183.2, L6.1, and the new ALS_INT on J7.6 + U13.4).
    The tool cuts only copper that would otherwise SHORT two nets, and cuts it
    minimally: a first attempt deleted whole mixed islands, which took out the
    entire +5V tre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
    [clock.kicad_pcb]
2026-08-05 pcb: route all 12 remaining connections — 0 errors, 0 unconnected
    Routes the ratsnest left by the schematic sync. Q4's +5V leg needed an F.Cu
    hop: B.Cu cannot pass between Q4 pads 1 and 2 (0.43 mm gap, and a 0.25 mm
    track needs 0.45 mm). ALS_INT threads U13's 0.65 mm GPB lane and exits to
    F.Cu before FULLCHG_EN's diagonal crosses it. The audio legs use escape vias
    onto F.Cu, which was the only free layer in that 46 mm2 box.
    The old leg-B trunk was RECOVERED rather than re-routed: after the net swap it
    survived as orphaned copper on Net-(U9-SPK_OUTA-) -- 4 segments and 3 vias
    running U9.23 -> In2 -> In1 -> L6.1, which is exactly the path new leg B
    needed. Re-netting it and restoring three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
    [clock.kicad_pcb]
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2026-08-05 pcb: #5 thermal vias — 49 GND vias into the exposed pads
    All three PowerPADs had zero thermal vias, so each could only spread heat
    sideways through 35 um of B.Cu:
    U7 TPS55340 3.4 x 5.0 mm -> 14 vias (~2 W at 12 W out)
    U9 TAS5760M 5.2 x 11 mm -> 33 vias (~1.5 W at 10 W out)
    U2 LT3652 1.65 x 2.85mm -> 2 vias (~0.7 W at 1 A)
    Every position is checked against other-net copper on all four layers before
    placement; the vias are tented (board setting), so solder cannot drain through
    during hand assembly.
    U2 is short-changed and it is finding #18's fault, not a placement failure:
    its pad is only 1.65 mm wide and two inner-layer SIGNALS cross it --
    Net-(U8-IO11_LRCLK) runs ve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
    [clock.kicad_pcb]
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2026-08-05 pcb: #4 power net class + in-place widening (partial)
    Adds a POWER net class (1.0 mm track, 0.8/0.4 via) covering VBAT, PVDD, +5V,
    +12V, VBUS and both amp output legs, so future routing defaults to copper
    rather than 0.25 mm. Its clearance is left at the board default 0.1 mm --
    setting it to 0.15 immediately produced 150 clearance errors against copper
    that was already legal, which is not what the class is for.
    Every existing segment on those nets was then widened to the most its own
    neighbourhood allows (per-net targets from IPC-2221, 1 oz external, ~20 C):
    VBAT 408 -> 268 mOhm (-34%) +12V 187 -> 111 mOhm (-41%)
    PVDD 118 -> 77 mOhm (-35%) VBUS 107 -> 83 mOhm (-22%)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
    [clock.kicad_pcb]
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2026-08-06 Move four power trunks from the inner planes to F.Cu (#4, #18)
    The inner layers carried 299.6 mm of power copper as long slots, which both
    capped ampacity (0.25 mm necks that could not widen in place) and forced
    return currents to detour around them. F.Cu was ~98% empty.
    Moved, each with a via cluster at both ends (parallel vias sized to the net's
    peak current) and a short stub of the original inner copper kept under the
    cluster so every via is tied on both sides:
    +5V 57.1 mm In2 0.25 -> F.Cu 1.00
    +12V 42.8 mm In2 0.60 -> F.Cu 1.00
    +5V 23.9 mm In1 0.60 -> F.Cu 1.00
    VBAT 27.9 mm In1 0.50 -> F.Cu 0.97
    power copper on In1/In2 299.6 -> 160.9 mm (-46%)
    +5V <=0.3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
    [clock.kicad_pcb]
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2026-08-07 pcb: pre-fab audit — R1 latent open (#26), +3V3 widths (#4), title block
    Bundles the hand edits made in pcbnew (Y1 reference reposition, Q2 VBAT
    stub re-route) with a pre-fab audit pass over the routed board looking
    for defects that kicad-cli drc structurally cannot report.
    #26 — R1 pad 2 was hanging on 0.049 mm of copper. A latent open left by
    the #13 0603 -> 1206 land swap: the track ended at x = 98.675, dead
    centre of the *old* 0603 pad, while the 1206 pad's outer edge sits at
    98.600. Only the track's 0.125 mm end cap still overlapped. DRC was
    silent because connectivity is a boolean -- any overlap reads as
    connected. R1 feeds the CH224K's shunt-regulated VDD, so an open there
    means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
    [clock.kicad_pcb]
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2026-08-07 sensor board v0.2: action kicad-sensor/REVIEW.md
    Schematic, PCB, generators, QA checks and docs brought into one consistent
    state. ERC 0 violations, DRC 0 violations / 0 unconnected / 0 parity issues,
    gen/pcb_check.py 33/33, stamp_bom.py idempotent.
    Safety and correctness
    - #1 Address straps R3/R4/R10/R11 0R -> 10k. Fitting both halves of either
    pair shorted the MAIN board's +3V3 to GND through 0 ohm; it now costs
    330 uA and the part enumerates at a visible wrong address. PCB Value
    fields follow the schematic.
    - W1 gen/pcb_build.py refuses to run without PCB_BUILD_WIPE_ROUTING=1. It
    produced the old 2-layer unrouted placement and would wipe the routing.
    - #4 The r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
    [clock.kicad_pcb, clock.kicad_sch, sensor.kicad_pcb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]
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2026-08-09 BME688 handling into the BOM line; close the 3 vendor-drawing checks
    Sensor board — the handling rules now ship with the BOM
    U2's Notes field carries the full Bosch HSMI contract: MSL 1, 260 C for
    20-40 s, max 3 reflow cycles, minimum 50 um solder height after reflow, no
    aqueous wash, vent covered for any cleaning step, no siloxanes anywhere
    near it, and the reason it matters - a washed or siloxane-exposed hotplate
    does not fail electrically, it reads a wrong VOC baseline for ever, so
    nothing at incoming test will catch it.
    It goes in Notes specifically so it travels with the exported CSV to the
    assembly house, rather than living in a README they will never open. The
    same text is stamped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
    [sensor.kicad_pcb, sensor.kicad_sch]
2026-08-09 protector -GB -> -HB; keep the 4 Ohm speaker, fix its rationale
    Speaker: DMA58-4 (4 Ohm) confirmed, README §16 rationale corrected
    That note claimed "8 Ohm would halve output to ~4 W". It would not, when
    plugged - and plugged is the case that argument was made for. At 4 Ohm the
    ceiling is not the rail, it is L5/L6 saturation: the rail would allow
    16.5 W and the limiter caps it at 8 W to hold peak inductor current at 79 %
    of Isat. At 8 Ohm you are rail-limited at 11.5 V -> 8.26 W, at 61 % of
    Isat. Plugged, both impedances give ~8 W and the same SPL.
    The 4 Ohm earns its place on BATTERY, where the rail does clip: 3.1 W vs
    1.6 W, a real +3 dB. Plus the constants are already cut for it (-4.1 d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
    [clock.kicad_pcb, clock.kicad_sch]
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2026-08-10 reformat firmware/ with clang-format -- no behaviour change
    Mechanical: `tools/format.sh` over all 35 C++ files, nothing else. Skip it in
    review and in blame.
    Two visible effects beyond whitespace:
    - Hand-aligned declaration columns (`void sleep_ms`, `uint8_t soc_pct`)
    collapse to single spaces. The padding was the thing that made these files
    hard to read, and no formatter setting reproduces it stably -- it drifts
    the moment a longer type is added to the block.
    - Compact one-liners (`if (x) { out.line(...); return Status::BadArg; }`)
    expand to real blocks. AllowShortBlocksOnASingleLine: Always would keep
    them, but it also joined *more* than was written by hand, which was a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
    [board.cpp, board.hpp, cmd_sensor.cpp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]
2026-08-10 ux app + motion/chrono/ui: the clock runs, and you can watch it
    The UX needed tuning and there was no way to see it. This adds `ux/` -- an SVG
    plate, both hands, the seven pixels, the wake wash and the speaker, plus controls
    for the knob, the rear toggle, tap and power -- and the firmware behind it, so
    what you are tuning is the code that ships.
    The page holds no clock logic. It renders `hands.h`/`hands.m` and emits CLI text;
    trajectories, homing, wrap, backlash and the knob HSM are all C++.
    The pipe (apps/clocksim/uibridge.cpp, host-only, deliberately not a component):
    ux -> clocksim one CLI line per newline. No JSON parser in the firmware,
    every input is one you co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
    [board.cpp, board.hpp, cmd_motion.cpp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]
2026-08-10 homing: clear the sensor first, and find each hand fast then slow
    Two problems, both found by watching it in ux/ rather than on a bench.
    **A hand parked on the index made homing impossible.** The sequence in §6.1
    quietly assumes the sensor starts dark: if a hand is already sitting on the mark
    it holds the opto lit, there is never a RISING edge, and the sweep runs a full
    revolution and faults. With BOTH hands there it is worse -- which one is
    responsible is not knowable from one sensor.
    So `Clear` runs first, and it does not guess. It moves the hour hand 45 deg --
    fifteen times the width of the window, with the sensor read every tick of the way
    -- and if the thing is STILL lit then the hou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
    [cmd_motion.cpp, motion.cpp]
2026-08-11 bom: C172's MPN was never real, and U3 ships as a -GB
    PCBWay's first assembly quote (T-1N10W1120006A, 1 unit) flagged six BOM
    lines. Two of them change the design record.
    C172 was `EEH-ZA1E101P`, which does not exist -- the ZA series uses the
    plain -P suffix only at other voltages/values (EEH-ZA1H101P is the 50 V
    part, EEH-ZA1E560P the 56 uF one). The 25 V / 100 uF part is
    `EEH-ZA1E101XP`, in stock at LCSC C264047 and DigiKey 3088115. Fixed in
    parts_db.py and re-stamped; only C172's MPN + Notes moved in the schematic
    and the PCB. The note's own ripple figure was wrong too -- 2 A @100 kHz
    with 30 mOhm ESR, not ~1.3 A / ~40 mOhm -- so #19's rule is met 3x.
    U3 goes back to HY2111-GB: -HB is o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
    [clock.kicad_pcb, clock.kicad_sch]
2026-08-13 ux tests: drive the page for real, and six things that broke when it did
    `ux/` was tested by looking at it. This adds `ux/tests/` -- 52 Playwright cases
    in eleven files that click the real page in a real Chrome against a real
    `clocksim`, one freshly spawned pair per test, and assert on what the dial then
    shows. `npm install && npx playwright test`, about two and a half minutes.
    The rule the whole thing rests on is **no back door**:
    - every gesture is a real DOM event -- buttons clicked, the knob scrolled,
    hands dragged, sliders moved, keys pressed. No evaluate() into app.js, no
    synthetic call to a handler;
    - every assertion reads rendered DOM -- pill text, an SVG rotate(), a sw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
    [cmd_sim.cpp, main.cpp, motion.cpp]
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2026-08-16 ux: the knob's direction reaches the hands, and five smaller answers
    Five changes of mind after using the thing, and one bug that only shows up when
    you WIND rather than nudge. `FIRMWARE.md` §6.6 is updated in place and §16b is
    the seven-row account of what moved; README §12 is the same thing said shorter.
    **The minute hand ran backwards under a steady clockwise turn.** Wind past the
    half hour and its next position is more than half a turn ahead, so `motion` --
    which had exactly one rule, take the shorter way -- took it BACKWARDS. The hour
    hand moves twelve times slower and never comes near that limit, so it went on
    looking perfect throughout, which is why this read as "the minute hand i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
    [motion.cpp]
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2026-08-19 ux: the clock finds its own zero, and stops when the knob does
    Six reports. Three of them are the movement not knowing where north is, two are
    one sentence read two ways, and one is a page that had stopped describing the
    firmware. `FIRMWARE.md` gains §6.1a-c, §6.6d is rewritten again, and §16d is the
    account of all six.
    **"The timeout should be 5 s, not 0.8 s -- where do the 0.8 come from?"** Both
    numbers are real and the knob card named only one of them. 0.8 s is the HOLD that
    leaves a mode at once; 5 s is the inactivity timeout, and it is the number
    counting down on the mode pill -- which is exactly what made the other one look
    wrong. Held the button in a real browser to be sure: 900 m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
    [cmd_motion.cpp, cmd_sim.cpp, main.cpp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]
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2026-09-08 fw: the board answers — first bring-up of rev0.3, and an I2C bus you can believe
    Board #1 back from the fab, M1 and F1 unpopulated by design. It boots, keeps
    time on its own crystal, and both on-board I2C devices answer.
    The bus is real now. `hal::i2c` on target is i2c_master at 400 kHz on IO8/9,
    internal pull-ups off because R95/R96 are on the board — enabling them would
    mask a missing resistor, which is the one fault this bus can have that is worth
    finding on a bench. A NACK is NotPresent, not an error (D16); only a timeout is
    a failure. `board i2c scan|read|write` is the group the alias table already
    pointed at, reading the HAL directly the way cmd_sensor does, ready to move
    behind t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
    [cmd_board.cpp, cmd_sensor.cpp, console_esp.cpp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]
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2026-09-11 fw: isolate the knob, and print the three raw lines that name the wrong wire
    ENC_SW still would not register a press after the last round, and the bench's
    own hypothesis was worth taking seriously: rotations showing up as presses, i.e.
    a harness in which J10.5 does not land on the EM14's switch. Power measured good
    — 5.1 V across the encoder's + and −.
    That measurement does not rule the hypothesis out, and the reason is worth
    writing down: the ZH harness is PALINDROMIC IN ITS POWER PINS. Reversed
    end-for-end, + and − land exactly where they were and everything else moves.
    Which matters more than it sounds, because ENC_SW has no divider — it is a dry
    contact with a 10k pull-up and 10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
    [cmd_sensor.cpp]
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2026-09-14 motion: a bench step works on a faulted board, and a refusal prints as one
    F0.1's three defects, together, because each fix on its own leaves the circle
    closed: you need `motion step` to place the index mark, and the failed homing
    that needs the mark is what blocks the step.
    1. A RAW target now goes through in Fault (the HandTarget handler). Dial-frame
    targets stay held — there is no zero to measure one from, so obeying it would
    point the hands somewhere and call it a time — and everything stays held in
    Homing, where a target fights the FSM for the same two shafts. Fault SURVIVES
    the nudge: the homing failure is still true and `motion status` says so.
    Two knock-ons had t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
    [cmd_motion.cpp, motion.cpp]
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2026-09-14 motion: hands swap shafts — minute to the inner pin, hour to the tube
    Decided 2026-09-13 (FIRMWARE.md §6.1e, cad/README.md): the minute hand goes on
    the X40's inner pin so it reads in front, the way a normal clock does, and the
    hour hand behind it on the outer tube.
    The wiring did not move. Driver #1 / MCPWM0 / STEP_M_* is still soldered to the
    tube, so the crossing has to happen in firmware, and the only honest place for it
    is where the pins meet the hands: motor_esp.cpp's build() now gives group 0 to
    Hand::Hour and group 1 to Hand::Minute. board.hpp's arrays are renamed
    step_tube/step_pin, because `step_minute`/`step_hour` put the hand assignment in
    two files and made a relabelling loo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
    [board.hpp, motion.cpp]
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2026-09-14 audio: a queued tone was printing as a played one, and status now asks the chip
    Bench report: flashed, `audio tone 1000` at several volumes, nothing audible.
    The firmware audit found no wrong pin and no wrong register -- but it did find
    the reason the board could not TELL us that.
    tone() only queues. The amp comes up on the writer task ~25 ms later and can
    fail at any of five steps, and every one of those failures was invisible: the
    CLI had already printed "tone 1000 Hz at 10 %". That is F0.1 with a different
    peripheral, and ground rule 2 says a refusal must never print as a success.
    - bring_up() names the step it died on -- i2s-install / i2s-enable / cfg /
    spk_sd / unmute -- latch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
    [cmd_audio.cpp, tas5760m.cpp]
2026-09-15 audio: split CLKE into its two causes -- `audio pins` and `audio clk`
    Bench: reg 0x08 = 0x08 (CLKE), SPK_FAULT low, and everything else measured
    correct -- DVDD 3.3, PVDD 5.0, SPK_SD 3.3, GAIN0/1 3.3, ADR 0. So I2C is
    fine (the registers read back exactly what was written) and the amp is simply
    not seeing a valid clock triplet.
    CLKE is ONE bit for two unrelated faults, and from outside they look the same:
    a clock that never reaches the pin, and a clock whose ratios the amp rejects.
    `audio pins <mclk|bclk|lrck|dout|all> <0|1>` holds one I2S pad as a static
    GPIO. The point is that it needs nothing faster than a multimeter -- the real
    signals are 12.288 MHz and 1.536 MHz, which most benches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
    [cmd_audio.cpp]
2026-09-15 audio: `audio probe` -- ask the pads whether they are moving, with no instruments
    Bench: all four pads drive and read correctly under `audio pins`, and 64 fs
    BCLK does not clear CLKE either. So the wire is good and the ratio is not the
    complaint.
    The datasheet's CLKE table (S8.3.3.1) lists three causes:
    1. non-supported MCLK-to-LRCK and/or SCLK-to-LRCK ratio
    2. non-supported MCLK or LRCK rate
    3. MCLK, SCLK, or LRCK has STOPPED
    256 and 64 are both in Table 6 and both were tried, and 12.288 MHz / 48 kHz are
    both listed -- so 1 and 2 are eliminated and 3 is what is left. But nothing we
    had could see it: `audio pins` proves the GPIO path and says nothing about
    whether the I2S unit is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
    [cmd_audio.cpp]
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
